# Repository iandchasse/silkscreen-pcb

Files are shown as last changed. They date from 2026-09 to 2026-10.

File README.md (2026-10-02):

# Silkscreen

**An open-source, open-hardware e-reader mainboard.**

Silkscreen is a build-it-yourself e-reader. The name covers both this board and a reader built
around it; this repository covers the mainboard. You order the board already assembled from a
factory, add an e-paper display, a battery and a microSD card, and put it in a
case of your own choosing. It is a 2-layer ESP32-S3 board with a 24-pin display connector,
optional touch and frontlight, microSD and single-cell Li-ion/LiPo power.

It is the successor to [de-link](https://de-link.me). This repository was the de-link project hub
until September 2026; the hub's pages and photos are kept on the
[`de-link-old`](https://github.com/iandchasse/silkscreen-pcb/tree/de-link-old) branch. I designed
Silkscreen in KiCad 9.0.6, but
**you do not need KiCad to order a board.** Every file a factory asks for is already in the
`production/` folder of this repository, ready to upload.

| Back (all components) | Front (silkscreen art) |
|:---:|:---:|
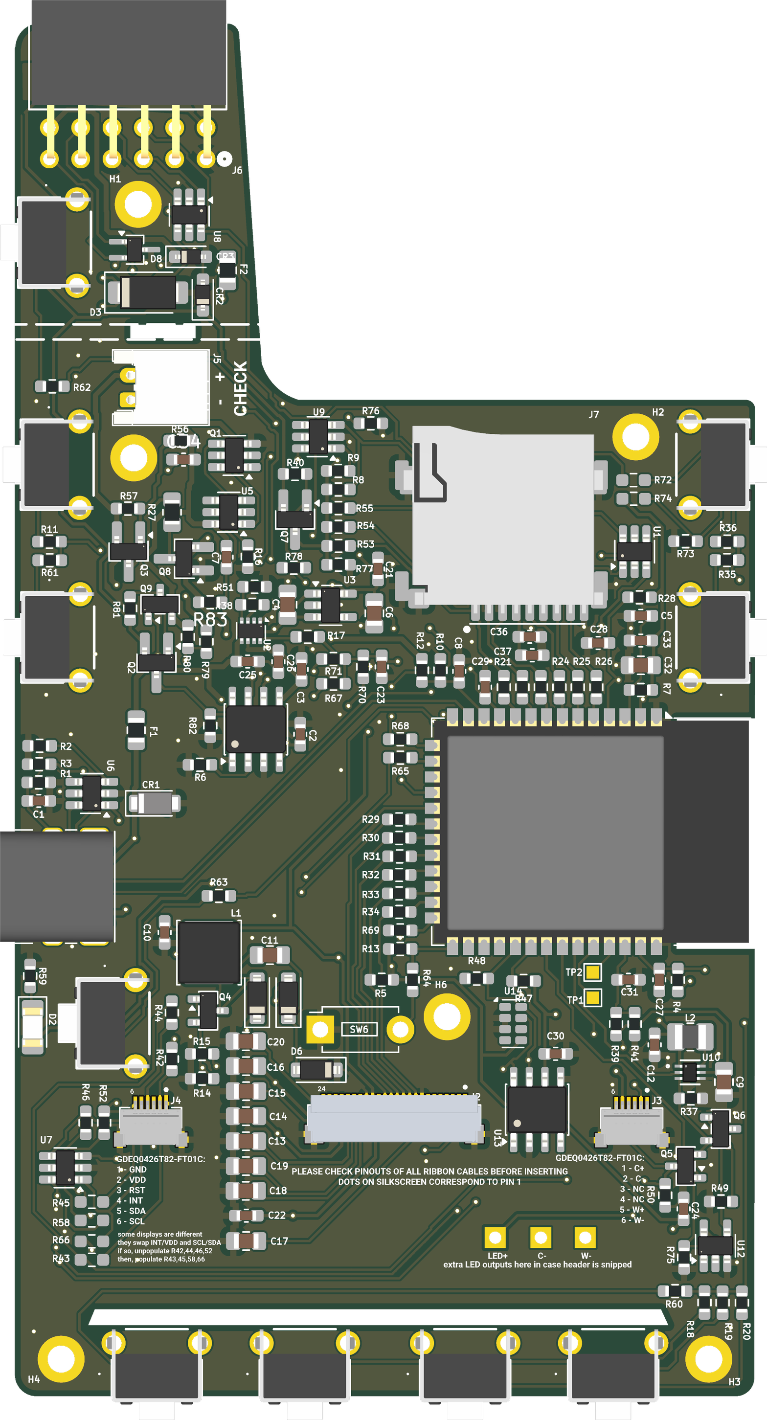
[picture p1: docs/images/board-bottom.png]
Board, bottom view
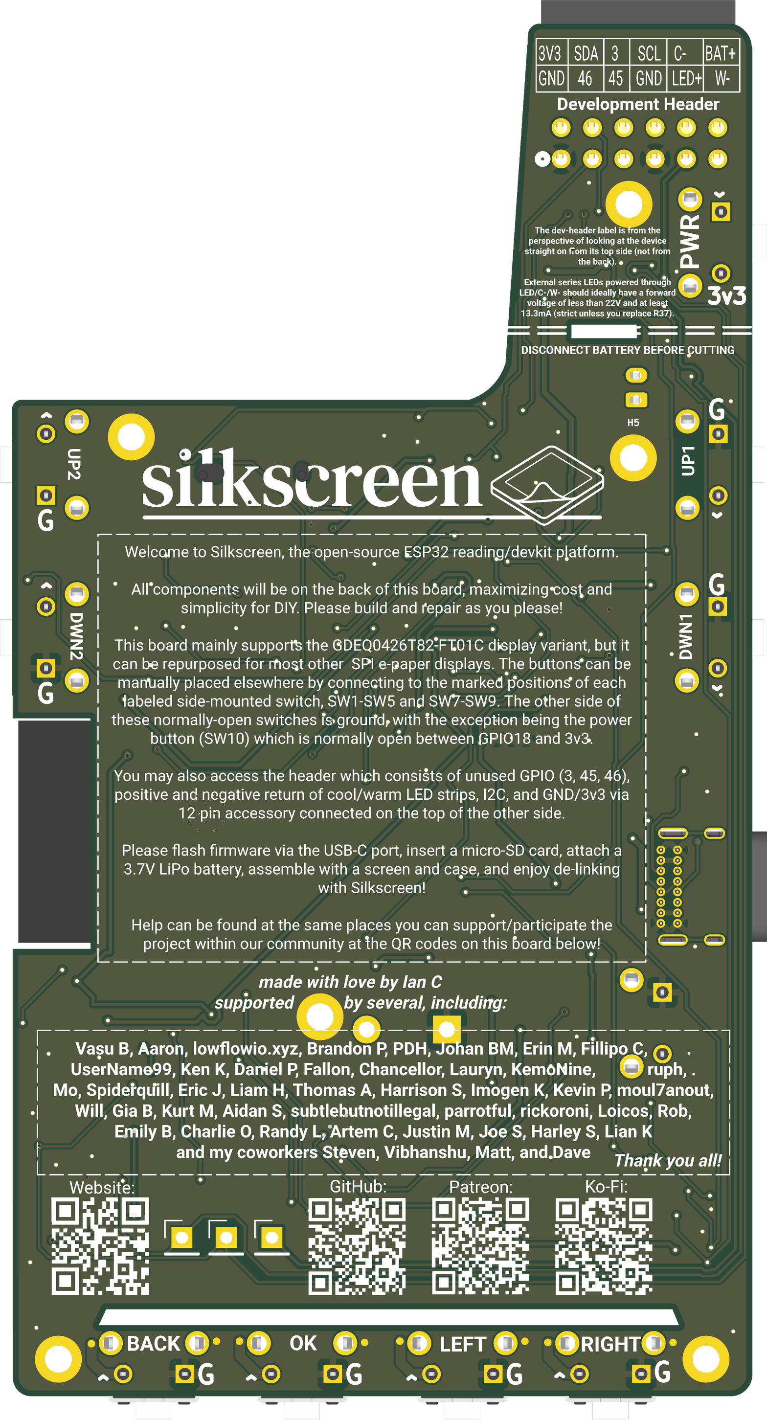
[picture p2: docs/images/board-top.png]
Board, top view
|  |  |

## What it is

- **Brain:** an ESP32-S3 module with 16 MB of flash and 8 MB of PSRAM, with USB built in. You
  plug a USB-C cable straight into it, no adapter.
- **Screen:** a 24-pin connector for SPI e-paper panels. The primary target is Good Display's
  4.26" panel family, in plain, touch, frontlight, or touch + frontlight versions. The plain panel
  is sold as `GDEY0426T82`; the others are `GDEQ0426T82` with a suffix for the variant (`-T01C`
  touch, `-FL01C` front light, `-FT01C` both), so always order by the full part number.
- **Power:** charges and runs from a single-cell Li-ion/LiPo pack over USB-C, with charger,
  cell protection and a 3.3 V regulator on board.
- **Storage:** a push-push microSD socket.
- **Buttons:** eight page/navigation buttons, plus power and reset.
- **Size:** 60.05 × 111.30 mm, 1.6 mm thick. Every part is soldered onto the **back** face, so
  the front is clear for the display.

Silkscreen is built to run the open firmware made for Xteink's readers, starting with CrossPoint.
Setting them up for this board is closed-beta work, so there is **no firmware release for it
yet**. Read [Firmware](#firmware) before you order.

The complete picture of the project, the story behind it, the cost breakdown and the build
configurator are on the project website. As of 21 September 2026 the website is still locked
while I wait for the first boards. It opens, and this README links to it, as soon as I have
tested a board in my hands.

Everything about how the board works, pin by pin, is in one document:
[docs/HARDWARE.md](docs/HARDWARE.md). It covers every circuit block, the GPIO map, what firmware
has to do for the hardware, and the dimensions a case needs.

---

## What you need besides the board

The factory sends you a populated circuit board and nothing else. You also need:

| Item | What to get |
|---|---|
| **Display panel** | One of the 4.26" Good Display variants: `GDEY0426T82` (plain), `GDEQ0426T82-T01C` (touch), `-FL01C` (frontlight), `-FT01C` (touch + frontlight). The panel you pick decides which optional parts you fit. See [Choosing a configuration](#choosing-a-configuration). |
| **Battery** | A **single-cell** (3.7 V nominal / 4.2 V charged) Li-ion or LiPo pack fitted with a **JST-PH 2.0 mm, 2-pin** plug. Read the polarity note below before you plug it in. I use [this 500 mAh `503035` pack (5 × 30 × 35 mm, JST-PH 2.0)](https://www.amazon.com/dp/B0GDQLLF12). It fits the board's 38.75 × 30.50 mm battery bay snugly, with 0.5 mm to spare on the 30 mm side. The board charges at about 0.25 A as built, which is 0.5C for this pack. For a much smaller cell, lower the charge current by raising `R6` ([HARDWARE.md §3.2](docs/HARDWARE.md#32-battery-charger)). Listings change, so check the plug, the polarity and the size of whatever you buy. |
| **microSD card** | Any normal microSD card. The battery normally sits in the board's cut-out directly in front of the card slot, so you lift or slide the cell aside to put a card in or take one out. I designed it that way; the card is not meant to be swapped often. |
| **USB-C cable** | A **data** cable, not a charge-only one, or the board will charge but never appear on your computer. |

**Battery lead order.** On the board, `J5` pin 1 is battery **negative** and pin 2 is battery
**positive**, and the board prints **- +** with the word **CHECK** right beside the connector's
mouth. A pack's wire colours are a good guide (black is negative, red is positive), but there is
no industry standard for which side of a JST-PH plug each wire goes in: packs ship both ways
round, and the two look identical in a photo. So before you plug a pack in, with USB unplugged,
check that its black wire lines up with the **-** mark and its red wire with the **+**. If they are
the wrong way round, swap the two wires in the plug
([how to reverse a JST battery plug](https://www.digikey.com/en/maker/blogs/2025/reversing-the-polarity-on-lipo-battery-jst-connectors)).
A multimeter is the surest check.

> [!WARNING]
> Lithium cells are a fire risk if reversed, shorted or crushed. Check your pack against the
> **- +** marks beside `J5` before plugging it in, and measure it if you can. Use a pack with its
> own protection board. Stop using any cell that is puffed, hot or damaged.

**Screws and case are not on this list.** The board has six M2 mounting holes, but which screws
you need depends on the case you use, and no case is supplied here. See
[The board and your case](#the-board-and-your-case).

---

## Order an assembled board, step by step

> [!CAUTION]
> **This revision of the board has not been tested yet.** I placed the first order, for Rev 1.0, on
> 21 September 2026 and the boards have not come back. The files here are Rev 1.01: the same
> circuit plus one 1 Ω resistor (`R84`) that damps ringing on the USB input when a charger is
> plugged in, corrected part positions in the placement file, and copper changes that only matter
> on a board cut down for a smaller display (see
> [Cutting the board down](#cutting-the-board-down-for-a-smaller-display)). Until I have powered one up, charged a
> cell on it, talked to it over USB and driven a panel from it, every circuit on it is a design,
> not a proven product. If you order before that, you take on a real risk: a mistake I have not
> found yet could mean a board that does not work, and the factory does not refund a board that
> was built exactly as the files said. I will update this section as soon as the first boards are
> checked out.
>
> What you can do in the meantime, with no risk: order your screen panel and battery (see
> [What you need besides the board](#what-you-need-besides-the-board)), and start on an enclosure
> design from the STEP model in
> [The board and your case](#the-board-and-your-case). The `#enclosure-design` channel on the
> [Discord](https://discord.gg/zCnKFt4Y4P) is where case work is being shared and discussed.

You do not need KiCad and you do not need to know how a PCB is designed. A factory makes the
board and solders every part onto it. You will be clicking through a web shop and uploading three
files that are already in this repository. Unfamiliar words are defined in
[Words used on the factory's website](#words-used-on-the-factorys-website).

> **Or let the builder make the files.** The *Build one* page on the website walks you through
> the panel variant and the optional blocks, estimates what the result costs, and gives you the
> three upload files for exactly that build: the same Gerber zip, plus a BOM and CPL with the
> parts you left off already removed (see [Choosing a configuration](#choosing-a-configuration)).
> For the standard build they are byte-for-byte the files in `production/`. The website is not
> open yet, and the steps below are the same either way.

### What it costs and how long it takes

The minimum order is **5 bare boards**, and you choose how many of them the factory assembles:
as few as **2**, all 5, or more boards if you want them. Most of the bill is one-off (the bare
boards, setup, the solder stencil, and a small loading fee for each of about two dozen "Extended"
part types the factory has to fetch), so the price per assembled board falls quickly as you build
more. The website's cost page breaks the cost down by order size and explains where each fee
comes from.

For scale, my own order on **21 September 2026** (no coupons, US delivery): five boards with two
assembled came to **$223.95** for boards, parts and assembly, and **$305.23** at checkout once
shipping, US tariffs and tax were added. That is about $150 per working board at two, and the
cost page puts the same build at roughly $77 per board with all five assembled and about $50 at
ten. Prices, shipping and import charges move, so treat every figure as an expectation, not a
promise.

| | |
|---|---|
| Time from clicking *order* to the parcel | about **2 to 3 weeks** |
| Not included | display panel, battery, microSD card, case |

### Step 1: get the three files

Download this repository (green **Code** button, then **Download ZIP**) and unzip it. Everything
you need is in the `production/` folder. You upload exactly three files:

| Upload this | What it is | Where it goes |
|---|---|---|
| `production/Silkscreen_Reader_PCB_1.01.zip` | the **Gerber** files: the board itself, meaning copper layers, outline and hole positions | the *Add Gerber file* box |
| `production/jlc_bom.csv` | the **BOM** (bill of materials): the shopping list of parts | the *Add BOM file* box |
| `production/positions.csv` | the **CPL** (also called the centroid or pick-and-place file): where each part sits and which way it faces | the *Add CPL file* box |

Ignore everything else in that folder. These three belong together and come from the same export.
Do not mix one of them with an older copy of another.

### Step 2: order the bare board

1. Sign in at [jlcpcb.com](https://jlcpcb.com), click **Order now**, then **Add Gerber file** and
   choose `Silkscreen_Reader_PCB_1.01.zip`.
2. The viewer draws the board. Confirm it says **2 layers** and about **60 × 111 mm**. If it does
   not, you uploaded the wrong file.
3. Set **PCB Qty = 5**, **Thickness = 1.6 mm**, **Outer Copper Weight = 1 oz**. Surface finish and
   solder-mask colour are your choice; nothing in this design needs a particular one.
4. Leave everything else at its default.
5. Scroll the viewer to the board edges and check the USB-C cut-out, the microSD opening and the
   two narrow slots on the outline are open, not filled. The long one (47.04 × 1.30 mm) is the
   display-flex slot; the short one at the tongue neck is **5.30 × 1.10 mm**. Both are at or above
   JLCPCB's 1.0 mm minimum routed-slot width, so neither should raise a design-for-manufacture
   (DFM) message. (Earlier revisions had four 0.5 mm perforation slots there; those are gone.)

### Step 3: turn on assembly

**PCBA** means "printed circuit board assembly": the factory buys the parts and solders them on
for you, instead of shipping you a bare board.

1. Switch **PCB Assembly** on.
2. Choose **Standard**, not Economic. JLCPCB runs two assembly services, and the ESP32-S3 module
   this board is built around can only be placed on **Standard**, so for a complete board Standard
   is the one you need. (If you are happy to hand-solder the module yourself, you could leave it
   off the order and use the cheaper Economic service for everything else. That is an experienced
   builder's choice, not the path I recommend.)
3. Because this board is 60 mm wide and Standard's conveyor wants at least 70 mm, the factory may
   add **snap-off edge rails**: narrow strips of extra board material along the edges for the
   machine to grip. There is nothing for you to design. Expect a small fee in the quote, and snap
   the rails off when the boards arrive.
4. Set **Assembly side: Bottom**. Every part on this board is on the back. If you leave this on
   *Top* you will receive blank boards and a bag of parts.
5. Set the assembly quantity to the number of boards you want built, from 2 up to the number of
   bare boards in the order.
6. Leave **Tooling holes** on *Added by JLCPCB*.
7. Set **Confirm Parts Placement** to **Yes**. It costs a small fee and is worth it on a first
   order: it lets you look at a picture of where each part will go before the machine runs.
8. Click **Confirm**, then **Next**.

### Step 4: upload the parts list

1. **Add BOM file**: `production/jlc_bom.csv`
2. **Add CPL file**: `production/positions.csv`
3. Click **Process BOM & CPL**.

### Step 5: check the parts the factory picked

You get a table with one row per part. Most rows will already be matched.

- **Rows with a blank part number are meant to be blank.** Eleven references (`TP3 TP4 TP5`,
  `R43 R45 R58 R66 R72 R74`, `SW6` and `U14`, the alternate clock chip; the board uses `U13`) are
  tagged *"DNP (standard build)"*. **DNP** means "do not populate": a spot on the board
  deliberately left empty. **Leave them unselected.**
- **Every other row must show a match.** If a row says *No Parts Selected* or *out of stock*, or
  shows a manufacturer's part number instead of an **LCSC code** (the `C…` number that identifies a
  part in the factory's own warehouse), click **Search** and look it up.
  [`fabrication/BOM.md`](fabrication/BOM.md) lists an approved alternative for every part on this
  board. Use that list rather than picking a look-alike yourself, because several of these parts
  have near-identical siblings with different pinouts.
- The part most often short is **TPS923610DRLR** (`U10`, LCSC `C52919131`), the frontlight driver.
  Check its stock. If you are not fitting a frontlight panel, untick it along with the rest of the
  *Frontlight* group in [Choosing a configuration](#choosing-a-configuration). If you *are* fitting
  one and it is out of stock, see [If the frontlight driver is out of stock](#if-the-frontlight-driver-is-out-of-stock).
  Stock may well be back by the time you order, so check first.
- If you are deliberately leaving a block off, remove its parts from the BOM **and** the CPL, or
  untick them here.
- Click **Next**.

#### If the frontlight driver is out of stock

JLCPCB's stock of the TPS923610DRLR comes and goes, and restocking is unpredictable. It isn't a
dead end, just a slower one. In order of preference:

1. **Pre-order it through JLCPCB.** Any account can do this; it just takes lead time. While LCSC
   lists several suppliers for this part, the wait should be short.
   1. Sign in to JLCPCB and open **Parts Manager → Order Parts**.
   2. Search `C52919131`. Enter the quantity you need, plus one or two spares, and add it to
      **My Parts Lib**.
   3. Go to the cart and check out within the hour, or the cart is cancelled. JLCPCB emails the final
      price within 48 hours and refunds or charges the difference.
   4. Wait until the parts reach JLCPCB's warehouse. Pre-ordered parts can't be used before then,
      and they are never shipped to you; they only go into your assembly orders.
   5. Place the board order as above. At Step 5, `U10` matches from your private library.

   JLCPCB's own guide: [What is JLCPCB Parts Pre-order Service?](https://jlcpcb.com/help/article/What-is-JLCPCB-Parts-Pre-order-Service)
   · [Pre-ordering terms](https://jlcpcb.com/help/article/pre-ordering-parts-terms-conditions)

2. **If you can't pre-order it, swap two parts, not one:**

   | Ref | Stock part | Swap to |
   |---|---|---|
   | `U10` | TPS923610DRLR | **TPS923611DRLR** |
   | `D3` | SMAJ26A | **SMAJ33A** |

   The TPS923611 shares the TPS923610's datasheet, package (SOT-563, `DRL`), pinout and 1.8 A switch
   limit, so it fits the same footprint. The one difference is its output ceiling: about 30 V, with
   over-voltage protection at 29.6–31.4 V, where the TPS923610 stops at about 24.5 V. The stock
   `D3`, an SMAJ26A clamp on `LED_SW`, starts conducting at 28.9 V. With a TPS923611 and the stock
   `D3`, a disconnected light lets the driver push current into `D3` before its own protection trips,
   and `D3` can burn out. An SMAJ33A doesn't conduct until about 36.7 V, so the driver's protection
   trips first. Don't leave `D3` off instead: it protects the light connectors (`J3`, `J6`).

   The **TPS923612** is not an option: it only comes in a 2 × 2 mm WSON (`DRV`) package, which
   doesn't fit this footprint.

### Step 6: check the placement preview (do not skip this)

You see a drawing of the board with every part on it. This is your last chance to catch a part
that is rotated wrongly, and the factory's own checker has corrected several on this board before.
A matched part code does not prove the part is the right way round. Since 1 October 2026
`positions.csv` carries those corrections for the parts below, so they should already look right;
check them anyway.

| Part | What to check |
|---|---|
| `D2` | The USB power LED. **Pad 1 is the cathode** (the marked end). Some part libraries use the opposite convention. |
| `U2`, `U5`, `D8` | Small 3 to 8 pin chips whose rotation the factory has corrected before. |
| `J4` | The touch connector. KiCad's anchor sits 0.73 mm off its pads; the corrected row puts it on JLC's anchor, so it should sit on its pads. The pads are what matter. |
| `U4`, `J7` | The ESP32 module and the microSD socket. Check they are centred on their pad patterns. |

If something looks wrong, use the preview's rotate and move tools to fix it, and **save a
screenshot of the corrected preview**. Click **Next**.

### Step 7: through-hole parts, soldered by the factory or by you

Thirteen parts have legs that pass through the board rather than sitting on its surface. That is
**THT** (through-hole technology), as opposed to **SMD** (surface-mount) for everything else. They
are the USB-C socket `J1`, the battery connector `J5`, the expansion header `J6` and the ten
buttons `SW1` to `SW5` and `SW7` to `SW11`. They are already in the files you uploaded, so this is
a choice, not extra work:

- **Let the factory solder them.** JLCPCB charges a one-off hand-soldering fee (about $3.60 per
  order) plus roughly $0.016 per joint, which is about **$1.20 per assembled board** on top of the
  fee. It adds about a day. Confirm on the quote page that through-hole soldering
  appears as a line item.
- **Solder them yourself.** You get the parts loose and put in 74 joints per board: the USB-C
  shell pins, the JST battery connector, the 12-pin expansion header and ten buttons. The USB-C
  shell is the fiddly one. Worth doing if you own a decent iron and a fine tip; not worth it on a
  first board.

### Step 8: pay, and keep the paperwork

Read the price summary: bare boards, setup fee, per-part-type fees, the parts themselves,
assembly. Place the order. Then keep in one folder the order confirmation, the accepted BOM as the
factory matched it, any substitutions it proposed, and your screenshot of the approved placement
preview. If you order again, you will want to know exactly what was built the first time.

### Using a different factory (PCBWay, NextPCB, others)

Nothing in the design is tied to JLCPCB. Upload files for other assemblers are kept in
[`production/other_fabs/`](production/other_fabs/): a PCBWay BOM with KiCad's own placement file, a
NextPCB BOM and centroid file in NextPCB's template (plus SMD-only and through-hole-only pairs in
`split/`), and a bottom-side assembly drawing. They use the same Gerber zip as the JLCPCB order and
are regenerated from the current design with:

```bash
python fabrication/make_fab_files.py --split
```

Know what you are taking on, though. **JLCPCB is the only factory I have ordered
boards from so far.** My NextPCB attempt did not end in an order (what went wrong, and what it
would have cost, is in [fabrication/NEXTPCB_REV0_NOTES.md](fabrication/NEXTPCB_REV0_NOTES.md)),
and I have not tried PCBWay. Another factory is a fine choice if you prefer one. You will be doing
the part matching, the rotation check and the back-and-forth with their engineers yourself,
without a known-good order to compare against. Everything else in this guide assumes JLCPCB.

---

## Choosing a configuration

The files in `production/` build the **full standard build**: every block fitted except the DNP
options. The board is a **core** that is always fitted, plus add-on groups you can leave off. For
a reduced configuration, download its files from the builder on the website, or do it by hand:
delete the listed references from the BOM **and** the CPL and leave the pads empty.

Each group lists every part that exists only to serve it, taken from the schematic netlist (rails
and the shared I²C bus aside), so leaving a group off leaves nothing behind that does no work. The
website's builder uses the same groups.

| Group | References | Fit it when | Works without it? |
|---|---|---|---|
| **Core** (always) | Everything not listed below: ESP32-S3 `U4`, USB-C `J1`/`U6` and protection, charger `U11`, cell protection `U5`/`Q1`/`Q3`/`Q8`, power mux `U2`, LDO `U3` with its input capacitor `C4`, battery monitor, microSD `J7`/`Q7`/`U1`/`U9`, the 24-pin display connector `J2` with its charge pump and boost (`L1`, `Q4`, `D4`-`D6`, `R14`, ...), power button `SW10`, reset `SW11`, LED `D2`, and the I²C pull-ups `R47`/`R48` (shared by touch, clock and `J6`) | Always | This is the minimum working board |
| **Touch** | `J4`, `U7`, jumpers `R42 R44 R46 R52` | The panel has a touch layer (`-T01C`, `-FT01C`) | Yes: omit the whole block on a non-touch panel |
| **Frontlight** | driver `U10` with `L2`, input capacitor `C12` and output capacitor `C9`; current set `R37`; warm/cool select `Q5`, `Q6`, `U12` (with its decoupling `C24`) and `R75`; LED monitor `R39`, `R41`, `C31`; string bleeders `R49`, `R50`; output clamps `D3`, `D8` (`TP3`-`TP5` stay DNP) | The panel has a frontlight (`-FL01C`, `-FT01C`), or you want to drive an external light through `J6` | Yes: omit for a plain or touch-only panel |
| **Frontlight connector** | `J3` | The panel has a bonded frontlight (`-FL01C`, `-FT01C`) | Yes: an external light connects through `J6` instead |
| **Expansion header** | `J6`, `U8`, `CR2`, `CR3`, `F2`, and the GPIO series resistors `R65 R68 R69` | You want spare GPIO, I²C and the external-light output | Yes |
| **Real-time clock** | `U13`, `C30` (or `U14` instead of `U13`) | You want accurate time | Yes: the reader runs without it, and it can be added later by hand |
| **Alternate RTC** | `U14` (**DNP in every standard build**) | You want the cheaper clock instead of `U13` | Fit **either** `U13` **or** `U14`, never both |
| **Side page-turn keys** | per key: `SW1`+`R61` (right-down), `SW4`+`R11` (right-up), `SW7`+`R36`+`R73` (left-up), `SW5`+`R35` (left-down); with any side key, the ladder's pull-up `R28` and filter `C28` | Your case has side keys | Yes: fit any subset |
| **Bottom-row keys** | per key: `SW2`+`R60`, `SW3`+`R18`, `SW8`+`R19`, `SW9`+`R20`; with any bottom key, the ladder's pull-up `R4` and filter `C27` | Your case has bottom keys | Yes: fit any subset; with touch you can drop most keys |

Notes:

- **The panel choice drives touch and frontlight.** The four 4.26" Good Display variants are
  `GDEY0426T82` (plain), `GDEQ0426T82-T01C` (touch), `-FL01C` (frontlight) and `-FT01C` (touch +
  frontlight).
  Fit the touch parts only for a touch variant and the frontlight parts only for a light variant.
- **`U8`, `CR2`, `CR3` and `F2` are `J6`'s own protection and come off with it.** `U8` protects only
  `J6` pins; `CR2` and `CR3` clamp the 3V3 and raw-battery pins where they leave the board, and the
  resettable fuse `F2` sits in series with that battery pin and feeds nothing else. The 33 Ω
  series resistors `R65`/`R68`/`R69` only reach `J6` too; they cost nothing, so leaving them fitted
  on a header-less board is harmless. Do **not** remove `U9`, `D3` or `D8` with `J6`. `U9` also
  protects the microSD data lines, and `D3`/`D8` belong to the frontlight: they clamp its nets
  whether or not `J6` is fitted.
- **`C12` belongs to the frontlight.** It is on the shared `LDO_IN` rail but sits beside `U10` as
  the driver's input capacitor; the LDO and power mux have their own, `C4`. Without the frontlight
  it can go.
- **An external light needs `J6`.** `J3` only mates a panel with a bonded light; for any other
  light, the frontlight group drives it through the header.
- **Fit only one of the two touch pin-order options.** The default build fits `R42 R44 R46 R52`.
  The alternate wiring (`R43 R45 R58 R66`, DNP here) is for panels with the swapped pin order.
  Confirm the panel's pinout first.
- Leaving a button off needs nothing else changed. Its ladder resistor then does nothing and can be
  left off with it, but fitting it is harmless. Keep a ladder's pull-up and filter (`R4`/`C27`
  bottom, `R28`/`C28` side) as long as any key on that ladder is fitted.
- `SW6` (boot button) and `TP3`-`TP5` are DNP in every standard build. `R64` (100 Ω) is fitted
  but only connects `SW6`, so it does nothing unless you fit the boot button.
- Per-board part totals are in [`fabrication/BOM.md`](fabrication/BOM.md).

### Getting into download mode

`SW6`, the BOOT button, is left unfitted to save cost. You will normally never need it: the
ESP32-S3 has native USB, so it presents itself to your computer without any button press. If you
ever do need download mode (a firmware that has wedged the USB stack, for instance), bridge the
two `SW6` pads with a pair of metal tweezers while you tap **RESET** (`SW11`).

`SW11` (RESET) is set back from the board edge on purpose: it is meant to be pressed through a
pin-hole in the case with a paperclip, not by a finger.

### Cutting the board down for a smaller display

The back of the board is marked with a line showing where it can be shortened for a smaller panel.
If you do that:

- **Disconnect the battery first.** Battery positive runs across the cut line. Cutting into it
  with a pack connected can short the cell.
- **It will not snap by hand.** More than half the tab width is solid 1.6 mm FR-4, with live
  copper crossing it. Use a rotary tool (Dremel or similar) and cut along the marked line.
- **You lose the expansion header `J6` with its protection parts (`U8`, `CR2`, `CR3`, `F2`), the
  power button `SW10`, mounting hole `H1` (five mounting points remain) and the two frontlight
  clamps `D3`/`D8`**, which sit on that tongue. A cut board therefore runs its frontlight without
  those two clamps; read [HARDWARE.md §7](docs/HARDWARE.md#7-frontlight-driver) before you drive
  a frontlight from one. After the cut, UP(2) can serve as the power button instead: leave `R36`
  and `R73` unpopulated and populate `R72` and `R74`. The same instruction is printed on the
  schematic and on the board.
- **On a board made before Rev 1.01, including my 21 September order, add two wires after the
  cut.** The cut takes both 3V3 feeds to the charge-enable switch (`Q2`/`R81`) with it, so the
  charger never turns on, and it leaves the power section's ground (`U3`, `U2`, `Q1`) joined to the
  rest of the board only through one shell tab of the microSD socket. Wire `R40` pad 2 to `R81`
  pad 2 (or bridge the two cut 3V3 stubs at the cut edge), and `C6` pad 2 to `C21` pad 2. With a
  correctly oriented cell fitted, the TP4056's `CE` pin (pin 8) should then read 3.3 V. Rev 1.01
  boards have a 3V3 link and ground stitching vias below the cut line and need neither wire.
- Plan the cut before you order, so you can leave the parts you are cutting off out of the BOM.
  `J6`'s series resistors `R65`/`R68`/`R69` stay on the main board near the ESP32 but have nothing
  left to connect to, so they can be left out too.

---

## Firmware

Silkscreen is built to run the open firmware made for Xteink's readers, starting with
[CrossPoint](https://github.com/crosspoint-reader/crosspoint-reader), which de-link, the reader
before it, ran. **There is no firmware release for this board yet:** setting them up for its
pins is the closed beta's work.

The plan is to bring the FreeInk SDK to the board, so that CrossPoint, CrossInk and the other
Xteink X4 firmwares can add Silkscreen as a supported board, and to help maintain that support.
First-power-up instructions come with it.

**The board will never be locked.** You can flash any firmware you like over USB-C.

Until the first Rev 1.0 boards check out, a board you order is one to build on. If you just want
a reader to read on, wait for them to check out, or for the open-beta kits.

If you want to write firmware for it, [docs/HARDWARE.md](docs/HARDWARE.md) is the whole
reference. The GPIO map is section 13, and section 13.1 lists what the board needs firmware to do:
how to decode the charge-status pin, the frontlight driver's enable timing and over-voltage latch,
the microSD power sequence, and the ADC limits.

---

## The board and your case

This board is **not tied to one enclosure**. It is meant to work with many different case designs,
of whatever style you like. No reference enclosure is supplied in this repository, so the case
is yours to design or to take from someone else's.

What you need in order to design around it:

- A 3D model of the board is provided as a STEP file:
  [`docs/mechanical/silkscreen_pcb.step`](docs/mechanical/silkscreen_pcb.step).
- Board outline **60.05 × 111.30 mm**, **1.6 mm** thick.
- **Six M2 mounting holes** (`H1` to `H6`). Use screws with heads of **4 mm or less and no metal
  washers**. Tracks run close to the holes under the solder mask.
- **Every component is on the bottom face.** The top face carries only the silkscreen art and the
  protruding legs of the through-hole parts, so the display sits over a nearly clear surface.
- **Keep the antenna corner clear.** The ESP32 module's PCB antenna overhangs a cut-out in the
  board edge with no copper under it. Do not lay the battery over that corner, and keep screws,
  metal inserts and the display's metal backplane away from it.
- Hole positions, connector locations, cavity heights, apertures and the rest of the mechanical
  reference are in [docs/HARDWARE.md](docs/HARDWARE.md), section 16.

---

## Specifications

| | |
|---|---|
| **MCU** | ESP32-S3-WROOM-1 (**N16R8**, 16 MB flash / 8 MB octal PSRAM), native USB, no UART bridge |
| **Display** | 24-pin 0.5 mm ZIF for SPI e-paper; primary target Good Display's 4.26" panels (`GDEY0426T82` plain, `GDEQ0426T82-*` variants); panel-driven charge pump generates the ±15 to 22 V rails |
| **Frontlight** | TPS923610 constant-current boost, warm/cool selection through one GPIO and an inverter; the warm/cool blend has not been tested on hardware yet |
| **Touch** | Optional I²C capacitive touch (for `-FT01C`-class panels) with a 0 Ω pin-swap mux |
| **Power** | USB-C in, TP4056 charger, DW01A + FS8205A cell protection, TPS2116 priority mux, TLV75533P 3V3 LDO |
| **Battery** | Single-cell 4.2 V-charge Li-ion/LiPo on a JST-PH 2.0 mm 2-pin connector (`J5` pin 1 = negative) |
| **Storage** | push-push microSD in 4-bit SDMMC, power-gated |
| **Input** | 8 buttons on two ADC resistor ladders, a wake/power **button** (`SW10`, a wake input, not a hardware power switch; the 3.3 V rail is always live) and reset (`SW11`); a BOOT button footprint (`SW6`) is left unpopulated because USB-Serial-JTAG makes it unnecessary |
| **RTC** | DS3231MZ (±5 ppm), VBAT-only mode; populated in the standard build, optional. A second footprint (`U14`, Micro Crystal RV-8263-C7) is DNP. Fit either, never both |
| **Revision** | **Rev 1.01**, on both title blocks and in the name of the release zip. Rev 1.0 is the board I ordered on 21 September 2026 (commit `aeb5b39`). Rev 1.01 (30 September 2026) adds a 3V3 link and ground stitching vias below the cut line, so a board cut down for a smaller display still charges and keeps a solid ground, and changes one word of the front silkscreen. On 1 October 2026 it also gained `R84`, a 1 Ω 0603 resistor in series with the ground leg of `C2` (the 10 µF capacitor on `USB_VBUS`), which damps the ringing a USB-A charger or PC port can cause at plug-in, and `positions.csv` now carries the placement corrections for seven parts. Rev 1.0 boards need no rework; until one has been measured, power them from a USB-C charger or an ordinary USB-A charger or PC port rather than a fast-charge USB-A brick on a short, thick cable. Until Rev 1.01 is fabricated, further changes are folded into it. |
| **Board** | 2-layer, 60.05 × 111.30 × 1.6 mm, 1 oz Cu; 185 references = 166 fitted + 11 DNP + 8 bare-copper (holes `H1` to `H6`, test pads `TP1`/`TP2`) |

Connection and GPIO reference: **[docs/HARDWARE.md](docs/HARDWARE.md)**.

---

## Words used on the factory's website

| Word | What it means |
|---|---|
| **Gerber** | The standard file format for a bare circuit board: one file per copper, mask and silkscreen layer, plus the drill holes. Here they are zipped together in `production/Silkscreen_Reader_PCB_1.01.zip`. |
| **BOM** | Bill of materials: the list of every part on the board and how many of each. |
| **CPL / centroid / pick-and-place** | Three names for the same file: where each part sits on the board, which side it is on, and which way it faces. Here, `production/positions.csv`. |
| **PCBA** | Printed circuit board assembly: the service where the factory buys the parts and solders them on, rather than shipping a bare board. |
| **DNP** | Do not populate: a footprint on the board deliberately left empty. |
| **SMD / SMT** | Surface-mount: parts that sit on top of the copper. Machine-placed. |
| **THT** | Through-hole: parts whose legs go through the board and are soldered on the far side. |
| **LCSC code** | The `C…` number identifying a part in JLCPCB's own warehouse, e.g. `C2913202` for the ESP32 module. The BOM you upload uses these. |
| **Basic / Extended part** | JLCPCB's two stock classes. Extended parts carry a small one-off loading fee per part type, which is why the parts list has been tuned to use fewer of them. |
| **DFM** | Design for manufacture: the factory's automated check, which may raise a note on your order. |
| **Outer copper weight** | How thick the copper on the board is, in ounces per square foot. 1 oz is the normal default and is what this board is designed for. |
| **Tooling holes** | Small extra holes the factory adds so its machines can hold the board during assembly. Let JLCPCB add them. |

---

## Licence

The hardware is licensed under the **CERN Open Hardware Licence Version 2, Strongly Reciprocal
(CERN-OHL-S-2.0)**. See [LICENSE](LICENSE). What that means:

- **You may build this board, use it, modify it and sell it**, including commercially. You do not
  need to ask.
- **If you distribute or sell a board based on this design, you must make your design source
  available under the same CERN-OHL-S v2 licence**, and pass on the copyright and licence notice,
  including any changes you made. That is what "strongly reciprocal" means.
- There is **no warranty of any kind**. If you build one and it does not work, that is your risk.

This is a plain-language summary, not legal advice; the licence text in [LICENSE](LICENSE) governs.

> Copyright © 2026 idc LLC.
> This source describes Open Hardware and is licensed under the CERN-OHL-S v2.
> You may redistribute and modify this source and make products using it under the terms of the
> CERN-OHL-S v2 (https://ohwr.org/cern_ohl_s_v2.txt). This source is distributed WITHOUT ANY
> EXPRESS OR IMPLIED WARRANTY, INCLUDING OF MERCHANTABILITY, SATISFACTORY QUALITY AND FITNESS FOR
> A PARTICULAR PURPOSE. Please see the CERN-OHL-S v2 for applicable conditions.

`SPDX-License-Identifier: CERN-OHL-S-2.0`

Third-party component library files (from SnapEDA, Ultra Librarian and SamacSys) retain their own
terms and are not covered by the project licence. See
[fabrication/THIRD_PARTY.md](fabrication/THIRD_PARTY.md).

---

## Working on the design

Nothing below is needed to order a board.

[docs/HARDWARE.md](docs/HARDWARE.md) is the one document to read before changing anything. It
walks through every block of the schematic, explains why each part is there and what its value
was chosen for, gives the GPIO and connector maps, and ends with the design conventions and the
things that look like mistakes but are deliberate.

### Plots and renders

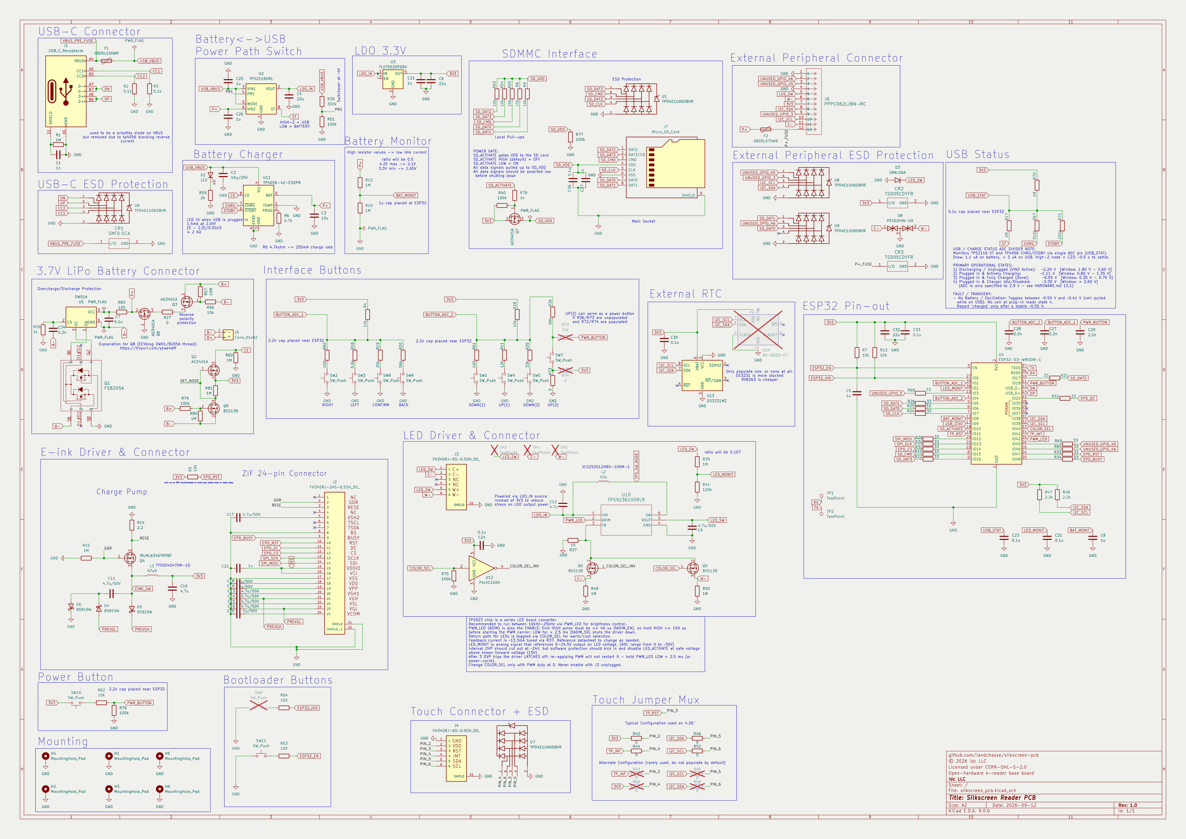
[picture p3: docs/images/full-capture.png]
Silkscreen full schematic


**[Schematic PDF](docs/silkscreen_pcb_schematic.pdf)** (single A2 sheet) and
**[PCB layout PDF](docs/silkscreen_pcb_layout.pdf)** (2 pages: the front, then the back as you
see it). Both are plotted from the current source. The board images at the top are renders of the
Rev 1.0 files, not the release record.

### Repository layout

```
silkscreen_pcb.kicad_pro / .kicad_sch / .kicad_pcb   KiCad 9 project
sym-lib-table / fp-lib-table                          project-local library tables (${KIPRJMOD}-relative, resolve after a plain clone)
KiCad/9.0/3rdparty/                                   vendored symbols/footprints/3D models actually used by the design
docs/HARDWARE.md                                      hardware documentation
docs/mechanical/                                      board STEP model for case design
docs/images/                                          schematic block crops, full sheet, board renders
docs/silkscreen_pcb_schematic.pdf / _layout.pdf       schematic and PCB plots
fabrication/                                          part_fields.csv + apply script, make_fab_files.py, BOM.md / hand-build BOM, how-to
production/                                           release upload files: JLCPCB gerber zip + jlc_bom.csv + positions.csv; other_fabs/ for PCBWay and NextPCB
LICENSE / NOTICE                                      CERN-OHL-S v2
```

A plain `git clone` opens without missing libraries: every project library path is relative, all
in-repo 3D models resolve, and everything else comes from KiCad's standard libraries (KiCad 9.0.x).

### Bill of materials sources

**[fabrication/BOM.md](fabrication/BOM.md)** is the current, netlist-derived sourcing reference:
the optimized JLC build and the hand-build (DigiKey) list, with prices and the reasons for each
swap. Both come from [`fabrication/part_fields.csv`](fabrication/part_fields.csv), which maps every
reference to its prime manufacturer part number and its LCSC code. Accepted factory changes must
still be frozen in the release records.

### Regenerating the release files

The project and the reviewed exports use **KiCad 9.0.6**. Keep a backup before saving with a newer
major version; newer file formats may not reopen in KiCad 9.

For JLCPCB, use the KiCad **Fabrication Toolkit** plugin for the placement export: it applies JLC's
part-rotation database and reads the `LCSC` field from the footprints (set by
`fabrication/apply_part_fields.py`, see [fabrication/README.md](fabrication/README.md)).
Seven parts (`U2`, `U5`, `D2`, `D8`, `J4`, `J7`, `U4`) also carry `FT Rotation Offset` or
`FT Position Offset` fields, on both the schematic symbols and the footprints, for corrections the
Toolkit does not make on its own, so every Toolkit run writes their corrected rows.
**Regenerate the whole Toolkit set after every schematic or PCB save.** A stale `positions.csv`
silently misses new parts.

Raw `kicad-cli` exports, as a cross-check only and not a replacement for the reviewed Toolkit set:

```bash
kicad-cli pcb export gerbers -o fabrication/gerbers/ \
  --layers F.Cu,B.Cu,F.Mask,B.Mask,F.SilkS,B.SilkS,F.Paste,B.Paste,Edge.Cuts \
  --no-protel-ext --subtract-soldermask silkscreen_pcb.kicad_pcb
kicad-cli pcb export drill -o fabrication/gerbers/ --format excellon \
  --drill-origin absolute --excellon-units mm --excellon-separate-th silkscreen_pcb.kicad_pcb
kicad-cli pcb export pos -o fabrication/assembly/cpl.csv --format csv --units mm --side both silkscreen_pcb.kicad_pcb
```

See [fabrication/README.md](fabrication/README.md) for the release-file workflow and the
assembly checklist.

---

Predecessor project: [de-link.me](https://de-link.me).

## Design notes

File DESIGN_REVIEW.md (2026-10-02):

# Silkscreen — design review and assembly decision

> **Status, 2026-09-21.** This review describes the board as it stood on 2026-09-17/18. A later block-by-block pass — [docs/final-review-2026-09-19/](docs/final-review-2026-09-19/FINAL_REVIEW.md) — led to further changes that are **not** re-analysed here: `R83` + `C34` on the DW01A, PPTC `F2` on `J6` pin 12, the alternate RTC `U14` (DNP), mounting hole `H6`, the `USB_STAT` ladder rescaled ×10, `R57` 1 MΩ → 10 MΩ, `R15` 10 k → 1 MΩ, `C2` to a 25 V part and a wider VBUS trunk. Where this document and [HARDWARE.md](docs/HARDWARE.md) disagree on a value, HARDWARE.md is current. In particular §4's idle-drain arithmetic uses `R57` = 1 MΩ (≈4 µA through the gate divider); with 10 MΩ it is ≈0.4 µA.
>
> **2026-10-01 (Rev 1.01):** `R84` (1 Ω) was added in series with `C2`'s ground leg as a USB hot-plug damper (§3), and seven JLC placement rows were corrected with Fabrication Toolkit offset fields (§12).

**Authoritative review, 2026-09-17.** This document replaces the older review and the separate September 16 audit/follow-up reports. All conclusions and release actions live here. [HARDWARE.md](docs/HARDWARE.md) is the connection and firmware reference; the [audit folder](docs/audit-2026-09-16/) contains measurements, source records, images and scripts, not another verdict.

## 1. Decision

**Work out the items below before an unconditional “yes, assemble this PCBA.”** The design is a credible prototype: the netlist and PCB agree, the saved manufacturing files match the current board, and most circuit blocks are coherent. The deciding issues are component qualification, a battery fault path and SD-socket mechanics. Vias, dense routing and repeated cosmetic DRC warnings are not the deciding issues.

| Action | Finding and consequence | Required disposition |
|---|---|---|
| **Battery reverse-insertion — APPLIED: "Fix 4"** | With USB powering the charger, Q8 (gate hard to GND) is enhanced by the charger-driven P+ and Q3's body diode completes a path into a reversed cell. Behavioral simulation of the as-built nets shows the **full ≈0.25 A programmed charge current flowing continuously through the reversed cell** plus ≈2 mA through U5's CS ESD diode (U5's own supply clamps near −0.1 V through R16). | TP4056 **CE** pin gated from a cell-polarity detector **referenced to raw B−** (Q9 BSS138 + Q2 AO3401A + R79–R82, all existing BOM lines, ≈10 µA idle — corrected 2026-09-18, see §4). Simulated safe in every case, including flat-cell recovery, hot-swap and latched-connector insertion, and confirmed wired into the schematic/PCB (netlist-verified). **Bench-verify per §13 with a current-limited emulator** before relying on it. See §4. |
| **Replace Q4 — APPLIED** | The previously ordered BSS138 is outside the panel supplier's switch-resistance requirement and lacks a low-drive guarantee. | Source now specifies genuine **Infineon IRLML6346TRPBF / C67276** (same SOT-23 G/S/D pads). Q5/Q6 stay BSS138. Ensure the factory BOM carries C67276. Bench-verify panel-driven switching per §13. See §7. |
| **Resolve J7 fit — APPLIED** | The first assembled order was cancelled because the dual-source land ignored the TF PUSH's Ø0.80 mm pegs at 8.0 mm; the interim 1.05 mm slot was still ≈0.1 mm short for both candidates. | Library and board now carry NPTH **slots 1.50 mm tall** sized to the union of both parts' pegs, with the GCT body keepout marked on Dwgs.User. Owner confirmed seating against both parts' 3D models. Remaining: vias inside the GCT keepout matter only for a hand-fitted MEM2075. See §6. |
| **Close D2 substitution — ACCEPTED** | The original BOM specified reverse-mount C2827254, which needs a board cutout. | Normal-emitting red 1206 **C28310439 / YLED1206R** accepted for D2 (≈1.3–1.6 mA with R59). Carry it in the next upload BOM. |
| **Reduce full-scale frontlight current — APPLIED** | R37 = 13.3 Ω gave 15.04 mA nominal / 15.65 mA upper against the panel's ≤15 mA limit. | Source now **R37 = 15 Ω** (13.33 mA nominal, 13.87 mA upper). This sets the brightness ceiling only; dimming is by ADIM. See §8. |
| **Qualify the first article** | U3's shared 500 mA budget, heat, e-paper drive, frontlight transitions and USB input loading lack physical measurements. | Complete the acceptance plan in §13 before a repeat production order. **R6 stays 4.7 kΩ (≈0.25 A, 0.5 C for a 500 mAh cell) for the first batch**; change to 10 kΩ only if U3 runs hot while charging a low cell (U11 sits ≈12 mm from U3). Self-powered USB detach is accepted as a firmware responsibility; no VBUS-sense hardware planned. |

The owner reports that the actual FT01C frontlight matches the schematic. **Keep that wiring for the checked sample.** The conflicting supplier drawing remains a procurement warning, not evidence that the checked sample is wrong. The failure condition for a genuinely differently wired panel is documented in §8.

**Status (updated 2026-09-18):** Q4, R37, J7, the battery fix (§4, "Fix 4"), L1 (47 µH), R14 (2.2 Ω) and C9 (4.7 µF) are all applied in the source (netlist-confirmed); D2 is accepted; R6 stays 4.7 kΩ pending the thermal check. A 2026-09-18 pre-order confirmation pass (`docs/audit-2026-09-18/`) reviewed the whole board against this state: no blocking finding, three component-value questions (C9, L1/R14, Q1's hand-build sourcing) resolved — see §4/§7/§8 and the audit file for detail. **Controlled prototype:** the Toolkit set (Gerber ZIP, `positions.csv`, `bom.csv`, 162 CPL rows including Q2/Q9/R79–R82) was regenerated 2026-09-18 12:22 and verified geometrically identical to the saved PCB; the v3/v4 upload BOMs were updated for L1/R14/C9 the same day. A second 2026-09-18 checkpoint (`docs/audit-2026-09-18/CHECKPOINT_2.md`) re-reviewed the saved design after those changes: no blocker; open items are listed there and in §13. **Repeatable product:** still gated on the §13 first-article measurements, above all the battery-fault bench check with a current-limited emulator. This review does not demonstrate that existing boards will fail.

## 2. Scope, evidence and completeness

The engineering checks started from the KiCad schematic/PCB/project, component connections, manufacturer documents, PDFs directly under `docs`, and current local manufacturing records. Existing generated Markdown was used afterward to find contradictions. The layout PDF predates the current board, so critical copper conclusions use fresh `pcbnew` geometry and copper exports. Schematic illustrations are crops of the supplied PDF, corroborated against the fresh netlist.

*Snapshot of the 2026-09-16 audit; on 2026-09-18 the design has 179 references / 129 nets (111 named), 162 fitted + 10 DNP + 7 bare-copper, and a 162-entry Toolkit CPL that matches the saved PCB.*

| Verification | Result |
|---|---|
| Schematic references / nets | **173 / 126** |
| Block coverage | **18 blocks; each of the 173 references assigned exactly once** |
| KiCad PCB connectivity / schematic parity | **0 unconnected items / 0 mismatches** |
| Saved order population | **155 fitted, 8 DNP, 10 mounting-hole/test-pad references** |
| Passive nominal values | All fitted resistor/capacitor/inductor values match the schematic; no unexplained exclusions or duplicate order references |
| Fabrication Toolkit CPL replay | **All 157 entries match** X/Y, rotation and side; a CPL entry is not an instruction to fit a DNP part |
| Local manufacturing ZIP | **11 Gerbers match parsed geometry; 2 drill files match except timestamps** |
| Source preservation | Six persistent hashed design/production inputs unchanged; saved order worksheet matches its original extraction. The transient autosave matched the PCB at audit start and is now absent. |

Gerber comparison resolves apertures, drawing primitives, regions and polarity; it is not a complete factory CAM/DFM check. The 177 PCB footprint objects include graphical objects. Review identity is anchored by [source-manifest.json](docs/audit-2026-09-16/source-manifest.json), with final checks in [source-preservation.json](docs/audit-2026-09-16/source-preservation.json).

**Factory-state limit:** the matched order export dates from September 14 and the local ZIP from September 16. Matching local files does not prove which revision, CAM edits, rotation edits or substitutions JLC has accepted.

### Every schematic block

The full reference allocation is [block-coverage.csv](docs/audit-2026-09-16/block-coverage.csv); exact ordered parts and individual notes are [component-review.csv](docs/audit-2026-09-16/component-review.csv).

| Block | Main references | Result / detail |
|---|---|---|
| USB connector, shield, CC | J1, F1, R1–R3, C1 | Independent 5.1 kΩ Rd resistors and shield RC coherent; power/inrush qualification §3 |
| USB ESD | U6, CR1 | Exact U6 vendor pinout verified; CR1 operating-voltage margin §3 |
| Charger and USB indicator | U11, R6, R59, D2, C2/C3 | Charger topology coherent; LED substitution, current tolerance and disabled NTC §3 |
| Battery connector/protection/polarity | J5, U5, Q1/Q3/Q8, R16/R27/R56/R57, C7 | **USB-present reverse-battery fault concern**, sensing/filter issues §4 |
| Power mux | U2, R38/R51, C4/C25/C26 | Priority selection coherent; tolerance/hot-plug qualification §3 |
| 3.3 V regulation | U3, C6/C21 | Correct pinout/capacitor connections; shared current and thermal margin §3 |
| Battery ADC | R10/R12, C8 | P+/2, slow/high-impedance measurement; calibration §9 |
| USB status ADC | R17/R67/R70/R71, C23 | Normal states distinct; degraded states/top-code handling §9 |
| Processor, reset, boot, UART | U4, R7/R13/R63/R64, C5/C22/C32/C33, SW6/SW11, TP1/TP2 | Basic connections coherent; strap/boot/recovery limitations §5 |
| SDMMC and power gating | J7, U1, Q7, bus resistors/pullups, R40/R77/R78, C36/C37 | Electrical mapping and off-state coherent; **mechanical gate** §6 |
| E-paper interface and charge pump | J2, Q4, L1, D4–D6, R5/R14/R15/R29–R34, rail capacitors | **Q4 substitution** and waveform/layout qualification §7 |
| Frontlight boost, selection and ADC | J3, U10/U12, Q5/Q6, L2, R37/R39/R41/R49/R50/R75, C9/C12/C24/C31, TP3–TP5 | Current margin, >40 µs enable pulse and color-transition qualification §8 |
| Touch and pin-swap links | J4, U7, R42–R46/R52/R58/R66 | Default mapping coherent; link exclusivity, interrupt/wake limitations §10 |
| Button ladders and alternate wake link | SW1–SW5/SW7–SW9, ladder resistors, R72–R74, C27/C28 | Single-key levels coherent; combinations/wake limitations §9 |
| Power/wake button | SW10, R62/R76, C29 | Approximately 3.0 V pressed; GPIO18 suitable for RTC-domain wake §9 |
| Optional RTC | U13, C30 | VBAT-only topology supported; fitted in the standard build (optional), ±5 ppm, no backup/wake function §10 |
| Expansion and shared ESD | J6, U8/U9, D3/D8, CR2/CR3, R47/R48/R65/R68/R69 | Exact ESD pinouts verified; exposed supply/strap constraints §10 |
| Mounting | H1–H6 | No assembly parts required; enclosure/antenna interaction remains physical qualification §11 |

“Coherent” means no additional schematic defect was identified in the reviewed role. It is not a claim that unpowered analysis replaces functional, environmental or ESD testing.

## 3. USB input, charging, mux and regulator

### USB source and protection

J1 routes USB D− to GPIO19 and D+ to GPIO20. Each CC has its own 5.1 kΩ pull-down; the shield's 1 MΩ / 1 nF connection is intentional, not an omitted signal-ground connection. The connector is through-hole: verify that JLC's job includes its soldering, along with J5, J6 and the buttons.

There is no USB-PD/BC1.2 controller, CC-current measurement or automatic charge-current reduction. A healthy 5 V adapter is the normal intended source, but an arbitrary 500 mA USB host is not guaranteed to run the maximum workload while charging. An illustrative 350 mA 3V3 load + 250 mA charging + 56 mA frontlight input totals **656 mA** before small ancillary loads. This is a workload example, not a measured consumption figure.

**Self-powered USB needs a disconnect policy.** The MCU remains powered from the battery after USB removal, and there is no dedicated VBUS-sense GPIO. Espressif's USB-OTG/TinyUSB self-powered configuration expects VBUS monitoring; USB_STAT is an analog status mixture, not a direct substitute for its digital `vbus_monitor_io`. Firmware may implement a qualified software detection/disconnect path, but must not equate ST with physical USB presence in every condition. Verify detach/reattach with a powered-down host and battery operation; add direct divided/comparator VBUS sensing on a revision if the intended USB stack requires it. This is a product/firmware qualification gap, not a claim that native USB programming cannot work. **Decision (2026-09-17):** accepted as a firmware responsibility — the board does not enumerate while battery-powered, and with a healthy source the mux runs it from the host anyway; firmware must tear down USB on detach; no VBUS-sense hardware is planned. [Espressif self-powered device guidance](https://docs.espressif.com/projects/esp-idf/en/v5.5/esp32s3/api-reference/peripherals/usb_device.html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).

F1's Littelfuse 0805L100WR **1 A hold** rating is temperature-dependent: the manufacturer's derating table gives about **0.65 A at 60°C and 0.55 A at 70°C**. A warm enclosure can therefore matter even when room-temperature current is below 1 A. A PTC does not negotiate USB current. Check hot resistance/drop and trip behavior under the actual workload. [Littelfuse 0805L datasheet](https://www.littelfuse.com/assetdocs/littelfuse_ptc_0805l_datasheet.pdf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).

C2 = 10 µF and C25 = 1 µF are directly on the fused VBUS input: **11 µF nominal before downstream coupling** (since Rev 1.01, C2 returns to GND through R84, 1 Ω; the capacitance and inrush charge are unchanged). This does not demonstrate the conservative 10 µF USB input-capacitance budget. Typical MLCC bias loss is not a guaranteed inrush limit. Also, TPS2116's soft-start applies when its output is below approximately 1 V; a battery-powered system already above that does not necessarily receive the same ramp on hot-plug. Measure VBUS droop/inrush with and without a battery. This is a compliance/robustness concern, not proof of enumeration failure. [TI USB inrush explanation](https://www.ti.com/document-viewer/lit/html/SSZTB15/GUID-9C081873-D60C-462A-ABFB-9A4E87F564F0), [TPS2116](https://www.ti.com/lit/ds/symlink/tps2116.pdf).

**Resolved 2026-09-17: CR1 becomes SMF6.5CA in SOD-123FL (6.5 V standoff by family definition — official and clone parts agree; see §12); CR2/CR3 keep the SD05C-class part. The finding below describes the earlier order.** CR1 is the ordered TECH PUBLIC SD05C, with **5.0 V working standoff** on a rail that can reach 5.25 V in an ordinary USB operating case. Leakage is not guaranteed by its 5.0 V specification at 5.25 V. Prefer an appropriately characterized ≥5.5 V working-voltage part, considering clamping too, or explicitly qualify the existing selection. This does not imply immediate breakdown at 5.25 V. Its surge-clamp specification also does not guarantee that a 6 V absolute-maximum IC survives every surge. CR2/CR3 on 3.3 V / ≤4.2 V have normal-DC margin, but are not precision rail limiters. [Exact SD05C sheet](https://datasheet.lcsc.com/datasheet/pdf/f9b7b3e2c9eb25bcff59f2b72aceabee.pdf?productCode=C907858).

**Two distinct VBUS-overvoltage questions, disposed of separately 2026-09-18.** (1) *Sustained fault above 5 V:* `R2`/`R3` (§3.1, 5.1 kΩ Rd) are the board's only CC signaling — there is no PD controller to negotiate a contract, so a spec-compliant source has no mechanism to impose anything above the 5 V default; owner reports this pattern has held up on prior boards with a similar CC arrangement. `F1` (6 V max) and CR1 (pulse-rated, not continuous) remain under-margined *if* a genuinely non-compliant/malfunctioning source is used, which is accepted as a residual risk rather than pursued further — this is a narrower and more acceptable category than "any USB-PD charger." (2) *Hot-plug ringing at nominal 5 V:* a separate, faster phenomenon — cable inductance against USB_VBUS's ~11 µF of bare ceramic can ring for tens of µs above 5 V regardless of PD status, and a worst-case linear model puts the peak at 6–7.4 V, above TPS2116's 6 V abs-max; the TP4056 datasheet names this and suggests a 1.5 Ω series resistor. Judged low-probability given real chargers' soft-start behavior and no reported field issue, and kept as a first-article scope check (§13) rather than a pre-emptive design change.

**Revised 2026-10-01: question (2) is fixed in Rev 1.01 with R84.** A hot-plug study (several independent LTspice/Python models) narrowed and re-graded it **MEDIUM**. Only a source whose VBUS is already live when the plug goes in rings: legacy USB-A chargers, PC ports, power banks on an A-to-C cable. USB-C chargers on C-to-C cables ramp VBUS after attach and do not overshoot. As built on Rev 1.0, typical aluminium-capacitor USB-A chargers stay at or below ≈5.9 V at a 5.0 V source on 1 m cables (6.26 V on 20 AWG at 5.25 V); low-ESR bricks with 20–24 AWG cables give **6.1–6.9 V on U2 VIN1/MODE** (6.0 V absolute maximum); the worst stack-up is **7.95 V** (TP4056 VCC 7.97 V against its 8 V limit). LDO_IN stays at or below ≈5.2–5.6 V because U2 has not connected yet when the first peak arrives. de-link's field record does not cover this board: its series MBR0530 Schottky and 6.5–7 V input parts are what kept it safe. **Fix:** R84 = 1 Ω 0603 (Yageo RC0603FR-071RL; JLC `C22936`, UNI-ROYAL 0603WAF100KT5E, Basic) from C2 pin 2 to GND; C25 still goes straight from USB_VBUS to GND. No DC current flows in R84, so there is no VBUS drop. Worst stack-up with R84: **5.60 V**; only unrealistic ideal 5.5 V-source corners graze 6.11–6.65 V, for at most 0.9 µs. The study's first pick, 0.51 Ω 0402 (Yageo RL0402FR-070R51L / `C728429`, Extended), sits nearer the 0.5–0.7 Ω optimum; 1 Ω 0603 was chosen to keep the board free of 0402 parts and of a new Extended part. No effect on DC, inrush charge, charge start, load steps or unplug; the existing battery-switchover dip with a 3.0 V cell can be up to ≈0.35 V deeper (bench-check, §13). **Rev 1.0 boards need no rework**; on them, prefer USB-C chargers or ordinary USB-A chargers/PC ports and avoid fast-charge USB-A bricks with short, thick cables until measured.

### Charger and D2

U11's actual TOPPOWER TP4056 C16581 sheet gives `ICHG ≈ 1100/RPROG`, or **234 mA** for R6 = 4.7 kΩ, but its low-current example table is inconsistent (250 mA at 5 kΩ). Treat this as an intended approximately 0.25 A setting and measure the lot; the source annotation's exact 255 mA is not established. TEMP is grounded, disabling cell-temperature monitoring. Select the cell and charging-temperature range accordingly. UVLO rising is specified over approximately 3.5–3.9 V, with a separate input-to-battery headroom condition: **4.0 V is not an exact universal charging on/off threshold.** [Ordered charger sheet](https://datasheet.lcsc.com/datasheet/pdf/d328ee101cbb1f3719611cd61db479c2.pdf?productCode=C16581).

**Decision (2026-09-17): R6 stays 4.7 kΩ for the first batch** — 0.5 C for a 500 mAh cell, ≈2.5–3 h to full. The illustrative >500 mA USB overlap only stacks a millisecond Wi-Fi TX burst, full-brightness frontlight and the CC phase of a low cell on a strict 500 mA port, and its consequence is benign: VBUS sags, the TPS2116 hands the load to the battery (the ST+CHRG state) and charging continues at what the port allows. The real reason to lower it is heat: U11 sits ≈12 mm from U3 on the shared pour and dissipates ≈0.5 W at 0.25 A into a low cell. If the §13 thermal check shows U3 hot while charging a low cell with the frontlight on, change R6 to 10 kΩ (≈110–120 mA, ≈4.5–5 h); 12 kΩ (≈92–100 mA, ≈5.5–6 h) holds the worst-case stack at ≈500 mA. None of this interacts with the §4 fix, which gates *whether* the charger runs, not how much it sources.

The healthy-USB system load is on the mux output, separate from BAT, which helps normal charge termination. When the mux selects the battery despite a marginal USB source, system current and charger termination behavior must be considered together.

**D2 indicates USB power, not charging state.** C28310439 / YLED1206R is the **accepted** conventional-emitting red 1206 substitution for the existing pads. Its anode goes to USB_VBUS and cathode to R59. At 5 V and R59 = 2 kΩ, expect roughly **1.3–1.6 mA**, not the annotation's 2.5 mA. Optical brightness at this low current is not guaranteed by a 10 mA optical test. Carry it in the next upload BOM and confirm placement polarity. [Replacement LED sheet](https://datasheet.lcsc.com/datasheet/pdf/8e04df73a20896aea76d4672dc480ed1.pdf?productCode=C28310439).

### Mux and U3

U2's VIN1 is USB, VIN2 is P+, and **MODE is tied to USB_VBUS/VIN1** for priority behavior. With USB absent, MODE and PR1 are low, selecting the available battery path. R38/R51 = 300 kΩ/100 kΩ gives **4.0 V nominal**, approximately **3.625–4.385 V** with the specified ±8% reference and ±1% resistors. A normal 5 V source clears this. Lowering R38 is not a universal improvement: the threshold spread is wider than a narrow LDO-headroom guard band. Retain the nominal choice pending measured system requirements. ST is a selection/status output, not a USB-present comparator; it can also be low when channels are disabled or in thermal shutdown. [TPS2116](https://www.ti.com/lit/ds/symlink/tps2116.pdf).

U3 TLV75533PDBVR is **500 mA total**, shared by ESP32, SD, panel and touch. Espressif recommends a supply capable of at least 500 mA for the module alone. This does not prove simultaneous load exceeds U3's rating, but there is no established worst-case margin. The frontlight takes **LDO_IN**, so its main power bypasses U3. [ESP32-S3-WROOM module](https://www.espressif.com/sites/default/files/documentation/esp32-s3-wroom-1_wroom-1u_datasheet_en.pdf).

| Sustained 3V3 current | U3 loss at 5 V input |
|---:|---:|
| 150 mA | 0.255 W |
| 250 mA | 0.425 W |
| 350 mA | 0.595 W |
| 500 mA | 0.850 W |

TI lists DBV thermal benchmarks of **100.8°C/W on its EVM and 231.1°C/W in the JEDEC configuration**. Neither is this board's measured thermal resistance. At 250 mA they illustrate rises of roughly 43°C and 98°C. Do not use the better exposed-pad DYD package numbers for DBV. The 3.3 V version's 500 mA dropout maximum is 215 mV through 85°C, 238 mV through 125°C; battery operation below the necessary input headroom ceases to be regulated even before protection cutoff. [TLV755P](https://www.ti.com/lit/ds/symlink/tlv755p.pdf).

C4/C6 connections and close placement are good. Exact effective capacitance of the ordered CCTC 22 µF parts under bias/temperature was not established. Source-transition hold-up also depends on this: `0.4 A × 8 µs / 22 µF ≈ 145 mV` is a simple sensitivity example, not a prediction including all capacitors and converter response.

### U3 temperature scenarios: normal heat versus insufficient margin

**Generating heat is normal; U3 overheating has not been demonstrated.** A loss of 0.2–0.4 W alone is not a reason to reject an LDO. The relevant quantities are sustained load, local ambient temperature and the actual PCB's ability to remove heat. Short Wi-Fi/SD current peaks do not produce the full steady-state temperature rise; neither have the application's sustained current or duty cycle been measured. Espressif's approximately 355 mA Wi-Fi TX figure is explicitly a **peak** specification, not continuous reader consumption. [Module current table](https://www.espressif.com/sites/default/files/documentation/esp32-s3-wroom-1_wroom-1u_datasheet_en.pdf).

At **25°C local ambient**, nominal 3.3 V output, and constant current, `Tj ≈ 25 + (Vin − 3.3) × I3V3 × RθJA`. Each pair below is **TI EVM / TI JEDEC**, using 100.8 / 231.1°C/W for the DBV package. They are reference-board scenarios, **not guaranteed lower/upper bounds for this PCB**. The EVM uses a thermally optimized layout; this board cannot automatically claim its result. These are internal junction temperatures, not board or case-surface temperatures.

| Sustained total 3V3 current | Full battery, 4.2 V | USB, 5.0 V | High USB case, 5.5 V |
|---:|---:|---:|---:|
| 150 mA | 39 / 56°C | 51 / 84°C | 58 / 101°C |
| 250 mA | 48 / 77°C | 68 / 123°C | 80 / 152°C |
| 350 mA | 57 / 98°C | 85 / 163°C | 103 / 203°C* |
| 500 mA | 70 / 129°C | 111 / 221°C* | 136 / 279°C* |

**125°C is the recommended maximum junction temperature.** Thermal shutdown is typically about **165°C**; starred values are mathematical extrapolations beyond shutdown, not sustainable regulated operating temperatures. The 500 mA row is a stress case at the LDO's output rating, not an estimate of this reader's typical consumption. At 40°C local ambient add approximately 15°C to these calculations. Charger, frontlight, MCU and enclosure heating can change the local thermal conditions and are not solved by this single-device model. Input path losses were neglected; full component tolerances were not included. [TI thermal limits and benchmarks](https://www.ti.com/lit/ds/symlink/tlv755p.pdf).

The full-cell case is hotter for U3 than a partly discharged battery. At 3.7 V and 250 mA, the same scenarios give only **35 / 48°C**. Near 3.4 V, dropout/load transients become the concern instead. The high USB column uses **5.5 V**, which USB-IF permits at VBUS; the earlier 5.25 V example is not the universal USB upper limit. [USB-IF voltage update](https://compliance.usb.org/index.asp?UpdateFile=Electrical).

**Practical disposition:** a sustained load around 150 mA gives ordinary, potentially acceptable warmth in these scenarios; a sustained 250–350 mA from USB deserves measurement because the less favorable reference scenario approaches/exceeds 125°C. Brief peaks alone do not establish that problem. There is no thermal-only respin recommendation without the actual load/temperature result. Slower charging lowers U11's heat and input demand but leaves U3's own loss essentially unchanged at fixed VIN/load. R6 = 10 kΩ is an optional roughly 110–130 mA charge setting, not an applied source change. Compare U3 temperature with charging inactive/active under the same workload.

**Owner's workload clarification (2026-09-17):** SD and Wi-Fi use are transient, continuous screen refreshing is outside intended use, and the ESP32 rarely runs at full power. Accept that as the intended duty cycle; the high continuous-current rows above are stress scenarios, not a prediction of normal operation. Retain the present LDO pending a realistic firmware/enclosure test. Thermal qualification is not an independently demonstrated design defect. Check the longest supported sync/update activity and normal operation while charging; transient 3V3 droop remains a separate electrical check even if average heat is modest.

#### How a thermocouple result informs the design

Attach a small, fine-wire thermocouple (approximately 36–40 AWG) to the package's top center with minimal adhesive and avoid shorts/large probe heat sinking. Log local ambient and package temperature until they settle, preferably in the intended enclosure. Estimate U3 power from its input/output voltage and **3V3 current**, excluding battery charging and the main frontlight load. TI recommends `Tj ≈ Ttop + ΨJT × PD`; DBV ΨJT is 23.3 / 28.4°C/W in its two reference configurations. This is an estimate, not a substitute for the recommended operating limits; do not apply the junction-to-case thermal resistance as if all heat flowed through the package top. [TI measurement guidance](https://www.ti.com/lit/pdf/spra953), [TLV755P junction-temperature estimation](https://www.ti.com/lit/ds/symlink/tlv755p.pdf).

For example, **75°C package top at 25°C ambient, with 0.25 W dissipation**, implies approximately **81–82°C junction**. Extrapolating the same temperature rise to a 45°C environment gives about **101–102°C**; verify in the enclosure because power, airflow and nearby heating can change. A working design target around 100–110°C maximum estimated junction provides margin below the 125°C recommended limit; it is a proposed engineering target, not TI's formal limit or an enclosure touch-temperature criterion.

| Result | Design response |
|---|---|
| Stable 3V3 and adequate junction-temperature margin at intended worst use/ambient | Keep the LDO; normal warmth needs no fix. |
| Margin becomes poor mainly when charging | Reduce charging current and retest the surrounding temperature; U3's own conversion loss is unchanged at fixed load/input. |
| U3 itself is too hot at the permitted workload | Improve connected copper/ground heat paths, or use a thermally enhanced regulator package on a revision. An exposed-pad package requires its intended footprint/ground connection. |
| Sustained power loss is intrinsically too large | Use a suitable switching supply on a revision, with battery-range, transient, quiescent-current and EMI requirements checked. |

A **5 V shunt zener is not the thermal remedy**: it does not reduce the normal 5-to-3.3 V loss, needs controlled current for clamping, and adds dissipation/load when it conducts. A series dropper only relocates heat and consumes voltage headroom; altering the USB branch also requires checking mux selection thresholds. Neither is a justified automatic modification based on a warm package.

Reproducible values and assumptions: [thermal-scenarios.json](docs/audit-2026-09-16/thermal-scenarios.json), generated by `thermal_scenarios.py` in the same folder.

## 4. Battery protection: a newly identified fault path

### Why the reverse-insertion claim is unsafe with USB present

The actual netlist, not the “reverse polarity protection” label, gives:

- **Q3:** source B+, drain toward R27/Q8, gate pulled mainly toward B− through 10 kΩ R56, with 1 MΩ R57 to B+.
- **Q8:** source P+, drain toward R27/Q3, **gate permanently at board GND**.
- **U5:** VCC = P+, GND = B−.
- **Q1:** low-side battery protection between B− and board GND.

*(This section was written when `Q3`/`Q8` were AO3419; the board now fits AO3401A in all four P-channel positions — same pinout and body-diode direction, so the analysis stands as written.)* An AO3419 P-channel MOSFET's body diode conducts **drain to source**. USB can make the charger raise P+ and enhance Q8 even when the cell is reversed. Q3's channel may be off, but its body diode faces from the common-drain path **into B+**. Therefore “Q3 is off” does not establish isolation from the charger. [AO3419](https://www.aosmd.com/res/data_sheets/AO3419.pdf).

One conditional voltage calculation exposes the problem. If Q8 is on, neglect its small drop; if Q3's diode conducts, `B+ ≈ P+ − Vf`. For a reversed cell, `B− = B+ + Vcell`. Consequently:

```text
U5 supply = VCC − GND = P+ − B− ≈ Vf − Vcell
Example: 0.7 V − 4.2 V = −3.5 V
```

This is **not a simulated steady state or a predicted fault current**. Internal clamps, the charger, Q1 and parasitics will change the resulting voltages/currents. It demonstrates that the claimed benign blocked state is unsupported and that U5 can be forced toward a strongly reversed supply. Opening Q1 does not disconnect U5's ground pin from B−. Charger-present reverse-polarity protection requires deliberate design; the same general pitfall is discussed in [Analog Devices AN-171](https://www.analog.com/en/resources/app-notes/an-171.html).

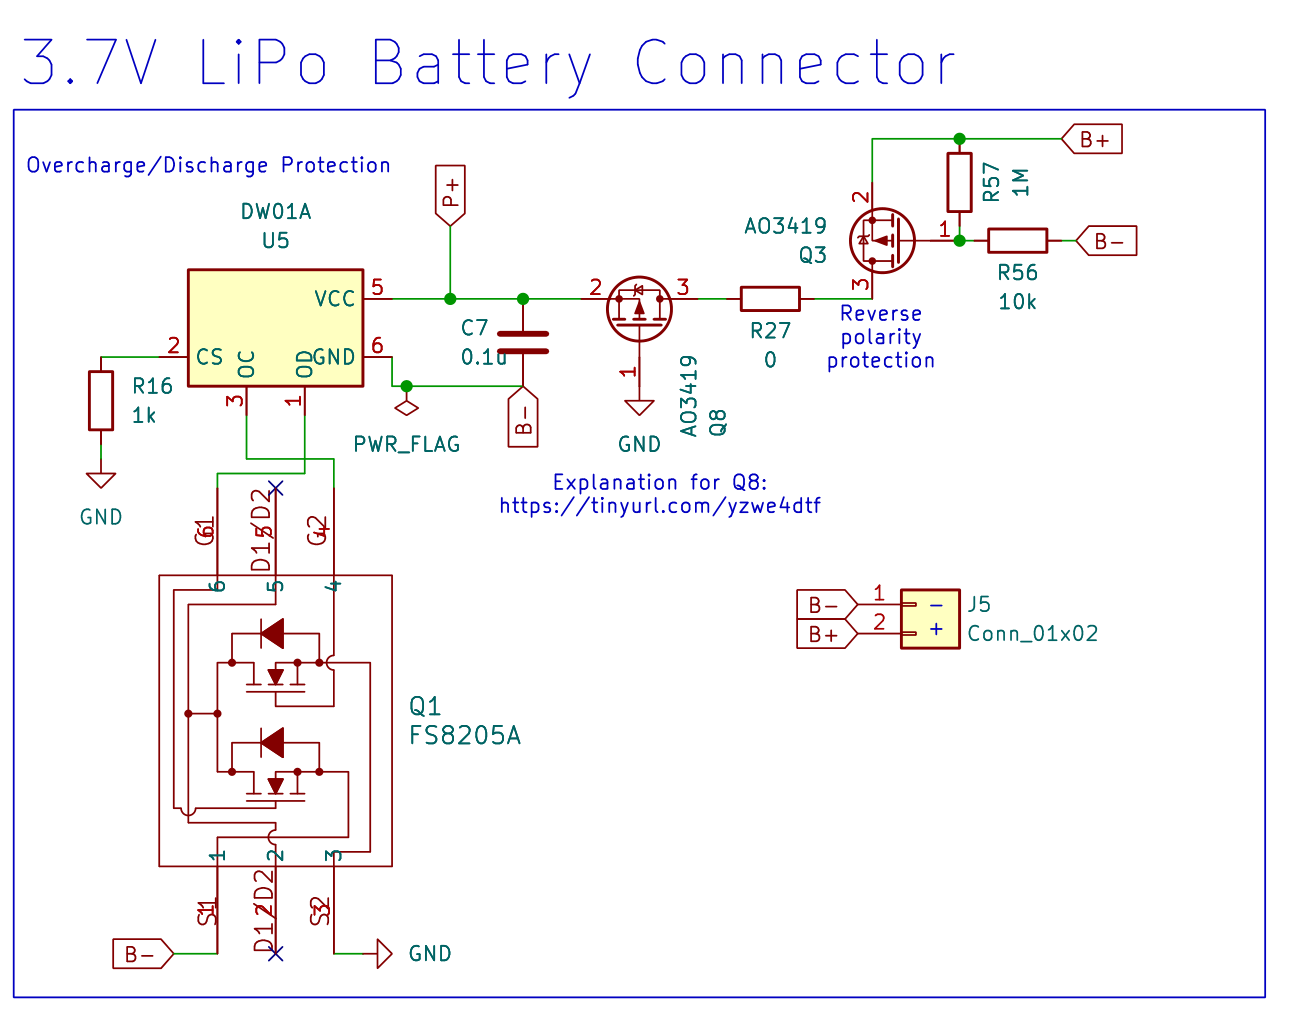
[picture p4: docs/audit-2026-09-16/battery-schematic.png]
Reviewed battery circuit


**Disposition:** remove the “bare cell safe/full reverse protection” claim. Rework and validate the topology before a replaceable-cell product. Do not simply flip a transistor or add one resistor without checking normal charge/discharge, hot-plug, protection cutoff and recovery. A restricted engineering prototype can use a permanently verified correct-polarity harness. Fault characterization should use current-limited simulators with monitored IC voltages, **not deliberate reversal of a real LiPo**.

### Does USB operation make the existing fault harmless?

**No, although the system may still run from USB.** The actual source has two parallel USB-fed branches: USB_VBUS → U2/TPS2116 VIN1 → LDO_IN → U3, and USB_VBUS → U11/TP4056 → P+ → battery/protection circuitry. Selecting USB in the mux does not disconnect the charger branch. Normal USB supply can therefore sustain the MCU/LDO while U5 or the battery-path devices are stressed. If the fault pulls down VBUS or violates a mux input rating, continued system operation is not guaranteed either. [TPS2116 datasheet](https://www.ti.com/lit/ds/symlink/tps2116.pdf).

The evidence establishes a potentially damaging, unqualified electrical condition, **not certain instantaneous chip destruction or a measured time-to-failure**. U5's reversed supply is the most direct IC concern; its published limits do not authorize several volts of reverse supply. Internal junction conduction can begin before noticeable heating. Depending on the actual parasitic paths and current, the result could be recovery, latent damage, prompt IC failure, or subsequent heating of other battery-path parts. No safe user reaction time has been established. If reverse-supply junctions complete a local battery loop through U5 and Q8/Q3, the cell can also supply fault current; the approximately 0.25 A programmed charger current is not a proven upper bound on every fault current. This is a conditional mechanism, not a simulated clamp model.

The trigger is overlap of USB power and reversed battery insertion, in **either insertion order**. It is not limited to a user trying USB after the board fails to start. For the owner's current controlled prototype, verifying the cable polarity before connection remains a reasonable way to use the existing board; the analysis does not establish an everyday fault with a correctly connected cell. A field-replaceable battery requires a different error-tolerance decision.

### Applied 2026-09-17: charge-enable gated by a B−-referenced cell-polarity detector ("Fix 4")

**Applied to the schematic and PCB (netlist-confirmed as of the 2026-09-17 21:11 board save).** Rather than re-engineering the power switch, the fix removes the *aggressor*: the TP4056 only sources into P+ while its CE pin is high, and with CE low the BAT pin is isolated (< 2 µA in disable/sleep mode; the internal pass PMOS body diode is reverse-biased for VCC > BAT — C16581 sheet). CE is therefore driven high only while a correctly oriented cell is present.

| Part (all existing BOM lines) | Connection |
|---|---|
| Q_det = `Q9` — BSS138 (C7420339) | gate ← **B+** via R_a; **source → raw B−**; drain → node X (`/DET_NODE`) |
| R_a = `R79` — 100 kΩ (C25803) | B+ → Q_det gate |
| R_b = `R80` — 1 MΩ (C22935) | Q_det gate → **B−** (no cell ⇒ Vgs = 0 ⇒ off) |
| R_c = `R81` — 1 MΩ | X → 3V3 |
| Q_pass = `Q2` — **AO3401A (C15127)** | source → 3V3; gate → X; drain → **U11 pin 8 (CE)** |
| R_d = `R82` — 1 MΩ | CE → GND (default: charger disabled) |
| — | **CE → USB_VBUS tie removed.** Q3, Q8, R27, R56, R57, U5, Q1 unchanged. |

*(Applied with `Q_pass` = AO3401A, not the AO3419 named when this table was first drafted — AO3401A was already the board's adopted P-channel swap for Q2/Q3/Q7/Q8, see §12; same SOT-23 pinout, no change to the analysis below.)*

Correct cell → Q_det on → X ≈ B− → Q_pass on → CE = 3V3 → charging. Reversed or absent → X = 3V3 → Q_pass off → CE low → charger off. CE only ever sees 3V3 or GND, never raw battery. Neither transistor needs a low-threshold part: Q_det only sinks the 1 MΩ pull-up (gate = B− + 0.91·V_cell, 2.18 V at the 2.4 V DW01A cut-off against a 1.5 V worst-case Vth — simulated at that corner), and Q_pass drives a logic pin at Vgs ≈ −3.3 V.

**Idle drain — corrected 2026-09-18: ≈10 µA total, not ≈3.4 µA.** The original estimate only counted R_a+R_b (`R79`/`R80`) across the raw cell: `V_cell / (R79+R80) ≈ 3.7 V / 1.1 MΩ ≈ 3.4 µA` — that part is right, and is on top of the existing R56/R57 divider's own ≈3.7 µA. It missed R_c/R_d (`R81`/`R82`) on the **3V3 side**: whenever a correct cell is present, `/DET_NODE` sits at ≈B− and `CE` sits at ≈3V3, so each 1 MΩ resistor drops a full ≈3.3 V — `I ≈ 3.3 V / 1 MΩ ≈ 3.3 µA` apiece, ≈6.6 µA combined, drawn continuously from the always-on 3V3 rail (i.e. through the LDO, not directly from the cell). Total Fix 4 contribution ≈3.4 + 6.6 ≈ **10 µA**. Folded into the sleep-current estimate in `docs/HARDWARE.md` §16.

**Not worth reducing further.** Raising `R79`–`R82` to cut this trades directly against the leakage margin discussed two paragraphs below (`Q9`/`Q2` off-state leakage is already comparable to the bias current at 1 MΩ; going higher makes the logic-level margin worse, not better) for a saving smaller than `U3`'s own ≈25 µA quiescent draw. If deep-sleep current is ever worth chasing seriously, `U3`'s `EN` tied to `IN` (§8, hardware §3.5) is the larger, more separable target.

**Known, accepted limitation — not treated as a defect.** Fix 4 can only enable the charger while a correctly oriented cell shows above roughly 1–1.8 V at `J5` (`Q_det` gate = 0.909·V(J5), Vth 0.5–1.6 V depending on build). A pack whose own protection IC has already latched into over-discharge lockout (≈0 V at its leads) or a bare cell drained past that point cannot be revived by the on-board charger, because there is nothing left for `Q_det` to sense — a real behavior change from the pre-Fix-4 board, where CE tied straight to VBUS and the charger always tried. Judged an unrealistic/insubstantial scenario for this board's use case and **not pursued further**; if a rescue path is ever wanted, the node to drive is `Q_det`'s drain (`/DET_NODE`), e.g. a two-pad manual-override jumper to GND.

**The one non-obvious rule: the detector must sense B+ relative to B−, not system GND.** A cell at or below the DW01A cut-off has Q1 open and floats as a whole; a GND-referenced detector then reads ≈0 V, never enables CE, the charger never starts and Q1 never closes — a flat cell could never be recovered.

**Behavioral simulation (LTspice, as-built nets, generic VDMOS/diode models; not a device qualification).** The deck models Q3/Q8/R27/R56/R57 as netlisted, U5 with its GND→VCC substrate diode and CS ESD diodes (CS to GND through R16), Q1 as two body-diode NMOS, C7/C3/BAT_MONIT, the TP4056 as a CE-gated current source with no VCC→BAT conduction, and the TPS2116 as a blocking mux. Cells connect through a switch so every case starts from a defined state.

| Scenario | As-built | **Fix 4** |
|---|---|---|
| Discharge 3.7 V / charge 3.7 V | normal | normal, CE = 3.3 V |
| Charge a 2.5 V over-discharged cell (Q1 open) | 0.25 A | **0.25 A** (also at worst-case BSS138 Vth = 1.5 V) |
| **Reversed cell + USB** | **0.25 A sustained through the cell**, ≈2 mA in U5's CS ESD diode | CE off, charger 0, cell ≈8 µA, U5 supply +0.6 V |
| Reversed insert while P+ still charged (hot-swap; latched empty connector) | same 0.25 A | self-recovers to the µA state; U5 dips to ≈−0.14 V for µs while C3 (≈90 µJ) discharges |
| Reversed, no USB | µA | µA |

Findings that changed the picture: (1) the as-built hazard is a **sustained, charger-limited 0.25 A through the reversed cell** (charger → Q8 → Q3 body diode → cell → Q1 → GND) plus ESD-diode abuse — not the −3.5 V on U5 estimated above, because U5's CS pin clamps its GND pin through R16; the result is the same whether the unpowered DW01A drives or floats the FS8205A gates. (2) Alternatives rejected by the same deck: a GND-referenced CE-gate (flat-cell deadlock, above); tying Q8's gate to B− (still 0.25 A — the low side drags B− toward GND, so Q8 stays enhanced); the Q8-detector proposal below with a GND-referenced detector (same deadlock). A B−-referenced detector that also drives Q8's gate ("Fix 5") is equally safe and keeps U5 from ever going negative, but costs a second FET and ≈3.7 µA of Roff bias; not chosen. (3) An empty connector remains energized while USB is present (as built today); inserting a reversed cell into that state un-latches cleanly.

**Bench verification before relying on it (§13 step 9):** correct/reversed/flat-cell insertion with USB absent and present, removal followed by immediate reversed reinsertion, using a current-limited emulator — never a real reversed LiPo. Capture CE, P+, U5 VCC−GND and connector current. Decks and results: [run_revpol.py](docs/audit-2026-09-16/run_revpol.py), [run_revpol2.py](docs/audit-2026-09-16/run_revpol2.py), [revpol-results.json](docs/audit-2026-09-16/revpol-results.json), [revpol-results2.json](docs/audit-2026-09-16/revpol-results2.json).

### Superseded alternative: battery-polarity-controlled Q8 (not chosen — standby cost; kept for reference)

**Proposal, not applied to the schematic, PCB, or factory order.** Keep one AO3419 as the series power switch, and use a small N-channel MOSFET to control it from the voltage **across the raw cell terminals**. Q8's gate must no longer be permanently grounded. This is a topology to evaluate, with a defensible DC blocking mechanism; **the owner rejects the initial +42 µA standby penalty, so the illustrated 100 kΩ bias is a simulation baseline, not an accepted production recommendation.** A lower-consumption implementation and fault qualification remain necessary.

The intuition is: **a correctly connected cell turns on the detector, which turns on the power switch. A reversed cell turns the detector off, allowing a resistor to turn the power switch off even when USB is present.** The on-state power channel supports both charging and discharge. The remaining PMOS body diode faces from B+ toward P+, blocking the charger-to-reversed-cell direction when the channel is off.

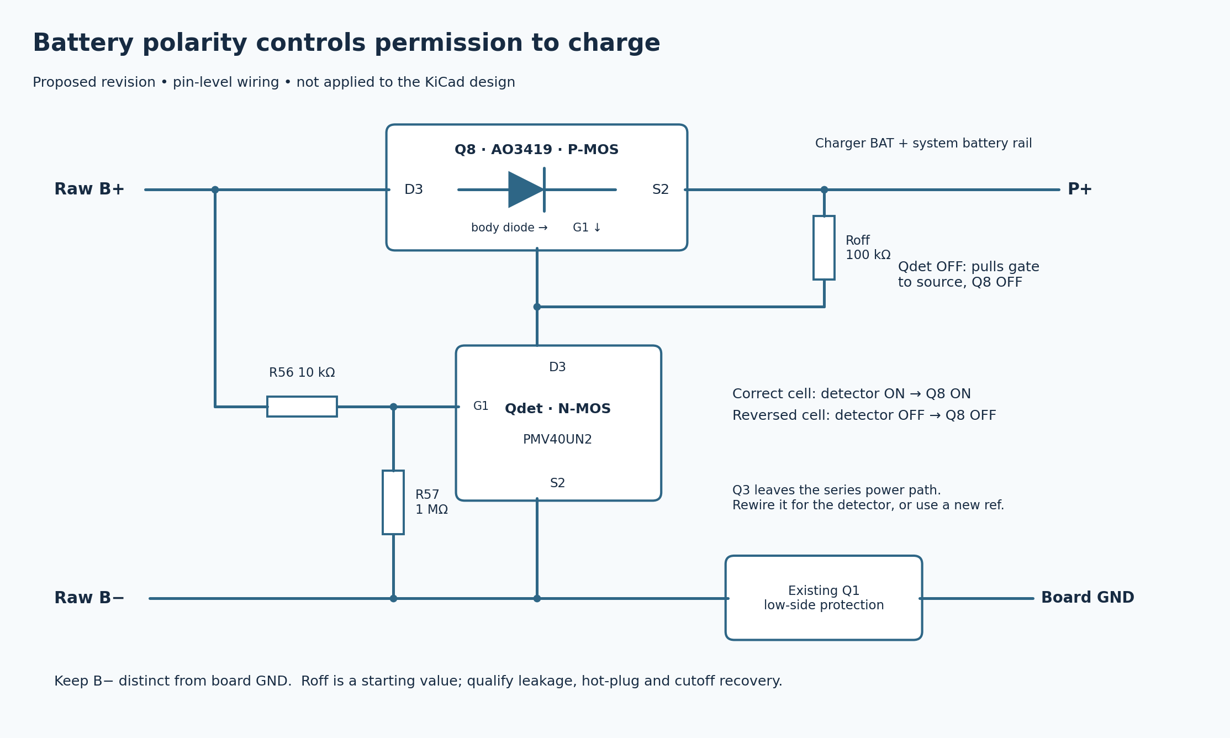
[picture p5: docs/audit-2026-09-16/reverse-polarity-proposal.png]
Proposed battery polarity detector and power switch


| Connection | Proposed wiring |
|---|---|
| Q8 AO3419 power switch | **Drain pin 3 → raw B+; source pin 2 → P+; gate pin 1 → detector drain.** R27 may remain as a suitably rated service jumper in the power path. |
| Original Q3 | Remove its PMOS from the series path. Its reference/location may be repurposed for the detector, with different wiring; **this is not a drop-in transistor substitution**. |
| Detector Qdet | N-channel candidate **Nexperia PMV40UN2**: drain pin 3 → Q8 gate; source pin 2 → **B−**; gate pin 1 → R56. |
| R56, 10 kΩ | Raw B+ → detector gate. |
| R57, 1 MΩ | Detector gate → raw B−. |
| New Roff, initially 100 kΩ | Q8 gate → Q8 source/P+. This establishes the off state when the detector is off. |
| Existing low-side protection | Preserve Q1 between B− and board GND, controlled by U5. **Do not short B− to GND or move the detector's reference to GND.** |

PMV40UN2 is a candidate with guaranteed 1.8 V gate-drive resistance and ±12 V gate tolerance; its gate can therefore withstand the nominal ±4.2 V cell-polarity test. Its role is to sink tens of microamps of gate-bias current, not supply the board. Hot leakage and switching behavior still need qualification. [Nexperia datasheet](https://assets.nexperia.com/documents/data-sheet/PMV40UN2.pdf).

For Q8, a 4.2 V charger rail against a −4.2 V reversed battery terminal produces approximately 8.4 V drain-source stress with a conducting low-side return, within AO3419's 20 V rating before transients. At an actual gate drive of at least 2.5 V, its 25 °C maximum resistance specification is 140 mΩ: 500 mA gives 70 mV and 35 mW for this one FET. Hot resistance is higher. Removing the second series PMOS reduces conduction loss; these values exclude Q1, wiring and R27. The AO3419's 1.8 V resistance row is **typical-only**, not a maximum guarantee. [AOS datasheet](https://www.aosmd.com/res/data_sheets/AO3419.pdf).

| State | Expected behavior and limits |
|---|---|
| Correct cell, battery operation | Detector on, Q8 on; its body diode provides an initial supply path during startup. |
| Correct cell, USB charging | Detector remains on from positive raw-cell voltage; Q8 permits charging in the opposite direction. |
| Reversed cell, USB absent or present | Detector gate-source voltage is negative. Roff brings Q8 gate to its source; Q8's channel and reverse-biased body diode block the sustained power path. Small bias/leakage currents remain. |
| No battery, USB present | **Do not assume B+ is unpowered.** An already-on Q8 can feed B+ from the charger and keep the detector on. This circuit detects applied polarity, not battery presence. |
| Protected pack presenting 0 V | Automatic recovery is **not guaranteed**. A cold off-state detector has no positive cell voltage to enable charging. Normal recovery from the onboard DW01 cutoff with a still-positive raw cell is a different case and must be tested separately. |

**Standby cost:** with the initial values, nominal bias is approximately 27–46 µA across a 2.5–4.2 V cell, excluding device leakage and rail drops. At 4.2 V this is about **42 µA more than the existing divider**, or **30 mAh per 30 days** if that current persisted continuously. The extra bias can continue after Q1 disconnects the system, so it matters for depleted-cell storage. Increasing Roff reduces consumption but slows turn-off and increases sensitivity to detector/board leakage; do not make that change without testing. At 100 kΩ, just 5 µA pulling the gate down produces 0.5 V gate-source bias, comparable to the AO3419's minimum 25 °C threshold. The detector's 25 °C leakage limit is not a hot-temperature guarantee.

The following are **bias calculations, not approved resistor substitutions**, at 4.2 V with R56 = 10 kΩ. Total includes Roff and the detector divider, assumes negligible on-state detector voltage, and excludes leakage. The existing divider alone draws 4.158 µA.

| Roff | Detector R57 | Proposed total bias | Increase over existing divider |
|---|---|---|---|
| 100 kΩ | 1 MΩ | 46.16 µA | 42.00 µA |
| 470 kΩ | 1 MΩ | 13.09 µA | 8.94 µA |
| 1 MΩ | 1 MΩ | 8.36 µA | 4.20 µA |
| 1 MΩ | 10 MΩ | 4.62 µA | 0.46 µA |

Thus the 42 µA increase is not fundamental. However, PMV40UN2's specified room-temperature off leakage can be as large as 1 µA at its stated test voltage: that current through 1 MΩ would create 1 V of unintended PMOS gate bias. This is a conservative margin check, **not a claim that the detector actually leaks 1 µA in this circuit's reversed-gate, approximately 4 V condition**. The present part selection and generic simulations do not guarantee the lower-current rows. A low-leakage small-signal detector or an active gate pull-up could improve that tradeoff; select and qualify it for the intended temperature range, board leakage and insertion transients. Set a low incremental standby budget (for example, ≤1–5 µA) before settling the implementation rather than accepting +42 µA for this e-reader.

**Evidence and qualification:** eight LTspice DC cases were run with explicitly generic MOSFET approximations. They demonstrate bidirectional normal operation, a reversed-cell off state with USB present, a blocked 0 V startup case, and the energized-empty-connector state described above. They do **not** model the actual TP4056/DW01/FS8205, device leakage/corners or hot-plug behavior. Files: [netlist](docs/audit-2026-09-16/reverse-polarity-concept.cir), [runner/diagram generator](docs/audit-2026-09-16/reverse_polarity_concept.py), [results and bias calculations](docs/audit-2026-09-16/reverse-polarity-concept.json). Simulation raw files stay outside the repo.

Before releasing this change, exercise correct/reversed insertion with USB both absent and active, removal followed by immediate reversed reinsertion, contact bounce, low-side cutoff/recovery, and the intended temperature range. Use a suitable current-limited battery emulator; capture P+, U5 VCC−GND, Q8 gate-source voltage and connector current. Check MOSFET pulse energy/operating area and all IC voltage limits, not merely the final off state. In particular, the already-energized connector and charger output capacitance can produce an insertion pulse before the detector turns Q8 off. Charger-connected reverse protection is also the subject of [ADI AN-171](https://www.analog.com/en/resources/app-notes/an-171.html); the circuit proposed here is our analysis, **not a claimed reproduction or validation of ADI's tested circuits**.

### Normal-operation observations

The exact TECH PUBLIC six-pin FS8205A pinout agrees with Q1: S1 pin 1 → B−, S2 pin 3 → GND, gates 6/4 → OD/OC. Pins 2/5 are internally common drains; leaving their PCB pads externally unconnected is not an open discharge path. Vendor package identity still matters. [Manufacturer drawing mirror](https://images.100y.com.tw/pdf_file/41-FS8205A.pdf).

**Vendor package identity, resolved 2026-09-18.** A review round flagged that Fortune Semiconductor's own "FS8205A" datasheet (every revision 1.0–1.7, 2009–2016) is TSSOP-8 only — Fortune's SOT-23-6 dual-FET part is named "FS8205," no A — and the hand-build BOM's manufacturer field (`fabrication/BOM_handbuild_digikey.csv`, `part_fields.csv`) names Fortune for Q1. Re-checked directly against Fortune's datasheets and against LCSC/DigiKey listings: **"FS8205A" genuinely exists as an orderable SOT-23-6 part, DigiKey-findable, just not from Fortune.** EVVOSEMI sells it in SOT-23-6 (DigiKey PN `26220994`, their own datasheet's Ordering Info gives "Equivalent Part Number: FS8205A," pinout matches Q1's footprint exactly), and TECH PUBLIC's SOT-23-6 FS8205A is the LCSC `C2830320` already used on the JLC build. **Fix: change the Manufacturer field to EVVOSEMI (or TECH PUBLIC) — the MPN "FS8205A" itself is correct, it was only the assumed manufacturer that was wrong.** (`part_fields.csv`, the schematic/PCB fields and `fabrication/BOM_handbuild_digikey.csv` all carry EVVOSEMI as of 2026-09-18.)

The ordered PUOLOP DW01A C351410 senses **P+ after the two PMOSs**, rather than directly across the physical cell. Load-dependent PMOS drop and transients affect its apparent cell voltage. Its reference circuit has a **100 Ω VCC filter resistor**, absent here; C7 alone is not that filter. Review the sensing point and filtering in the redesign. Adding the resistor alone does not repair the reverse-battery problem. [Exact DW01A sheet](https://datasheet.lcsc.com/datasheet/pdf/0d2b2b5e8d1207bf276387cb4ff3a495.pdf?productCode=C351410).

R56+R57 draws about **4.16 µA at 4.2 V** across the cell even after low-side cutoff. R27's nominal 0 Ω still has finite current/thermal/drop ratings. J5 pin 1 is B−, pin 2 B+; connector style does not guarantee cable polarity. The approximately 2.5 V protection cutoff is a last-resort cell protection point, not the normal endpoint of a 3.3 V ESP32 system. Firmware must stop earlier based on usable rail headroom and the cell specification.

## 5. MCU, reset, boot and supply decoupling

The ordered module is **ESP32-S3-WROOM-1-N16R8**. GPIO35/36/37 are left unused, consistent with octal PSRAM. USB, ADC and display/SD assignments agree with the netlist. EN has 10 kΩ/1 µF startup timing, with SW11 reset through 100 Ω. GPIO0 has its pull-up and accessible SW6 pads, but **SW6 is unselected in the order**. UART RX/TX are on TP1/TP2; no UART DTR/RTS automatic boot circuit is provided.

Expansion GPIO3/45/46 are boot straps. Attached accessories must respect reset levels; setting software pulls afterward cannot repair a wrong sampled strap. GPIO46 is an ordinary input/output pin on the ESP32-S3 (the "input-only" restriction belongs to GPIO34–39 of the original ESP32, and an earlier draft of this review carried it over by mistake); what matters is that it is a strapping pin with a weak internal pull-down that must read low at reset. GPIO39–42 overlap JTAG roles, so firmware must configure them for SCL, COLOR_SEL, TP_INT and PWM_LED. Do not assume a debug configuration is harmless to connected peripherals. [ESP32-S3 datasheet](https://www.espressif.com/sites/default/files/documentation/esp32-s3_datasheet_en.pdf), [Espressif schematic checklist](https://docs.espressif.com/projects/esp-hardware-design-guidelines/en/latest/esp32s3/schematic-checklist.html).

C32 is approximately **4.61 mm** from the module supply pad; C33 and the module's internal bypassing also serve local transients. **C22 is 51.84 mm from that pad**, near the display area: its source annotation does not make it MCU-local. This is a placement/documentation correction, not a claim that the module has no decoupling. Confirm 3V3 at the module under Wi-Fi/SD/display overlap.

## 6. SDMMC: sound power logic, unresolved socket mechanics

### Electrical checks

The original, TF PUSH and GCT contact numbering agrees: **1 DAT2, 2 DAT3, 3 CMD, 4 VDD, 5 CLK, 6 GND, 7 DAT0, 8 DAT1**. Shield/detect arrangement does not provide an independent firmware card-detect signal here. **Q7 (SD VDD switch) has no gate slow-down:** IO10 drives the gate through R78 (1 kΩ) and R40 (100 kΩ) holds it off, so the AO3401A turns on in microseconds into C36+C37 (≈1.1 µF) plus the card's own capacitance — faster than the SD spec's suggested minimum VDD ramp (~0.1 ms) and able to dip 3V3 by a few hundred mV briefly. Optional fix if the first article shows card-init glitches: 47–100 nF from gate to 3V3 (τ ≈ 50–100 µs with R78). *(Added 2026-09-18.)*

All six lines have 33 Ω series resistors. CMD/DAT pull-ups return to switched **SD_VDD**; CLK has no pull-up. DAT0/DAT1 are protected by **U9**, the other four signals by U1. They are not missing ESD protection. The exact TECH PUBLIC array pinout is now verified (§10).

Q7 source = 3V3, drain = SD_VDD; R40 pulls its gate high and R78 is the series control resistor:

- `SD_ACTIVATE LOW`: on.
- `HIGH`: off.
- **High impedance with internal pulls disabled:** off through external R40; no actively latched high GPIO is required during sleep.

Flush/unmount, stop the SD host, then remove active drives/internal pull-ups from all bus pins before power-off. An unpowered card can otherwise be back-powered through signals. R77 and nominal C36+C37 give **0.11 s** no-card discharge time constant; the card adds capacitance. Measure SD_VDD before assuming a short off interval is a true power cycle. The actual card-side routes after the resistors are approximately 5.95–7.94 mm with no main-path vias; longer protection branches still deserve high-speed testing.

### J7 peg fit — resolved (2026-09-17)

Root cause: the dual-source land was built from the TF PUSH DXF as "fully SMD, no pegs", ignoring the datasheet's **2 × Ø0.80 mm pegs at 8.00 mm**; the first assembled order was cancelled over it. The owner's interim fix (left slot 2.25 × 1.05 mm, right hole Ø1.00) was still ≈0.1 mm short in Y for both candidates.

| Feature (footprint-local mm, contacts at Y = 0) | Now in the library and on the board |
|---|---|
| Left locating hole | NPTH **slot 2.25 × 1.50**, center (−2.73, 11.20) — union of the TF peg (−3.30, 11.00, Ø0.80) and GCT peg (−2.13, 11.42, Ø0.75) plus ≈0.15 mm clearance |
| Right locating hole | NPTH **slot 1.05 × 1.50**, center (4.70, 11.20) — TF (4.70, 11.00) and GCT (4.67, 11.42) share X and differ 0.42 mm in Y |
| GCT body keepout | 10.20 × 4.05 marked on **Dwgs.User**, center (−0.68, 5.53) (X −5.78…4.42, Y 3.50…7.55) |

The owner confirmed seating against **both parts' 3D models** and updated the placed footprint; the library `.kicad_mod` carries the same geometry and a corrected description, so a library update cannot reintroduce the round holes. Physical first-article confirmation of TF PUSH seating and fillets remains in §13.

GCT's keepout still contains three vias and component-side traces. That matters only if an MEM2075 is hand-fitted; it is irrelevant to the TF PUSH factory build. Reroute before a GCT build, not before this one.

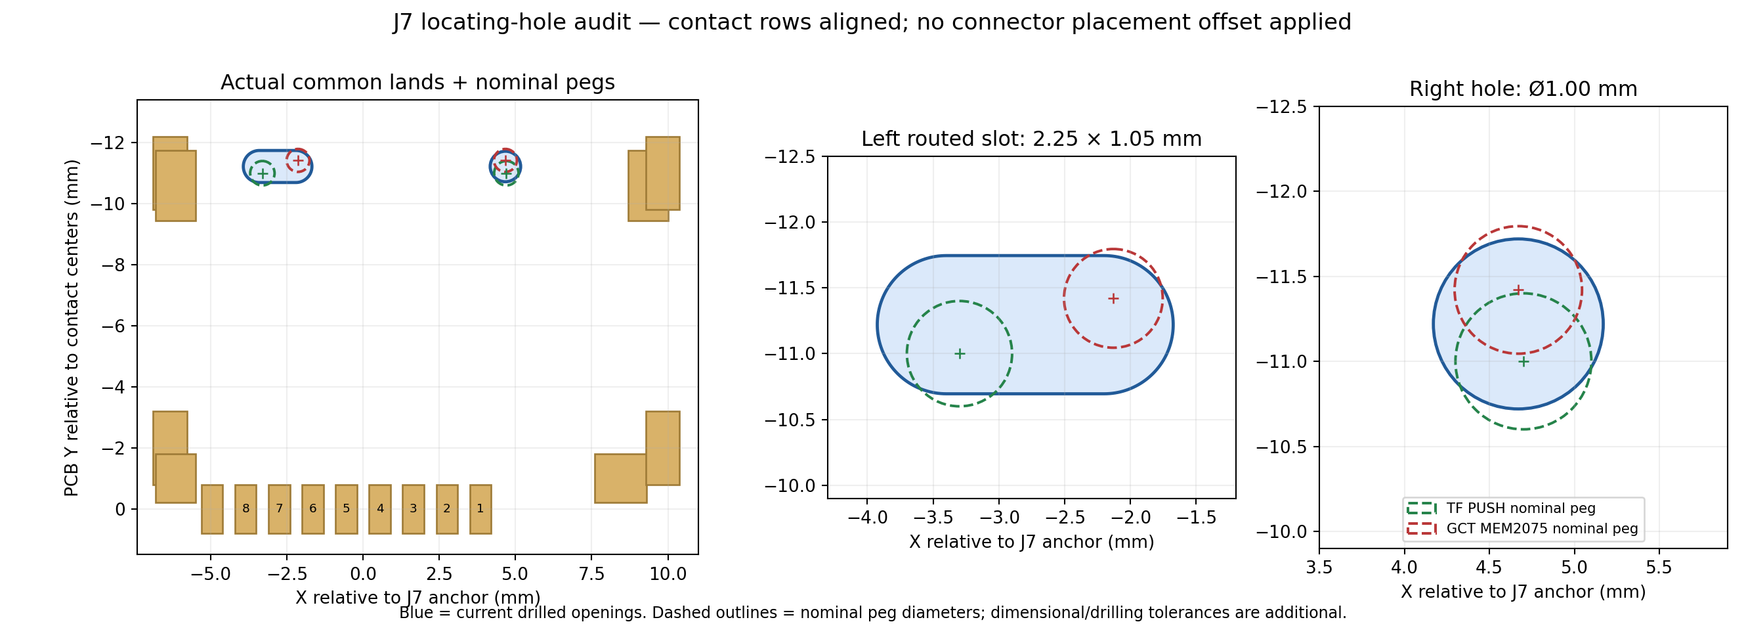
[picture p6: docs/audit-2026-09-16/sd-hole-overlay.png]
Socket hole comparison (pre-fix overlay)


The GCT model reference into Downloads is nonportable. [SHOU HAN sheet](https://datasheet.lcsc.com/datasheet/pdf/dc83ceb7bc09989eab2815b685da60e4.pdf?productCode=C393941), [GCT drawing](https://gct.co/files/drawings/mem2075.pdf), [measured comparison](docs/audit-2026-09-16/sd-mechanical-comparison.json).

## 7. E-paper: Q4 replacement and switching qualification

J2 pin 5 is **VSH2**, not VGH. Digital mapping, boost rectifier directions and negative charge-pump polarity agree with the panel topology. Preserve the explicitly **50 V** capacitors, including C11/C13–C17 at 4.7 µF and C18–C20 at 1 µF in the order. Effective capacitance under bias is a separate qualification.

EPD_RST has its pull-up; EPD_CS has no discrete pull-up. Firmware should establish an inactive CS before clock activity and maintain defined panel control levels in sleep. A CS pull-up is an optional next-revision improvement, not an identified wiring defect. The 40 V charge-pump diodes have plausible normal rail-voltage margin, but hot leakage and switching overshoot remain part of the rail test; the flying node's diode clamp must be considered before incorrectly adding both rail magnitudes as a diode's reverse stress.

Q4 gate is GDR, source is RESE/R14, drain is EINK_SW. The panel reference requires **VDS ≥30 V, VGS(th) ≤1.5 V, RDS(on) ≤0.4 Ω**. The ordered hongjiacheng BSS138 C7420339 has **3 Ω maximum at 4.5 V**, only 1.2 Ω typical, and no 2.5/3.3 V resistance guarantee. It is outside that selection criterion. Low average display current does not qualify its switching role. [Panel reference p11](https://www.good-display.com/companyfile/1946.html), [exact BSS138 sheet](https://datasheet.lcsc.com/datasheet/pdf/e82111e7bf6514856f73f1b91d3645f8.pdf?productCode=C7420339).

### Replacement comparison

All parts below are 30 V N-channel. Resistance is maximum at 25°C; charge/capacitance are typical. Charge tests use different drain voltages/currents, and capacitance tests different drain biases; the figures compare approximate drive burden, **not exact switching-time ratios**.

| Part | RDS(on) at 2.5 V | Qg at 4.5 V | Ciss | Assessment |
|---|---:|---:|---:|---|
| Vishay Si1308EDL, panel reference | 185 mΩ | 1.4 nC | 105 pF | Reference drive burden; **SC-70**, not a normal SOT-23 substitute |
| **Infineon IRLML6346TRPBF / C67276** | **80 mΩ** | **2.9 nC** | **270 pF** | Preferred existing-footprint candidate |
| Diodes DMN3150L-7 / C156268 | 115 mΩ | 3.7 nC | 305 pF | Reasonable alternate |
| AOS AO3400A / C20917 | 48 mΩ | 6.0 nC | 630 pF | Basic cost candidate; heavier unknown-driver load |
| Nexperia PMV40UN2 | 53 mΩ; 78 mΩ at 1.8 V | 7.0 nC | 635 pF | Stronger low-drive guarantee, higher charge |
| Diodes DMN3200U-7 | 110 mΩ; 200 mΩ at 1.5 V | Not tabulated | 290 pF | Worth characterization; 471/104 ns published turn-off delay/fall less attractive for unknown GDR drive |

Primary sheets: [Si1308EDL](https://www.vishay.com/docs/63399/si1308edl.pdf), [IRLML6346](https://www.infineon.com/assets/row/public/documents/24/49/infineon-irlml6346-datasheet-en.pdf), [DMN3150L](https://www.diodes.com/datasheet/download/DMN3150L.pdf), [AO3400A](https://www.aosmd.com/res/data_sheets/AO3400A.pdf), [PMV40UN2](https://assets.nexperia.com/documents/data-sheet/PMV40UN2.pdf), [DMN3200U](https://www.diodes.com/datasheet/download/DMN3200U.pdf). [Exact JLC Infineon listing](https://jlcpcb.com/partdetail/InfineonTechnologies-IRLML6346TRPBF/C67276).

**Applied 2026-09-17: the source now specifies IRLML6346TRPBF (C67276) for Q4;** carry C67276 in the factory BOM so a clone or BSS138 is not substituted. IRLML6346's G1/S2/D3 functions and 1.90 mm lead pitch agree with the current SOT-23 pads. Its threshold test current differs from some alternatives; threshold alone is not an on-resistance guarantee. Specify the genuine manufacturer part rather than silently approving every clone with a related name. Q5/Q6 only select approximately 15 mA branches and do not inherit Q4's rejection.

R14 raises the source: `VGS = VGDR − ISW × R14`. With R14 = 2.2 Ω (3 Ω before 2026-09-18) and GDR at 3.3 V, illustrative 100/200/300 mA pulses leave **3.1/2.9/2.6 V VGS** (3.0/2.7/2.4 V with the former 3 Ω). The local SSD1677 sheet does not sufficiently specify loaded GDR drive/RESE trip behavior to prove this substitution solely by calculation. R15 = 10 kΩ also draws 0.33 mA at a 3.3 V gate level.

Until 2026-09-18, L1 = 22 µH, R14 = 3 Ω and R15 = 10 kΩ differed from the reference's 47 µH / 2.2 Ω / 1 MΩ; L1 and R14 now match it and only R15 (10 kΩ vs 1 MΩ, a gate pull-down chosen for a defined off state) still differs. The earlier differences were a **qualification requirement**, not proof the values were wrong. Earlier absolute claims that 22 µH guarantees particular peak currents or that 47 µH is categorically wrong were unsupported. R14's 0.1 W corresponds to **183 mA RMS** at full continuous rating; permissible pulse current depends on duty, pulse capability and derating.

**Reference values confirmed 2026-09-18.** The earlier "panel reference p11" citation is now corroborated by a primary source: the Solomon Systech SSD1677 datasheet (§13 "Application Circuit," Table 13-1, p.45) specifies L=47 µH (Sumida CDRH2D18/LDNP-470NC), R(sense)=2.2 Ω, matching a `GDR`/`RESE`/peak-current-mode boost topology consistent with this board's Q4/L1/R14 — RESE's internal comparator threshold is not published, but the topology confirms `I_peak ≈ V_th(internal) / R14`, so the earlier `(22/47)×(2.2/3)² ≈ 0.25×` reference-energy estimate is on the right physical model.

**L1: applied 2026-09-18, 22 µH → 47 µH.** The initial survey (same-footprint 3.0×3.0 mm candidates only) found nothing workable — the one same-footprint 47 µH shielded part is TDK `VLS3012CX-470M-1`, DigiKey-only with a ~12-week lead time, and every in-stock LCSC 47 µH candidate in that size needed a visibly larger, unshielded footprint. Once footprint was no longer treated as a constraint, several dual/LCSC-side candidates were surveyed (SHOU HAN `CYA1040-47UH` and CENKER `CKCS6045`/`CKCS5040` — excellent LCSC pricing, not DigiKey-carried at all; TDK `VLS5045EX-470M-H` — genuinely dual-sourced but didn't beat LCSC-side cost, the owner's stated priority; a Bourns `SRN5040-470M` pairing — **initially read as shielded from an automated DigiKey summary, later found to be semi-shielded per Bourns' own datasheet title, "SRN5040 Series - Semi-shielded Power Inductors" — not used**). Final part: **Laird `TYS5040470M-10`** (prime/DigiKey — confirmed direct-sold, active, 5.00×5.00×4.20 mm, shielded per Laird's own datasheet ("magnetic shielded structure"), Isat 1.1 A, DCR 272 mΩ max, rated 1 A, $0.41/$0.34/$0.28 @1/10/100, 24.2k stock) paired with **Sunltech `SLW5040S470MST` / LCSC `C206267`** (JLC build — 5.0×5.0×4.0 mm, shielded, Isat 1.3 A, DCR 650 mΩ, $0.046/pc @qty10 down to $0.024/pc @qty10.5k, 1.85k stock). Both parts are shielded and the same physical size — no shielding or footprint asymmetry between builds.

**This is a footprint change, not a drop-in swap** — `L1`'s land needs to grow from 3.0×3.0 mm to 5.0×5.0 mm, and the nearest neighbors (a 0603 cap at 3.08 mm, a 0603 resistor at 3.46 mm, `Q4`'s SOT-23 at 3.93 mm, a SOD-123 diode at 4.35 mm, all measured center-to-center from `L1`'s old position via pcbnew) will very likely need to shift to make room. **Footprint applied: `Inductor_SMD:L_APV_ANR5040`** (1.4 mm pads, 2.3 mm gap, 5.1 mm total span) — checked directly against Bourns' own published recommended land pattern for this case class (1.5 mm pads, 2.1 mm gap, 5.1 mm span): a close, comfortably conservative match. A footprint generated for a Cenker part was tried first and rejected — its 1.1 mm pad gap was a full millimeter tighter than Bourns' recommendation, a real solder-bridging risk during reflow. Schematic Value/MPN/Manufacturer/LCSC fields need to match the parts above.

**R14: applied 2026-09-18, 3 Ω → 2.2 Ω.** Now Yageo `RC0603FR-072R2L` (JLC code `C22939`, a Basic UNI-ROYAL equivalent, since 2026-09-20; `C112307` before that), same 0603 1% series as the prior value; the former JLC code `C22356394` was an HKR `RCA033RFLF` at $0.0016 and `C112307` is $0.0092, so the change costs under a cent per board and both are Extended parts (the Extended-part count does not change). With L1 now genuinely at 47 µH, this lands the pair exactly on the SSD1677 reference operating point instead of partway there. **Modeled safe against every component rating** (peak current rises 3/2.2 ≈ 1.36×, per-pulse energy 1.36² ≈ 1.86×, still far under the new L1's 1.1–1.3 A Isat and Q4's current rating) **but has not been bench-verified** — scope GDR/RESE and confirm VGH/VGL/VSH settle within SSD1677 spec (Table 11-1) on the first boards.

### Critical e-paper layout

EINK_SW's branch-inclusive copper length is **16.53 mm, no vias**. Q4 source to R14's sense pad is about **5.73 mm routed**. R14's positive sense pickup branches at the resistor pad, which is good, but the return to J2 RESE is **42.74 mm**; GDR to Q4 is **52.22 mm routed**. These are much longer than straight-line distances. Opposite-layer ground covers about 98% of these control routes in the geometric screening, which helps but does not prove quiet sensing. Shortening GDR/RESE and improving the local current-return geometry would be worthwhile on a revision.

**Re-measured 2026-09-18 after the L1 move.** `EINK_SW` copper is **15.38 mm** with no vias (was 16.53 mm); the `C10`→`L1`→`Q4`→`R14` pad-centre loop area grew from ≈24 to ≈33 mm² (+36 %) because the 5×5 mm inductor is bigger, and `Q4`→`D5`→`C14` from ≈23 to ≈26 mm². `GDR` and `RESE` are unchanged by the move: **36.3 mm** and **36.6 mm** by the current measurement (the 52.22/42.74 mm quoted above came from an earlier branch-inclusive method and should not be compared directly), and they still run **≈18 mm side by side on one layer at a 0.15 mm gap** — a coupling item for the first-article scope check. `C10` (3V3 input cap for `L1`) is now ≈4.1 mm from `L1` (≈3.1 mm before) and `L1` still has only one GND via within 4 mm. No DRC clearance regressions came from the move.

Scope Q4 **gate-to-source**, drain-to-source and R14 voltage with appropriate low-inductance probing during startup, full/partial updates and low battery. Check rail buildup and overshoot before declaring this block qualified. PREVGH/PREVGL are filtered rails; their longer routing is a different concern from the high-dV/dt EINK_SW node.

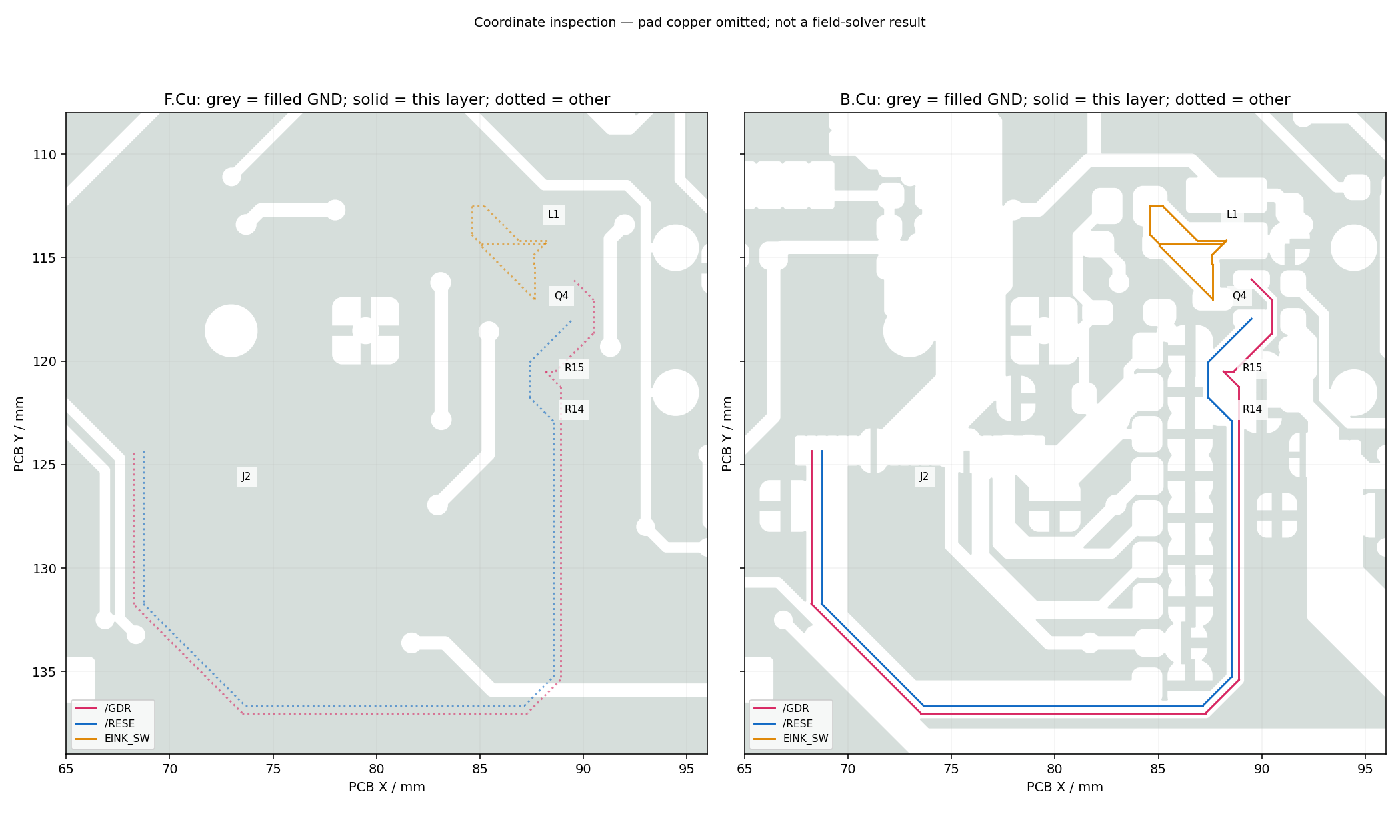
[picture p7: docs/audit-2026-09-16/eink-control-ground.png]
E-paper control routing and ground


## 8. Frontlight: sample mapping, current and dynamic behavior

### Physical sample versus supplier drawing

| Pin | PCB and owner-confirmed sample | FL01C specification | Conflicting FT01C drawing |
|---|---|---|---|
| 1 | C+ | C+ | W− |
| 2 | C− | C− | W+ |
| 3/4 | NC | NC | NC |
| 5 | W+ | W+ | C− |
| 6 | W− | W− | C+ |

Keep current wiring for the owner's checked sample. The presumed FT drawing error is an owner-reported hardware/document discrepancy; this review did not obtain a manufacturer erratum or independently measure the sample. Record its FPC/revision and check later lots. [FL specification](https://www.good-display.com/companyfile/1946.html), [FT drawing](https://www.good-display.com/companyfile/1997.html).

If a physical part actually follows the conflicting column, PCB pins 1/5 apply boost positive to both cathodes; Q6 or Q5 pulls the selected anode low. The LEDs are **reverse-biased**, not merely color-swapped. With little normal sense current, U10 can boost toward approximately 25 V OVP and latch after three OVP events. LED reverse breakdown/damage can precede that. R37 and the TVS devices do not guarantee safe LED reverse voltage.

### Common-value R37

With TPS923610's 195–206 mV full-scale reference:

| R37 | Nominal mA | Upper mA from reference + initial R tolerance |
|---|---:|---:|
| Current 13.3 Ω, 1% | 15.04 | 15.65 |
| 14.3 Ω, 1% | 13.99 | 14.55 |
| **15 Ω, 1%** | **13.33** | **13.87** |
| 15 Ω, 5% | 13.33 | 14.46 |
| 16 Ω, 1% | 12.50 | 13.01 |
| 18 Ω, 1% | 11.11 | 11.56 |
| 22 Ω, 1% | 9.09 | 9.46 |

**Applied 2026-09-17: R37 = 15 Ω in the source.** 15 Ω is a normal E12/E24 value; a commodity 1% 0603 is sufficient. C22810 / UNI-ROYAL 0603WAF150JT5E is 0.1 W, ±100 ppm/°C, but listed Extended rather than Basic. C128059 / Yageo RC0603FR-0715RL is another candidate. Check current factory availability when substituting. Worst-sign 60°C drift raises the 15 Ω/1% upper estimate to **13.96 mA**; worst resistor dissipation is only about **2.86 mW**. These figures exclude transition spikes and aging. [TI driver](https://www.ti.com/lit/ds/symlink/tps923610.pdf), [C22810](https://jlcpcb.com/partdetail/23537-0603WAF150JT5E/C22810), [C128059](https://www.lcsc.com/product-detail/C128059.html).

### Startup and color changes require deliberate firmware

TPS923610 requires an initial **ADIM high pulse longer than 40 µs** to enable. At 20 kHz/50% duty, each high pulse is only 25 µs: do not assume that starting directly at the desired dimming duty enables the driver. Provide an explicit enable pulse with margin, then apply dimming. Low longer than approximately 2.5 ms shuts it down and resets latched protection. Its internal ADIM pull-down is approximately 600 kΩ; high-impedance reset is not by itself an asserted enable. Firmware that enables an internal GPIO pull-up must be considered separately. [TI timing and dimming sections](https://www.ti.com/lit/ds/symlink/tps923610.pdf).

TI recommends **10–200 kHz** for the ADIM dimming carrier. The current schematic's **10–25 kHz** note is within that range; the old Markdown warning about a sub-10 kHz source note is stale. A low-frequency warm/cool selection signal is a separate control, not a replacement for the ADIM carrier. Shutdown also **does not isolate VOUT from VIN**: L2 and the internal high-side body diode leave a path, so LED_MONIT need not read zero with ADIM low. The exact idle voltage depends on leakage/load and diode current, rather than a guaranteed fixed 0.7 V drop. The target series string's forward voltage exceeds the supply, but arbitrary lower-voltage strings do not inherit that off-state behavior. [TI shutdown and analog-dimming sections](https://www.ti.com/lit/ds/symlink/tps923610.pdf).

ADIM PWM is filtered into an analog current command. **The PWM low interval is not a guaranteed zero-current switching window.** U12 gives opposite static logic levels to Q5/Q6, but propagation delay and gate charge can cause brief overlap or a both-off interval. Thus the old “exactly one string can ever conduct” claim was too strong. The shared resistor controls total steady current; it does not prove harmless transient current sharing.

C9 stores energy at the previous string's forward voltage. Switching to a lower-VF string can produce a discharge pulse before the control loop settles. Setting ADIM low does not instantly discharge that capacitor. Earlier guaranteed 1.25 kHz color blending / 7–15 µs settling guidance was not backed by board waveforms and included an obsolete C9 value. **Begin with fixed warm/cool selection. Qualify blending by measuring each branch current and output voltage** at full and low brightness and the largest string-VF difference. Determine any necessary blanking/dwell/discharge strategy from those results. R49/R50's 1 MΩ bleeders also allow microamp-level bypass current; “off” is not mathematically zero.

**C9 output-cap sizing — applied 2026-09-18, 1 µF → 4.7 µF.** TI's COUT section (§8.2.2.3) recommends 1–4.7 µF and explains the trade-off as output ripple vs. loop stability, not dimming behavior; the reference design and every characterization curve use 1 µF nominal. The populated 1 µF/50 V/0805/X7R part is a nameplate value — MLCC DC-bias derating at the actual 15–24 V LED-rail bias is typically 25–40 % for this dielectric/case/voltage combination, putting its *effective* capacitance around 0.6–0.8 µF, below TI's own stated 1 µF minimum. C9 is now **4.7 µF/50 V/0805** — Samsung `CL21A475KBQNNNE` (prime) / Samwha `CS2012X5R475K500NRE`, LCSC `C513770` (the same part as C11/C13–C17, so no new line item), still inside TI's 1–4.7 µF window. A 4.7 µF X5R 0805 at 50 V is estimated to keep roughly 1.0–1.8 µF at 24 V and 1.5–2.5 µF at 15 V (vendor DC-bias curves were not retrievable — confirm with Samsung SimSurfing), so it meets the 1 µF minimum but only narrowly at the highest string voltage.

*Does this reintroduce dimming flicker?* No — TPS923610's only dimming mode chops the **internal 200 mV reference**, which is low-pass filtered *before* it reaches the GM error amplifier driving the current loop (§7.3.8): "although a PWM signal is used for brightness dimming, only the LED DC current is modulated." There is no PWM-frequency current edge at the LED string for COUT to smear, so the larger C9 should be neutral-to-beneficial for ADIM-based dimming. TI does not publish a COUT-vs-settling-time curve, so this is architectural reasoning from the datasheet's control-loop description, not a bench number.

*Effect on the colour-blend re-slew time above:* `t ≈ C9 × ΔV_f / I_LED` uses the same capacitor for a different purpose (string-to-string transition, not PWM dimming). With derating the effective value is roughly 1–2 µF, so a 1 V string difference at 13.3 mA settles in ≈100–150 µs (up to ≈350 µs at the full nameplate) versus ≈75 µs with 1 µF — almost certainly imperceptible for a colour-temperature blend, but blending is unqualified by board waveforms, so check it at the populated value. **Also check on the bench:** at battery hot-plug the L2→body-diode→C9 path charges the larger capacitor and can ring briefly to roughly 2.5 A (about 1.3 A with 1 µF) — confirm L2's (`VLS252012HBX-100M-1`) saturation margin or accept a brief saturation.

### Inductor, protection and layout

*(Historical: the 2026-09-14 matched order carried TDK VLS252010HBX-4R7M-1 / C88528. L2 is now 10 µH, TDK VLS252012HBX-100M-1 / C88532 in the schematic and the upload BOMs — §12.)* The 4.7 µH analysis below applies to the earlier value. TDK's HBX is 4.7 µH with 1.4 A inductance-drop and 1.09 A temperature-rise current ratings, reasonable for this low-power normal load. The small-load converter can operate discontinuously, so a simple average-current plus half-ripple estimate is **not a guaranteed peak**. Startup, minimum inductance and fault current must be checked; U10's maximum current limit exceeds the inductor's rating. [TDK characteristics](https://product.tdk.com/en/search/inductor/inductor/smd/info?part_no=VLS252010HBX-4R7M-1).

TPS923610 has **25 V typical OVP**, not the 30.5 V threshold of another family variant; the 24.25–25.5 V specified range has a TJ ≤85°C condition. C9's 50 V rating is retained. D3 SMAJ26A's approximately 42.1 V surge clamp is not a guarantee of U10 absolute-maximum protection. The normal open-load response is internal OVP. D8's actual 24 V bidirectional array pinout is now verified.

The LED layout is a strength: **TPS_SW_NODE = 2.49 mm, zero vias**; U10 VOUT to C9+ **1.91 mm**, GND to C9− **2.31 mm**, VIN to C12+ **3.29 mm**, FB to R37 **1.62 mm** pad-center distances. U12 to C24+ is 1.81 mm. The much longer `LED_SW` route is boosted **DC output**, despite its name, not the transistor switching node. R37's single effective ground spoke deserves attention during waveform testing, but the local boost geometry does not justify a blanket reroute.

## 9. Analog status, buttons and sleep

All five analog functions use ADC1-capable pins. Calculations below assume exactly 3.3 V and ideal zero-volt status assertions; they are **not calibrated firmware thresholds**.

| USB_STAT condition | Nominal V |
|---|---:|
| Battery selected, neither charger status asserted | 1.980 |
| USB selected, charging | 1.185 |
| USB selected, charged | 0.595 |
| USB selected, neither charger status asserted | 3.300 |
| Battery selected while charger asserts CHRG | 0.956 |
| Battery selected while charger asserts STDBY | 0.531 |

The last two are degraded-source/transition cases, not normal healthy-5 V operation. ST indicates mux status; it is not proof of physical USB absence, and low also covers disabled/thermal states. CHRG and STDBY simultaneously low is not a normal steady charger state. The 0.531/0.595 V pair is too close to promise separation after ADC, output-low, leakage and rail errors. Merge uncertain cases into a degraded/unknown band and debounce. Do not invent an exact no-battery oscillation voltage from the ideal ladder.

The idle 3.3 V input can saturate the ESP32-S3 calibrated ADC range. Firmware should recognize a calibrated upper band/top-coded reading; a hard requirement to measure **more than 3.10 V** can misclassify idle. Verify thresholds on the real device and over source voltage. [ESP32-S3 electrical characteristics](https://www.espressif.com/sites/default/files/documentation/esp32-s3_datasheet_en.pdf).

The battery-only ideal assumes U11's inactive CHRG/STDBY outputs do not materially load the ladder when its VCC is zero. The exact charger sheet does not provide a sufficient unpowered-pin leakage specification to bound this calculation. Measure the unplugged state and any back-power/leakage on the actual lot; a generic open-drain label is not a quantitative guarantee. C23 is **2.2 nF**, giving an ideal battery-state RC of about **132 µs**; subsequent software debounce and USB-disconnect timing must be chosen deliberately.

- **BAT_MONIT:** P+/2 through 1 MΩ/1 MΩ, approximately 0.5 s RC. It includes battery-path drop and high source impedance; calibrate leakage/ADC errors. It is not direct Kelvin cell measurement or a fast brownout detector.
- **LED_MONIT:** 120 kΩ/(1 MΩ+120 kΩ) = 0.10714 ratio, approximately 10.7 ms RC. Useful monitoring, not fast overvoltage protection.
- **BUTTON_ADC_1:** single-key ideals 0.033 / 1.185 / 2.200 / 2.800 V.
- **BUTTON_ADC_2:** 0.033 / 1.800 / 2.533 / 2.877 V. ±1% resistor and assumed ±1.5% regulated-rail corners remain separate, before ADC/contact errors. Below regulation the rail dependence must be considered.
- Multiple keys form parallel combinations and may alias other keys. Define supported combinations; this is not an independently readable eight-bit keypad. Two chords fall inside single-key tolerance and cannot be separated by the ADC alone: ladder 1 `SW3`+`SW9` ≈ 1.11 V (worst case 1.09–1.14 V) vs `SW3` alone 1.16–1.21 V, a gap under the ESP32-S3 ADC's ±50 mV error; ladder 2 `SW4`+`SW7` ≈ 1.67 V vs `SW4` 1.77–1.84 V. Firmware should reject any reading that is not close to one of the six clean levels of its ladder. *(Added 2026-09-18.)*
- **SW10:** R62/R76 yield approximately 3.0 V pressed; GPIO18 supports RTC-domain wake. The analog ladders do not provide reliable per-key digital wake for every voltage — specifically only `SW2` (RIGHT) and `SW1` (DOWN(1)), at ≈33 mV, give a valid logic low on IO1/IO4 (idle is 3.3 V); `SW3` LEFT at 1.19 V (≈0.36·VDD), `SW4` UP(1) at 1.80 V (≈0.55·VDD) and `SW8` OK at 2.20 V (≈0.67·VDD) are in the undefined band (valid low ≤ 0.25·VDD = 0.825 V, valid high ≥ 0.75·VDD = 2.475 V; ESP32-S3 datasheet v2.2, Table 5-4, 3.3 V / 25 °C), so `ext0`/`ext1`/light-sleep GPIO wake is not guaranteed for LEFT, UP(1) or OK; `SW5` DOWN(2), `SW9` BACK and `SW7` UP(2) (≈0.77 / 0.85 / 0.87·VDD) read as logic high, so it cannot fire for them (DOWN(2) only ≈46 mV clear at ±1% worst case). *(Quantified 2026-09-18; thresholds corrected 2026-09-30.)* Use the dedicated wake button or a deliberately implemented low-power ADC strategy.
- R36/R73 are fitted for normal SW7; R72/R74 are DNP. **Fitting both R73 and R74 shorts the rails through the alternate link arrangement.** Preserve the population policy.

Bottom switch anchors are spaced **12 / 13 / 12 mm**. Their common actuator offset preserves mirror symmetry; no remaining asymmetric placement defect was found. TS365ZJ's 5 mm signal pitch, 7 mm bracket pitch and 2.5 mm row spacing agree with the holes (1.0 mm signal, 1.3 mm bracket). Enclosure actuator/height tolerances still require physical fit.

## 10. Touch, RTC, expansion and exact substitute pinouts

### Touch and I²C

Default J4 pins are **GND, 3V3, RST, INT, SDA, SCL**. R42/R44/R46/R52 are fitted; R43/R45/R58/R66 stay DNP. These are mutually exclusive wiring options, not spare jumpers to fit together. Confirm an alternate panel's entire mapping before changing them.

GPIO41 carries external TP_INT. It is **not an RTC-domain GPIO**, so it cannot provide ordinary EXT0/EXT1 deep-sleep wake on ESP32-S3. Light-sleep GPIO wake is a separate option. Do not confuse an external I²C touch-controller interrupt with the ESP32's internal touch wake hardware. If deep-sleep wake from panel touch is required, revise the pin assignment or architecture. [Espressif sleep modes](https://docs.espressif.com/projects/esp-idf/en/stable/esp32s3/api-reference/system/sleep_modes.html).

There is no explicit discrete TP_INT pull-up here. If the actual touch controller uses an open-drain interrupt, verify its module pull-up or configure a suitable MCU pull-up and sleep behavior. This is controller-dependent, not evidence that every touch module will fail.

The I²C 2.2 kΩ pull-ups require about **1.32 mA** sink current at VOL = 0.4 V. A simple RC estimate gives about **161 pF** for a 300 ns rise-time target. Panel FFC, header accessories and their parallel pull-ups change the load. Measure at 400 kHz; use 100 kHz if necessary. GPIO assignments and series links are otherwise coherent.

### RTC

U13 **DS3231MZ was DNP in the 2026-09-14 saved order and is fitted in the standard build** (C107410). Its VCC-grounded, VBAT-to-3V3 operation is explicitly supported by the manufacturer. A valid I²C address access starts the initially inhibited oscillator in this mode; firmware must initialize and inspect status/OSF rather than assume valid time at first power-up. RST is unconnected, as appropriate for this mode; INT/SQW is also unconnected. Thus it provides **no RTC interrupt wake**, and there is **no independent time backup** if 3V3 disappears. Accuracy is **±5 ppm**, approximately 2.6 minutes/year, not ±2 ppm. Its decoupler is **C30 = 0.1 µF**, not C22. [DS3231M, including Figure 5](https://www.analog.com/media/en/technical-documentation/data-sheets/DS3231M.pdf).

### Expansion and ESD replacements

J6 is not a generic low-voltage GPIO header. Its pins include LED_SW, switched LED cathodes and P+ beside logic. External supply injection can back-power rails; there is no general accessory power isolation. GPIO3/45/46 require boot-strap care. The full pin table is in [HARDWARE.md](docs/HARDWARE.md).

The previous review's unresolved exact-vendor pin drawings are now **closed**:

| Ordered component | Verified manufacturer drawing | Result |
|---|---|---|
| TECH PUBLIC TPD4E1U06DBVR, C19829453, U1/U6/U7/U8/U9 | Signal pins **1/3/4/6**, GND **2**, NC **5**; independent shunt channels | Current PCB assignments compatible; not pass-through pairs |
| MDD 74LVC1G04GV, C53185133, U12 | NC **1**, A **2**, GND **3**, Y **4**, VCC **5** | Pinout and inversion role compatible at 3.3 V |
| TECH PUBLIC PESD2IVN-UX, C42370512, D8 | Signals **1/2**, common **3**; 24 V bidirectional protection | Current cathode-to-ground use compatible |

The TECH PUBLIC TPD sheet specifies 5.5 V standoff and a substantially higher transient clamp; it is not a precision 3.3 V limiter. Pin compatibility does not establish identical dynamic clamp, lifetime or system ESD qualification to TI/Nexperia parts. Sources and retrieved PDF hashes are in [complete-review-sources.json](docs/audit-2026-09-16/complete-review-sources.json): [TPD array](https://jlcpcb.com/partdetail/TECHPUBLIC-TPD4E1U06DBVR/C19829453), [MDD inverter](https://jlcpcb.com/partdetail/MDD_MicrodiodeSemiconductor-74LVC1G04GV/C53185133), [24 V array](https://jlcpcb.com/partdetail/TECHPUBLIC-PESD2IVNUX/C42370512).

## 11. Remaining critical layout and fabrication checks

### USB: small real skew, imperfect return path

Branch-inclusive net totals of 45.38/42.17 mm are **not** the differential connector-to-MCU skew. A pad/track/via graph gives these approximate centerline paths:

| Path | Length | Main-path vias |
|---|---:|---:|
| J1 A6 → U4 D+ | 33.061 mm | 2 |
| J1 A7 → U4 D− | 33.718 mm | 0 |
| J1 B6 → U4 D+ | 34.763 mm | 2 |
| J1 B7 → U4 D− | 35.420 mm | 0 |

Either orientation has approximately **0.657 mm mismatch**. That is not a compelling 12 Mbps USB failure argument. The real layout qualifications are return continuity, unequal layer transitions and the branched ESD routing. Some ESD routes extend about 8 mm toward U6 rather than providing a direct connector-to-protection-to-PHY sequence. Ground gaps near X76/Y92 and X81/Y97 interrupt the opposite-layer reference. Perpendicular crossings reduce coupling but do not restore a missing return plane.

Opposite-layer ground-zone projection covers about 64%/71% of branch-inclusive DP/DN geometry. This deliberately excludes ground tracks/pads and same-layer ground, so it is **not a measured impedance, a quality score or proof of failure**. The source lacks optional USB series-damping footprints recommended in Espressif's guidance. Test both orientations, representative cables/hosts and sustained traffic; improve flow-through ESD/return geometry on a revision if needed. [Espressif checklist](https://docs.espressif.com/projects/esp-hardware-design-guidelines/en/latest/esp32s3/schematic-checklist.html).

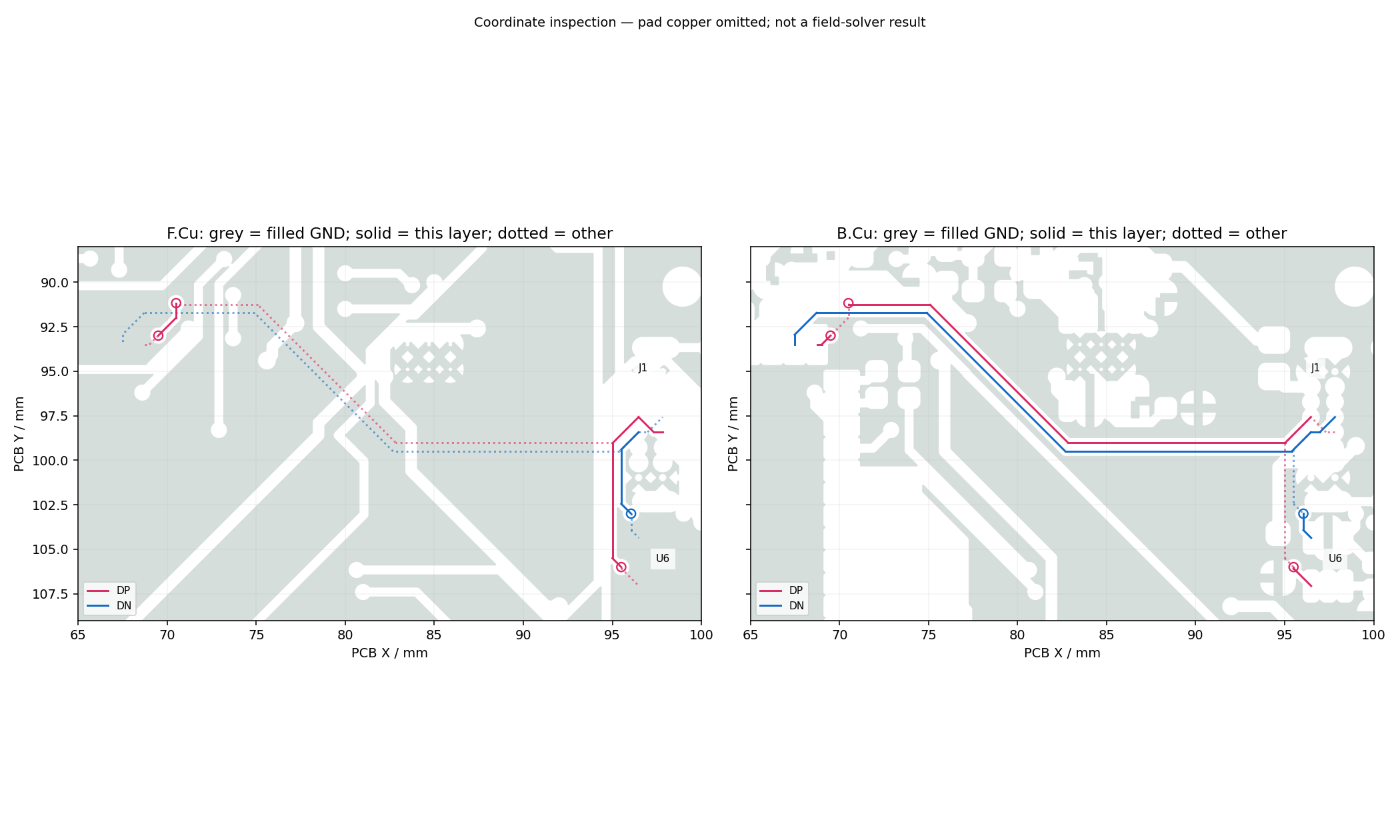
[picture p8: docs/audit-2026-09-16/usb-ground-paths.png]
USB routes over opposite-layer ground


### Power, ground, RF and mechanics

- **U3 local capacitors:** VIN–C4+ 2.88 mm, OUT–C6+ 2.27 mm, OUT–C21+ 2.75 mm. Good local placement; more bulk elsewhere is not an automatic substitute for thermal/current qualification.
- **Ground connections:** U3, U2, Q1 and R37 have only one effective thermal spoke at some pads. They are connected, but these are priority locations for low-impedance return and heat-spreading improvements. The board has 48 GND vias; total via count alone does not prove a local return is good.
- **Charger:** BAT–C3+ 2.35 mm and exposed-pad thermal vias are useful. VCC–C2+ is about 9.16 mm; a closer small input bypass is a reasonable next-revision improvement, not by itself a demonstrated charger failure.
- **DW01A:** VCC–C7+ 4.66 mm, ground–C7− 2.17 mm. Improve filtering/sense placement as part of the battery redesign.
- **SD supply:** J7 VDD–C37+ 3.63 mm and –C36+ 2.11 mm. Local decoupling is present. Remote U9 branches need functional qualification, not an assertion that DAT0/1 are unprotected.
- **Trace widths:** common 0.25 mm power / 0.20 mm logic-switch routes are not automatically inadequate at the intended low power. Measure the complete path's drop and heating, including pads, spokes, vias, fuse and battery devices. A copper pour added in an unused area does not necessarily improve the dominant bottleneck.
- **Battery-path trace width — applied 2026-09-18.** `B+`, `B−` and `P+` were 0.20–0.25 mm through a 0603 zero-ohm jumper; the owner widened them to 0.4 mm (all `B+`/`B−` segments and 77 of 78 `P+` segments; one short `P+` stub stays 0.25 mm) and changed the series jumper `R27` from 0603 to **0805** (`C17477` UNI-ROYAL 0805W8F0000T5E, Basic; prime part Yageo RC0805JR-070RL). That roughly doubles the copper cross-section and the jumper's current capability, so the earlier fault-heating concern under the DW01A trip window is largely closed; `R27` remains a finite-rating part — check drop and temperature in the first-article load test.
- **Antenna:** the physical board cutout exists. No missing cutout finding remains. Check panel/battery/housing/metal placement and RF performance in the final stack. [Espressif layout guidance](https://docs.espressif.com/projects/esp-hardware-design-guidelines/en/latest/esp32s3/pcb-layout-design.html).
- **Mounting:** H1–H6 pads connect to GND. Metal standoffs/housing can therefore make electrical chassis connections; include them in final-stack RF/EMC and clearance checks.
- **Models are illustrative:** MJTP models versus ordered TS365ZJ, and the custom SD socket need drawing-based fit checks. A plausible 3D render is not tolerance approval. (The original "Bourns-named L1 footprint versus TDK" note is moot — L1's footprint changed entirely 2026-09-18, see §7/§12.)

### DRC and ERC disposition

The retained DRC JSON contains **87 entries: 14 clearance, 24 thermal-spoke, 49 silk-related**. Clearance entries are largely repeated/excluded reports of J1's native 0.15 mm gaps versus a 0.20 mm Power rule, and J3's 0.20 mm gaps versus a 0.25 mm SW rule. These do not mean the footprints are shorted. Existing exclusions/cosmetic reports are not the release hold.

The ERC CLI count is 83 while its JSON has 37 visible warning entries and no error entries; these outputs include bookkeeping/exclusions and are not 83 independent confirmed design faults. Some project checks, including footprint/library comparisons and mask bridges, are ignored. Thus “0 unconnected” establishes useful connectivity evidence, not mechanical fit, thermal adequacy or full mask manufacturability.

## 12. Source, order and old-document contradictions

This table is the remaining reconciliation list. Circuit/order files were deliberately preserved during review.

| Item | Reviewed truth / required follow-up |
|---|---|
| Battery protection language | Unconditional bare-cell/reverse-insertion claims removed; §4 "Fix 4" (CE gated by a B−-referenced detector) is applied and netlist-confirmed — remaining step is the §13 bench verification. |
| Q4 / R37 | **Applied:** source now IRLML6346TRPBF (C67276) and 15 Ω. The factory BOM must carry C67276. |
| D2 | **Accepted:** C28310439 (normal-emitting). Update the upload BOM. Indicator is USB-present, ≈1.3–1.6 mA with R59. |
| L2 | **Decided 2026-09-17: 4.7 µH → 10 µH, TDK VLS252012HBX-100M-1 `C88532`** (same 2520 land, 1.2 mm). The TPS923610 runs forced-continuous at 1.1 MHz at every load and TI characterizes it only with 10 µH / 1 µF; with 4.7 µH the 0.6 A p-p ripple dominates losses. Model with TDK's measured Rac: ≈6–7 mA less battery current at every brightness (−10 % at full, −25…35 % dimmed), a third less output ripple, no flicker either way (analog dimming). Details and bench check in `fabrication/BOM.md`. **Applied — the schematic reads 10u / VLS252012HBX-100M-1 / C88532.** Fallback if 4.7 µH is kept: HBX-4R7M-1 `C88528` (as built on both earlier orders), not HBU. |
| L1 | **Applied 2026-09-18: 22 µH → 47 µH, Laird `TYS5040470M-10`** (prime/DigiKey) / **Sunltech `SLW5040S470MST` `C206267`** (JLC), both 5.0×5.0×4.0 mm, both shielded. Matches the SSD1677 reference design's inductor value (§7). **Footprint change, not a drop-in** — land grows from 3.0×3.0 mm; `Inductor_SMD:L_APV_ANR5040` applied (pad gap checked against Bourns' published land pattern, a close match). The neighbours (C10, R63, Q4, D5) were moved to clear the new footprint and the EINK_SW/GDR/RESE lengths were re-measured on 2026-09-18 (§7); schematic and PCB fields match. |
| R14 | **Applied 2026-09-18: 3 Ω → 2.2 Ω, Yageo `RC0603FR-072R2L`** (JLC code `C22939` since 2026-09-20; was `C112307`) — same 0603 1% series/price as the prior part. Matches the SSD1677 reference design's sense resistor now that L1 (above) is also at the reference value. Modeled safe against every component rating; **not bench-verified** — see §7. |
| R84 | **Added 2026-10-01 (Rev 1.01): 1 Ω, Yageo `RC0603FR-071RL`** (prime/DigiKey) / UNI-ROYAL `0603WAF100KT5E` `C22936` (JLC Basic, no loading fee), in series with C2's ground leg as the USB hot-plug damper — see §3. Footprint `R_0603_1608Metric_Pad0.98x0.95mm_HandSolder` like the other 0603 resistors; B.Cu (80.1, 92.2), rotation 180. One of the five x3 GND stitching vias moved from (80.5, 92.3) to (80.075, 92.36) to make room; it is still below the cut, and the y 62 trim check still shows 0 unconnected. |
| CR1 | **Decided 2026-09-17: SMF6.5CA in SOD-123FL** (prime: Littelfuse SMF6.5CA; JLC: hongjiacheng `C19077501`, Preferred, 1.75 M stock). The SMFxx ladder is standardized, so official and clone parts share the spec: 6.5 V standoff, V_BR 7.22–7.98 V, ≤11.2 V clamp @ 17.9 A (10/1000 µs), bidirectional — 1 V clear of USB-C's 5.5 V maximum, unlike "05"-named parts whose clones are 5.0 V / V_BR ≥ 6 V. Closes the §3 VBUS standoff finding. **Applied — CR1's footprint is `Diode_SMD:D_SMF`** (fits in place). CR2/CR3 (3V3, P+ ≤ 4.2 V) stay on the SOD-323 5.0 V part. |
| U13 / SW6 | **Standard-build policy (2026-09-17):** U13 (DS3231MZ+TRL, `C107410` — the reel listing; the earlier cut-tape `C722467` is superseded) is populated; SW6 (APEM MJTP1243 boot button) is DNP. The source DNP set is exactly TP3/TP4/TP5, R43/R45/R58/R66/R72/R74 and SW6 — ten references (eleven since 2026-09-21, when the alternate RTC `U14` was added as DNP), flagged DNP in both schematic and board so the Toolkit CPL agrees. Upload BOM: `production/jlc_bom.csv` (named `bom_JLC_upload_v4_optimized.csv` until 2026-09-21; updated 2026-09-18 for L1/R14/C9; the brand-conservative v3 file has been deleted) — see `fabrication/BOM.md` for the swap rationale and cost model. |
| DNP links | Preserve R43/R45/R58/R66/R72/R74. Do not populate mutually exclusive links together. |
| TP4056 note | ≈0.25 A intended; R6 = 4.7 kΩ kept for the first batch (10 kΩ if U3 runs hot, §3). Exact 255 mA and exact 4.0 V on/off statements remain unsupported for the ordered lot. |
| USB_STAT annotations | Do not require an ADC reading >3.10 V for idle, guarantee close degraded-state separation, or assign an exact no-battery oscillation voltage. |
| LED control text | Actual net is PWM_LED, not obsolete LED_ACTIVATE. Include >40 µs enable and real color-transition qualification. |
| ADIM carrier / off voltage | Use TI's 10–200 kHz recommendation; shutdown leaves an input-to-output diode path, so LED_MONIT off is not zero. |
| Frontlight behavior | Remove “both strings can never conduct,” instantaneous PWM blanking and unmeasured fixed-frequency/settling guarantees. |
| FT01C drawing | Owner's sample matches source; retain conflicting drawing and reverse-bias failure warning for later lots. |
| Capacitor descriptions | C22 is near the panel, not MCU-local or RTC decoupling; RTC decoupler is C30. **C9 = 4.7 µF/50 V (applied 2026-09-18; was 1 µF)** — the 1 µF part derated below TI's recommended COUT minimum at the 15–24 V LED rail bias; the trade-off with the colour-blend re-slew time is in §8. |
| SD GPIO table | GPIO6 DAT0 is through **R25**; GPIO7 CLK through **R24**. Earlier documentation swapped those references. |
| SD mechanics/library | **Resolved:** 1.50 mm-tall NPTH slots in library and board, owner-confirmed against both 3D models; GCT keepout marked (vias inside it matter only for a GCT hand build). Downloads model path and original Würth datasheet link are stale. |
| RTC | ±5 ppm, fitted in the standard build, documented VBAT-only operation; no independent backup or interrupt wake. |
| Touch wake | GPIO41 is not an ordinary deep-sleep RTC wake input. |
| Substitute metadata | Schematic names/links often describe TI, Onsemi or unrelated MOSFETs; retain actual TECH PUBLIC/MDD/PUOLOP/TOPPOWER manufacturer sheets with the frozen order. Exact ESD/inverter pinout uncertainty is now closed. |
| Assembly counts | 179 references = **162 fitted + 10 DNP + 7 bare-copper** (H1–H5, TP1, TP2) on 2026-09-18 — **as of 2026-09-21 it is 184 = 165 fitted + 11 DNP + 8 bare-copper** (H1–H6, TP1, TP2; `U14`, `F2`, `C34`, `R83` and `H6` were added) — **and as of 2026-10-01 (Rev 1.01) it is 185 = 166 fitted + 11 DNP + 8 bare-copper** (`R84` added); the 2026-09-16 audit counted 173 = 155 + 8 + 10, and older “163 placed” sourcing totals are historical. |
| JLC placement (CPL) | **Corrected 2026-10-01 (Rev 1.01).** Seven `production/positions.csv` rows were wrong against JLC's own library footprints (the owner believes JLC corrected them by hand in the Rev 1.0 order preview). Fabrication Toolkit fields on the schematic symbols and footprints now produce the corrected rows on every run: "FT Rotation Offset" U2 `-90`, U5 `90`, D2 `180`, D8 `180`; "FT Position Offset" J7 `1.6,-5.3`, J4 `-0.73,0.218`, U4 `0,-3.664`. Rows changed: D2 270 → 90 (JLC pin 1 = anode), D8 0 → 180, U2 270 → 180, U5 0 → 90, J4 (92.5, −126) → (93.23, −125.782), J7 (63.05, −84.6) → (64.65, −79.3), U4 x 57.5 → 61.164. JLC's "Confirm Parts Placement" option remains the order-time check. |
| Project compatibility claims | A 24-pin connector is not permission to attach any panel; cell voltage/chemistry, polarity, pinout and firmware support remain constrained. |

All explicitly 50 V capacitors were retained in the matched order. No unexplained passive omission or nominal-value downgrade was found. Pricing/sourcing tables under `fabrication` are historical references, **not the current release BOM or proof of accepted JLC substitutions**.
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

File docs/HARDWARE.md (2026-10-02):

# Silkscreen — Hardware Design Documentation

**An open-source, open-hardware e-reader base board.**
Display agnostic · case agnostic · firmware agnostic · battery agnostic.

Successor to [de-link](https://de-link.me).

---

> ### ⚠️ About this document
>
> **This documentation was written *after* the board was designed. It was not used to design it.**
>
> Silkscreen was designed by its author working from datasheets, reference designs and
> hands-on iteration. This document is a **post-hoc explanation and review aid**, produced
> by tracing the finished schematic net-by-net and checking each block against the
> manufacturers' datasheets. Its purpose is to (a) make the board understandable to
> newcomers, and (b) support review and incremental tweaking — whether you are building it,
> modifying it, or writing firmware for it.
>
> Nothing here should be read as "the design rationale that produced the board." Where this
> document explains *why* something is the way it is, that is a reconstruction — informed by
> the designer's own schematic annotations and by what the circuit demonstrably does, but a
> reconstruction nonetheless.
>
> **Open issues, component qualification, proposed changes and the assembly decision live in a
> separate document: [`DESIGN_REVIEW.md`](../DESIGN_REVIEW.md).** This file describes the board
> *as it is* and flags — inline, where it matters for understanding or firmware — the places
> where the review found something that needs attention (reverse-battery path, the `Q4`
> switching device, the microSD socket fit, frontlight current margin). It does not repeat the
> review's analysis; it points to it.
>
> Connection facts were re-checked against the KiCad netlist on **2026-09-21**; designed in
> **KiCad 9.0.6**. The ordered module is **ESP32-S3-WROOM-1-N16R8**.
> 185 references, 135 nets (with `R84`, added 2026-10-01), single A2 sheet.
>
> **Rev 1.01.** The revision label is on both title blocks and in the name of the release zip. Rev 1.0 is what was ordered on 2026-09-21 (commit `aeb5b39`). Rev 1.01 (2026-09-30) adds a 3V3 link and ground stitching vias below the cut line (see the cut-line row in [§16](#16-design-notes--conventions)) and changes one word of the front silkscreen. On 2026-10-01 it gained one part, `R84` (1 Ω in series with `C2`'s ground leg, a USB hot-plug damper — [§3.1](#31-usb-c-input--protection)), and corrected JLC placement rows for seven parts (`D2`, `D8`, `U2`, `U5`, `J4`, `J7`, `U4`), now set by Fabrication Toolkit offset fields. Until Rev 1.01 is fabricated, further changes are folded into it; the title-block date (2026-09-30) is when it was opened.
>
> **Current full plots (2026-10-01):** [`silkscreen_pcb_schematic.pdf`](silkscreen_pcb_schematic.pdf)
> (schematic, one A2 sheet) and [`silkscreen_pcb_layout.pdf`](silkscreen_pcb_layout.pdf) (PCB layout: front view, then the back as you see it) are
> plotted from the current source. The per-block images in `images/` were cropped from the 2026-09-21 schematic plot; the only
> circuit change since is `R84`, which the charger crop (§3.2) and the full-sheet image (§2) do not show. If a block ever looks out of date, re-crop it from
> the PDF rather than trusting the picture.

---
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

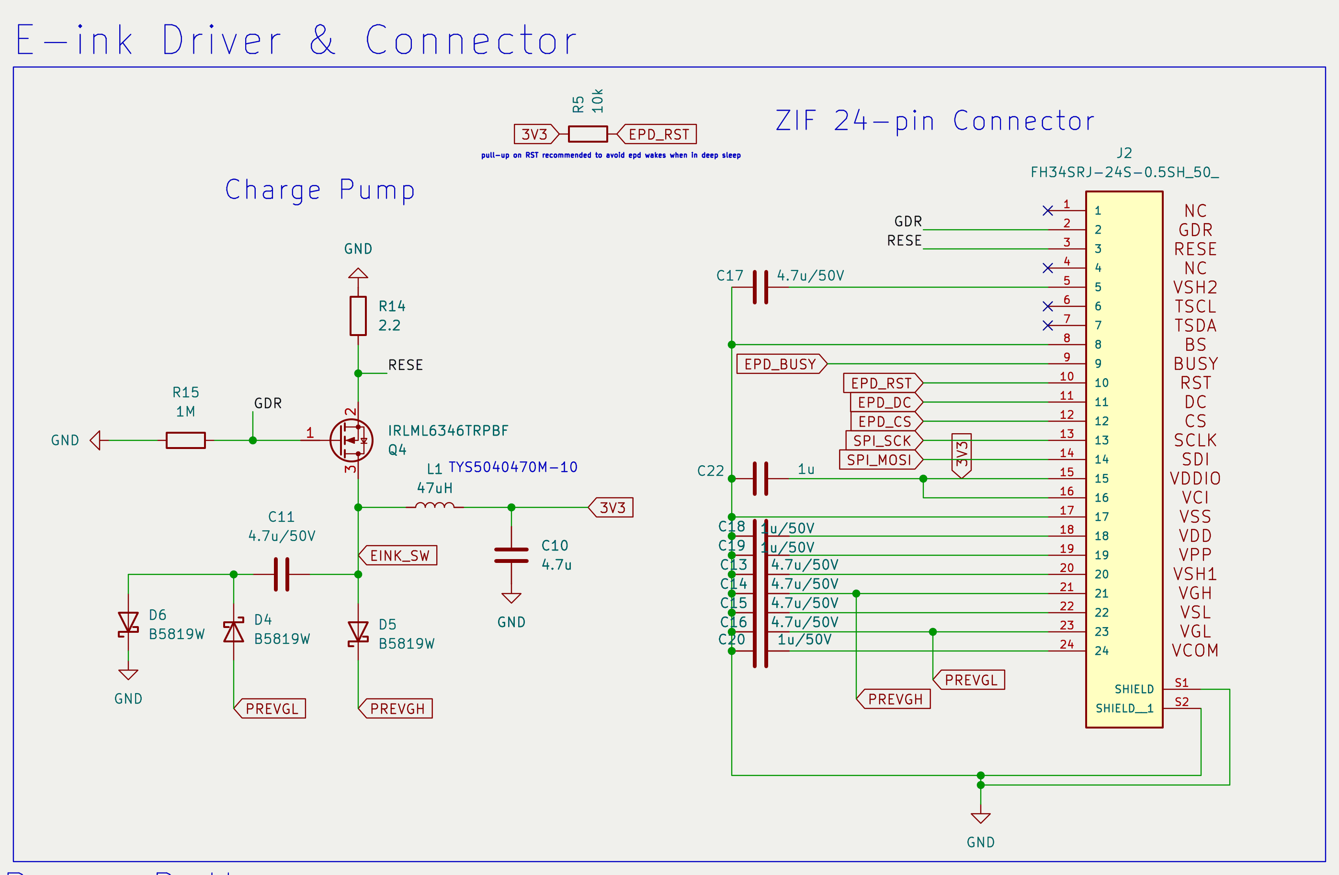
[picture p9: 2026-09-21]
docs/images/09-epaper.png

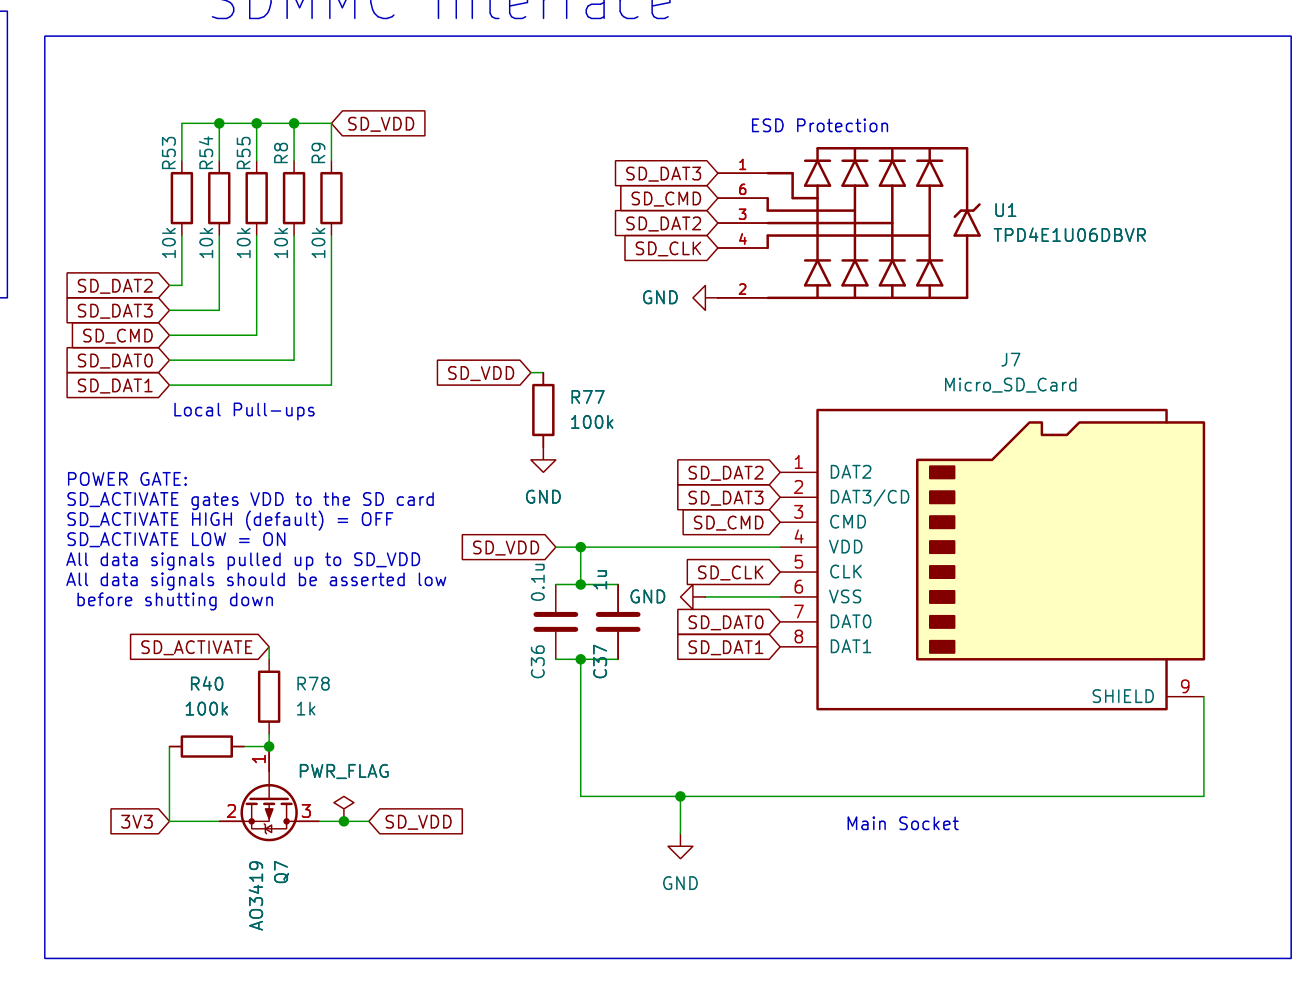
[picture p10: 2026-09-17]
docs/audit-2026-09-16/sd-schematic.png

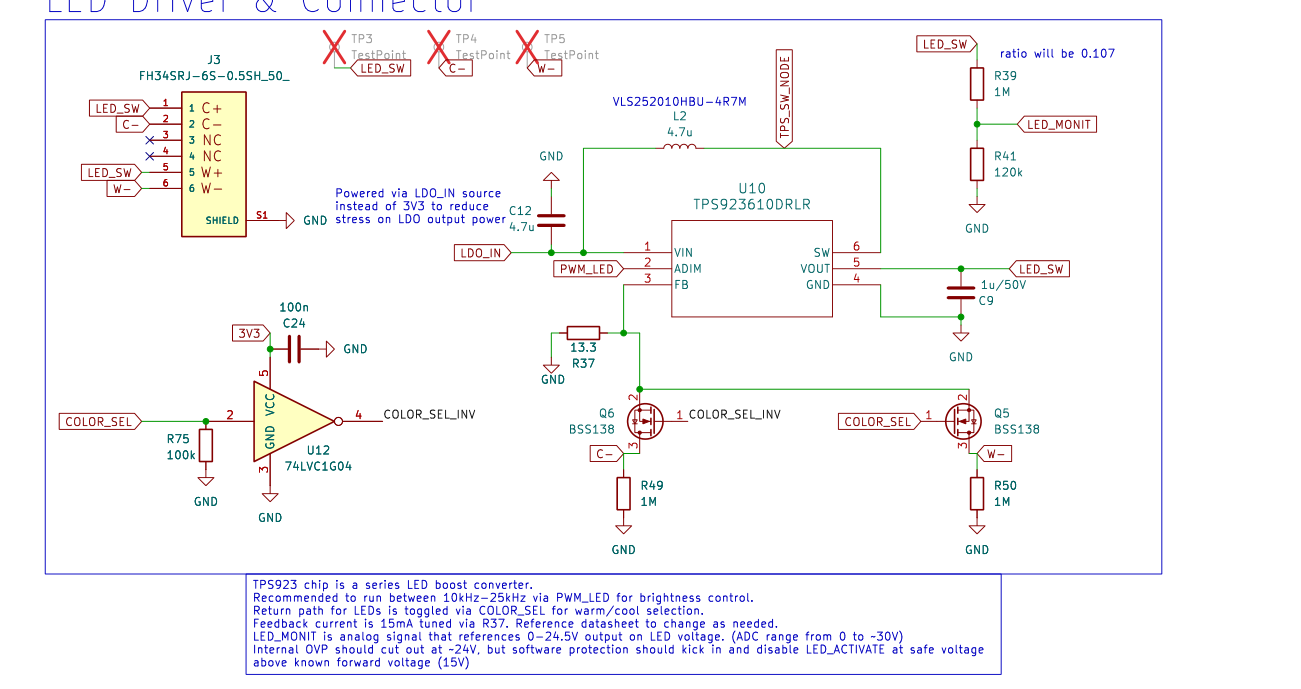
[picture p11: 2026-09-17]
docs/audit-2026-09-16/led-schematic.png

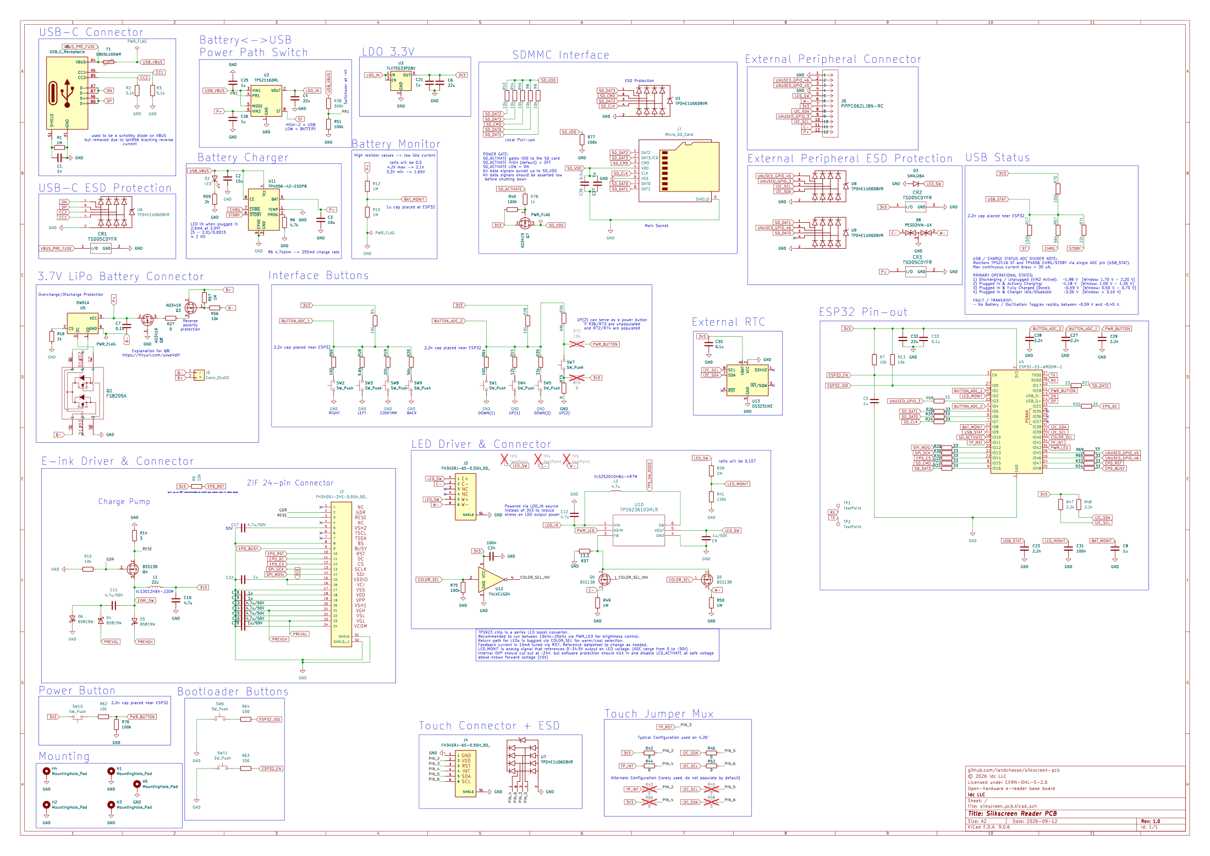
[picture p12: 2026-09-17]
docs/audit-2026-09-16/silkscreen_pcb_schematic.pdf-1.png

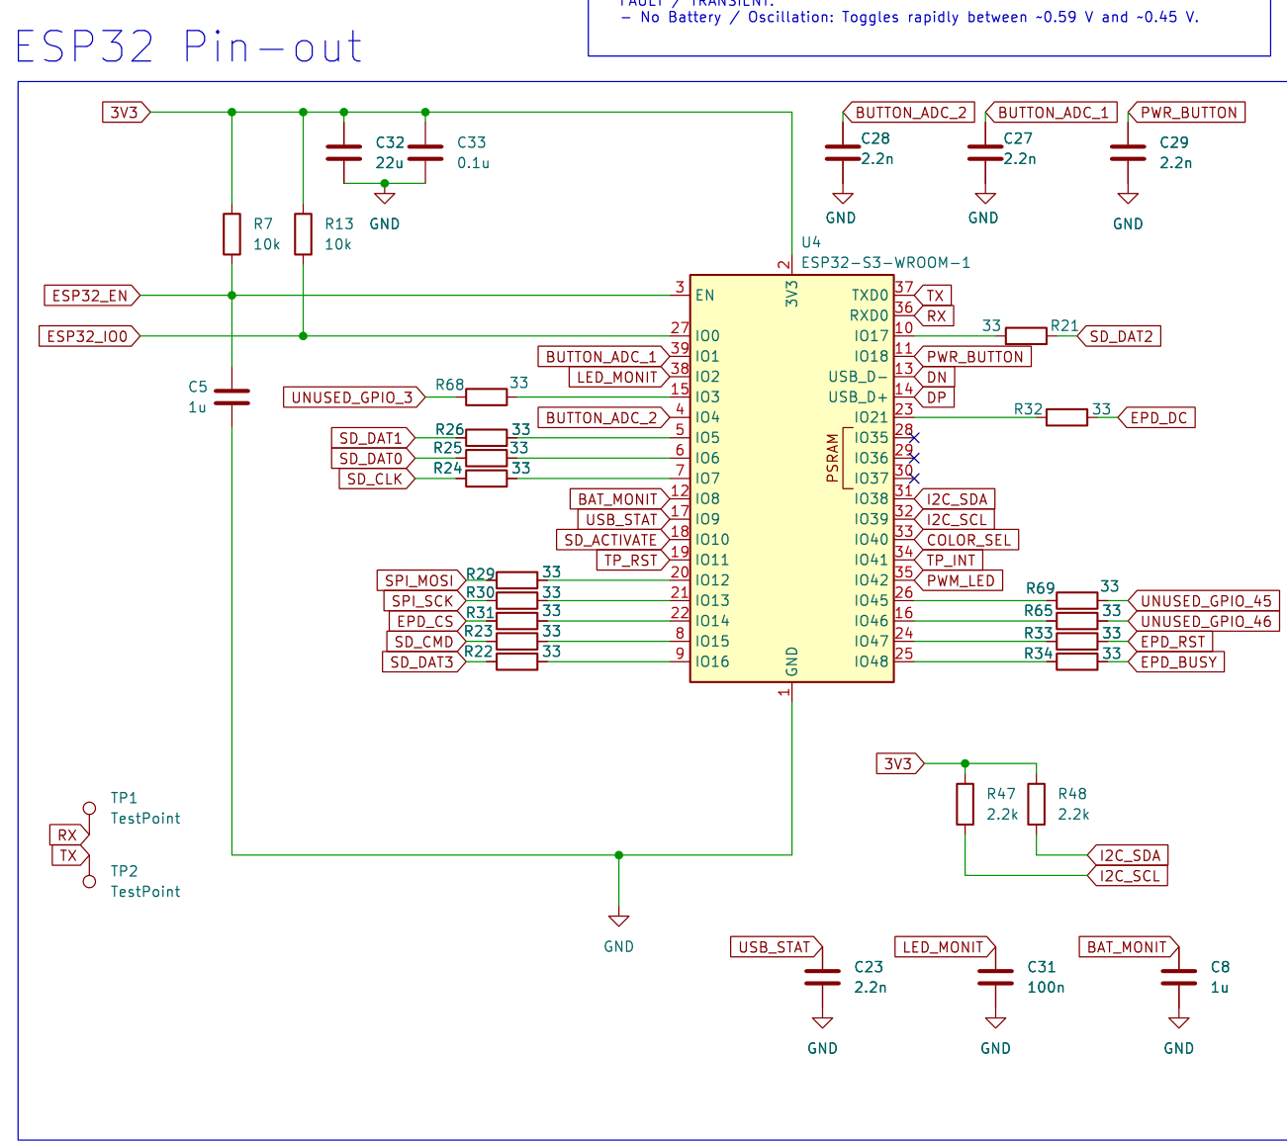
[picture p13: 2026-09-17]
docs/audit-2026-09-16/processor-schematic.png

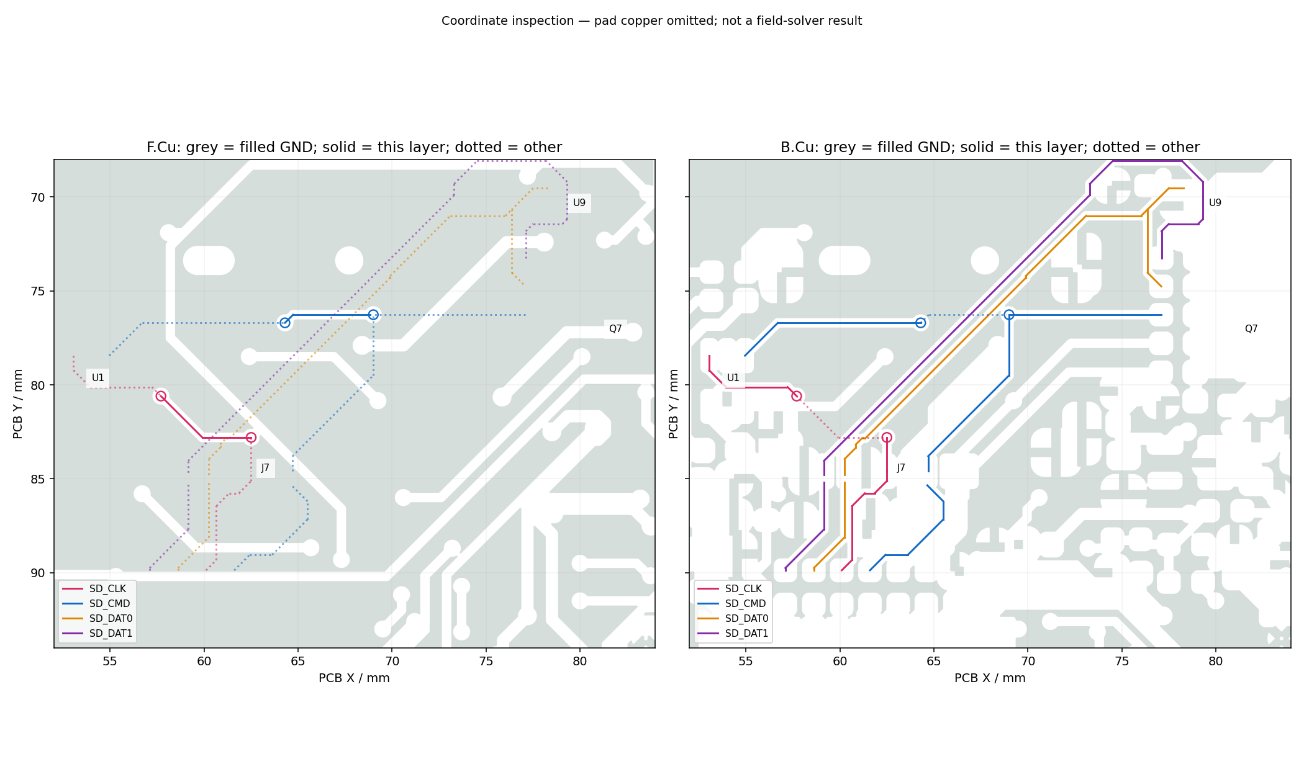
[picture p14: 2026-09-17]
docs/audit-2026-09-16/sd-ground-paths.png

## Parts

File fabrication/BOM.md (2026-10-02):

# Silkscreen — bills of materials

Two BOMs are maintained, both generated from the schematic netlist (2026-09-18; cross-checked again 2026-09-21 at 184 references; `R84` added to both on 2026-10-01, 185 references):

| BOM | Who it's for | File |
|---|---|---|
| **JLCPCB optimized (standard)** | anyone ordering assembled boards from JLCPCB — the cheapest *verified* parts at every position, checked against JLC's live library on 2026-09-17/18 | [`production/jlc_bom.csv`](../production/jlc_bom.csv) (named `bom_JLC_upload_v4_optimized.csv` until 2026-09-21) |
| **Hand-build (DigiKey-style)** | building one or a few boards yourself from easily found Western-distributor parts (GCT MEM2075 microSD, APEM switches, Hirose, TI, onsemi, ADI…) | [`BOM_handbuild_digikey.csv`](BOM_handbuild_digikey.csv) |

Population (all BOMs): **166 placed**, **11 DNP** (`TP3 TP4 TP5`, `R43 R45 R58 R66 R72 R74`, `SW6`, `U14`), 8 bare-copper refs
(`H1–H6`, `TP1`, `TP2`). The DNP set is flagged in both the schematic and the board, so the Fabrication
Toolkit CPL agrees with the BOM. `U13` (DS3231MZ+) is populated and optional; `SW6` (APEM MJTP1243 BOOT button)
is DNP because USB-Serial-JTAG makes it unnecessary. Never fit `R73` and `R74` together.

Regenerate the Toolkit set after any schematic/PCB change — it must contain the six Fix 4 parts
(`Q2 Q9 R79 R80 R81 R82`); the 2026-10-01 set does. The schematic and PCB now carry `MPN`, `Manufacturer` and
`LCSC` fields (written by `apply_part_fields.py` from [`part_fields.csv`](part_fields.csv), the source of truth for
part numbers), and the Toolkit's `production/bom.csv` is exported from them. JLC's automatic matching is what put a
reverse-mount LED on `D2` in the first order, so still check the placement preview.

## What the optimized BOM changes, and why

Every part in the population was crawled on JLC (library type, stock, price tiers) and LCSC (attributes), and
every Extended part was searched for Basic/Preferred and cheaper same-spec alternates. JLC charges a loading fee
per **Extended** part type per order (no fee for **Basic** or **Preferred**), so at small quantities a
slightly dearer Basic part is often cheaper overall. Seven cost swaps survived review, plus engineering changes
(`CR1`, `L2` on 2026-09-17; `L1`, `R14`, `C9` on 2026-09-18) that came out of the same passes:

| Ref(s) | Was | **Now** | Why (verified 2026-09-17) |
|---|---|---|---|
| `U13` | DS3231MZ+ `C722467` cut tape, $3.53, **373 in stock** | **DS3231MZ+TRL `C107410`**, $2.44, 11k stock | identical ADI part on reel — **−$1.10/board**, removes a stock risk |
| `Q2 Q3 Q7 Q8` | AO3419 `C88053`, Extended, 2.4k stock | **AO3401A `C15127`**, **Basic**, 441k stock | same price; −30 V P-ch, 85 mΩ @ 2.5 V vs 140 mΩ, Vgs(th) ≈ −0.9 V — a drop-in improvement for these load switches; no feeder fee. **Applied** — the schematic Value on Q2/Q3/Q7/Q8 reads AO3401A (same SOT-23 pinout) |
| `D4 D5 D6` | B5819W `C64885`, Extended | **B5819W SL `C8598`**, **Basic** | +$0.03/board on the part, −$1.50/order in fees — cheaper below ~55 boards, and a Basic part never needs a feeder |
| `D3` | SMAJ26A `C1509531`, Extended | **SMAJ26A `C19077543`**, **Preferred** (no fee) | $0.036 vs $0.054, 57k stock, same 26 V/400 W spec |
| `F1` | Littelfuse 0805L100WR `C80270` | **Brightking SMD0805B100TFT `C269106`** | 1 A hold / 1.95 A trip / 6 V max — the same numbers — at $0.033 vs $0.138 |
| `CR2 CR3` | SD05C TECH PUBLIC `C907858`, 4k stock | **SD05C-01FTG DOWO `C5299440`**, 99k stock | $0.025 vs $0.035; on 3V3 and P+ (≤4.2 V) a 5.0 V standoff has real margin, and the higher capacitance (60 pF) is irrelevant on a rail |
| `CR1` (VBUS) | SD05C-class, **5.0 V** standoff, SOD-323 | **SMF6.5CA `C19077501`** (hongjiacheng, **Preferred** — no fee, 1.75 M stock, $0.029), **SOD-123FL** | a USB-C source may legally sit at 5.5 V; "05" parts specify leakage only at 5.0 V and clones break down from 6 V. TI's TSD05C is genuinely rated ±5.5 V, but anything sold under an "05" name at LCSC is a 5.0 V part — prime and clone disagree on exactly the spec that matters. **SMFxx is a standardized ladder where the name is the spec**: every SMF6.5CA, official (Littelfuse) or clone, is 6.5 V standoff, V_BR 7.22–7.98 V, ≤11.2 V clamp @ 17.9 A (10/1000 µs), 200 W, bidirectional. 1 V of real margin over 5.5 V, clamp as low as TSD05C's, 40 JLC listings / 2.9 M pcs. **Applied — CR1's footprint is `Diode_SMD:D_SMF`** (fits the same spot: 4.2 × 2.2 mm courtyard vs the earlier 4.1 × 1.9 mm hand-solder SOD-323) |
| `C9 C11 C13–C17` | Samsung CL21A475KBQNNNE `C98192` (C9 was 1 µF `C28323`) | **Samwha CS2012X5R475K500NRE `C513770`** | 4.7 µF **50 V** X5R 0805 from a reputable maker, $0.045 vs $0.077, 209k stock; `C9` joined this line on 2026-09-18 (see "C9" below) |
| `L2` | **4.7 µH** TDK VLS252010HBU-4R7M `C413592` (schematic), 1.0k stock | **10 µH TDK VLS252012HBX-100M-1 `C88532`**, 20.7k stock, $0.068 | value change — see "L2: 4.7 µH → 10 µH" below. **Applied — the schematic reads 10u / VLS252012HBX-100M-1.** If L2 must stay 4.7 µH, use HBX-4R7M-1 `C88528` (what both earlier orders were built with: cheaper than HBU at every tier, 208 vs 274 mΩ, 2× the stock) |
| `L1` | 22 µH TDK VLS3012HBX-220M `C350879`, $0.208 @5 | **47 µH Sunltech SLW5040S470MST `C206267`**, Extended, 1.9k stock, $0.045 @1 | value change to match the SSD1677 reference design (47 µH / 2.2 Ω); 5 × 5 × 4 mm shielded, **footprint change** (`Inductor_SMD:L_APV_ANR5040`). Prime/DigiKey part: Laird TYS5040470M-10 (same case, also shielded). Both Extended, so no fee change; ≈ −$0.16/board |
| `R14` | 3 Ω, JLC `C22356394` (HKR RCA033RFLF), $0.0016 | **2.2 Ω: prime Yageo RC0603FR-072R2L; JLC code `C22939`** (UNI-ROYAL 0603WAF220KT5E, **Basic**, 11.7k stock, $0.0023 on 2026-09-20). The Yageo part's own code `C112307` was used until 2026-09-20, when its JLC stock fell from 94.9k to 12 | matches the SSD1677 reference sense resistor once `L1` is 47 µH; now Basic, so no Extended fee |

Evaluated and **not** taken: TP4056 clones ($0.037 vs $0.146 — but the TOPPOWER original is a *Preferred* part with
no fee, and charge termination/thermal regulation of clones is unverified; the swap would actually add a fee at
small quantities); 74LVC1G04 clones (saves $0.02/board); a second, cheaper TPD4E1U06 type for the non-USB
positions (saves $0.16/board but adds a part type — only pays above ~10 boards); 2N7002 for the BSS138
positions (Basic, but its Vgs(th) can reach 2.5 V and Q9's detector must turn on at a 2.4 V cell); a 6.3 V 0603
22 µF Basic cap (wrong footprint, and `C4` sits on 5 V). **Changed 2026-09-21:** `C4 C6 C32` now use the Samsung
Basic part `C45783` (CL21A226MAQNNNE, $0.12, 1.7 M in stock) instead of the CCTC clone `C20416420` ($0.034 but
Extended, and down to 396 pcs). The clone only wins on price above about 12 boards (3 caps × $0.085 saved per board
against one ≈ $3 Extended fee); for the 2–5 board orders the README is written for, Basic is cheaper and has no
stock risk. `R15` (GDR pull-down) also moved from 10 k to 1 M to match Good Display's reference circuit (datasheet
§8.2, R1 = 1 M) — no new BOM line, it joins the existing 1 M group.

**Stock to watch (JLC, 2026-09-18):** TPS923610DRLR `C52919131` **189 pcs** — order promptly or consign (about 107
are needed at 100 boards); A2541HWR-2x6P `C5333437` 1.3k; SLW5040S470MST `C206267` 1.9k; PESD2IVN-UX `C42370512` 3.0k;
USB4085-GF-A `C7095263` 4.4k; IRLML6346TRPBF `C67276` 5.5k.

**If TPS923610 is out of stock (2026-09-23):** JLC's stock of `C52919131` is being reserved for the
open-beta run, and JLC says restocking is unpredictable. For a frontlight build: (1) pre-order it through JLC
Parts Manager (any account; lead time only), or (2) fit **TPS923611DRLR for U10 *and* SMAJ33A for D3**
together. The TPS923611 has the same DRL footprint and pinout but a ~30 V output ceiling, above the
SMAJ26A's 28.9 V breakdown. Full steps are in the README under *If the frontlight driver is out of stock*.
TPS923612 is WSON (DRV) only and doesn't fit.

### L2: 4.7 µH → 10 µH

The TPS923610 is a peak-current-mode, internally compensated boost that runs **forced-continuous at 1.1 MHz at
every load** (datasheet §7.3.4/§7.4.1). Its ripple current therefore does not shrink when the LEDs are dimmed,
and TI sizes L to keep that ripple small: **every** 1.1 MHz characterization in the datasheet — efficiency vs
dimming, FB accuracy from 0.1–100 %, dimming transient, start-up — is taken with **10 µH and 1 µF** (this board's
`C9` was 1 µF and is now 4.7 µF — see "C9: 1 µF → 4.7 µF" below for why the *effective* value at operating bias ran
below TI's minimum, and why 4.7 µF is still inside TI's own recommended COUT range). 4.7 µH is not prohibited, but it
is outside what TI characterized, and it doubles the inductor slopes that the fixed internal slope
compensation has to cover at this board's 75–80 % duty.

Loss model at 3.7 V in / 15 V out, using **TDK's measured Rac(f)** for each part (harmonics to 7.7 MHz), TI's
typical FET resistances, and the same fixed switching loss for all options:

| | ripple p-p | core/AC | copper | FET | battery draw @ 13.3 mA / 6.6 / 3.0 / 1.3 mA LED |
|---|--:|--:|--:|--:|---|
| 4.7 µH HBX-4R7M-1 (as built) | 0.60 A | 21 mW | 7 mW | 12 mW | 68.9 / 40.9 / 25.9 / 18.9 mA |
| 4.7 µH HBU-4R7M | 0.54 A | 20 mW | 8 mW | 10 mW | 68.1 / 40.1 / 25.1 / 18.1 mA |
| **10 µH VLS252012HBX-100M-1** | 0.27 A | 9 mW | 4 mW | 3 mW | **62.4 / 34.3 / 19.3 / 12.3 mA** |
| 10 µH VLS252010HBU-100M (1.0 mm) | 0.26 A | 8 mW | 5 mW | 3 mW | 62.3 / 34.1 / 19.1 / 12.0 mA |
| 10 µH VLS252012CX-100M-1 (ferrite) | 0.30 A | 27 mW | 5 mW | 4 mW | no gain — Rac 3.5 Ω @ 1.1 MHz, hard saturation; rejected |

The saving is a nearly constant **≈6–7 mA of battery current whenever the frontlight is on** — about 10 % at
full brightness and 25–35 % at reading-in-the-dark levels. Absolute numbers carry model uncertainty (small-signal
Rac, assumed LED V_f); the *difference* between inductors is the robust part. Dimming is analog and DC in both
cases, so neither value flickers; 10 µH additionally lowers 1.1 MHz output ripple by about a third and puts the
loop on TI's characterized operating point at the 1–2 mV FB levels of deep dimming.

Part choice: `C88532` has the same measured Rac as the 1.0 mm HBU-100M (`C2042741`, $0.11, 1.6k stock) with lower
DCR (450 vs 580 mΩ), 13× the stock and 40 % lower price; its guaranteed Isat (1.0 A, 1.3 A typ, soft
saturation) clears the 0.8 A soft-start limit and the ≈0.2 A running peak. It is 1.2 mm tall — lower than the
0805 capacitor (`C9`) beside it. Same 2.5 × 2.0 mm land.

**Bench check on an existing board (5 minutes):** swap L2, run from 3.7 V, and compare supply current at 100 %,
25 % and 10 % ADIM duty against the table. Also confirm clean start-up and a steady `LED_SW` at 1 % duty.

**Next-revision savings that need a footprint change:** a $0.10 THT USB-C exists (HDGC 1.0-B-16P `C2915479`,
staggered-pin 16P) against the $1.04 GCT — worth $0.93/board if its land is adopted; a Basic red 0805 LED
(NationStar `C84256`, $0.013) if `D2` becomes 0805.

### C9: 1 µF → 4.7 µF (applied 2026-09-18)

TI's TPS923610 datasheet recommends **1–4.7 µF** for the boost output cap, trading ripple against loop
stability, and characterizes the reference design at 1 µF nominal — which `C9` (Samsung `CL21B105KBFNNNE`
`C28323`, 1 µF/50 V/0805/X7R) was. The catch is DC-bias derating: a 1 µF/50 V/0805
X7R part typically loses 25–40 % of its capacitance at the ~15–24 V the LED rail actually runs at, putting
`C9`'s *effective* value around 0.6–0.8 µF — below TI's own stated minimum, not just below their "typical"
window.

Replacement (applied): **4.7 µF/50 V/0805**, still inside TI's approved range. Samwha
`CS2012X5R475K500NRE` `C513770` is the drop-in LCSC pick — the same part already used for `C11`/`C13`–`C17`,
so this doesn't add a new line item, just changes `C9`'s reference count. DigiKey-findable prime part: TDK
`CGA4J1X7R1H475K125AC` (X7R, derates less than X5R at this case size/voltage).

This does **not** reintroduce dimming flicker: TPS923610 only dimms by chopping its internal reference, which
is low-pass filtered *before* the current-control loop (§7.3.8), so there's no PWM-edge current transient at
the LED string for a bigger `C9` to smear. It **does** proportionally slow the C9-re-slew color-blend
transition described in `docs/HARDWARE.md` §8 (same physical capacitor, different role) — order-of-magnitude
estimate ~75 µs → ~350 µs, almost certainly imperceptible for a CCT blend but unvalidated either way; see
[DESIGN_REVIEW.md](../DESIGN_REVIEW.md) §8 for the full reasoning.

## Cost

JLC part prices at each order size (≈3 % + 4 pcs attrition on SMD parts, as JLC applies), plus the Extended
loading fee. The model reproduces the line prices on both previous order exports to within cents.

| Per board, parts + fees | 5 boards | 10 | 30 | 100 |
|---|--:|--:|--:|--:|
| earlier brand-conservative BOM (`bom_JLC_upload_v3.csv`, deleted 2026-09-21; 28 Extended types) | $36.40 | $24.78 | $17.62 | $13.72 |
| **`jlc_bom.csv`, as costed 2026-09-18 (26 Extended types)** | **$33.23** | **$22.70** | **$16.25** | **$12.61** |
| …if JLC's fee is $3.00 instead of $1.50 | $41.03 | $26.60 | $17.55 | $13.00 |

*Since this costing: `R14` (2026-09-20) and `C4`/`C6`/`C32` (2026-09-21) moved to Basic parts and the Extended PPTC `F2` was added - a net of one Extended type fewer, a few cents per board either way. `R84` (2026-10-01) is a Basic part at $0.0026 and adds no Extended type. A real quote for five boards with two assembled was $223.95 before shipping on 2026-09-21 (see the root README).*

*Recomputed 2026-09-18 after the L1 (47 µH Sunltech), R14 (2.2 Ω) and C9 (4.7 µF) changes, from the current production `bom.csv` and live JLC prices; the Extended-type count is unchanged because L1 and R14 swap one Extended part for another and C9 joins the existing `C513770` line. The saving is mostly `L1` (≈ −$0.16/board).*

Where the money goes at 30 boards (optimized, $16.25/board): ESP32-S3-WROOM-1-N16R8 $4.03 · DS3231MZ+ $2.71 ·
USB-C receptacle $1.04 · TPS923610 $0.59 · ten TS365ZJ switches $0.52 · CCTC 22 µF ×3 $0.40 · TPS2116 $0.27 ·
Hirose FH34SRJ-24S $0.31 · fees $1.30 · everything else ≈ $5. Consigning the module and the RTC removes $6.74.

**PCB + assembly** is not in those files: your 30-board quote was $624.08 total against $338.12 of parts, i.e.
≈ **$9.5/board** for PCB, SMT, hand-soldered THT and setup at that quantity (roughly $15–20/board at 5 boards,
where the fixed setup dominates). All-in at 30 boards ≈ **$26/board** (≈ $25.75 with the 2026-09-18 parts).

**Hand-build** (one board, DigiKey-style parts, reference qty-1 prices from the owner's mid-2026 DigiKey sourcing
sheet or catalog estimates — DigiKey itself could not be crawled this session): ≈ **$48 in parts by that sheet, but budget ≈ $66** — the 2026-09-19 review re-priced it against live DigiKey single-piece prices and found the sheet low by about 38 %, mostly on two lines (`U13` DS3231MZ+ is $13.85, not the $5.50 estimate, and the ten MJTP1117 switches are $6.13) — before the
PCB (≈$5–10 each at qty 5) and your time. TP4056 and DW01A are LCSC-only and cheap enough to order alongside;
**`Q1` FS8205A is DigiKey-findable after all** — verified 2026-09-18: Fortune Semiconductor's own "FS8205A" is
TSSOP-8 only (every datasheet revision, 2009–2016; their SOT-23-6 dual-FET part is "FS8205," no A), but
**EVVOSEMI's SOT-23-6 "FS8205A" (DigiKey PN `26220994`) is a real part**, pin-compatible with this footprint —
use that as the hand-build source, not a generic "Fortune, LCSC-only" note. TECH PUBLIC's SOT-23-6 FS8205A
(LCSC `C2830320`) remains the JLC-build source. Everything else is a stock DigiKey/Mouser line. Roughly three
times the JLC per-board parts cost at 30 boards, which is the expected premium for building singles.

## Review of the earlier "price-maxed" sheet

`bom-JLCPCB_PriceMaxed.xlsx` (25-board basis; a local working sheet that was never tracked in this repository) got the big things right and was the basis of the
second order: TS365ZJ switches (−$1.17/board), TF PUSH microSD (−$1.23/board), SD05C TVS (−$0.35/board) and
the unmatched-line fills. Its misses, now corrected in `jlc_bom.csv`:

- **`L2` "SWAP ~$0" to HBU** — proposed only to match the schematic's MPN, at +$0.0035 by its own numbers. HBX `C88528` was, and is, the cheaper and lower-DCR 4.7 µH part, and both orders kept it. (v4 now moves L2 to 10 µH — see above.)
- **`CR1` "SD05C, −$0.35/board"** — right for CR2/CR3, but on VBUS it traded the schematic's 5.5 V-rated TSD05C for a 5.0 V-rated part on a rail that may legally sit at 5.5 V. v4 moves CR1 to SMF6.5CA (6.5 V standoff by family definition, JLC Preferred) — cheaper than either.

- **`D2` endorsed as "floor"** — the $0.009 part it kept (`C2827254`) is a *reverse-mount* LED that needs a board cutout; JLC flagged it. Now YLED1206R (`C28310439`), standard top-emitting.
- **22 µF "$0.04"** — the CCTC part was $0.12 at JLC, so the projected saving was overstated by ~$0.25/board. Dropped on 2026-09-21 in favour of the Basic part `C45783` (see above).
- **B5819W and SMAJ26A "floor/keep"** — missed that a Basic B5819W and a Preferred SMAJ26A exist (two feeder fees).
- **AO3419 "verify AO3401A"** — AO3401A is Basic, equal-priced, better R_DS(on) and stocked 200× deeper; it should have been a swap, not a caution.
- **"R14/R37 may be Basic"** — corrected 2026-09-20: a Basic 2.2 Ω 0603 **does** exist (`C22939`, UNI-ROYAL 0603WAF220KT5E, ±1 %, ±400 ppm/°C) and R14 now uses it; no Basic 3 Ω or 15 Ω 0603 was found, but the 15 Ω UNI-ROYAL is *Preferred* (no fee), so R37 costs nothing extra.
- **DS3231 "consigned, no knock-off worth it"** — true, but JLC's own cut-tape listing is 45 % dearer than the reel listing of the same part.
- **"No viable THT USB-C"** — one exists at $0.10 (different land; next rev).
- Its "OPP" rows for TPD4E1U06/AO3419/F1: F1 adopted (spec-identical Brightking); AO3419 adopted via AO3401A; TPD4E1U06 declined (see above).

## Placed parts (optimized BOM)

### ICs

| Qty | Refs | Value | JLC/LCSC | MPN / manufacturer | Notes |
|--:|---|---|---|---|---|
| 1 | U4 | ESP32-S3-WROOM-1 | `C2913202` | Espressif ESP32-S3-WROOM-1-N16R8 | 16 MB flash / 8 MB octal PSRAM — must be an R8 part |
| 1 | U3 | TLV75533PDBV | `C404027` | TI TLV75533PDBVR | 3.3 V LDO, 500 mA |
| 1 | U2 | TPS2116DRL | `C3235557` | TI TPS2116DRLR | power-path mux |
| 1 | U11 | TP4056-42-ESOP8 | `C16581` | TOPPOWER TP4056-42-ESOP8 (JLC Preferred) | Li-ion charger; R6 = 4.7 kΩ ≈ 0.25 A |
| 1 | U5 | DW01A | `C351410` | PUOLOP DW01A | cell protection controller |
| 1 | U10 | TPS923610DRLR | `C52919131` | TI TPS923610DRLR | frontlight boost driver — **low JLC stock** |
| 1 | U12 | 74LVC1G04 | `C53185133` | MDD 74LVC1G04GV | inverter (warm/cool select) |
| 1 | U13 | DS3231MZ | `C107410` | ADI DS3231MZ+TRL (reel) | RTC, VBAT-only wiring; optional |
| 5 | U1 U6 U7 U8 U9 | TPD4E1U06DBVR | `C19829453` | TECH PUBLIC TPD4E1U06DBVR | ESD arrays: SD (U1, U9), USB (U6), touch (U7), expansion (U8) |

### Transistors

| Qty | Refs | Value | JLC/LCSC | MPN / manufacturer | Notes |
|--:|---|---|---|---|---|
| 4 | Q2 Q3 Q7 Q8 | AO3401A | `C15127` | AOS AO3401A P-ch (Basic) | Q3/Q8 battery series, Q7 SD power switch, Q2 Fix 4 3V3→CE pass. Applied — schematic Value reads AO3401A |
| 3 | Q5 Q6 Q9 | BSS138 | `C7420339` | hongjiacheng BSS138 N-ch (Preferred) | Q5/Q6 frontlight string select, Q9 Fix 4 polarity detector (source → B−) |
| 1 | Q4 | IRLML6346TRPBF | `C67276` | Infineon IRLML6346TRPBF N-ch | EPD charge-pump switch — genuine Infineon, do not accept a clone |
| 1 | Q1 | FS8205A | `C2830320` | TECH PUBLIC FS8205A | dual N-FET, cell protection |

### Diodes / TVS

| Qty | Refs | Value | JLC/LCSC | MPN / manufacturer | Notes |
|--:|---|---|---|---|---|
| 3 | D4 D5 D6 | B5819W | `C8598` | Jiangsu Changjing B5819W SL, 40 V Schottky (Basic) | EPD charge-pump rectifiers |
| 1 | D2 | LED | `C28310439` | YONGYUTAI YLED1206R red | USB-present indicator, standard top-emitting; pad 1 = cathode |
| 1 | D3 | SMAJ26A | `C19077543` | hongjiacheng SMAJ26A (Preferred) | TVS on LED_SW |
| 1 | D8 | PESD2IVN-UX | `C42370512` | TECH PUBLIC PESD2IVN-UX | ESD on the LED returns |
| 1 | CR1 | **SMF6.5CA** | `C19077501` | hongjiacheng SMF6.5CA (Preferred); prime part Littelfuse SMF6.5CA | VBUS TVS ahead of F1, **SOD-123FL**, bidirectional: 6.5 V standoff, V_BR 7.22–7.98 V, ≤11.2 V @ 17.9 A. Schematic and PCB carry SMF6.5CA in `Diode_SMD:D_SMF` (the symbol is still the TSD05CDYFR library symbol, which is why ERC reports a footprint-filter warning) |
| 2 | CR2 CR3 | TSD05CDYFR | `C5299440` | DOWO SD05C-01FTG | 5.0 V-standoff bidirectional TVS on 3V3 and P+ (≤4.2 V) — adequate margin on these rails |

### Connectors

| Qty | Refs | Value | JLC/LCSC | MPN / manufacturer | Notes |
|--:|---|---|---|---|---|
| 1 | J1 | USB_C_Receptacle | `C7095263` | GCT USB4085-GF-A, THT | confirm THT soldering is in the JLC job |
| 1 | J2 | FH34SRJ-24S-0.5SH_50_ | `C324726` | Hirose FH34SRJ-24S-0.5SH(50) | 24-pin e-paper FPC |
| 2 | J3 J4 | FH34SRJ-6S-0.5SH_50_ | `C224194` | Hirose FH34SRJ-6S-0.5SH(50) | frontlight (J3), touch (J4) |
| 1 | J5 | Conn_01x02 | `C48579993` | CJT A2001WR-2P (JST PH 2-pin right-angle equivalent) | battery; pin 1 = B−, pin 2 = B+ |
| 1 | J6 | PPPC062LJBN-RC | `C5333437` | CJT A2541HWR-2x6P | 2×6 expansion header — low JLC stock |
| 1 | J7 | Micro_SD_Card | `C393941` | SHOU HAN TF PUSH | push-push microSD; slotted dual-source land also fits GCT MEM2075 |

### Switches

| Qty | Refs | Value | JLC/LCSC | MPN / manufacturer | Notes |
|--:|---|---|---|---|---|
| 10 | SW1 SW2 SW3 SW4 SW5 SW7 SW8 SW9 SW10 SW11 | SW_Push | `C557598` | SHOU HAN TS365ZJ right-angle THT tactile | MJTP1117 land |
| — | SW6 | SW_Push | **DNP** | APEM MJTP1243 (6 × 3.5 × 4.3 mm vertical 2-pin THT, 6.5 mm pitch) | BOOT button; different land, TS365ZJ does not fit |

### Inductors / fuse

| Qty | Refs | Value | JLC/LCSC | MPN / manufacturer | Notes |
|--:|---|---|---|---|---|
| 1 | L1 | **47u** | `C206267` | **Sunltech SLW5040S470MST** | EPD charge-pump inductor, **5 × 5 × 4 mm shielded — changed 2026-09-18 from 22 µH/3×3 mm** to match the SSD1677 reference design; prime/DigiKey part is **Laird TYS5040470M-10**, same case size, also shielded. KiCad footprint `Inductor_SMD:L_APV_ANR5040` (pad gap checked against Bourns' published land pattern for this case class). Footprint change — see `DESIGN_REVIEW.md` §7 and §12 |
| 1 | L2 | **10u** | `C88532` | TDK VLS252012HBX-100M-1 | frontlight boost inductor, 2.5 × 2.0 × 1.2 mm (schematic reads 10u / VLS252012HBX-100M-1; 1.0 mm alternative VLS252010HBU-100M `C2042741`) |
| 1 | F1 | 0805L100WR | `C269106` | Brightking SMD0805B100TFT | 1 A hold / 1.95 A trip / 6 V PTC (≈0.65 A hold at 60 °C) |
| 1 | F2 | 0805L075WR | `C151146` | Littelfuse 0805L075WR | 0.75 A hold / 1.5 A trip / 6 V PTC in series with `J6` pin 12 (raw battery on the expansion header). Added 2026-09-21 |

### Resistors (0603, 1 %, except R27 which is 0805; all Basic except R37, which is Preferred)

| Qty | Refs | Value | JLC/LCSC |
|--:|---|---|---|
| 5 | R42 R44 R46 R52 R73 | 0 | `C21189` |
| 1 | R27 | 0 (**0805**) | **`C17477`** — changed 2026-09-18 from 0603 `C21189`; UNI-ROYAL 0805W8F0000T5E, Basic, $0.0045; prime part Yageo RC0805JR-070RL. Battery-path jumper, carries the full load current |
| 1 | R84 | **1** | **`C22936`** — UNI-ROYAL 0603WAF100KT5E, Basic, $0.0026, JLC stock 256,298 on 2026-10-01; prime part Yageo RC0603FR-071RL. Added 2026-10-01 in series with `C2`'s ground leg as a USB hot-plug damper; no DC current flows in it. Chosen over the hot-plug study's first pick, 0.51 Ω 0402 `C728429` (Extended), to avoid 0402 parts and a new Extended type; 1 Ω damps slightly less |
| 5 | R60 R61 R63 R64 R83 | 100 | `C22775` — `R83` is the DW01A VCC filter resistor, added 2026-09-21 |
| 2 | R16 R78 | 1k | `C21190` |
| 1 | R59 | 2k | `C22975` |
| 1 | R14 | **2.2** | **`C22939`** — UNI-ROYAL 0603WAF220KT5E, Basic, $0.0023 (2026-09-20; was `C112307`, the Yageo RC0603FR-072R2L itself, until its JLC stock fell to 12). Value changed 2026-09-18 from 3 Ω / `C22356394` |
| 2 | R47 R48 | 2.2k | `C4190` |
| 1 | R6 | 4.7k | `C23162` |
| 2 | R2 R3 | 5.1k | `C23186` |
| 1 | R18 | 5.6k | `C23189` |
| 12 | R4 R5 R7 R8 R9 R13 R28 R53 R54 R55 R56 R62 | 10k | `C25804` |
| 1 | R11 | 12k | `C22790` |
| 1 | R37 | 15 | `C22810` |
| 1 | R19 | 20k | `C4184` |
| 15 | R21 R22 R23 R24 R25 R26 R29 R30 R31 R32 R33 R34 R65 R68 R69 | 33 | `C23140` |
| 1 | R35 | 33k | `C4216` |
| 1 | R20 | 56k | `C23206` |
| 1 | R36 | 68k | `C23231` |
| 6 | R40 R51 R75 R76 R77 R79 | 100k | `C25803` |
| 1 | R41 | 120k | `C25808` |
| 1 | R71 | **200k** | **`C25811`** — `USB_STAT` ladder rescaled ×10 on 2026-09-21 for sleep current (was 22k `C31850`); Basic |
| 1 | R38 | 300k | `C23024` |
| 1 | R67 | **510k** | **`C23192`** — `USB_STAT` ladder (was 56k, shared with `R20`); Basic |
| 11 | R1 R10 R12 R15 R39 R49 R50 R70 R80 R81 R82 | 1M | `C22935` — `R70` joined this line 2026-09-21 (was 100k); `R57` left it |
| 1 | R17 | **2M** | **`C22976`** — `USB_STAT` ladder (was 150k `C22807`); Basic |
| 1 | R57 | **10M** | **`C7250`** — `Q3` gate bleed, raised from 1M on 2026-09-21 to cut ≈3.3 µA of permanent battery drain; Basic |

### Capacitors

| Qty | Refs | Value | Pkg | JLC/LCSC | MPN |
|--:|---|---|---|---|---|
| 1 | C1 | 1n | 0603 | `C1588` | Samsung CL10B102KB8NNNC 50 V X7R (Basic) |
| 4 | C27 C28 C29 C34 | 2.2n | 0603 | `C1604` | FH 0603B222K500NT 50 V X7R (Basic). `C34` (DW01A `CS` filter) added 2026-09-21; `C23` moved to 0.1u |
| 7 | C7 C23 C24 C30 C31 C33 C36 | 0.1u | 0603 | `C14663` | Yageo CC0603KRX7R9BB104 50 V X7R (Basic) |
| 7 | C5 C8 C21 C22 C25 C26 C37 | 1u | 0603 | `C15849` | Samsung CL10A105KB8NNNC 50 V X5R (Basic) |
| 2 | C10 C12 | 4.7u | 0603 | `C19666` | Samsung CL10A475KO8NNNC 16 V X5R (Basic) |
| 1 | C2 | 10u/25V | 0603 | `C96446` | Samsung CL10A106MA8NRNC **25 V** X5R (Basic) — the hot-plugged USB VBUS bulk cap; changed 2026-09-21 from the 10 V part. Since 2026-10-01 its ground leg runs through `R84` (1 Ω) |
| 1 | C3 | 10u | 0603 | `C19702` | Samsung CL10A106KP8NNNC 10 V X5R (Basic) |
| 3 | C18 C19 C20 | 1u/50V | 0805 | `C28323` | Samsung CL21B105KBFNNNE **50 V** X7R (Basic) |
| 7 | C9 C11 C13 C14 C15 C16 C17 | 4.7u/50V | 0805 | `C513770` | Samwha CS2012X5R475K500NRE **50 V** X5R (`C9` moved here from the 1 µF line 2026-09-18) |
| 3 | C4 C6 C32 | 22u | 0805 | `C45783` | Samsung CL21A226MAQNNNE 25 V X5R (**Basic**, 1.7 M in stock 2026-09-21). Prime/DigiKey MPN is now Murata GRM21BR61E226ME44L because the Samsung part is obsolete at DigiKey. Was the CCTC clone `C20416420` (Extended, 396 left) |

## DNP in every build

| Refs | Value | Purpose |
|---|---|---|
| R43 R66 | 0 | touch VDD/INT swap (alternate to R42/R44) |
| R45 R58 | 0 | touch SDA/SCL swap (alternate to R46/R52) |
| R72 R74 | 10k / 0 | UP(2) as power button (alternate to R36/R73) — **never fit R73 and R74 together** |
| TP3 TP4 TP5 | pin header | frontlight test pins (LED_SW, C−, W−) |
| SW6 | APEM MJTP1243 | BOOT button. Not needed for flashing (USB-Serial-JTAG). LCSC equivalents if fitting: ALPS SKHLACA010 `C382056`, HYP 1TS002A-1600-4300 `C255782` — confirm the 6.5 mm pin pitch |
| U14 | RV-8263-C7 | Alternate RTC — Micro Crystal RV-8263-C7-32.768KHZ-20PPM-TA-QA, `C5137460`. Cheaper than `U13` (DS3231MZ+) but less stocked; fit **one** of `U13`/`U14`, or neither |

## Hand-build (DigiKey-style) parts

Full list with reference prices: [`BOM_handbuild_digikey.csv`](BOM_handbuild_digikey.csv). Same lands as the
JLC build; search DigiKey/Mouser by the manufacturer part number.

| Refs | Part | Note |
|---|---|---|
| J7 | GCT MEM2075-00-140-01-A | push-push, fits the slotted dual-source land |
| J1 | GCT USB4085-GF-A | THT USB-C |
| J2, J3/J4 | Hirose FH34SRJ-24S-0.5SH(50), FH34SRJ-6S-0.5SH(50) | |
| J5, J6 | JST S2B-PH-K-S(LF)(SN), Sullins PPPC062LJBN-RC | |
| SW1–SW5, SW7–SW11 / SW6 | APEM MJTP1117 / MJTP1243 (DNP) | |
| Q2 Q3 Q7 Q8 / Q4 / Q5 Q6 Q9 / Q1 | AOS AO3401A (or AO3419) / Infineon IRLML6346TRPBF / onsemi BSS138LT1G / **EVVOSEMI FS8205A (DigiKey PN `26220994`, SOT-23-6)** | Q1: not Fortune Semiconductor — Fortune's own "FS8205A" is TSSOP-8 only; their SOT-23-6 part is "FS8205" (no A). EVVOSEMI's SOT-23-6 "FS8205A" is pin-compatible and DigiKey-stocked |
| U2 U3 U10 U12 / U13 / U1 U6–U9 | TI TPS2116DRLR, TLV75533PDBVR, TPS923610DRLR, SN74LVC1G04DBVR / ADI DS3231MZ+ / TI TPD4E1U06DBVR | |
| U11 / U5 | TP4056-42-ESOP8 / DW01A | LCSC-only; order from LCSC |
| D2 / D3 / D4–D6 / D8 / CR1–CR3 | Lite-On LTST-C150KRKT (red 1206, pad 1 = cathode) / Littelfuse SMAJ26A / Diodes B5819W or 1N5819HW-7-F / Nexperia PESD2IVN-UX / Littelfuse SMF6.5CA (CR1) and TI TSD05CDYFR (CR2, CR3) | |
| L1 / L2 / F1 / F2 | Laird TYS5040470M-10 (47 µH, changed 2026-09-18) / TDK VLS252012HBX-100M-1 (10 µH; or VLS252010HBU-100M) / Littelfuse 0805L100WR / Littelfuse 0805L075WR | |
| passives | 0603 1 % thick film; Samsung CL10/CL21 — keep the 50 V parts 50 V | |

## Off-board items

| Item | Note |
|---|---|
| 4.26" e-paper panel | GDEY0426T82 (plain) / GDEQ0426T82-FL01C (frontlight) / -FT01C (frontlight + touch); check the J3 pin order for FT01C lots (DESIGN_REVIEW §8) |
| Battery | single-cell Li-ion/LiPo, 4.2 V charge; 500 mAh charges in ≈2.5–3 h at the default 0.25 A; verify cable polarity (pin 1 = B−) |

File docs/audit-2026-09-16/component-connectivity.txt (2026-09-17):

C1 | 1n | Capacitor_SMD:C_0603_1608Metric_Pad1.08x0.95mm_HandSolder | ~
  ('1', '', 'GND')
  ('2', '', 'Net-(J1-SHIELD)')
C2 | 10u | Capacitor_SMD:C_0603_1608Metric_Pad1.08x0.95mm_HandSolder | ~
  ('2', '', 'GND')
  ('1', '', 'USB_VBUS')
C3 | 10u | Capacitor_SMD:C_0603_1608Metric_Pad1.08x0.95mm_HandSolder | ~
  ('2', '', 'GND')
  ('1', '', 'P+')
C4 | 22u | Capacitor_SMD:C_0805_2012Metric_Pad1.18x1.45mm_HandSolder | ~
  ('2', '', 'GND')
  ('1', '', 'LDO_IN')
C5 | 1u | Capacitor_SMD:C_0603_1608Metric_Pad1.08x0.95mm_HandSolder | ~
  ('1', '', 'ESP32_EN')
  ('2', '', 'GND')
C6 | 22u | Capacitor_SMD:C_0805_2012Metric_Pad1.18x1.45mm_HandSolder | ~
  ('1', '', '3V3')
  ('2', '', 'GND')
C7 | 0.1u | Capacitor_SMD:C_0603_1608Metric_Pad1.08x0.95mm_HandSolder | ~
  ('2', '', 'B-')
  ('1', '', 'P+')
C8 | 1u | Capacitor_SMD:C_0603_1608Metric_Pad1.08x0.95mm_HandSolder | ~
  ('1', '', 'BAT_MONIT')
  ('2', '', 'GND')
C9 | 1u/50V | Capacitor_SMD:C_0805_2012Metric_Pad1.18x1.45mm_HandSolder | ~
  ('1', '', 'GND')
  ('2', '', 'LED_SW')
C10 | 4.7u | Capacitor_SMD:C_0603_1608Metric_Pad1.08x0.95mm_HandSolder | ~
  ('2', '', '3V3')
  ('1', '', 'GND')
C11 | 4.7u/50V | Capacitor_SMD:C_0805_2012Metric_Pad1.18x1.45mm_HandSolder | ~
  ('2', '', 'EINK_SW')
  ('1', '', 'Net-(D4-K)')
C12 | 4.7u | Capacitor_SMD:C_0603_1608Metric_Pad1.08x0.95mm_HandSolder | ~
  ('1', '', 'GND')
  ('2', '', 'LDO_IN')
C13 | 4.7u/50V | Capacitor_SMD:C_0805_2012Metric_Pad1.18x1.45mm_HandSolder | ~
  ('1', '', 'GND')
  ('2', '', 'Net-(C13-Pad2)')
C14 | 4.7u/50V | Capacitor_SMD:C_0805_2012Metric_Pad1.18x1.45mm_HandSolder | ~
  ('1', '', 'GND')
  ('2', '', 'PREVGH')
C15 | 4.7u/50V | Capacitor_SMD:C_0805_2012Metric_Pad1.18x1.45mm_HandSolder | ~
  ('1', '', 'GND')
  ('2', '', 'Net-(C15-Pad2)')
C16 | 4.7u/50V | Capacitor_SMD:C_0805_2012Metric_Pad1.18x1.45mm_HandSolder | ~
  ('1', '', 'GND')
  ('2', '', 'PREVGL')
C17 | 4.7u/50V | Capacitor_SMD:C_0805_2012Metric_Pad1.18x1.45mm_HandSolder | ~
  ('1', '', 'GND')
  ('2', '', 'Net-(C17-Pad2)')
C18 | 1u | Capacitor_SMD:C_0805_2012Metric_Pad1.18x1.45mm_HandSolder | ~
  ('1', '', 'GND')
  ('2', '', 'Net-(C18-Pad2)')
C19 | 1u | Capacitor_SMD:C_0805_2012Metric_Pad1.18x1.45mm_HandSolder | ~
  ('1', '', 'GND')
  ('2', '', 'Net-(C19-Pad2)')
C20 | 1u/50V | Capacitor_SMD:C_0805_2012Metric_Pad1.18x1.45mm_HandSolder | ~
  ('1', '', 'GND')
  ('2', '', 'Net-(C20-Pad2)')
C21 | 1u | Capacitor_SMD:C_0603_1608Metric_Pad1.08x0.95mm_HandSolder | ~
  ('1', '', '3V3')
  ('2', '', 'GND')
C22 | 1u | Capacitor_SMD:C_0603_1608Metric_Pad1.08x0.95mm_HandSolder | ~
  ('2', '', '3V3')
  ('1', '', 'GND')
C23 | 2.2n | Capacitor_SMD:C_0603_1608Metric_Pad1.08x0.95mm_HandSolder | ~
  ('2', '', 'GND')
  ('1', '', 'USB_STAT')
C24 | 100n | Capacitor_SMD:C_0603_1608Metric_Pad1.08x0.95mm_HandSolder | ~
  ('1', '', '3V3')
  ('2', '', 'GND')
C25 | 1u | Capacitor_SMD:C_0603_1608Metric_Pad1.08x0.95mm_HandSolder | ~
  ('1', '', 'GND')
  ('2', '', 'USB_VBUS')
C26 | 1u | Capacitor_SMD:C_0603_1608Metric_Pad1.08x0.95mm_HandSolder | ~
  ('2', '', 'GND')
  ('1', '', 'P+')
C27 | 2.2n | Capacitor_SMD:C_0603_1608Metric_Pad1.08x0.95mm_HandSolder | ~
  ('2', '', 'BUTTON_ADC_1')
  ('1', '', 'GND')
C28 | 2.2n | Capacitor_SMD:C_0603_1608Metric_Pad1.08x0.95mm_HandSolder | ~
  ('2', '', 'BUTTON_ADC_2')
  ('1', '', 'GND')
C29 | 2.2n | Capacitor_SMD:C_0603_1608Metric_Pad1.08x0.95mm_HandSolder | ~
  ('2', '', 'GND')
  ('1', '', 'PWR_BUTTON')
C30 | 0.1u | Capacitor_SMD:C_0603_1608Metric_Pad1.08x0.95mm_HandSolder | ~
  ('1', '', '3V3')
  ('2', '', 'GND')
C31 | 100n | Capacitor_SMD:C_0603_1608Metric_Pad1.08x0.95mm_HandSolder | ~
  ('2', '', 'GND')
  ('1', '', 'LED_MONIT')
C32 | 22u | Capacitor_SMD:C_0805_2012Metric_Pad1.18x1.45mm_HandSolder | ~
  ('1', '', '3V3')
  ('2', '', 'GND')
C33 | 0.1u | Capacitor_SMD:C_0603_1608Metric_Pad1.08x0.95mm_HandSolder | ~
  ('1', '', '3V3')
  ('2', '', 'GND')
C36 | 0.1u | Capacitor_SMD:C_0603_1608Metric_Pad1.08x0.95mm_HandSolder | ~
  ('1', '', 'GND')
  ('2', '', 'SD_VDD')
C37 | 1u | Capacitor_SMD:C_0603_1608Metric_Pad1.08x0.95mm_HandSolder | ~
  ('1', '', 'GND')
  ('2', '', 'SD_VDD')
CR1 | TSD05CDYFR | Diode_SMD:D_SOD-323_HandSoldering | https://www.ti.com/lit/gpn/tsd05c
  ('2', 'GND', 'GND')
  ('1', 'I/O', 'VBUS_PRE_FUSE')
CR2 | TSD05CDYFR | Diode_SMD:D_SOD-323_HandSoldering | https://www.ti.com/lit/gpn/tsd05c
  ('1', 'I/O', '3V3')
  ('2', 'GND', 'GND')
CR3 | TSD05CDYFR | Diode_SMD:D_SOD-323_HandSoldering | https://www.ti.com/lit/gpn/tsd05c
  ('2', 'GND', 'GND')
  ('1', 'I/O', 'P+')
D2 | LED | LED_SMD:LED_1206_3216Metric_Pad1.42x1.75mm_HandSolder | ~
  ('1', 'K', 'Net-(D2-K)')
  ('2', 'A', 'USB_VBUS')
D3 | SMAJ26A | Diode_SMD:D_SMA | https://www.littelfuse.com/media?itemid=75e32973-b177-4ee3-a0ff-cedaf1abdb93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
  ('2', 'A2', 'GND')
  ('1', 'A1', 'LED_SW')
D4 | B5819W | Diode_SMD:D_SOD-123 | http://www.mccsemi.com/up_pdf/MBR0520~MBR0580(SOD123).pdf
  ('1', 'K', 'Net-(D4-K)')
  ('2', 'A', 'PREVGL')
D5 | B5819W | Diode_SMD:D_SOD-123 | http://www.mccsemi.com/up_pdf/MBR0520~MBR0580(SOD123).pdf
  ('2', 'A', 'EINK_SW')
  ('1', 'K', 'PREVGH')
D6 | B5819W | Diode_SMD:D_SOD-123 | http://www.mccsemi.com/up_pdf/MBR0520~MBR0580(SOD123).pdf
  ('1', 'K', 'GND')
  ('2', 'A', 'Net-(D4-K)')
D8 | PESD2IVN-UX | Package_TO_SOT_SMD:SOT-323_SC-70_Handsoldering | ~
  ('1', 'A1', 'C-')
  ('3', 'common', 'GND')
  ('2', 'A2', 'W-')
F1 | 0805L100WR | Fuse:Fuse_0805_2012Metric_Pad1.15x1.40mm_HandSolder | ~
  ('2', '', 'USB_VBUS')
  ('1', '', 'VBUS_PRE_FUSE')
H1 | MountingHole_Pad | MountingHole:MountingHole_2.2mm_M2_DIN965_Pad_TopBottom | ~
  ('1', '1', 'GND')
H2 | MountingHole_Pad | MountingHole:MountingHole_2.2mm_M2_DIN965_Pad_TopBottom | ~
  ('1', '1', 'GND')
H3 | MountingHole_Pad | MountingHole:MountingHole_2.2mm_M2_DIN965_Pad_TopBottom | ~
  ('1', '1', 'GND')
H4 | MountingHole_Pad | MountingHole:MountingHole_2.2mm_M2_DIN965_Pad_TopBottom | ~
  ('1', '1', 'GND')
H5 | MountingHole_Pad | MountingHole:MountingHole_2.2mm_M2_DIN965_Pad_TopBottom | ~
  ('1', '1', 'GND')
J1 | USB_C_Receptacle | Connector_USB:USB_C_Receptacle_GCT_USB4085 | https://www.usb.org/sites/default/files/documents/usb_type-c.zip
  ('A5', 'CC1', 'CC1')
  ('B5', 'CC2', 'CC2')
  ('A7', 'D-', 'DN')
  ('B7', 'D-', 'DN')
  ('A6', 'D+', 'DP')
  ('B6', 'D+', 'DP')
  ('A1', 'GND', 'GND')
  ('A12', 'GND', 'GND')
  ('B1', 'GND', 'GND')
  ('B12', 'GND', 'GND')
  ('S1', 'SHIELD', 'Net-(J1-SHIELD)')
  ('A4', 'VBUS', 'VBUS_PRE_FUSE')
  ('A9', 'VBUS', 'VBUS_PRE_FUSE')
  ('B4', 'VBUS', 'VBUS_PRE_FUSE')
  ('B9', 'VBUS', 'VBUS_PRE_FUSE')
J2 | FH34SRJ-24S-0.5SH_50_ | FH34SRJ-24S-0.5SH(50):HRS_FH34SRJ-24S-0.5SH_50_ | None
  ('2', '2', '/GDR')
  ('3', '3', '/RESE')
  ('15', '15', '3V3')
  ('16', '16', '3V3')
  ('9', '9', 'EPD_BUSY')
  ('12', '12', 'EPD_CS')
  ('11', '11', 'EPD_DC')
  ('10', '10', 'EPD_RST')
  ('17', '17', 'GND')
  ('8', '8', 'GND')
  ('S1', 'SHIELD', 'GND')
  ('S2', 'SHIELD__1', 'GND')
  ('20', '20', 'Net-(C13-Pad2)')
  ('22', '22', 'Net-(C15-Pad2)')
  ('5', '5', 'Net-(C17-Pad2)')
  ('18', '18', 'Net-(C18-Pad2)')
  ('19', '19', 'Net-(C19-Pad2)')
  ('24', '24', 'Net-(C20-Pad2)')
  ('21', '21', 'PREVGH')
  ('23', '23', 'PREVGL')
  ('14', '14', 'SPI_MOSI')
  ('13', '13', 'SPI_SCK')
  ('1', '1', 'unconnected-(J2-Pad1)')
  ('4', '4', 'unconnected-(J2-Pad4)')
  ('6', '6', 'unconnected-(J2-Pad6)')
  ('7', '7', 'unconnected-(J2-Pad7)')
J3 | FH34SRJ-6S-0.5SH_50_ | FH34SRJ-6S-0.5SH(50):HRS_FH34SRJ-6S-0.5SH_50_ | None
  ('2', '2', 'C-')
  ('S1', 'SHIELD', 'GND')
  ('S2', 'SHIELD', 'GND')
  ('1', '1', 'LED_SW')
  ('5', '5', 'LED_SW')
  ('6', '6', 'W-')
  ('3', '3', 'unconnected-(J3-Pad3)')
  ('4', '4', 'unconnected-(J3-Pad4)')
J4 | FH34SRJ-6S-0.5SH_50_ | FH34SRJ-6S-0.5SH(50):HRS_FH34SRJ-6S-0.5SH_50_ | None
  ('2', '2', '/PIN_2')
  ('4', '4', '/PIN_4')
  ('5', '5', '/PIN_5')
  ('6', '6', '/PIN_6')
  ('1', '1', 'GND')
  ('S1', 'SHIELD', 'GND')
  ('S2', 'SHIELD', 'GND')
  ('3', '3', 'TP_RST')
J5 | Conn_01x02 | Connector_JST:JST_PH_S2B-PH-K_1x02_P2.00mm_Horizontal | ~
  ('2', 'Pin_2', 'B+')
  ('1', 'Pin_1', 'B-')
J6 | PPPC062LJBN-RC | PPPC_12:CONN_PPPC062LJBN-RC_SUL | PPPC062LJBN-RC
  ('7', '7', '3V3')
  ('11', '11', 'C-')
  ('1', '1', 'GND')
  ('4', '4', 'GND')
  ('10', '10', 'I2C_SCL')
  ('8', '8', 'I2C_SDA')
  ('5', '5', 'LED_SW')
  ('12', '12', 'P+')
  ('9', '9', 'UNUSED_GPIO_3')
  ('3', '3', 'UNUSED_GPIO_45')
  ('2', '2', 'UNUSED_GPIO_46')
  ('6', '6', 'W-')
J7 | Micro_SD_Card | microSD_dualsource:microSD_PushPush_TFPUSH-MEM2075 | https://www.we-online.com/components/products/datasheet/693072010801.pdf
  ('6', 'VSS', 'GND')
  ('9', 'SHIELD', 'GND')
  ('5', 'CLK', 'SD_CLK')
  ('3', 'CMD', 'SD_CMD')
  ('7', 'DAT0', 'SD_DAT0')
  ('8', 'DAT1', 'SD_DAT1')
  ('1', 'DAT2', 'SD_DAT2')
  ('2', 'DAT3/CD', 'SD_DAT3')
  ('4', 'VDD', 'SD_VDD')
L1 | 22u | srn3010C-100m:IND_SRN3010C-100M | ~
  ('2', '2', '3V3')
  ('1', '1', 'EINK_SW')
L2 | 4.7u | Inductor_SMD:L_1008_2520Metric_Pad1.43x2.20mm_HandSolder | ~
  ('1', '1', 'LDO_IN')
  ('2', '2', 'TPS_SW_NODE')
Q1 | FS8205A | Package_TO_SOT_SMD:SOT-23-6_Handsoldering | FS8205A
  ('1', '1', 'B-')
  ('3', '3', 'GND')
  ('4', '4', 'Net-(U5-OC)')
  ('6', '6', 'Net-(U5-OD)')
  ('2', '2', 'unconnected-(Q1-Pad2)')
  ('5', '5', 'unconnected-(Q1-Pad5)')
Q3 | AO3419 | Package_TO_SOT_SMD:SOT-23_Handsoldering | https://www.infineon.com/dgdl/irlml6402pbf.pdf?fileId=5546d462533600a401535668d5c2263c
  ('2', 'S', 'B+')
  ('3', 'D', 'Net-(Q3-D)')
  ('1', 'G', 'Net-(Q3-G)')
Q4 | BSS138 | Package_TO_SOT_SMD:SOT-23 | https://www.onsemi.com/pub/Collateral/BSS138-D.PDF
  ('1', 'G', '/GDR')
  ('2', 'S', '/RESE')
  ('3', 'D', 'EINK_SW')
Q5 | BSS138 | Package_TO_SOT_SMD:SOT-23 | https://www.onsemi.com/pub/Collateral/BSS138-D.PDF
  ('1', 'G', 'COLOR_SEL')
  ('2', 'S', 'Net-(Q5-S)')
  ('3', 'D', 'W-')
Q6 | BSS138 | Package_TO_SOT_SMD:SOT-23 | https://www.onsemi.com/pub/Collateral/BSS138-D.PDF
  ('1', 'G', '/COLOR_SEL_INV')
  ('3', 'D', 'C-')
  ('2', 'S', 'Net-(Q5-S)')
Q7 | AO3419 | Package_TO_SOT_SMD:SOT-23_Handsoldering | https://www.infineon.com/dgdl/irlml6402pbf.pdf?fileId=5546d462533600a401535668d5c2263c
  ('2', 'S', '3V3')
  ('1', 'G', 'Net-(Q7-G)')
  ('3', 'D', 'SD_VDD')
Q8 | AO3419 | Package_TO_SOT_SMD:SOT-23_Handsoldering | https://www.infineon.com/dgdl/irlml6402pbf.pdf?fileId=5546d462533600a401535668d5c2263c
  ('1', 'G', 'GND')
  ('3', 'D', 'Net-(Q8-D)')
  ('2', 'S', 'P+')
R1 | 1M | Resistor_SMD:R_0603_1608Metric_Pad0.98x0.95mm_HandSolder | ~
  ('1', '', 'GND')
  ('2', '', 'Net-(J1-SHIELD)')
R2 | 5.1k | Resistor_SMD:R_0603_1608Metric_Pad0.98x0.95mm_HandSolder | ~
  ('1', '', 'CC2')
  ('2', '', 'GND')
R3 | 5.1k | Resistor_SMD:R_0603_1608Metric_Pad0.98x0.95mm_HandSolder | ~
  ('1', '', 'CC1')
  ('2', '', 'GND')
R4 | 10k | Resistor_SMD:R_0603_1608Metric_Pad0.98x0.95mm_HandSolder | ~
  ('2', '', '3V3')
  ('1', '', 'BUTTON_ADC_1')
R5 | 10k | Resistor_SMD:R_0603_1608Metric_Pad0.98x0.95mm_HandSolder | ~
  ('2', '', '3V3')
  ('1', '', 'EPD_RST')
R6 | 4.7k | Resistor_SMD:R_0603_1608Metric_Pad0.98x0.95mm_HandSolder | ~
  ('2', '', 'GND')
  ('1', '', 'Net-(U11-PROG)')
R7 | 10k | Resistor_SMD:R_0603_1608Metric_Pad0.98x0.95mm_HandSolder | ~
  ('1', '', '3V3')
  ('2', '', 'ESP32_EN')
R8 | 10k | Resistor_SMD:R_0603_1608Metric_Pad0.98x0.95mm_HandSolder | ~
  ('1', '', 'SD_DAT0')
  ('2', '', 'SD_VDD')
R9 | 10k | Resistor_SMD:R_0603_1608Metric_Pad0.98x0.95mm_HandSolder | ~
  ('1', '', 'SD_DAT1')
  ('2', '', 'SD_VDD')
R10 | 1M | Resistor_SMD:R_0603_1608Metric_Pad0.98x0.95mm_HandSolder | ~
  ('1', '', 'BAT_MONIT')
  ('2', '', 'GND')
R11 | 12k | Resistor_SMD:R_0603_1608Metric_Pad0.98x0.95mm_HandSolder | ~
  ('2', '', 'BUTTON_ADC_2')
  ('1', '', 'Net-(R11-Pad1)')
R12 | 1M | Resistor_SMD:R_0603_1608Metric_Pad0.98x0.95mm_HandSolder | ~
  ('2', '', 'BAT_MONIT')
  ('1', '', 'P+')
R13 | 10k | Resistor_SMD:R_0603_1608Metric_Pad0.98x0.95mm_HandSolder | ~
  ('1', '', '3V3')
  ('2', '', 'ESP32_IO0')
R14 | 3 | Resistor_SMD:R_0603_1608Metric_Pad0.98x0.95mm_HandSolder | ~
  ('2', '', '/RESE')
  ('1', '', 'GND')
R15 | 10k | Resistor_SMD:R_0603_1608Metric_Pad0.98x0.95mm_HandSolder | ~
  ('2', '', '/GDR')
  ('1', '', 'GND')
R16 | 1k | Resistor_SMD:R_0603_1608Metric_Pad0.98x0.95mm_HandSolder | ~
  ('1', '', 'GND')
  ('2', '', 'Net-(U5-CS)')
R17 | 150k | Resistor_SMD:R_0603_1608Metric_Pad0.98x0.95mm_HandSolder | ~
  ('1', '', 'ST')
  ('2', '', 'USB_STAT')
R18 | 5.6k | Resistor_SMD:R_0603_1608Metric_Pad0.98x0.95mm_HandSolder | ~
  ('2', '', 'BUTTON_ADC_1')
  ('1', '', 'Net-(R18-Pad1)')
R19 | 20k | Resistor_SMD:R_0603_1608Metric_Pad0.98x0.95mm_HandSolder | ~
  ('2', '', 'BUTTON_ADC_1')
  ('1', '', 'Net-(R19-Pad1)')
R20 | 56k | Resistor_SMD:R_0603_1608Metric_Pad0.98x0.95mm_HandSolder | ~
  ('2', '', 'BUTTON_ADC_1')
  ('1', '', 'Net-(R20-Pad1)')
R21 | 33 | Resistor_SMD:R_0603_1608Metric_Pad0.98x0.95mm_HandSolder | ~
  ('1', '', 'Net-(U4-IO17)')
  ('2', '', 'SD_DAT2')
R22 | 33 | Resistor_SMD:R_0603_1608Metric_Pad0.98x0.95mm_HandSolder | ~
  ('1', '', 'Net-(U4-IO16)')
  ('2', '', 'SD_DAT3')
R23 | 33 | Resistor_SMD:R_0603_1608Metric_Pad0.98x0.95mm_HandSolder | ~
  ('1', '', 'Net-(U4-IO15)')
  ('2', '', 'SD_CMD')
R24 | 33 | Resistor_SMD:R_0603_1608Metric_Pad0.98x0.95mm_HandSolder | ~
  ('1', '', 'Net-(U4-IO7)')
  ('2', '', 'SD_CLK')
R25 | 33 | Resistor_SMD:R_0603_1608Metric_Pad0.98x0.95mm_HandSolder | ~
  ('1', '', 'Net-(U4-IO6)')
  ('2', '', 'SD_DAT0')
R26 | 33 | Resistor_SMD:R_0603_1608Metric_Pad0.98x0.95mm_HandSolder | ~
  ('1', '', 'Net-(U4-IO5)')
  ('2', '', 'SD_DAT1')
R27 | 0 | Resistor_SMD:R_0603_1608Metric_Pad0.98x0.95mm_HandSolder | ~
  ('2', '', 'Net-(Q3-D)')
  ('1', '', 'Net-(Q8-D)')
R28 | 10k | Resistor_SMD:R_0603_1608Metric_Pad0.98x0.95mm_HandSolder | ~
  ('2', '', '3V3')
  ('1', '', 'BUTTON_ADC_2')
R29 | 33 | Resistor_SMD:R_0603_1608Metric_Pad0.98x0.95mm_HandSolder | ~
  ('2', '', 'Net-(U4-IO12)')
  ('1', '', 'SPI_MOSI')
R30 | 33 | Resistor_SMD:R_0603_1608Metric_Pad0.98x0.95mm_HandSolder | ~
  ('2', '', 'Net-(U4-IO13)')
  ('1', '', 'SPI_SCK')
R31 | 33 | Resistor_SMD:R_0603_1608Metric_Pad0.98x0.95mm_HandSolder | ~
  ('1', '', 'EPD_CS')
  ('2', '', 'Net-(U4-IO14)')
R32 | 33 | Resistor_SMD:R_0603_1608Metric_Pad0.98x0.95mm_HandSolder | ~
  ('1', '', 'EPD_DC')
  ('2', '', 'Net-(U4-IO21)')
R33 | 33 | Resistor_SMD:R_0603_1608Metric_Pad0.98x0.95mm_HandSolder | ~
  ('1', '', 'EPD_RST')
  ('2', '', 'Net-(U4-IO47)')
R34 | 33 | Resistor_SMD:R_0603_1608Metric_Pad0.98x0.95mm_HandSolder | ~
  ('1', '', 'EPD_BUSY')
  ('2', '', 'Net-(U4-IO48)')
R35 | 33k | Resistor_SMD:R_0603_1608Metric_Pad0.98x0.95mm_HandSolder | ~
  ('2', '', 'BUTTON_ADC_2')
  ('1', '', 'Net-(R35-Pad1)')
R36 | 68k | Resistor_SMD:R_0603_1608Metric_Pad0.98x0.95mm_HandSolder | ~
  ('2', '', 'BUTTON_ADC_2')
  ('1', '', 'Net-(R36-Pad1)')
R37 | 13.3 | Resistor_SMD:R_0603_1608Metric_Pad0.98x0.95mm_HandSolder | ~
  ('2', '', 'GND')
  ('1', '', 'Net-(Q5-S)')
R38 | 300k | Resistor_SMD:R_0603_1608Metric_Pad0.98x0.95mm_HandSolder | ~
  ('2', '', '/PR1')
  ('1', '', 'USB_VBUS')
R39 | 1M | Resistor_SMD:R_0603_1608Metric_Pad0.98x0.95mm_HandSolder | ~
  ('2', '', 'LED_MONIT')
  ('1', '', 'LED_SW')
R40 | 100k | Resistor_SMD:R_0603_1608Metric_Pad0.98x0.95mm_HandSolder | ~
  ('2', '', '3V3')
  ('1', '', 'Net-(Q7-G)')
R41 | 120k | Resistor_SMD:R_0603_1608Metric_Pad0.98x0.95mm_HandSolder | ~
  ('2', '', 'GND')
  ('1', '', 'LED_MONIT')
R42 | 0 | Resistor_SMD:R_0603_1608Metric_Pad0.98x0.95mm_HandSolder | ~
  ('2', '', '/PIN_2')
  ('1', '', '3V3')
R43 | 0 | Resistor_SMD:R_0603_1608Metric_Pad0.98x0.95mm_HandSolder | ~
  ('2', '', '/PIN_2')
  ('1', '', 'TP_INT')
R44 | 0 | Resistor_SMD:R_0603_1608Metric_Pad0.98x0.95mm_HandSolder | ~
  ('2', '', '/PIN_4')
  ('1', '', 'TP_INT')
R45 | 0 | Resistor_SMD:R_0603_1608Metric_Pad0.98x0.95mm_HandSolder | ~
  ('2', '', '/PIN_5')
  ('1', '', 'I2C_SCL')
R46 | 0 | Resistor_SMD:R_0603_1608Metric_Pad0.98x0.95mm_HandSolder | ~
  ('2', '', '/PIN_5')
  ('1', '', 'I2C_SDA')
R47 | 2.2k | Resistor_SMD:R_0603_1608Metric_Pad0.98x0.95mm_HandSolder | ~
  ('1', '', '3V3')
  ('2', '', 'I2C_SCL')
R48 | 2.2k | Resistor_SMD:R_0603_1608Metric_Pad0.98x0.95mm_HandSolder | ~
  ('1', '', '3V3')
  ('2', '', 'I2C_SDA')
R49 | 1M | Resistor_SMD:R_0603_1608Metric_Pad0.98x0.95mm_HandSolder | ~
  ('1', '', 'C-')
  ('2', '', 'GND')
R50 | 1M | Resistor_SMD:R_0603_1608Metric_Pad0.98x0.95mm_HandSolder | ~
  ('2', '', 'GND')
  ('1', '', 'W-')
R51 | 100k | Resistor_SMD:R_0603_1608Metric_Pad0.98x0.95mm_HandSolder | ~
  ('1', '', '/PR1')
  ('2', '', 'GND')
R52 | 0 | Resistor_SMD:R_0603_1608Metric_Pad0.98x0.95mm_HandSolder | ~
  ('2', '', '/PIN_6')
  ('1', '', 'I2C_SCL')
R53 | 10k | Resistor_SMD:R_0603_1608Metric_Pad0.98x0.95mm_HandSolder | ~
  ('1', '', 'SD_DAT2')
  ('2', '', 'SD_VDD')
R54 | 10k | Resistor_SMD:R_0603_1608Metric_Pad0.98x0.95mm_HandSolder | ~
  ('1', '', 'SD_DAT3')
  ('2', '', 'SD_VDD')
R55 | 10k | Resistor_SMD:R_0603_1608Metric_Pad0.98x0.95mm_HandSolder | ~
  ('1', '', 'SD_CMD')
  ('2', '', 'SD_VDD')
R56 | 10k | Resistor_SMD:R_0603_1608Metric_Pad0.98x0.95mm_HandSolder | ~
  ('2', '', 'B-')
  ('1', '', 'Net-(Q3-G)')
R57 | 1M | Resistor_SMD:R_0603_1608Metric_Pad0.98x0.95mm_HandSolder | ~
  ('2', '', 'B+')
  ('1', '', 'Net-(Q3-G)')
R58 | 0 | Resistor_SMD:R_0603_1608Metric_Pad0.98x0.95mm_HandSolder | ~
  ('2', '', '/PIN_6')
  ('1', '', 'I2C_SDA')
R59 | 2k | Resistor_SMD:R_0603_1608Metric_Pad0.98x0.95mm_HandSolder | ~
  ('2', '', 'GND')
  ('1', '', 'Net-(D2-K)')
R60 | 100 | Resistor_SMD:R_0603_1608Metric_Pad0.98x0.95mm_HandSolder | ~
  ('2', '', 'BUTTON_ADC_1')
  ('1', '', 'Net-(R60-Pad1)')
R61 | 100 | Resistor_SMD:R_0603_1608Metric_Pad0.98x0.95mm_HandSolder | ~
  ('2', '', 'BUTTON_ADC_2')
  ('1', '', 'Net-(R61-Pad1)')
R62 | 10k | Resistor_SMD:R_0603_1608Metric_Pad0.98x0.95mm_HandSolder | ~
  ('1', '', 'Net-(R62-Pad1)')
  ('2', '', 'PWR_BUTTON')
R63 | 100 | Resistor_SMD:R_0603_1608Metric_Pad0.98x0.95mm_HandSolder | ~
  ('2', '', 'ESP32_EN')
  ('1', '', 'Net-(R63-Pad1)')
R64 | 100 | Resistor_SMD:R_0603_1608Metric_Pad0.98x0.95mm_HandSolder | ~
  ('2', '', 'ESP32_IO0')
  ('1', '', 'Net-(R64-Pad1)')
R65 | 33 | Resistor_SMD:R_0603_1608Metric_Pad0.98x0.95mm_HandSolder | ~
  ('1', '', 'Net-(U4-IO46)')
  ('2', '', 'UNUSED_GPIO_46')
R66 | 0 | Resistor_SMD:R_0603_1608Metric_Pad0.98x0.95mm_HandSolder | ~
  ('2', '', '/PIN_4')
  ('1', '', '3V3')
R67 | 56k | Resistor_SMD:R_0603_1608Metric_Pad0.98x0.95mm_HandSolder | ~
  ('1', '', 'CHRG')
  ('2', '', 'USB_STAT')
R68 | 33 | Resistor_SMD:R_0603_1608Metric_Pad0.98x0.95mm_HandSolder | ~
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

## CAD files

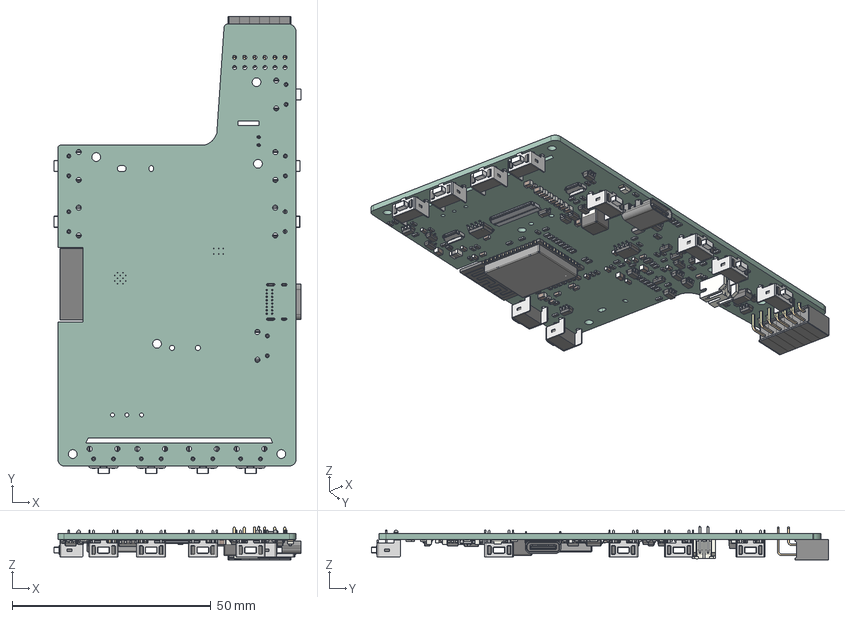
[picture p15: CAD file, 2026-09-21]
docs/mechanical/silkscreen_pcb.step
62.2 x 115.1 x 8.48 mm
C_0603_1608Metric x 23
R_0603_1608Metric x 76
C_0805_2012Metric x 13
SOT-23-6 x 7
PPPC022LJBN-RC_C06
Pin - Gold x 6
MJTP1117 x 10
SOT-583-8
SOT-23 x 8
Fuse_0805_2012Metric x 2
SOT-23-5 x 2
L_1008_2520Metric
D_SOD-323 x 2
D_SMF
ESP32-S3-WROOM-1
SOT-323_SC-70
sot563_body
sot563_pin x 6
JST_PH_S2B-PH-K_1x02_P2.00mm_Horizontal
SOIC-8-1EP_3.9x4.9mm_P1.27mm_EP2.29x3mm
R_0805_2012Metric
D_SOD-123 x 3
TF-SMD_TF-PUSH
USB_C_Receptacle_GCT_USB4085
LED_1206_3216Metric
FH34SRJ-24S-0.5SH
FH34SRJ-6S_ACTUATOROPEN.PRT x 2
L_APV_ANR5040
D_SMA
SOIC-8_3.9x4.9mm_P1.27mm
silkscreen_pcb_PCB

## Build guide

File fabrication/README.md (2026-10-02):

# Fabrication & assembly — Silkscreen (silkscreen_pcb)

Active assembly workflow: **JLCPCB**, using KiCad **9.0.6** and the **Fabrication Toolkit**
for placements. Board: 2 layers, 60 × 111 mm, 1.6 mm thickness, 1 oz copper.

**Read [DESIGN_REVIEW.md](../DESIGN_REVIEW.md) before releasing files.** It is the only
engineering verdict/action list. The pre-order audit is in
[`../docs/audit-2026-09-18/`](../docs/audit-2026-09-18/PREORDER_CONFIRMATION_AUDIT.md), the final review in
[`../docs/final-review-2026-09-19/`](../docs/final-review-2026-09-19/FINAL_REVIEW.md), and the audit of the Rev 1.0
order and of Rev 1.01 in [`../docs/audit-2026-09-30/`](../docs/audit-2026-09-30/AUDIT.md).
The current source (with the USB-present reverse-battery gate, L1 47 µH, R14 2.2 Ω and C9 4.7 µF)
has **185 references = 166 fitted + 11 DNP + 8 bare-copper** (H1–H6, TP1, TP2) as of 2026-10-01. The 2026-09-21 revision added
the `U14` RTC alternate (DNP), the `F2` PPTC on `J6` pin 12, `R83` + `C34` on the DW01A (VCC filter and CS filter), mounting hole `H6`, and rescaled the `USB_STAT` ladder (`R17`/`R67`/`R70`/`R71`/`C23`) and `R57` for sleep current. The files in `production/` were regenerated on 2026-09-21 after those changes, and that set (`aeb5b39`, 184 references, 165 fitted) is what I ordered as Rev 1.0. Rev 1.01 adds a 3V3 link and GND stitching vias below the cut line, one silkscreen word and the revision label (2026-09-30), then `R84` (1 Ω 0603 in series with `C2`'s ground leg, a USB hot-plug damper) and corrected JLC placement rows for seven parts (2026-10-01). The Gerber zip, BOM, placement and `netlist.ipc` were regenerated on 2026-10-01 after those changes (see the table below). Regenerate them again after any further schematic or PCB edit.
The two orders before Rev 1.0 (25 and 30 boards) predate the reverse-battery gate, the Q4/R37 changes and the
slotted microSD land; the Rev 1.0 order of 2026-09-21 (five boards, two assembled) has all of them.

The step-by-step JLCPCB upload flow and the optional/base part groups are in the root
[README](../README.md#order-an-assembled-board-step-by-step).
**JLCPCB is the only route that has produced working boards.** Other factories are supported in the sense that
their upload files are generated and kept current — `python fabrication/make_fab_files.py --split` writes a
PCBWay BOM + placement file, a NextPCB BOM + centroid and an assembly drawing into
[`production/other_fabs/`](../production/other_fabs/) (last regenerated 2026-10-01, 166 placed parts). My NextPCB attempt did not end in a
successful order and I have not tried PCBWay. What was learned from the NextPCB
Rev0 upload (DNP lines merged into fitted ones, through-hole previews, error list, cost) is in
[NEXTPCB_REV0_NOTES.md](NEXTPCB_REV0_NOTES.md). Which factory to use is the builder's choice; only the JLCPCB flow
has a known-good order behind it.

## Release records

Keep these together as one revision, including the accepted factory copies:

| Record | Local file | Meaning |
|---|---|---|
| Gerbers/drills | `production/Silkscreen_Reader_PCB_1.01.zip` | Toolkit output for Rev 1.01, regenerated 2026-10-01 after `R84` and small silkscreen, via and track moves (SHA-256 `5b819f118d68fdfb66f1a2b9730adf1a03a037deb35db2c6806597da54fc15bf`; the 2026-09-30 build, after the 3V3 link, the GND stitching vias and the revision label, was `b5dd45717a1f020ebb1ed955d8a57220b5b45561654b625995147a747c2d12c4`). Checked against the saved PCB the same day: DRC with schematic parity shows 0 unconnected items and 0 parity errors, every Gerber and both drill files match a fresh `kicad-cli` export as sets of shapes, six 2.2 mm mounting holes in the PTH drill file, 36 drawn paste regions for the FPC connectors, and `netlist.ipc` matches a fresh IPC-D-356 export. Re-verify after any board change |
| Rev 1.0 order | `aeb5b39` in git history (`production/Silkscreen_Reader_PCB_1.0.zip`, SHA-256 `e290d9f8c06ecd16648d669e4c9031dfae5897e00b27bb2fdbdec81dc83f471c`); the Toolkit run `production/backups/Silkscreen_Reader_PCB_1.0_2026-09-21_02-22-58.zip` — **local only** | The set ordered from JLCPCB on 2026-09-21, regenerated that day after the slot, QR code, `U14`, `F2`, `R83`, `C34`, `H6` and the `H5` move. Checked against the saved PCB: identical coordinate operations on `B.Cu`, `F.Cu`, `B.Mask`, `B.Paste`, `F.Silkscreen` and `Edge.Cuts` versus a fresh `kicad-cli` export, six 2.2 mm mounting holes in the PTH drill file, 36 drawn paste regions for the FPC connectors; re-checked in the 2026-09-30 audit |
| Placement | `production/positions.csv` | Toolkit CPL: 166 rows, all bottom side; `U14`, `SW6`, `TP3`–`TP5` and the DNP resistors are absent, and so are the bare-copper `TP1`/`TP2` and `H1`–`H6`. The rows for `U2`, `U5`, `D2`, `D8`, `J4`, `J7` and `U4` come out corrected for JLC's library footprints from the Toolkit offset fields (see the assembly checklist) |
| Factory BOM | `production/bom.csv` (+ `designators.csv`, `netlist.ipc`) | Toolkit BOM, populated from the footprints' `LCSC` field — 67 codes over 166 placements |
| Upload BOM | `production/jlc_bom.csv` | **The single BOM to upload** (called `bom_JLC_upload_v4_optimized.csv` until 2026-09-21; the older brand-conservative `..._v3.csv` was deleted the same day). Every part verified against JLC's library (see `BOM.md`); every fitted reference's value and part code cross-checked against the schematic and against the Toolkit's `bom.csv` on 2026-09-21, and against `bom.csv` again on 2026-10-01 after `R84` (`C22936`, Basic) was added. DNP parts are listed with an empty part number so JLC skips them |
| Matched order | `production/bom_JLC_upload-JLCPCB Assembly Order.xls` — **local only, not tracked in this repository** | Saved JLC selections from the 30-board order (pre-Fix 4); retain later approved changes too |

The Toolkit files are regenerated locally and are not the same thing as an accepted factory release: the saved
matched order is from September 14, and matching local files does not prove which revision, CAM edits, rotation edits
or substitutions JLC has accepted. Preserve approval emails and accepted assembly previews (including the D2
substitution) with the release record.

[`BOM.md`](BOM.md) is the current, netlist-derived bill of materials (the JLC standard build and the
hand-build/DigiKey list with its cost comparison). The old `BOM.csv` and `assembly/` exports from
September 12–13 were removed on 2026-09-18 because they described the pre-Fix 4 board.

## Part fields (MPN / Manufacturer / LCSC)

[`part_fields.csv`](part_fields.csv) maps every reference to its **prime part** (genuine manufacturer MPN — what a
hand-builder orders from DigiKey/Mouser) and its **LCSC code** (what JLCPCB actually places; same part where LCSC
stocks the original, otherwise the vetted equivalent — the last two columns say which). `J7` is the one deliberate
mismatch: prime = GCT MEM2075, LCSC = SHOU HAN TF PUSH, on the dual-source footprint.

```bash
python fabrication/apply_part_fields.py          # dry run: lists what would change, warns about drift
```
```bash
python fabrication/apply_part_fields.py --write  # apply — KiCad must be closed (the script checks the lock file)
```

The script writes only the `MPN`, `Manufacturer` and `LCSC` fields (hidden) and the DNP flag from the CSV's `DNP`
column; Value, Footprint and vendor fields are untouched, and re-running is a no-op. Afterwards open the schematic
and run **Update PCB from Schematic** with *Update footprint fields* ticked — the Fabrication Toolkit reads `LCSC`
from the footprints, so its `bom.csv` then carries the right part numbers without hand-editing. To change a part,
edit the CSV row and re-run. A fitted part with an MPN but an empty LCSC makes the Toolkit export the MPN as the
JLC part number; the dry run warns about that.

## Generated exports

Gerbers are generated artifacts; there is no requirement to commit them (`fabrication/gerbers/` and
`fabrication/*.zip` are gitignored). Preserve the actual accepted release archive somewhere durable, even if it
stays outside Git.

For a raw KiCad cross-check (not a replacement for the Toolkit set):

```bash
kicad-cli pcb export gerbers -o fabrication/gerbers/ \
  --layers F.Cu,B.Cu,F.Mask,B.Mask,F.SilkS,B.SilkS,F.Paste,B.Paste,Edge.Cuts \
  --no-protel-ext --subtract-soldermask silkscreen_pcb.kicad_pcb
kicad-cli pcb export drill -o fabrication/gerbers/ --format excellon \
  --drill-origin absolute --excellon-units mm --excellon-separate-th silkscreen_pcb.kicad_pcb
kicad-cli pcb export pos -o fabrication/gerbers/cpl_all.csv --format csv --units mm --side both silkscreen_pcb.kicad_pcb
```

Raw text diffs against the Toolkit's Gerbers are not meaningful (it adds attributes and uses a different slot
encoding); compare geometry (rasterize or use a viewer) instead.

## Assembly checklist

- Export the **final CPL through Fabrication Toolkit**, preserving its component-rotation corrections. A raw KiCad
  angle may differ from a JLC assembly angle. **Seven parts' rows did not match JLC's library footprints** (U2
  TPS2116 SOT-583 and U5 DW01A rotation, D8 SOT-323 rotation, D2 LED polarity, J4's footprint anchor 0.73 mm off its
  pad pattern, U4/J7 origin offsets). Since 2026-10-01 they carry Toolkit fields on both the schematic symbol and
  the footprint, so every Toolkit run writes the corrected rows: `FT Rotation Offset` -90 on U2, 90 on U5, 180 on
  D2 and D8; `FT Position Offset` `1.6,-5.3` on J7, `-0.73,0.218` on J4, `0,-3.664` on U4. D2's KiCad **pad 1 is
  the cathode**; JLC's pin 1 for it is the anode, hence its 180°. Still set JLC's **Confirm Parts Placement** to
  Yes and check these parts in the preview.
- Reconcile each BOM reference and exact manufacturer/MPN/LCSC code with the accepted order.
  Check the JLC preview for rotation, side and polarity; a matched code alone does not verify these.
- Confirm through-hole soldering for J1, J5, J6 and fitted buttons. They are not all SMT parts.
- Confirm J7's actual locating-peg fit and approved placement before assembly.
- The tongue neck is now a **single 5.30 × 1.10 mm slot** on `Edge.Cuts` (x 89.59–94.89, y 61.40–62.50), at or
  above JLC's 1.0 mm minimum routed slot, as is the 47.04 × 1.30 mm display-flex slot. The four 0.5 mm
  "perforation" polygons the earlier orders went through with are gone; no slot DFM note is expected now.
- Save the accepted files and substitutions together. Regenerate/review the complete set after **every** source
  change rather than mixing a new board with an old placement file (`production/positions.csv` older than the PCB
  is stale by definition).

## Population and origin

- Standard-build DNP: **TP3, TP4, TP5, R43, R45, R58, R66, R72, R74, SW6, U14** — flagged DNP in
  both the schematic and the PCB, so Toolkit exports agree with the BOM. U13 (DS3231MZ+TRL) is
  populated; `U14` (RV-8263-C7) is its DNP alternate — fit one or the other, never both. Keep unselected references in the order when useful for explicit population tracking.
- Holes H1–H6 and the bare test pads TP1/TP2 need no purchased components; TP3–TP5 are 1-pin header footprints,
  DNP in the standard build.
- Centroid uses the KiCad page origin (same as the gerbers); Y is negative (KiCad Y-up
  convention). Preserve a common origin and check the assembled overlay.
- Never populate both sides of mutually exclusive touch/button link options.

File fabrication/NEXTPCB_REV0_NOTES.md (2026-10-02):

# NextPCB "Rev0" assembly upload: findings (2026-09-19 / 20)

What happened when this board was uploaded to NextPCB's Rev0 PCBA flow, what was fixed on our side, what could not
be fixed, and what it cost. Nothing here was an accepted or paid order; it is a record of a quote and its preview.
Everything about NextPCB's behaviour comes from what their site returned for our files, not from their documentation
(which says very little about bottom-side parts). Where something is a guess it says so.

Files involved: `fabrication/make_fab_files.py`, `fabrication/nextpcb_substitutes.csv`, `production/other_fabs/`
(`nextpcb_bom.csv`, `nextpcb_centroid.csv`, `split/`). How to regenerate: `python fabrication/make_fab_files.py --split` (see the root README, "Using a different factory").

## 1. What Rev0 is, and the format it wants

- **Submit as is.** Unlike JLCPCB, there is no "we will fix it" review: you upload, look at the quote and the preview,
  and either accept or re-upload. Plan on getting the files right yourself.
- **BOM.** NextPCB's Rev0 sample (`Rev0_Bom.xls`): `Designator*, Quantity*, Manufacturer Part Number*, Manufacturer,
  Package/Footprint, Description, Procurement Type, Customer Note`. Our `nextpcb_bom.csv` (with an extra `S/N` column
  and the manufacturer/package in the note) was parsed fine.
- **Rev0 rules, from the sample's header:** customer-supplied parts are *not* accepted; matched parts are bought by
  default; **unmatched parts stay unpopulated**; `DNP` means do not populate.
- **Centroid.** NextPCB's sample (`Rev0_Centroid.csv`) is a plain **`.csv`, not a zip**: `Designator, Mid X, Mid Y,
  Layer, Rotation`, coordinates with an `mm` suffix (4 decimals), `Top`/`Bottom`, integer rotation, LF line ends, no
  BOM. (An earlier reading of their standard quote page suggested zip/xlsx only; the Rev0 flow takes the csv.)
- **BOM and centroid designators must match** or the upload fails with "Designators in the PnP file do not match those
  in the BOM file (Missing/Inconsistent)".
- The centroid numbers are just KiCad's own position export. A `.pos` exported from KiCad's menu was numerically
  identical to `nextpcb_centroid.csv` for all 162 fitted parts, so the export is not the problem.

## 2. Problems found and how they were handled

| Problem | Cause | Fix |
|---|---|---|
| Error listing `J1 J5 J6 SW1-SW5 SW7-SW11` | BOM had the 13 through-hole parts, our centroid was SMD-only | `nextpcb_centroid.csv` now covers every fitted BOM part (162 rows at the time of the upload; 165 as regenerated 2026-09-21; 166 since `R84` was added 2026-10-01) |
| **DNP parts came back fitted** | NextPCB's importer **merges lines that share an MPN and drops the `DNP` mark**. `R43 R45 R58 R66 R74` were merged into the fitted 0 Ω line and `R72` into the 10 k line. Fitting `R74` beside `R73` shorts 3V3 to GND; `R43/R66` and `R45/R58` would put 3V3/`TP_INT` on the same pin as `R42/R44` and short SDA to SCL | DNP parts are left **out** of the BOM entirely. After every upload, check the matched BOM for `R43 R45 R58 R66 R72 R74 SW6` |
| `L1`, `J6` and the switches unmatched | The prime MPNs were not in NextPCB's stock | `fabrication/nextpcb_substitutes.csv` swaps them **for NextPCB only**: `J6` CJT `A2541HWR-2x6P`, `SW*` ALPS `SKHLLAA010`, `L1` Sunltech `SLW5040S470MST`. The prime table and the PCBWay BOM keep the prime parts |
| Duplicate JLC part numbers (found in the same session) | `bom_JLC_upload_v4_optimized.csv` (now `jlc_bom.csv`) listed `C14663` and `C28323` on two lines each, so JLC left `C24 C31 C20` unmatched | Lines merged. (`bom_JLC_upload_v3.csv`, which had the same duplicates, was deleted 2026-09-21) |

**Matched-BOM check** (our upload vs NextPCB's matched result, after the fixes): all 162 designators present, none
extra, no DNP refs, every requested MPN matched as requested (no silent substitutions), quantities and 10-board
overage consistent, resistor/capacitor values and packages agree. Third-party brands attached to generic parts
(`U3` TLV75533PDBVR as "DYW" rather than TI, `U5` Slkor, `Q2/3/7/8` "BY", `CR1` HXY, `D3` JXND) are what their stock
offered; `U3` matters because the sleep-current budget assumes TI's ~25 µA.

**ALPS `SKHLLAA010` as a substitute:** ALPS drawing No. 3 gives the same land as the MJTP1117/TS365ZJ (2 x d1.3 holes
7 mm apart, 2 x d1.0 holes 5 mm apart, 2.5 mm offset). Differences: catalog depth 7.22 mm vs 6 mm for the TS365ZJ, and
0.98 N vs about 2.5 N. Check the stem clearance and the feel.

## 3. The placement preview

NextPCB's preview is a **view from the back** (mirrored left to right), which makes a correct placement look wrong.
Un-mirrored and compared with the real footprints:

- **SMD parts and most through-hole parts land correctly:** `U4` within 0.5 mm, `U11` 0.1 mm, `L1`, `J1`, `J2`,
  `J3/J4`, `U13`, `D2` and the four bottom switches within about 1 mm, `SW4/5/11` within about 2 mm (`SW10` looked
  correct on an enlarged crop; its body merges with `J6`'s in the image). So front/back handling is not the problem.
- **Wrong or missing:** `J6` (body drawn flipped, on the opposite side of its pins), `SW1` and `SW7` (body rotated
  90 degrees, pin 1 still on pad 1), `J5` (about 90 degrees, weakest evidence). `J7` and `U10` have no body because
  they are not in NextPCB's DFA library.
- Their tool appears to put a THT model's **pin 1 at the centroid**; KiCad's origin for `J5`, `J6` and the switches is
  pin 1, so X/Y are right and the errors are rotations.
- **Rotation experiments changed nothing.** Two test centroids that changed only those four rotations (+90/+180 and
  -90/+180) produced an identical preview. `SW1` and `SW4` have identical input (270 degrees) yet render differently,
  so the tool is not a simple function of our numbers. A diagnostic that moves `U4`, `SW1` and `J6` by several
  millimetres was prepared to tell "tool ignores THT coordinates" from "preview not refreshed"; its result was not
  recorded. Conclusion so far: do not spend more time tuning THT coordinates.

## 4. The DFA error list, and our reading

| # | NextPCB message | Our reading |
|---|---|---|
| 1 | SMT/THT interference | Probably a knock-on of the misplaced THT bodies |
| 2 | Pad edge clearance under 0.15 mm | The only real pad pairs under 0.2 mm are `J1`'s USB-C pins, 0.15 mm apart: the connector maker's land pattern. Confirm |
| 3 / 4 | SMT / THT pin count does not match pad count | Likely the switches: our land has 4 holes, the ALPS model 2 terminals plus snap-in legs. Could not reproduce |
| 5 | `J7`, `U10` not in the DFA library | Informational |
| 6 / 7 | Hole smaller than the square pin's diagonal; pin too short to protrude | Their model-based checks; could not reproduce and no part was identified |

Their "preview" for each item only highlights an area of the board, not the part.

## 5. Cost and recommendation

- NextPCB Rev0 quote for 10 boards including shipping: about **$296** (as quoted to us), with the through-hole parts
  bought separately.
- The 13 through-hole parts from DigiKey (list prices 2026-09-20): `J1` USB4085-GF-A $0.772, `J5` S2B-PH-K-S $0.099,
  `J6` PPPC062LJBN-RC $0.984, `SW` MJTP1117 $0.5102 at 100. For 10 boards that is about **$70** before shipping and
  tax; the actual DigiKey order for 12 boards was about $102.
- Total about **$400**: roughly the same as, and slightly under, JLCPCB's price with through-hole assembly included.
  The NextPCB route leaves 74 hand-soldered joints per board (about 800 for 10) and the unresolved DFA and
  sourcing questions above.

**Recommendation:** for a full build, use JLCPCB with through-hole included. Use NextPCB Rev0 only for an SMD-only
order: generate with `python fabrication/make_fab_files.py --split` and upload `split/nextpcb_bom_smd.csv` +
`split/nextpcb_centroid_smd.csv` (152 parts as of 2026-09-21, 153 since `R84` was added 2026-10-01; designators identical), and hand-solder the through-hole parts. Whether
NextPCB would ship the through-hole parts loose was not established; Rev0 has no field for "buy but do not solder".

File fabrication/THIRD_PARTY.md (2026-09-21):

# Third-party library files

The board **design** in this repository (schematic and PCB) is licensed **CERN-OHL-S-2.0**
(see [`../LICENSE`](../LICENSE)). A handful of component **library files** — symbols, footprints
and 3D models under `KiCad/9.0/3rdparty/` — were obtained from **SnapEDA**, **Ultra Librarian**
and **SamacSys / Component Search Engine**.

**What that means for licensing:**
- ✅ All three vendors permit *using* these parts in a design and distributing the resulting
  **board design under any license** — so the CERN-OHL-S license on this project is unaffected,
  and you may fabricate, use, sell and modify boards made from it.
- ⚠️ All three **restrict redistributing the raw model files** as a standalone, reusable PCB
  library. They are included here only for build convenience. **If you fork or redistribute this
  repo as a component library, re-download each part from its vendor** (links below).
- The board also builds without these files: symbols are cached in `silkscreen_pcb.kicad_sch`
  and footprints are embedded in `silkscreen_pcb.kicad_pcb`, so you can regenerate fab data even
  if the `3rdparty/` folder is absent.
- Manufacturer 3D STEP models (e.g. Hirose, TI) carry their own manufacturer terms.
- Everything else in the design uses **KiCad's standard libraries** (CC-BY-SA-4.0 with the
  library exception — freely redistributable).

## Vendored parts

| MPN | Ref(s) | Files provided | Source | Re-download |
|---|---|---|---|---|
| FH34SRJ-24S-0.5SH(50) | J2 | symbol, footprint, 3D | SnapEDA | https://www.snapeda.com/search/?q=FH34SRJ-24S-0.5SH |
| FH34SRJ-6S-0.5SH(50) | J3, J4 | symbol, footprint, 3D | SnapEDA | https://www.snapeda.com/search/?q=FH34SRJ-6S-0.5SH |
| PPPC062LJBN-RC | J6 | symbol, footprint | SnapEDA | https://www.snapeda.com/search/?q=PPPC062LJBN-RC |
| TPD4E1U06DBVR | U1, U6–U9 | symbol | SnapEDA | https://www.snapeda.com/search/?q=TPD4E1U06DBVR |
| TSD05CDYFR | CR1–CR3 (symbol only; CR1 is SMF6.5CA and CR2/CR3 use standard SOD-323 footprints) | symbol | SnapEDA | https://www.snapeda.com/search/?q=TSD05CDYFR |
| FS8205A | Q1 | symbol | Ultra Librarian | https://app.ultralibrarian.com/search?queryText=FS8205A |
| TPS923610DRLR | U10 | symbol, footprint | Ultra Librarian | https://app.ultralibrarian.com/search?queryText=TPS923610DRLR |
| MJTP1117 | SW1–SW5, SW7–SW11 (footprint) | footprint | SamacSys / Component Search Engine | https://componentsearchengine.com/search?term=MJTP1117 |
| RV-8263-C7 | U14 (DNP) | symbol (project-made) | derived from KiCad's stock `Timer_RTC:RV-3028-C7` symbol (KiCad libraries, CC-BY-SA-4.0 with the library exception), pins renamed for the RV-8263-C7; the footprint is KiCad-standard `Package_SON:MicroCrystal_C7_SON-8_1.5x3.2mm_P0.9mm` | n/a — edit `KiCad/9.0/3rdparty/RV-8263-C7/RV-8263-C7.kicad_sym` |
| microSD push-push (unified) | J7 | footprint (project-built), 3D model | GCT MEM2075 pad geometry + SHOU HAN TF PUSH DXF + FastEDA 3D (via Protoflow) | see note below |

Notes:
- `MJTP1117` contributes only the **footprint** (and 3D model); its symbol is KiCad standard
  (`Switch:SW_Push`). `SW6` uses a KiCad-standard MJTP1243 footprint. `L1` uses the KiCad-standard footprint
  `Inductor_SMD:L_APV_ANR5040` (and its standard 3D model), so no third-party inductor files are shipped.
- On 2026-09-18 unused vendored files were removed from the repository (the old `SRN3010C-100M` L1 footprint,
  the TSD05/TPD4E1U06/FS8205A footprints and 3D models, and the legacy KiCad-5 `MJTP1117` files) because nothing
  references them; re-download from the vendors above if you need them.
- `J1` (USB-C) and every passive/IC not listed above use **standard KiCad libraries** — no
  third-party terms apply.
- `J7`'s footprint `microSD_dualsource:microSD_PushPush_TFPUSH-MEM2075` is **project-built** in
  this repo (KiCad symbol is standard `Connector:Micro_SD_Card`). Its pad geometry was derived
  from GCT's official MEM2075 `.kicad_mod` and SHOU HAN's TF PUSH manufacturer DXF; the attached
  3D model (`TF-SMD_TF-PUSH.wrl`) is FastEDA-generated (obtained via Protoflow) and carries its
  generator's terms. The footprint is a dual-source land accepting either the SHOU HAN TF PUSH
  (LCSC C393941) or GCT MEM2075-00-140-01-A.
- `TPS923610DRLR`'s 3D model (`SOT563.STEP`) is the manufacturer's, added separately.

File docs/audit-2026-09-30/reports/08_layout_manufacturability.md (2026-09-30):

# Layout / DRC / Manufacturability audit (2026-09-30)

> Run on 2026-09-30 against the committed boards: Rev 1.0 = `aeb5b39` (as ordered), 1.01 = `3edd0c8`.
> Evidence paths (`A_trim/`, `C_fab/`, `layout/` ...) are under [`../evidence/`](../evidence/), a local-only pack (git-ignored).

Scope: Rev 1.0 (aeb5b39) and 1.01 (HEAD 3edd0c8). Work copies in evidence/layout.

## Findings (appended as confirmed)

### 1. DRC with schematic parity (kicad-cli 9.0.6, --severity-all, stored zone fills)

Copies: layout/v10 (git archive aeb5b39), layout/v101 (git archive 3edd0c8 = HEAD worktree modulo CRLF). .kicad_pro and .kicad_sch byte-identical between the two.

| | 1.0 (aeb5b39) | 1.01 (3edd0c8) |
|---|---|---|
| violations total | 102 | 104 |
| unconnected / parity | 0 / 0 | 0 / 0 |
| clearance, live (all J1 USB-C land pattern, 0.150 vs Power 0.200) | 11 | 12 |
| clearance, excluded (J3) | 3 | 3 |
| track_dangling, excluded (F.Cu button-row stubs) | 4 | 4 |
| track_dangling, live | 0 | 1 (3V3 B.Cu 0.1414 mm @101.001,64.900) |
| starved_thermal (warn) | 25 | 25 |
| silk_edge_clearance (warn) | 33 | 33 |
| silk_over_copper (warn) | 15 | 15 |
| silk_overlap (warn) | 10 | 10 |
| mirrored_text_on_front_layer (warn; empty text box @83.9,61.6) | 1 | 1 |

- Only-in-1.01: the 3V3 stub. J1 pair sets differ between runs (1.0 run: A1-A4 x2, A4-A5, A8-A9, A9-A12, B1-B4, B4-B5 x2, B8-B9, B9-B12 x2); J1 footprint is unchanged -> run-to-run DRC reporting variance, not a layout change. Actual 0.150 mm > JLC 0.127 mm, so fab-OK.
- Because the reported J1 pairs vary run to run, position/UUID exclusions cannot make this deterministic. A one-line custom rule would: `(rule J1_landpattern (condition "A.Parent == 'J1' && B.Parent == 'J1'") (constraint clearance (min 0.15mm)))` in silkscreen_pcb.kicad_dru.
- The 7 .kicad_pro exclusions, all still matching the same UUIDs in both revs:
  - 3 x clearance, J3 pads 1-2, 4-5, 5-6 (SW netclass 0.25 vs 0.20 actual; 0.5 mm-pitch FPC land pattern): STILL JUSTIFIED. 0.20 mm is inherent to the connector and above JLC 0.127.
  - 4 x track_dangling F.Cu, Net-(R20/R19/R18/R60-Pad1) @ y 144-145.5 (bottom button row): STILL JUSTIFIED. These are the intentional front-button tab stubs ending in 0.6 x 0.6 mm F.Mask windows (prior review FAB-07 / HMI-13 / LAY-07). Geometry identical in 1.0 and 1.01.

Non-excluded warnings by class (identical in both revs): starved_thermal 25 (U2.1, U3.2, U11.1, U6/U7/U9 pad 2, C3/C4/C21/C25/C27/C29/C37, R37/R41/R50, J7.6, J7.9 x2, J2.17, J6.4, D3.2, J1.A1 on F.Cu; SW4.1 and SW9.1 spoke to an isolated island; none is a power-path pad); silk_edge_clearance 33 (switch/J1/J6/U4 outlines over the edge, cut-line text boxes, dev-header label, F.Silk polygons at J7 pegs); silk_over_copper 15 (designators R8/CR2/CR3/R38/R83/C34, 3 J2 outline segments, 3 F.Silk polygons at J7 pegs, 3 F.Silk text boxes); silk_overlap 10 (designator/outline and text-box overlaps); mirrored_text_on_front_layer 1 (empty text box). Courtyard overlaps: 0 (check enabled as error).

### 1.0 vs 1.01 plotted-output diff (fresh kicad-cli gerbers + drill, same options)
- B.Silk, F/B.Mask, F/B.Paste, Edge.Cuts, NPTH drill: identical. PTH drill: 1 via moved.
- F.Cu changes only in x 84.3-100.3, y 64.5-67.4; B.Cu only in x 82.5-101.1, y 63.9-68.1.
- F.Silkscreen changes only in x 52.8-94.0, y 82.3-85.1 (the reworded front text line). QR codes (y 132-140) untouched; the 4 LOGO/QR footprint blocks are byte-identical 1.0 vs 1.01. No QR decoder is installed here (no cv2/pyzbar/jsQR), so the 2026-09-21 decode carries over by identity.

### 2. Manufacturability minima (measured; probe DRC with raised custom rules + pcbnew scan; both revs identical)
| item | actual min | where | JLC std 2-layer |
|---|---|---|---|
| track width | 0.200 mm | many | 0.127 OK |
| copper clearance | 0.150 mm | J1 pads, Default-class items | 0.127 OK |
| copper to board edge | 0.475 mm | GND via (82.52,67.80) vs cut-line arc | 0.2-0.3 OK |
| via | 0.6/0.3 mm x192, annular 0.150 | all vias | standard OK |
| copper to hole | 0.300 mm | track vs via hole (Q9-G via) | 0.254 OK |
| hole to hole (wall) | 0.450 mm | J1 pins; GND via (84.32,89.68) vs CHRG via (85.00,90.00) | ~0.45-0.5, at limit (accepted FAB-01) |
| PTH drill | 0.200 mm x18 | U4 EP (12) and U11 EP (6) thermal vias | below 0.3 std via drill; JLC min 0.15 (may carry small-hole fee) |
| PTH annular | 0.150 mm | J1 16 pins + shell slots | below JLC 0.18 guidance; accepted FAB-01 |
| plated slot | 0.60 mm | J1 shell | OK |
| NPTH | 1.05 x 1.5 slot | J7 | 1.0 OK |
| routed cut-outs | 1.30 / 1.10 mm (centre line) | flex slot / cut-line slot | 1.0 OK on centre line; both drawn with 0.20 mm stroke (inner edge 1.10 / 0.90) |
| silk line | 0.10 mm (40 B.Silk), mostly 0.12 | footprint outlines | 0.153 recommended |
| silk text | 0.40-0.50 mm high / 0.10 stroke (191 of 231 texts) | designators, pin labels | 1.0/0.153 recommended; accepted FAB-02 |

### 3. Layout sanity
- Power path widths: VBUS_PRE_FUSE 0.40; USB_VBUS 0.25-0.40; P+ 0.40 (one 0.25 seg); /P+_FUSE, B+, B- 0.40; LDO_IN 0.25; 3V3 0.25 (18 vias). 1 oz outer: 0.25 mm ~0.87 A, 0.40 mm ~1.2 A at 10 C rise (IPC-2221) vs <=0.5 A USB, ~0.25 A charge. OK. GND pour: thermal, 0.5 mm gap / 0.5 mm spokes; no power-path GND pad is starved.
- Antenna (U4 WROOM-1, rot -90, B side): antenna zone x 44.70 to ~50.7, y 93.45-111.55; board notch x 44.24-50.59, y 93.3-112.0 removes all board under it; nearest pour starts x ~51.06 on both layers (edge clearance 0.475). No copper under the antenna. Note the U4 footprint keepout bans tracks/vias/pads but has (copperpour allowed): the notch, not the keepout, keeps the pour out.
- USB: DP 45.76 mm (3 vias), DN 46.24 mm (1 via), 0.20 mm, edge gap >=0.26 mm, <=0.5 mm gap over 59% of length. Fine for ESP32-S3 full-speed USB.
- FPCs: J2/J3/J4 are FH34SRJ (top and bottom contact), so the fold through the slot cannot present the wrong contact face. J2 pin 1 proven (EPD-02 refuted); J3 mapping rests on the owner-verified light-strip flex (LED-12, known); J4 pinout documented (08). Not touched by 1.01.
- Battery legend: B.Silk "-  +  CHECK" (1.0 mm TrueType) at x 85.5-88.0: '+' glyph centre y 65.63 beside J5 pad 2 = B+ (y 65.5), '-' glyph y 67.68 beside pad 1 = B- (y 67.5). Correct.

### 5. Fab-order facts
Board: 2 copper layers, 1.6 mm, no (stackup) block, so finish, copper weight and mask colour are not in the board. README/fabrication README: 1 oz outer copper, 1.6 mm; finish and mask colour "your choice". Vias tented both sides, mask expansion 0, min web 0. Title block (both revs, and schematic identical): "Silkscreen Reader PCB", rev 1.0, 2026-09-12, idc LLC, CERN-OHL-S-2.0, github.com/iandchasse/silkscreen-pcb. No revision text on either silkscreen layer.

## Findings
- [FIX-NOW] (1.01) Revision still labelled 1.0: title block rev 1.0 / 2026-09-12 in HEAD pcb and sch, production zip still Silkscreen_Reader_PCB_1.0.zip, no rev text on silk; only a reworded front-text word tells boards apart. Fix: rev 1.01 + date, rename zip, add small "v1.01" silk text.
- [FIX-NOW] (1.01) Known 3V3 dangling stub 0.141 mm @(101.001,64.9): only new live DRC item; snap/delete the 1 um stub or exclude.
- [FIX-NEXT-REV] (1.0/1.01) Six tented vias inside the four F.Silk QR codes: (47.50,135.60) (50.90,134.70) (54.14,133.60) in QR x47.4-55.3; (68.38,133.22) in QR x68.3-76.1; (81.70,133.62) in QR x78.3-86.1; (94.30,137.20) in QR x88.3-96.1. (54.14,133.60) sits on the top-right finder's lower edge, (68.38,133.22) on the top-left finder's left edge, (81.70,133.62) on the timing row. Plotted-silk decode cannot see drill holes. Each 0.3 mm hole ~1 module (0.271 mm); EC-L should absorb it. Scan the first boards with a phone; next rev move these vias out of the QR areas.
- [FIX-NEXT-REV] (1.0/1.01) Both internal cut-outs are Edge.Cuts polygons with a 0.20 mm stroke (rest of outline 0.05): cut-line slot 5.30 x 1.10 centre line = 0.90 mm inner edge. Centre-line routing and the accepted 1.0 order make this fine; redraw at 0.05 mm (AUTHOR_TODO item 2).
- [NOTE] (1.0/1.01) J1 clearance items cannot be pinned by .kicad_pro exclusions (pairs change run to run); a .kicad_dru rule would: (rule J1_landpattern (condition "A.memberOfFootprint('J1') && B.memberOfFootprint('J1')") (constraint clearance (min 0.15mm))).
- [NOTE] (1.0/1.01) U4 keepout allows copper pour; add copperpour not_allowed as a guard in case the notch ever changes.
- [NOTE] (1.0/1.01) 18 x 0.2 mm drills (U4/U11 EP thermal vias) are below the 0.3 mm standard 2-layer via drill; JLC builds them (min 0.15) but they may carry a small-hole charge on the 1.01 quote.
- UPDATE to the QR/via finding (qrvia.py, ink under each 0.3 mm hole intersected with the QR's own F.Silk polygons): 3V3 (81.70,133.62) 0.85 module; GND (94.30,137.20) 0.29; 3V3 (50.90,134.70) 0.61; 3V3 (47.50,135.60) 0.38; LED_SW (54.14,133.60) 0.89; I2C_SCL (68.38,133.22) 0.87. At most ~1.9 module-equivalents per code (the x47-55 code), far inside EC-L's 7-codeword margin, and no finder loses more than one module. Severity lowered to NOTE: expected to scan; move the vias only if a rev touches that area anyway.

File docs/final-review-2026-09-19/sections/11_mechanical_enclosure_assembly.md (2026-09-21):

# Physical layout, enclosure design constraints, cable/wire routing and assembly

*Final review 2026-09-19 — reviewer key `mech`, finding IDs `MEC-nn`.
Every dimension here comes from `silkscreen_pcb.kicad_pcb` (read with `pcbnew`) or from
`evidence/pcb/board_extract.json`, or from a manufacturer datasheet cited at the end. Nothing is measured off
an image. Board coordinates are KiCad mm with **Y growing downward**. To keep the numbers readable I also use
**board-local coordinates** `X = x − 44.2375`, `Y = y − 37.000`, so the board occupies X 0 … 60.00 mm,
Y 0 … 111.25 mm.*

---

## What this part of the board does

This is not a schematic block — it is the *product* view. If you hold the finished thing in your hand: where
is everything, what sticks out, what has to be plugged in, and what does the person designing the plastic
case have to work around?

The physical concept, reconstructed from the board geometry and then confirmed against the board's own
silkscreen notes and the project docs:

* The PCB is **60.00 × 111.25 mm, 1.6 mm thick, 2 layers**, and **175 of its 183 footprints are on the
  BOTTOM side**. The top face is almost bare and carries artwork.
* A **4.26 inch e-paper panel (GDEQ0426T82-FT01C, 105.33 × 62.37 × 1.98 mm)** lies flat on the **TOP** face.
  It is *wider than the PCB* (62.37 vs 60.00 mm), so it is retained by the case, not by the board.
* The panel's three flat flexible cables ("flexes"/FPCs — thin printed-plastic ribbons) drop through a
  **47.04 × 1.30 mm routed slot** near the bottom edge, fold back under the board, and plug into
  **J2 / J3 / J4 on the BOTTOM face**.
* The board is not a rectangle. It has (1) a **narrow tab** up the right-hand side carrying the expansion
  header, power button and battery connector, which leaves (2) a **large open pocket** beside it — and
  `docs/HARDWARE.md` §15 confirms that pocket is the battery bay ("the battery now sits in a cut-out *in*
  the PCB rather than stacked on top") — and (3) a **rectangular bite out of the left edge** which is the
  ESP32 antenna keep-out.
* User input is **ten side-actuated tactile switches** whose plungers poke out past the board edge: four
  along the bottom edge (the row under the screen), two on the left edge, three on the right edge, plus a
  recessed reset.

Jargon, once:
* **FPC / flex** — flat flexible printed cable, the ribbon that comes off an e-paper panel.
* **Courtyard** — KiCad's "keep other parts out of here" outline. Usually bigger than the part.
* **B.Fab** — KiCad's mechanical drawing of the part body on the bottom side. I use it as the in-file
  estimate of real body extent and I say so each time; where a datasheet lets me correct it, I do.
* **THT** — through-hole; **SMD** — surface mount; **DNP** — "do not populate".

---

## Circuit walk-through — the mechanical bill of materials

Only parts with a mechanical consequence. "Checked against datasheet?" refers to *height / outline /
actuation*, not electrical behaviour (other reviewers own that).

| Ref | Part / value | Role | Checked against datasheet? |
|---|---|---|---|
| J1 | GCT **USB4085** USB-C receptacle, THT/SMD hybrid, top-mount | Charge + flash, right edge | Yes — profile height 3.46 mm |
| J2 | Hirose **FH34SRJ-24S-0.5SH** | 24-pin panel flex, 0.5 mm pitch | Yes — 1.00 mm high, back-flip lock |
| J3 | Hirose **FH34SRJ-6S-0.5SH** | 6-pin **front-light** flex (silk C+/C−/NC/NC/W+/W−) | Yes |
| J4 | Hirose **FH34SRJ-6S-0.5SH** | 6-pin **touch** flex (silk GND/VDD/RST/INT/SDA/SCL) | Yes |
| J5 | JST **S2B-PH-K-S**, 2-pos 2.00 mm, **side entry** | LiPo battery | Partly — mouth direction resolved from the KiCad footprint + 3D render; JST PDF would not parse |
| J6 | Sullins **PPPC062LJBN-RC**, 2×6 0.1 in, **right-angle** socket | Expansion / "Development Header" | Partly — orientation confirmed from the 3D model; body height not verified |
| J7 | **TF-PUSH / MEM2075** microSD push-push | SD card | No — dual-source footprint, see MEC-15 |
| U4 | Espressif **ESP32-S3-WROOM-1** | MCU module, 18.0 × 25.5 × 3.1 mm | Yes |
| SW1, SW4, SW10 | APEM **MJTP1117** right-angle tactile | Right edge: DWN1, UP1, PWR | **Yes — full drawing** |
| SW5, SW7 | APEM **MJTP1117** | Left edge: DWN2, UP2 | Yes |
| SW2, SW3, SW8, SW9 | APEM **MJTP1117** (alt land: MJTP1243) | Bottom edge: RIGHT, LEFT, OK, BACK | Yes |
| SW11 | APEM **MJTP1117** | **RESET** (ESP32_EN via R63) — recessed, see MEC-09 | Yes |
| SW6 | APEM **MJTP1243** 6 × 3.5 × H4.3, vertical | **BOOT** (ESP32_IO0 via R64) — **`dnp`** | Yes |
| H1–H5 | M2 holes, 2.2 mm drill, 2.6 mm pad, 3.8 mm annulus, GND-plated | Screw bosses | n/a — geometry from file |
| D2 | 1206 LED (LTST-C150KRKT) | USB-present indicator, 0.59 mm from the right edge | n/a |
| L1 | APV **ANR5040** shielded inductor, 5.0 × 4.0 mm | EPD boost | No — height not verified |
| TP3/TP4/TP5 | 2.54 mm pin-header land, **TOP side, `dnp`** | Spare front-light outputs `LED+`/`C−`/`W−` *under the panel* | n/a |

---

## Where it is on the board & layout notes

### The outline, feature by feature

All coordinates are `Edge.Cuts` **centrelines** straight out of the board file.

| Feature | KiCad mm | Board-local (X, Y) | Size |
|---|---|---|---|
| Top edge | y = 37.000, x 86.96 → 102.56 | Y = 0, X 42.73 → 58.32 | only 15.6 mm long |
| Right edge | x = 104.2375, y 39.0 → 146.5 | X = 60.00, full height | 107.5 mm |
| Bottom edge | y = 148.25, x 45.80 → 102.49 | Y = 111.25 | 56.7 mm |
| Left edge (upper) | x = 44.2375, y 68.5 → 93.3 | X = 0, Y 31.5 → 56.3 | 24.8 mm |
| Left edge (lower) | x = 44.28, y 112.0 → 146.73 | X ≈ 0.04, Y 75.0 → 109.7 | 34.7 mm |
| **Antenna notch** | x 44.2375 → 50.59, y 93.30 → 112.00 | X 0 → 6.35, Y 56.3 → 75.0 | **6.35 deep × 18.70 tall** |
| Main-body top edge | y = 67.5, x 44.99 → 81.24 | Y = 30.5, X 0.75 → 37.0 | 36.25 mm |
| Diagonal (pocket wall) | (84.2375, 64.5) → (86.0546, 37.957) | (40.00, 27.50) → (41.82, 0.96) | 26.6 mm, ~3.9° off vertical |
| Fillet, body → diagonal | arc r = 4.43, centre (79.99, 63.25) | — | generous, good |
| Corner radii | TR 2.01 · BR 1.75 · BL 1.50 · TL 0.75 mm | — | inconsistent, MEC-18 |
| **Flex slot** | x 51.26 → 98.30, y 141.20 → 142.50 | X 7.02 → 54.06, Y 104.2 → 105.5 | **47.04 × 1.30 mm** |
| **Cut-line slots ×4** | y 61.60 → 62.12; x 86.62–87.95, 90.09–91.92, 94.15–96.67, 99.29–101.12 | Y 24.6 → 25.1 | each **0.516 mm** wide |

In plain terms the board is **a 60 × 80.75 mm rectangle (Y 30.5 … 111.25)** with

1. a **19–20 mm wide tab** running up the right side to the top (Y 0 … 30.5),
2. a **~38.8 × 30.5 mm open pocket** left of that tab — no PCB at all — which is the battery bay,
3. a **6.35 × 18.70 mm bite** out of the left edge at the ESP32 antenna, and
4. a **47 mm slot** 5.75 mm up from the bottom edge for the display flexes.

### ASCII map — viewed from the TOP (the display side); all parts are on the far side

```
  X=0                     20                    40                 60 (mm)
  +------------------------------------------------------------------+
Y=0                              :  BATTERY BAY   :  +--------------+   <- top edge only 15.6 mm long
  :          (NO PCB HERE)                           |  J6 2x6      |  J6 body overhangs the top
  :        38.75 x 30.50 mm usable                   |  RIGHT-ANGLE |  edge by 1.69 mm; mouth
  :                                                  |  mouth -> -Y |  faces OUT of the top edge
 10                                                  +--------------+
  :                                                  | H1 M2        |
  :                                 diagonal wall -> \  SW10 PWR  ]=>  +1.01 mm past right edge
 20                                                   \ U8 D8 CR3   |
  :                                                    \ D3 CR2     |
  :   . . . . . . . . . . . . . . . . . . . . . . . . . - -  - -  - |  <- CUT LINE, 4 slots, Y 24.6-25.1
 25                                                      \          |     12 live nets thread the webs
  :                                                       \ J5 <==] |  JST-PH: MOUTH FACES +X (right!)
 30 +--------------------------------------------------------+-----+   <- main body top edge Y=30.5
  : | H2                                         H5(TOP) SW4 UP1 ]=>|   +0.99 mm
  : |                                                              |
 40 | [ SW7 UP2                     microSD J7                     |
  :<=]  +0.99 mm      (card exits to the LEFT)  ^^^^^^^^           |
  : |                                                   SW1 DWN1]=>|   +0.95 mm
 50 | [ SW5 DWN2                                                   |
  :<=]                                                             |
  : +------+  <- ANTENNA NOTCH  X 0..6.35, Y 56.3..75.0            |
 60 |      |      ESP32-S3-WROOM-1; antenna end cantilevered here  |
  : |      |      module body X 0.46..26.06, Y 56.45..74.55        |
 70 |      |                                             J1 USB-C  |
  : +------+                                             [====] -> |   mating face +1.25 mm past edge
 75 |                                                              |
  : |                                      SW11 RESET ]   D2 LED   |   SW11 stops 3.54 mm SHORT
 80 |   TP1 TP2      L1 boost    SW6 BOOT (dnp, internal)          |   D2 is 0.59 mm from the edge
  : |                                                              |
 90 |  TP3 TP4 TP5 (TOP side, dnp)    4x LOGO / QR (TOP side)      |
  : |                                                              |
100 |   J3 front-light      J2 panel 24p           J4 touch        |   <- all three mouths face +Y,
  : |   [======]          [==============]       [======]          |      i.e. toward the slot. Good.
105 |  ==========================================================  |   <- FLEX SLOT  Y 104.2..105.5
  : |  H3 o                                                 o H4   |
110 |  [SW9 BACK]   [SW8 OK]    [SW3 LEFT]    [SW2 RIGHT]           |
  +------v-----------v------------v-------------v-----------------+
         plungers protrude 1.95 mm BELOW the bottom edge
```

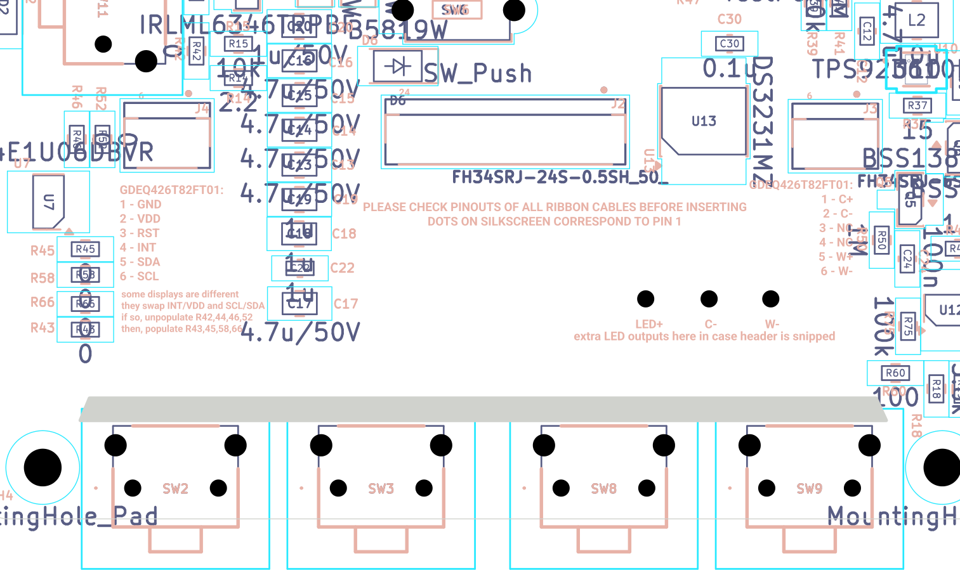
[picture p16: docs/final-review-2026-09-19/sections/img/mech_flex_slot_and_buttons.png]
Flex slot, FPC connectors and the bottom button row

*Bottom-side assembly view, x 47 … 103, y 118 … 152 mm (mirrored, i.e. as seen looking at the back of the
board). The long horizontal gap is the 47.04 × 1.30 mm flex slot; J3, J2 and J4 sit above it, the four
bottom buttons below it.*

### Overhang table — everything that sticks out past the board outline

MJTP1117 numbers are corrected using the APEM drawing: the real part is **7.40 mm** along the actuation axis
and **7.30 mm** across, against a `B.Fab` of 7.45 × 7.40, so the plunger tip is **0.025 mm inside `B.Fab`**.
(Cross-checking the drawing's lead positions against the footprint's pads leaves a residual ±0.20 mm, so
treat these as ±0.2 mm.)

| Ref | Edge | Plunger / mating face past the edge | Courtyard past the edge |
|---|---|---|---|
| SW2, SW3, SW8, SW9 | bottom (y 148.25) | **+1.95 mm** | +2.97 mm |
| SW10 (PWR) | right (x 104.2375) | **+1.21 mm** | +2.24 mm |
| SW4 (UP1) | right | **+0.99 mm** | +2.02 mm |
| SW1 (DWN1) | right | **+0.95 mm** | +1.97 mm |
| SW5, SW7 (DWN2, UP2) | left (x 44.2375) | **+1.00 mm** | +2.02 mm |
| **SW11 (RESET)** | right | **−3.54 mm — recessed** | −2.51 mm |
| J1 USB-C | right | **+1.25 mm** (`B.Fab` to x 105.485) | +1.72 mm |
| J6 | **top** (y 37.000) | **−1.69 mm, i.e. body overhangs above the edge** | −2.01 mm |
| J7 microSD | left | 0 (socket mouth at x 56.125; the card itself overhangs) | 0 |

The ten MJTP1117s **do not protrude by the same amount**: bottom row +1.95 mm, side buttons +0.95 … +1.21 mm.
That is a 1.0 mm spread across groups (**MEC-08**).

### The display stack-up and the flex path

The panel is 105.33 mm long. Align its glass bottom edge with the **far edge of the flex slot (y = 142.50)**
and its top edge lands at 142.50 − 105.33 = **37.17 mm**, i.e. **0.17 mm inside the board's top edge at
y = 37.000**. Agreement to under two tenths of a millimetre is not coincidence — the board length was
dimensioned for this panel with the slot as the datum. Consequences:

* the panel covers the **entire** top face from Y 0.17 to Y 105.5, and
* the strip below the slot, **Y 105.5 → 111.25 = 5.75 mm**, is the visible bezel carrying the four bottom
  buttons and their `LEFT / OK / BACK / RIGHT` silkscreen. That works.

The panel is **62.37 mm wide against a 60.00 mm board** — it overhangs **1.185 mm on each side**.

Flex geometry, from the FT01C drawing and the board file:

| Flex | Approx. width | Tail centre on the panel (from its left datum) | Board connector | Pad-row centre |
|---|---|---|---|---|
| Front light (6 pin) | ~4 mm | 11.76 mm | **J3** | x 54.24 |
| Panel (24 pin) | ~12.5 mm | 31.11 mm | **J2** | x 73.49 |
| Touch (6 pin) | ~4 mm | 49.33 mm | **J4** | x 92.50 |

Panel tail pitch **FL→MAIN 19.35 mm**, **MAIN→CTP 18.22 mm**.
Board connector pitch **J3→J2 19.25 mm**, **J2→J4 19.74 mm**.
Front-light spacing matches to **0.10 mm** (excellent); the touch spacing is **1.51 mm wider on the board
than on the panel** (**MEC-05**). The three tails span ~43 mm and the slot is 47.04 mm wide (X 7.02 … 54.06),
centred at x 74.78 against a board centre of 74.2375 — 0.54 mm off-centre, biased the helpful way.

**Mouth direction — checked and correct.** All three connectors are `rot 180`, and the FH34SRJ is a
back-flip-lock type: the flip lever and the contact solder tails are at the *back*, the FPC enters at the
*front*, over the two metal hold-down tabs. On this board the contact pads are at y = 124.3 (back) and the
hold-down pads at y = 127.0 (front), so **all three mouths face +Y, toward the slot**. I confirmed this in
the ray-traced 3D model: the open mouth and the end tabs are on the +Y long face.

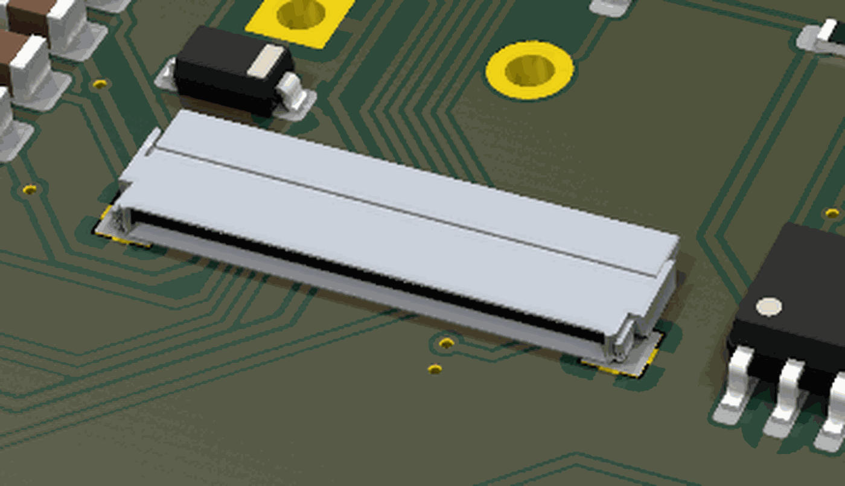
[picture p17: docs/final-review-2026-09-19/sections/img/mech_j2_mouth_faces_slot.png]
J2's mouth faces the flex slot

*J2 in the 3D render. In this view image-right is board −x and image-down is board +y (established from H1 vs
H5 and U8 vs H1). The dark open mouth and both end tabs are on the lower-left long face = board +Y = the
slot side.*

Slot-to-connector run on the bottom face:

| | J3 (front light) | J2 (panel) | J4 (touch) |
|---|---|---|---|
| Connector far edge (`B.Fab` max y) | 127.864 | 127.614 | 127.820 |
| Slot near edge (y) | 141.200 | 141.200 | 141.200 |
| **Free run** | **13.34 mm** | **13.59 mm** | **13.38 mm** |

### Where the battery goes, and the problem with J5

There is no PCB at all in **x 44.24 … 82.99, y 37.00 … 67.50** — bounded right by the diagonal wall, below by
the main-body top edge. Usable rectangle **38.75 × 30.50 mm**, open through the full depth of the case.
`docs/HARDWARE.md` §15 names this as the battery location.

**But J5 faces the wrong way.** I resolved its orientation two independent ways:

1. *From the footprint.* KiCad's `JST_PH_S2B-PH-K_1x02_P2.00mm_Horizontal` draws its `F.Fab` body over local
   x −1.95 … 3.95, y −1.35 … 6.25, with a 4.5 × 1.6 mm recess (the shroud mouth) in the **local −y** face.
   On this board J5 is at (94.850, 67.500) `rot 90`, flipped, with pad 1 (B−) at y 67.5 and pad 2 (B+) at
   y 65.5. That fixes the transform as local +x → board −y and **local +y → board −x** (a reflection, as it
   must be for a bottom-side part), which puts the mouth recess at **board x 94.60 … 96.20, opening toward
   +x** — toward the right board edge.
2. *From the 3D render.* The shroud's open face and its two contacts point toward board +x; the closed body
   bulk sits on the −x side, at x 88.6 … 94.6.

So the mating PHR-2 plug is inserted from the right-hand side and **the battery leads leave J5 heading +x,
directly away from the battery bay, which is ~12 mm away on the −x side.** The wires then have to turn back
through roughly 180° and run about 18 mm across the tab (over R62, past SW4's body) before they can reach the
cell. See **MEC-04**.

One consolation: this wire path stays at y ≈ 63 … 68, i.e. **below the cut line** (y 61.6 … 62.1) and nowhere
near the ESP32 antenna (opposite corner, ~60 mm away), L1 (y 112.3) or L2 (y 119.1). So the two hazards I was
specifically asked to look for — battery wires over the antenna or over the boost converters — **do not
occur**.

### The antenna notch

`U4` (ESP32-S3-WROOM-1) is at (57.500, 102.500) `rot −90`, `B.Fab` x 44.700 … 70.300, y 93.450 … 111.550 — the
module's 25.5 mm axis along x with the **antenna end at low x**. Its castellated pads only begin at
x = 52.240. The board is cut away under x 44.2375 … 50.59, y 93.3 … 112.0, so the antenna end of the module
(x 44.70 … 52.24, ~7.5 mm) is **cantilevered over open air**, exactly as Espressif's module layout guidance
asks. The notch is 18.70 mm tall against the module's 18.0 mm width — 0.35 mm of margin each side. Done right.

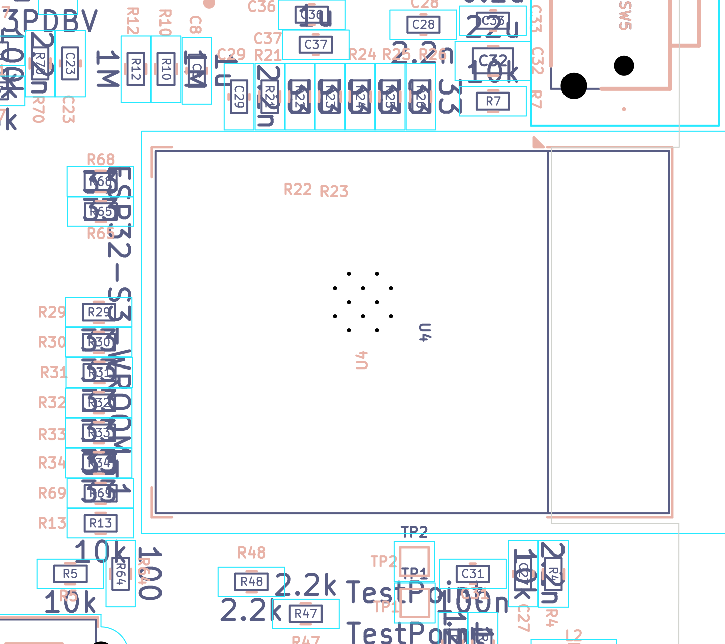
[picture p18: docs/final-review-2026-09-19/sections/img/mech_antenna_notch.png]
Antenna notch and the ESP32 module

*Bottom-side assembly, x 42 … 78, y 86 … 118 mm (mirrored). The rectangular bite in the board edge sits under
the module's antenna end; no copper, part or hole intrudes.*

### The "cut here for a smaller display" line

Four `Edge.Cuts` slots at y 61.60 … 62.12, each **0.516 mm wide**. The board's own bottom silkscreen at
(103.60, 65.30) explains them:

> `this long end of the board can be cut for smaller displays / if so, unpopulate R36 and R73 / and then,
> populate R72/R74 / this will swap power button to UP2 / depopulate SW5 (DOWN2) if you please`

At y = 61.85 the tab is **19.82 mm wide** (x 84.42 … 104.2375). The slots remove 7.50 mm; **12.32 mm of solid
FR4 remains** in five webs of 2.20 / 2.14 / 2.23 / 2.62 / 3.12 mm. **Twelve live nets thread those webs.** I
enumerated every track crossing the band and they are exactly J6's twelve signals — `3V3, I2C_SDA,
UNUSED_GPIO_3, I2C_SCL, C−, P+ (BAT+), GND, UNUSED_GPIO_46, UNUSED_GPIO_45, GND, LED_SW, W−` — plus the GND
pour on both layers. That is internally consistent (cutting here is meant to remove J6, SW10/PWR and the
expansion ESD cluster), but see **MEC-02** and **MEC-03**.

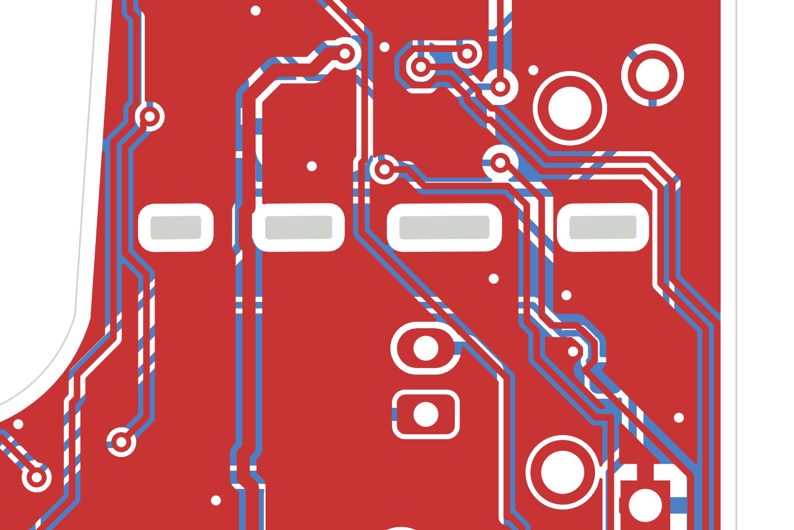
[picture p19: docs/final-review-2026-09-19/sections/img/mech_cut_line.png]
The cut line with 11 nets threading the webs

*X-ray of both copper layers, x 82 … 106, y 55 … 71 mm (top view). The four black slots are the cut line; the
tracks visibly thread the gaps between them. `P+` — raw battery positive — is one of them.*

---

## Calculations

**1. Panel length vs board length.**
Board Y-extent 37.000 → 148.250 = 111.250 mm; slot far edge y = 142.500.
Panel 105.33 mm ⇒ top edge at 142.500 − 105.33 = **37.17 mm**, 0.17 mm inside the board's top edge.
Bezel below the slot = 148.250 − 142.500 = **5.75 mm**.

**2. Panel width vs board width.**
Board 104.2375 − 44.2375 = 60.000 mm; panel 62.37 mm ⇒ overhang **(62.37 − 60.00)/2 = 1.185 mm per side**.

**3. Do the panel edges clear the side-button plungers?**
Panel x-extent if centred: 74.2375 ± 31.185 = **43.05 … 105.42 mm**.
Right-most plunger tip (SW10) = 105.450 ⇒ **0.03 mm inside the panel edge.**
SW4 = 105.232 (0.19 inside), SW1 = 105.187 (0.23 inside).
Left-most plunger tip (SW5/SW7) = 43.242 ⇒ **0.19 mm inside the panel edge.**
So in plan view the plungers and the panel edges coincide to within ±0.25 mm. They are at different heights
(panel above the board, buttons below it) so nothing collides, but a single case wall cannot both retain the
panel edge and clear the buttons. **MEC-07.**

**4. Flex tail budget (24-pin panel flex → J2).**
The FT01C drawing puts the tail end **23.86 mm** below the glass edge (main) and **24.18 mm** (FL/CTP).
Required path, panel edge to seated in J2:
```
  vertical drop through the 1.6 mm board ..............  1.60 mm
  run along the bottom face to J2's far edge ..........  13.59 mm
  insertion depth into an FH34SRJ ..................... ~3.0 mm
  two ~90 deg bends at radius r ....................... 2 x (pi/2) x r
                                                         = 1.57 mm at r = 0.5 mm
                                                         = 3.14 mm at r = 1.0 mm
  ---------------------------------------------------------------
  total at r = 0.5 mm ................................. 19.76 mm   -> slack 4.10 mm
  total at r = 1.0 mm ................................. 21.33 mm   -> slack 2.53 mm
```
Long enough, but the slack is small enough that **the panel must sit with its glass edge at the slot**, not
2–3 mm short. The 6-pin tails are 0.32 mm longer with 0.25 mm less run, so they have slightly more slack.
Confidence: medium — the 23.86 mm is scaled from the vector geometry of the manufacturer drawing, not a
printed dimension (**MEC-17**).

**⚠ MEC-23 eats most of this.** If the panel has to stand off the board by 1.5 mm to clear the through-hole
lead ends, add 1.5 mm to the vertical drop: the totals become 21.26 mm (r = 0.5) and 22.83 mm (r = 1.0),
leaving **2.60 mm and 1.03 mm of slack**. At a 1 mm bend radius with a 1.5 mm standoff the tail is
essentially exactly long enough and nothing is left for tolerance. Resolving MEC-23 by clipping the leads
flush rather than by standing the panel off is therefore the better answer.

**5. Bend radius vs slot width.**
Slot 1.30 mm wide, board 1.60 mm thick, panel FPC **0.30 mm thick** ("FPC+PI thickness 0.3mm" on the FT01C
drawing). The flex must enter from the top, turn down, pass through, and turn again to lie on the bottom.
Because the slot is *narrower than the board is thick*, the flex cannot lie diagonally in it: it must go
through near-vertically and be creased over the bottom lip. Common static-bend guidance for polyimide flex is
≥ 6 × thickness = **1.8 mm radius**; the slot offers a routed FR4 lip, i.e. effectively a crease. **MEC-01,
MEC-06.**

**6. Slot margins and the bezel bridge.**
Slot X 7.02 … 54.06, so 7.02 mm of FR4 outside its left end and 5.94 mm outside its right end. The strip
between the slot and the bottom edge is a **5.75 mm wide, 47 mm long bridge carrying four THT buttons**,
joined to the rest of the board only at those two ends. **MEC-10.**

**7. Mounting-hole geometry.** Five M2 holes, all 2.2 mm drill / 2.6 mm pad / 3.8 mm copper annulus, all on
GND (so a metal standoff bonds the case to signal ground — `HARDWARE.md` §16 flags this deliberately).

| Ref | (x, y) | (X, Y) | Pad side | Nearest edges |
|---|---|---|---|---|
| H1 | 94.241, 51.646 | 50.00, 14.65 | bottom | right 9.996 mm |
| H2 | 53.900, 70.500 | 9.66, 33.50 | bottom | left 9.663, top 3.000 mm |
| H3 | 47.987, 145.250 | 3.75, 108.25 | bottom | bottom 3.000, left 3.72 mm |
| H4 | 100.487, 145.250 | 56.25, 108.25 | bottom | bottom 3.000, right 3.75 mm |
| H5 | 94.100, 72.000 | 49.86, 35.00 | **top** | right 10.138 mm |

H3/H4 are symmetric about the board centre x = 74.2375 to **0.000 mm**. H2 and H5 are 1.500 mm apart in y, so
the upper pair is not level (**MEC-20**).

**8. Bottom-row button symmetry — the documented claim, verified.**
`HARDWARE.md` §9.1 says the bottom switches are "spaced 12 / 13 / 12 mm with a common actuator offset that
preserves mirror symmetry". Plunger (= `B.Fab`) centres:

| Button | plunger centre x | gap to next |
|---|---|---|
| SW9 BACK | 55.737 | 12.000 |
| SW8 OK | 67.737 | 13.000 |
| SW3 LEFT | 80.737 | 12.000 |
| SW2 RIGHT | 92.737 | — |

Row centre = (55.737 + 92.737)/2 = **74.237 = the board centre, to 0.000 mm.** The claim is exactly right.
(The *pad* positions look asymmetric because each switch's pads are offset from its own plunger; the
plungers are not.)

**9. Board flex under a button press.** Distances from each bottom plunger to the nearest screw: SW9→H3
7.75 mm, SW8→H3 19.75 mm, SW3→H4 19.75 mm, SW2→H4 7.75 mm. But these are *side*-actuated switches with
0.25 mm of travel and 1.77 N of force acting **in the plane of the board**, so the bending case is mild. The
real unsupported span is the right edge: SW4 (Y 33.25), SW1 (Y 47.25), SW11 (Y 78.5), J1 (Y 67.0) and D2
(Y 81.3) all sit between H5 (Y 35.00) and H4 (Y 108.25) — **73.25 mm with no support**. **MEC-14.**

**10. Battery-bay volume.** Plan 38.75 × 30.50 mm. Less ~1 mm of wall and clearance all round →
about **36.7 × 28.5 mm** of usable cell footprint. Depth is set by the back cavity (below). With a ~7 mm
cavity a **5 × 30 × 35 mm (503035, ≈500 mAh)** cell fits comfortably and a 6 mm cell still fits;
**anything 40 mm long will not.** No screw head and no tall part is inside the bay — H2 is 3.00 mm clear of
its lower boundary. Allow ~10 % of cell thickness (≈0.5 mm on a 5 mm cell) for swelling.

**11. MJTP1117 geometry, from the APEM drawing** (this is the number that sizes the whole back cavity):

| Property | Value |
|---|---|
| Body | 6.0 × 3.5 mm |
| Plan footprint | **7.40 mm** (actuation axis) × **7.30 mm** (lead axis) |
| **Body height above the PCB** | **6.80 mm** |
| **Plunger axis above the PCB** | **4.30 mm** |
| Plunger proud of the body face | **1.40 mm** |
| Plunger size | ≈1.5 mm |
| Lead spacing / ground-tab offset | 5.00 mm / 2.50 mm |
| Lead length below the board | 2.50 mm |
| **Travel** | **0.25 mm** (+0.20 / −0.10) |
| **Operating force** | **180 gf ± 50 gf = 1.77 N ± 0.49 N** |
| Life | 100 000 cycles |

0.25 mm of travel and ~1.8 N of force is a **short, stiff** button. A case flexure or cap must not consume
any of that 0.25 mm as lost motion, and must not preload the plunger. Design the cap so it bottoms on the
case, not on the switch.

---

## Height table and minimum enclosure cavity

"Above its own face" = away from the board. The bottom side is the back of the finished device.

| Ref | Part | Side | Height | Source |
|---|---|---|---|---|
| — | GDEQ0426T82-FT01C panel | TOP | **1.98 mm** | Good Display (1.41 mm for the non-front-light T01C) |
| H5 | M2 pad, no body | TOP | 0 | screw head lives here |
| TP3/4/5 | 2.54 mm header, **dnp** | TOP | 0 as shipped (~11.5 mm if ever fitted) | MEC-16 |
| **SW1–SW5, SW7–SW11** | **MJTP1117** | bottom | **6.80 mm — tallest part on the board** | APEM drawing |
| J6 | PPPC062LJBN-RC, right-angle 2×6 | bottom | ~5–6 mm *(not verified)* | see Open questions |
| J5 | JST S2B-PH-K | bottom | ~5.8 mm body *(not verified)*; more with the plug + wires | see Open questions |
| SW6 | MJTP1243, **dnp** | bottom | 4.3 mm (not fitted) | APEM |
| J1 | GCT USB4085 | bottom | **3.46 mm** | GCT |
| U4 | ESP32-S3-WROOM-1 | bottom | **3.10 mm** | Espressif |
| L1 | APV ANR5040 | bottom | ~3.0 mm *(not verified)* | — |
| D3 | SMAJ26A, DO-214AC | bottom | ~2.3 mm | — |
| J7 | microSD push-push | bottom | ~1.85 mm | — |
| J2/J3/J4 | FH34SRJ | bottom | **1.00 mm** + the flex on top | Hirose |
| 0805 MLCC | various | bottom | ≤ 1.45 mm | — |

**Minimum internal cavity, PCB top face as datum:**

* **Above the top face: 1.98 mm** of panel, plus the bezel lip. Allow **2.5 mm**.
* **Below the bottom face: 6.80 mm** — set by the ten MJTP1117s, not by any connector. Allow **7.5 mm** so
  the J5 plug and the battery leads have somewhere to go.
* **Total minimum internal stack: 1.98 + 1.60 + 6.80 = 10.38 mm.** With walls, a realistic closed case is
  **13–14 mm thick**.

If the optional **front-mounted MJTP1243** bottom buttons are used instead, add **4.3 mm of cavity above the
top face** in the bezel strip — see MEC-11.

---

## Findings

| ID | Severity | Finding | Evidence | Recommendation |
|---|---|---|---|---|
| MEC-01 | **HIGH** | The **1.30 mm** flex slot is the only path for three flexes and is narrower than the board is thick | `Edge.Cuts` polygon x 51.261…98.300, y 141.200…142.500; board 1.60 mm; panel FPC 0.30 mm | Widen to **≥ 2.5 mm** (3 mm preferred) and radius/chamfer the lips. A 3 mm slot still leaves 4.05 mm of the 5.75 mm bezel |
| MEC-02 | **HIGH** | The "cut for smaller displays" line severs **BAT+ (`P+`) with GND pour 0.15–0.20 mm away on both layers**; sawing with a cell connected can short the LiPo | `P+` on F.Cu at x 89.39, 0.40 mm wide, crossing y 61.59…62.11; GND zone on both layers; J5 is 5 mm away | Add a bold silk warning **"DISCONNECT BATTERY BEFORE CUTTING"**; better, add a 2 mm copper keep-out band centred on y = 61.86 or route `P+` to J6 away from the cut line |
| MEC-03 | **MEDIUM** | The cut line will not snap: **12.32 mm of solid FR4 in 5 webs across a 19.82 mm tab (62 %)**, 11 live nets and two pours crossing; 0.516 mm slots are below common fab minimums | slot widths 1.325 / 1.825 / 2.525 / 1.825 mm; webs 2.20 / 2.14 / 2.23 / 2.62 / 3.12 mm; 11 nets enumerated — 10 of J6's, **plus `Net-(R62-Pad1)`, which is the PWR button SW10 and *not* a J6 net (MEC-V02)** | Commit to "saw and file" and say so on the silk, or add a true V-score / mouse-bite line. The fab-minimum half is already flagged in `README.md`; the mechanical half is not |
| MEC-04 | **MEDIUM** | **J5's mouth faces +x, away from the battery bay.** The leads leave the plug heading toward the right board edge and must U-turn ~180° and run ~18 mm back across the tab to reach the cell | Footprint fab recess maps to board x 94.60…96.20 opening +x (derivation above), confirmed in the 3D render; bay is at x 44.24…82.99 | Rotate J5 by 180° so the mouth faces −x. If that cannot be done this spin, the case must provide a wire channel that carries the loop around SW4 and a strain-relief post, and the assembly doc must show it |
| MEC-05 | **MEDIUM** | Touch-flex spacing mismatch: J2→J4 is **19.74 mm** but the panel's MAIN→CTP tails are **18.22 mm** apart — 1.51 mm of permanent side-load on the touch tail | pad-row centres x 73.4875 / **93.2300** (J4's footprint *origin* reads 92.500 — it is 0.730 mm off its own pads, see **MEC-V01**); FT01C drawing tail centres 31.11 / 49.33 mm | Measure a real panel; if confirmed, shift J4 ~1.5 mm toward J2 — there is room (J4's courtyard ends at x 96.005, R52 is at x 97.00) |
| MEC-06 | **MEDIUM** | Flex bend radius at the slot lips is effectively zero against a ≥1.8 mm guideline for 0.3 mm polyimide | calculation 5 | Radius the slot lips, and/or mould a "flex saddle" into the case that the tails wrap over |
| MEC-07 | **MEDIUM** | Only **±0.25 mm** of plan-view daylight between the panel's side edges and the side-button plungers | panel x 43.05…105.42; plunger tips 43.242 and 105.450 | Use a two-part case: a front bezel lapping over the panel from above, and a back shell whose side walls sit *outside* the plunger tips with the button slots in them. Do not try to share one wall |
| MEC-08 | **LOW** | Plunger protrusion is inconsistent between button groups: bottom row **+1.95 mm**, side buttons **+0.95 / +0.99 / +1.21 mm** | overhang table | Re-centre the bottom row ~0.95 mm inboard so all ten MJTP1117s protrude equally; otherwise the case needs two or three different plunger depths |
| MEC-09 | **MEDIUM** | **SW11 (RESET) stops 3.54 mm short of the board edge, and D2 sits 1.23 mm beyond the plunger tip on the plunger's own axis** — there is no straight path from outside to the reset | SW11 `B.Fab` x 93.275…100.725, body centreline y 118.02; D2 `B.Fab` x 101.950…103.650, y 116.694…119.994; right edge 104.2375 | Move SW11 out to x ≈ 101.4 like SW1/SW4 and relocate D2, or accept it as internal-only and say so in the docs. A case plunger cannot pass over D2 |
| MEC-10 | **LOW** | The bottom bezel is a **5.75 mm wide, 47 mm long bridge** carrying four THT buttons, joined to the board only at its two ends | slot y 141.2…142.5 vs bottom edge 148.25; SW2/3/8/9 mounting pegs at y 143.95 | H3/H4 help and should stay. Warn the builder not to flex this strip during assembly; consider two 3–4 mm tie-bars across the slot (they also help MEC-01's saddle) |
| MEC-11 | **LOW** | The optional **front-mounted MJTP1243** buttons sit at y = 143.95 with a 3.5 mm body → **y 142.20…145.70, overlapping the panel's footprint (bottom edge y = 142.50) by 0.30 mm**, and needing 4.3 mm of front cavity | `HARDWARE.md` §9.1.1; pads 3/4 at y 143.950; MJTP1243 body 6 × 3.5 × 4.3 mm | Document the 0.30 mm interference and the 4.3 mm front cavity in §9.1.1; a 0.5 mm relief in the panel's bottom bezel edge, or moving the panel 0.5 mm up, clears it. (Also: SW9's alternate 3D-model offset is (−0.75, 3.00, −1.50) where SW2/SW3/SW8 use (−0.75, 2.50, −1.00) — preview-only, but it suggests the alternate land was not reviewed uniformly) |
| MEC-12 | **LOW** | **J6 is a right-angle socket** whose mouth faces out of the board's **top edge** and whose body overhangs that edge by **1.69 mm** (courtyard 2.01 mm) — 1.86 mm beyond the panel's top edge | `B.Fab` y 35.308…50.510, `B.Courtyard` y 34.990…49.062 vs top edge y 37.000; orientation confirmed in the 3D model | The case needs an aperture in its **top** wall for the expansion port, or the port is unusable when closed. Neither `HARDWARE.md` §11 nor §16 mentions the orientation or the overhang |
| MEC-13 | **LOW** | A closed unit has **no mechanical bootloader entry and no reachable reset**: SW6 (BOOT) is `dnp` and fully internal, SW11 (RESET) is recessed (MEC-09) | `connectivity_by_component.txt`: SW6 `flags=dnp`, pin 2 → `Net-(R64-Pad1)` → `ESP32_IO0`; SW6 at (79.479, 118.533), no board edge within 25 mm | The BOOT half is already documented in `README.md` ("USB-Serial-JTAG makes it unnecessary"). Add the same sentence for RESET, or fix MEC-09 |
| MEC-14 | **LOW** | The right edge is **unsupported for 73.25 mm** between H5 (Y 35.0) and H4 (Y 108.25) while carrying SW4, SW1, SW11, J1 and D2 | hole and part coordinates | Add a sixth M2 hole near (x 101, y 96–100) if a spot exists, or have the case press a rib on the board's top face there |
| MEC-15 | **LOW** | microSD card ejects toward the **left** wall from a mouth at x = 56.125 — 11.89 mm inside the edge — so the card overhangs the board when handled; the socket's own mechanical fit is already an unresolved item | J7 courtyard x 56.125…73.475; `HARDWARE.md` §"Socket footprint — an open mechanical item" | Resolve the TF-PUSH vs MEM2075 peg question first, then dimension the case slot and a finger relief at x = 44.24, y ≈ 84.6 from the chosen part |
| MEC-16 | **LOW** | TP3/TP4/TP5 are the **spare front-light outputs** (`LED+` / `C−` / `W−`, bottom silk: *"extra LED outputs here in case header is snipped"*) — but they are 2.54 mm plated through-holes at y = 135.4, **directly under the panel**. Using them as intended means soldering wires that must then escape between the panel and the board | board extract: side `top`, `dnp=True`, `PinHeader_1x01_P2.54mm_Vertical` at x 58.0 / 61.6 / 65.3, y 135.4; B.Silk label at (65.90, 137.20) and note at (69.50, 137.90); panel covers y 37.17…142.50 | Move these three pads into the 5.75 mm bezel strip (y > 142.5) or onto the back face next spin. For this build, document that a wire soldered here needs the MEC-23 standoff and a routed exit |
| MEC-17 | **LOW** | Tail-length slack is only **2.5–4.1 mm** and the panel tail length is not a printed dimension I could verify | calculation 4 | Measure a real panel before the case's slot position is frozen |
| MEC-18 | **LOW** | Four different corner radii (2.01 / 1.75 / 1.50 / 0.75 mm) | `Edge.Cuts` arcs | Harmonise; the 0.75 mm top-left corner is sharp for a hand-held product |
| MEC-19 | **LOW** | D2 (USB-present LED) is a 1206 on the **back** face, 0.59 mm from the right edge — it lights the inside of the case and will glow through the seam | D2 `B.Fab` x 101.950…103.650 vs right edge 104.2375 | Light pipe or window at (102.80, 118.34) on the back wall, plus a light-block skirt. Note this competes with MEC-09's plunger |
| MEC-20 | **LOW** | H2 (Y 33.50) and H5 (Y 35.00) are 1.500 mm out of level, so the upper boss pair is skewed | hole coordinates | Level them next spin; costs nothing and simplifies a moulded or printed boss pattern |
| MEC-21 | **DOC** | The **Enclosure** section of `docs/HARDWARE.md` §16 is 8 lines covering only GND-bonded standoffs and HV-vs-metalwork. It gives **no** cavity depth, no flex-slot dimension, no battery-bay size, no button protrusion, no panel-vs-board overhang, no port positions | `HARDWARE.md` lines 1215–1222 | Paste the cheat-sheet below into §16. A "case agnostic" board needs published dimensions more than a fixed one does |
| MEC-23 | **HIGH** | **The top face is not flat.** 58 soldered through-hole leads fall inside the panel's footprint, so their lead ends and solder fillets stand proud of the face the panel lies on — ~0.9 mm of lead plus fillet for the six side switches | Counted from the board file: J1 20 holes (ø 0.4 / 0.6), J6 12 (ø 1.02), SW1/SW4/SW5/SW7/SW10/SW11 4 each = 24 (ø 1.0 / 1.3), J5 2 (ø 0.75), all inside x 43.05…105.42, y 37.17…142.50. **Verification re-count: 78 plated holes lie inside the panel footprint.** The 58 are the solderable *component leads*, which is the right number for this finding; the other 20 are 18 × ø 0.2 mm via-in-pad inside U4 (12) and U11 (6), which can also wick solder to the top face, plus J7's 2 NPTH mechanical holes (no solder). APEM MJTP1117 lead length below the seating plane 2.50 mm − 1.60 mm board = **0.90 mm** + fillet. (SW2/SW3/SW8/SW9's 16 holes are *outside* the panel footprint — those are fine) | The case must hold the panel on a **≥ 1.5 mm standoff** above the board, or every lead must be clipped and filed flush. Whichever you choose, say so in the docs — and note it costs 1.5 mm of the 2.5–4.1 mm of flex-tail slack in calculation 4 |
| MEC-22 | **DOC** | Almost all front silkscreen is **under the panel** and unreadable: the welcome text, the four QR/logo graphics, the credits, `UP1/DWN1/UP2/DWN2/PWR`, `Development Header`. The J6 pinout textbox is **also 5.46 mm off the board** (bbox to x 109.70 vs edge 104.2375) and is clipped at both ends | F.Silk item positions y 44…137 vs panel covering y 37.17…142.50; KiCad DRC `silk_edge_clearance` at (104.24, 39.0) | Move anything meant to be read to the back face or into the 5.75 mm bezel. Pull the J6 pinout label fully on-board and put it on `B.Silkscreen`. (`HARDWARE.md` §9.1.1 already admits the bottom-button legends get covered by the front-mount option — the same problem applies board-wide) |
| MEC-V01 | **MEDIUM** | **J4's footprint origin sits 0.730 mm away from its own pad centroid**, so every position-derived document mislocates J4 — including this section's first draft | `J4` `GetPosition()` = (92.500, 126.000) but its 8 pads span x 90.730…95.730 (centre **93.2300**) and its `B.Fab` spans x 90.666…95.793 (centre 93.2295). J3, the identical `HRS_FH34SRJ-6S-0.5SH` footprint, is anchored correctly: position x 54.237 vs pad centre 54.2375. So J4's footprint *instance* has been displaced +0.730 mm in x (and −0.044 mm in y) relative to its anchor. DRC is clean because the copper is self-consistent | Re-anchor J4 next spin. Before then: **do not generate a pick-and-place file for an assembly house without checking J4** — KiCad exports the footprint origin, and a 0.73 mm error on a 0.5 mm-pitch FPC connector is more than one pitch. (I could not check this directly: `evidence/pcb/positions_all.csv` is missing from the evidence pack.) Hand-soldering to the pads is unaffected |
| MEC-V02 | **MEDIUM** | **Cutting the board on the "cut for smaller displays" line also amputates the PWR button (SW10)**, not just the expansion header — and nothing says so | `Net-(R62-Pad1)` crosses the cut midline at x = 102.112 on B.Cu (0.200 mm wide), running from R62 (101.20, 66.40, below the line) up to SW10 (101.705, 52.250, on the tab). `connectivity_by_component.txt`: SW10 pin 1 → `Net-(R62-Pad1)`, pin 2 → `3V3`. SW10 is the button the front silk labels `PWR` | Say on the silkscreen and in `README.md` that the cut removes **J6 *and* the PWR button**. After the cut the resistor ladder is left with a dangling branch at R62, so the firmware's button map also changes |

### Notes on the non-trivial findings

**MEC-01 — the flex slot.** This is the one I would not order without changing. Three flexes, one of them
12.5–13 mm wide, all pass through a single 1.30 mm gap in a 1.60 mm board and then turn 90° to lie flat.
Because the slot is narrower than the board is thick, the flex cannot sit diagonally: it goes through
vertically and is creased over the bottom lip. Laterally there is plenty of room (20.5 mm of flex in a 47 mm
slot) — it is purely the 1.30 mm dimension. Widening to 2.5–3.0 mm costs nothing and turns a crease into a
fold.

**MEC-02 — cutting the board with a LiPo attached.** The silkscreen invites the owner to saw the top off the
board. The saw line passes through a 0.40 mm `P+` track — raw battery positive, 3.0–4.2 V, behind which sits a
cell that can deliver amps — flanked by GND pour on both layers at the 0.15–0.20 mm design clearance. Sawing
and filing FR4 smears copper. A LiPo shorted through a copper smear at the cut face is a fire, not an
inconvenience. The fix is cheap: a 2 mm copper keep-out band on the cut line, or a different route for `P+`,
plus a printed warning. Note that `README.md` already warns that these slots are below JLC's minimum slot
width — so the slots have been thought about, just not from the battery-safety angle.

**MEC-04 — the battery connector faces the wrong way.** I want to be precise about confidence here, because
it is the kind of claim that is easy to get backwards. The KiCad footprint's fab outline has an unambiguous
4.5 × 1.6 mm recess — the shroud mouth — in its local −y face. Pad 1 at board (94.850, 67.500) and pad 2 at
(94.850, 65.500) pin the transform completely: local +x must map to board −y, and the fab bbox then forces
local +y → board −x (a reflection, correct for a bottom-side part, and it reproduces the observed
`B.Fab` x 88.550…96.250 exactly, where the other handedness would give 93.5…101.1). That puts the mouth at
board x 94.60…96.20 opening toward +x. The 3D render agrees: the open face and contacts point toward board
+x, the solid body bulk sits at x 88.6…94.6. **Confidence: high.**
The consequence is not fatal — the wires can be looped — but it is exactly the sort of thing that makes a
first assembly frustrating, and it puts a loop of battery wire next to SW4, the UP1 button. It also means the
`− + CHECK` polarity silk at (85.30, 66.60), which *is* correctly ordered (`−` at y ≈ 68 next to pad 1 `B−`
at 67.5, `+` at y ≈ 65 next to pad 2 `B+` at 65.5), sits on the blind side of the connector rather than where
you look while plugging in.

**MEC-07 — the panel/button wall conflict.** The panel is wider than the board, and the buttons stick out
past the board — and they land within a quarter of a millimetre of each other in plan view. They are at
different heights so nothing collides, but one naive case wall cannot both retain the panel edge and clear
the plungers. A two-part case solves it.

**MEC-09 — the reset button.** SW11 is a side-actuated switch aimed at the right edge that stops 3.54 mm
short of it, and D2 sits in the remaining gap on the same centreline. Combined with MEC-13 (BOOT not fitted),
a closed unit has no mechanical reset and no mechanical bootloader entry. For an ESP32-S3 that is
survivable — the USB-Serial-JTAG peripheral can force download mode, and `README.md` says exactly that about
BOOT — but the same reasoning has not been written down for RESET, and the placement looks accidental rather
than chosen.

---

## Assembly sequence for a hobbyist

1. **Solder/reflow the bottom side first**, THT parts and buttons last. The board is deliberately
   single-sided-assembly — a good, cost-driven call that also keeps the top face flat for the panel.
2. **Flash and smoke-test with USB only, before any plastic.** This is the last moment when everything is
   reachable, and the last easy chance to use SW6's land if you decide you want a BOOT button.
3. **Fit the three flexes to J2/J3/J4 with the board out of the case and the panel loose.** The FH34SRJ ships
   with its lever already open, so do not force anything. These levers are the most breakable thing on the
   board and there is no home rework for a broken one. Follow the board's own note:
   *"PLEASE CHECK PINOUTS OF ALL RIBBON CABLES BEFORE INSERTING / DOTS ON SILKSCREEN CORRESPOND TO PIN 1"*.
4. **Feed the tails through the slot before seating the panel.** Once the panel is down on the top face you
   cannot get a finger to them. Feed the 24-pin tail first — it is the widest and the least forgiving.
4b. **Clip and file every through-hole lead on the panel side flush** before the panel goes anywhere near the
   board — the six side switches, J5, J6 and J1 all come through inside the panel's footprint (MEC-23). Run a
   straightedge or a steel rule across the top face; if it rocks, keep filing. Skipping this is the single
   easiest way to crack a panel or to find out later that the tails are 1 mm too short.
5. **Seat the panel with its glass edge right at the slot** (calculation 4 — there is only 2.5–4 mm of slack,
   and less if the panel ends up standing off the board).
6. **Plug the battery last, always last.** Route the loop deliberately (MEC-04) before the shell closes.
7. **Screws last of all.** H3/H4 clamp the 5.75 mm bezel bridge that carries the four bottom buttons; do them
   up gently and evenly.

What will bite you:
* Creasing a tail at the slot lip (MEC-01 / MEC-06). The panel is the expensive part.
* Breaking an FH34SRJ lever. Buy a spare board or spare connectors before you start.
* Pinching the battery leads between the board and the back shell as it closes — made likelier by MEC-04.
* Trying to press RESET with the case shut (MEC-09).

### Cable and wire guidance the enclosure should provide

| Feature | Where | Why |
|---|---|---|
| **Radiused flex saddle** | along the slot, Y 104.2 … 105.5, full 47 mm | turns MEC-01/MEC-06's crease into a fold |
| **Three shallow flex channels** on the back face | slot → J3 (x ≈ 54), J2 (x ≈ 73), J4 (x ≈ 92) | keeps the tails from wandering sideways or crossing each other |
| **Battery pocket** | x 44.24 … 82.99, y 37.00 … 67.50 — 38.75 × 30.50 mm | the reason the board is this shape |
| **Wire channel + 180° loop relief** | from (96.2 … 101, 66.5) around the plug, then −x along y ≈ 65 to the pocket | J5 opens the wrong way (MEC-04) |
| **Strain-relief post or clip** | near (84, 65), just inside the diagonal edge | J5 is a friction-fit 2 mm connector with no lock; a tug on the cell unseats it |
| **Chamfer over the diagonal board edge** | (84.24, 64.5) → (86.05, 37.96) | the leads otherwise rest on a square routed FR4 edge under clamping load |
| **Light block + pipe** | (102.80, 118.34), back wall | D2, MEC-19 |
| **Card slot + finger relief** | left wall at y ≈ 84.6 | microSD, MEC-15 |
| **Top-wall aperture** | x 87.2 … 103.0 at the top edge | J6 expansion port, MEC-12 |
| **Nothing conductive** | within ~10 mm of x 44.2 … 50.6, y 93.3 … 112.0 | the antenna notch |

---

## Enclosure designer's cheat-sheet

| Dimension | Value | Source |
|---|---|---|
| PCB outline | **60.00 × 111.25 mm**, 1.6 mm FR4, 2 layers | `Edge.Cuts` centrelines |
| PCB bbox incl. line width | 60.05 × 111.30 mm | `board_extract.json` |
| Display panel | 105.33 × 62.37 × 1.98 mm | Good Display GDEQ0426T82-FT01C |
| Panel position on the board | y 37.17 … 142.50; x 43.05 … 105.42 (centred) | calculations 1–2 |
| Panel overhang per side | **1.185 mm beyond the PCB** | calculation 2 |
| Visible bezel below the panel | **5.75 mm** | calculation 1 |
| Cavity above the top face | **≥ 2.5 mm** panel-only; **≥ 4.0 mm** if the panel is stood off 1.5 mm to clear the through-hole leads (MEC-23); **≥ 6.8 mm** if front-mounted buttons are used | height table, MEC-11, MEC-23 |
| Panel seating plane | flush on the top face **only if every THT lead is clipped and filed flush**; otherwise 1.5 mm proud | MEC-23 |
| Cavity below the bottom face | **≥ 7.5 mm** (6.80 mm of switch + plug/wire room) | height table |
| Total internal stack | **≥ 10.38 mm** | height table |
| Inner wall, right | **≥ x 105.6** (plunger tip 105.450) | `B.Fab` + APEM |
| Inner wall, left | **≤ x 43.1** (plunger tip 43.242) | `B.Fab` + APEM |
| Inner wall, bottom | **≥ y 150.4** (plunger tip 150.195) | `B.Fab` + APEM |
| Button plunger axis height | **4.30 mm below the board's bottom face**; travel 0.25 mm; force 1.77 N | APEM drawing |
| Button plunger size | ≈1.5 mm; 1.40 mm proud of the body | APEM drawing |
| Bottom-button plunger centres | x = 55.737 / 67.737 / 80.737 / 92.737 (12 / 13 / 12 mm, centred on the board) | calculation 8 |
| Side-button plunger centres | left y = 75.25, 89.25; right y = 70.25, 84.25, 52.25 (PWR) | pad geometry |
| USB-C mating face | x = 105.485, centred on y = 103.975; aperture ≥ 9.3 × 3.6 mm | `B.Fab` + GCT 3.46 mm |
| microSD slot | left wall, centred y = 84.6, aperture ≥ 12 × 2.2 mm | J7 |
| Expansion-port aperture | top wall, x 87.2 … 103.0, ~6 mm tall | J6 |
| Battery bay | **38.75 × 30.50 mm** at x 44.24 … 82.99, y 37.00 … 67.50 | outline |
| Battery lead exit | J5 mouth at x 96.20, y 63.5 … 69.5, opening **+x** | MEC-04 |
| Flex slot | 47.04 × 1.30 mm at x 51.26 … 98.30, y 141.20 … 142.50 | `Edge.Cuts` |
| Antenna keep-out | x 44.24 … 50.60, y 93.30 … 112.00, plus ~10 mm of air | outline + U4 |
| Mounting bosses | M2 × 5: (94.241, 51.646) (53.900, 70.500) (47.987, 145.250) (100.487, 145.250) (94.100, 72.000) | H1–H5 |
| Boss diameter | ≤ 3.8 mm copper annulus → keep bosses ≤ 4.2 mm; **all five are GND-plated** | H1–H5 pad stack |
| Status-LED window | (102.80, 118.34), back face | D2 |
| Cut line (optional shortening) | y = 61.86, x 84.42 … 104.24 | `Edge.Cuts` + board silk |

---

## Checked and found OK

* **All three FPC mouths face the flex slot (+Y).** Checked from the FH34SRJ's back-flip-lock construction,
  the contact-vs-hold-down pad positions (y 124.3 vs y 127.0) and the 3D model. J2, J3 and J4 are all `rot
  180`, consistently.
* **The panel length matches the board to 0.17 mm** and the flex slot is the datum that makes it work.
* **The 6-pin front-light flex spacing matches the panel to 0.10 mm** (J3→J2 19.25 mm vs FL→MAIN 19.35 mm).
* **Antenna keep-out is done properly.** The board is cut away under the WROOM-1's antenna end; the notch is
  18.70 mm against the module's 18.0 mm; no copper, part, hole or track intrudes. The battery leads, the two
  boost inductors L1/L2 and every connector are on the far side of the board from it.
* **No component, pad, hole or track falls inside the flex slot or the four cut-line slots.** I checked every
  footprint bounding box against both, and every track crossing the cut-line band threads a web — nearest
  approaches are `P+` at x 89.39 to the slot edge at 90.091 (0.70 mm) and `W−` at 101.95 to 101.117
  (0.83 mm). KiCad DRC reports **zero `copper_edge_clearance` violations** anywhere on the board.
* **The cut line is internally consistent with its purpose.** ~~All twelve nets crossing it are exactly J6's~~ — **refuted by verification: 11 distinct nets cross the line, and one of them (`Net-(R62-Pad1)`) is the PWR button SW10, not J6. See MEC-V02.** The remainder are J6's
  twelve signals — nothing else is severed by the cut.
* **Bottom-row button symmetry is exactly as documented**: plunger centres 55.737 / 67.737 / 80.737 /
  92.737 mm, gaps 12.000 / 13.000 / 12.000 mm, row centre 74.237 mm = the board centre to 0.000 mm.
* **H3/H4 are symmetric about the board centreline to 0.000 mm.**
* **The MJTP1243 alternate land matches the documentation**: pads 3/4 are ø 1.30 mm drills with 1.95 mm rings
  exactly 7.000 mm apart, netless, as `HARDWARE.md` §9.1.1 describes.
* **J6's pinout matches `HARDWARE.md` §11 pin for pin** — row 1 (y 47.97) GND / IO46 / IO45 / GND / LED_SW /
  W−, row 2 (y 45.43) 3V3 / SDA / IO3 / SCL / C− / P+.
* **Button naming matches everywhere I could check it.** `HARDWARE.md` §16 says "Bottom edge, left-to-right
  facing the screen: BACK · CONFIRM · LEFT · RIGHT" — on the top face x increases to the right, and the
  plungers are BACK 55.737, OK 67.737, LEFT 80.737, RIGHT 92.737. Side buttons: UP1 (SW4, y 70.25) above
  DWN1 (SW1, y 84.25) on the right; UP2 (SW7, y 75.25) above DWN2 (SW5, y 89.25) on the left. All match the
  front silkscreen legends.
* **J5's polarity silk is correct**: `−` at y ≈ 68 beside pad 1 (`B−`, y 67.5), `+` at y ≈ 65 beside pad 2
  (`B+`, y 65.5).
* **Only 8 footprints are on the TOP side and none is a real component** — four `G***` LOGO graphics
  (x 51.4 / 72.2 / 82.2 / 92.2, y ≈ 136.1), the H5 mounting hole (94.100, 72.000), and the three `dnp`
  spare front-light output lands TP3/TP4/TP5 (x 58.0 / 61.6 / 65.3, y 135.4). No *body* sits on the top face,
  which matches the board's own note *"All components will be on the back of this board"* — but note that the
  face is still not flat, because 58 through-hole leads come through it (**MEC-23**).
* **The battery bay contains no tall part and no screw head.** H2 is 3.00 mm clear of its lower boundary.
* **Assembly-critical silkscreen exists and is on the correct (component) face**: the J3 and J4 pinout
  tables, the "check pinouts before inserting / dots = pin 1" warning, the J5 polarity marker, the
  display-variant rework notes (R42/44/46/52 vs R43/45/58/66) and the board-shortening note. This is
  unusually good documentation-on-copper for a hobby board.
* **No mechanical DRC class is violated**: zero courtyard overlaps, zero hole-to-hole, zero copper-edge, zero
  unconnected, zero schematic-parity. The 94 violations break down as 32 silk-edge-clearance, 25
  starved-thermal, 15 clearance, 12 silk-over-copper, 5 silk-overlap, 4 dangling-track and 1 mirrored-text.
  Only the silk ones are mine, and they are cosmetic (see MEC-22).

---

## Documentation cross-check

*Done after the findings above were written. Sources: `README.md` and `docs/HARDWARE.md` at the reviewed
commit. `../silkscreen-case` was not consulted and does not exist under this repo root.*

| # | Doc | Claim | Reality | Verdict |
|---|---|---|---|---|
| 1 | `HARDWARE.md` §16 "Enclosure" | The only two enclosure implications given are (a) the five mounting holes are GND-plated so a conductive case bonds to ground, and (b) a conductive case must not bridge `LED_SW` / the ±22 V rails | Both are true and verified (all five H-pads are on GND). But the section gives **no** cavity depth, flex-slot size, battery-bay size, button protrusion, panel-vs-board overhang, port positions or antenna keep-out | **MEC-21** — accurate but severely incomplete for a board marketed as "case agnostic" |
| 2 | `HARDWARE.md` §15 changelog | "The battery now sits in a cut-out *in* the PCB rather than stacked on top" | True — the 38.75 × 30.50 mm pocket at x 44.24…82.99, y 37.00…67.50. But no dimensions are given anywhere, and the doc does not mention that **J5 opens away from it** | **MEC-04, MEC-21** |
| 3 | `HARDWARE.md` §9.1 | "The bottom-switch anchors are spaced 12 / 13 / 12 mm with a common actuator offset that preserves mirror symmetry (no placement asymmetry remains)" | **Verified exactly**: 12.000 / 13.000 / 12.000 mm between plunger centres, row centre = board centre to 0.000 mm | ✅ correct |
| 4 | `HARDWARE.md` §9.1.1 | MJTP1243 is "the same vertical 6 × 3.5 × 4.3 mm two-pin part as the BOOT button"; pads 3/4 are "ø 1.3 mm, 1.95 mm rings, 7.0 mm apart"; legs are 6.5 mm apart so each sits 0.25 mm inside its hole | Pad geometry verified exactly. The part data matches the APEM catalogue | ✅ correct |
| 5 | `HARDWARE.md` §9.1.1 | "The front silkscreen legends (RIGHT, LEFT, BACK, OK) sit where the switch body goes and will be covered" | True for that option. The doc does **not** say that the *same* problem hides the entire front silkscreen under the panel in the standard build, nor that the front-mounted body overlaps the panel footprint by 0.30 mm | **MEC-11, MEC-22** |
| 6 | `HARDWARE.md` §11 | J6 pinout table, both rows | **Verified pin for pin** against the netlist | ✅ correct |
| 7 | `HARDWARE.md` §11 | Describes J6 only as "a 2×6, 0.1″-pitch female header" | It is a **right-angle** socket whose mouth faces out of the board's **top edge** and whose body overhangs that edge by 1.69 mm. Nothing in §11 or §16 says so, and a case designer cannot infer it | **MEC-12** |
| 8 | `HARDWARE.md` §"Case agnostic" | "no fixed button positions — buttons reach the outside world through connectors and a resistor-ladder scheme" | Overstated. The ten switches are at fixed, edge-referenced positions; what is flexible is that you may wire *remote* switches to the same pads (which is what the board's own front silkscreen says, more accurately) | **MEC-21** (wording) |
| 9 | `HARDWARE.md` §10 SD | "the mechanical fit is not yet resolved ... Confirm the ..." | Consistent with what I see: the dual-source land has a slot + round hole compromise. My separate point is the *card's* exit clearance at the left wall, which is not discussed | ✅ honestly flagged; MEC-15 adds to it |
| 10 | `README.md` "Board" | "2-layer, 60 × 111 mm, 1 oz Cu; 179 references = 162 fitted + 10 DNP + 7 bare-copper (holes H1–H5, test pads TP1/TP2)" | Outline measures 60.00 × 111.25 mm ✅. 183 footprints − 4 `G***` LOGO graphics = **179 references** ✅. Bare copper H1–H5 + TP1/TP2 = 7 ✅ | ✅ correct |
| 11 | `README.md` fab checklist | "the four narrow perforation slots. Those 0.5 mm `Edge.Cuts` polygons are below JLC's 1.0 mm routed-slot minimum; earlier orders were accepted with them" | Measured 0.516 mm ✅, and the concern is real. But nothing anywhere warns that **cutting along that line severs raw `P+` next to GND pour with a cell attached** | ✅ on manufacturability; **MEC-02** on safety |
| 12 | `README.md` "Input" | "a BOOT button footprint (`SW6`) is left unpopulated because USB-Serial-JTAG makes it unnecessary" | True and a reasonable decision ✅. The same reasoning is never applied to **RESET**, which is physically unreachable in a closed case | ✅ / **MEC-09, MEC-13** |
| 13 | `README.md` "Input" / `HARDWARE.md` §16 | Bottom buttons are called **CONFIRM** in the docs and in the schematic annotation, but the board's front silkscreen says **OK** | Cosmetic inconsistency only | minor, folded into MEC-22 |
| 14 | board silk (front textbox) | "All components will be on the back of this board, maximizing cost and simplicity for DIY" | True for component *bodies* — I verified that the only top-side footprints are four logos, H5 and three `dnp` lands. It is **not** true for through-hole *leads*: 58 soldered component leads fall inside the panel's footprint (J1 20, J6 12, six side switches 24, J5 2 — 78 plated holes in all, counting via-in-pad under U4/U11), so the face the panel lies on has lead ends and fillets on it | **MEC-23** — the claim is read by a builder as "the top is flat", and it is not |
| 15 | `README.md` | "`SW6` (boot button) and `TP3`-`TP5` are DNP in every standard build"; separately "the bare UART pads **`TP1, TP2`**" | Correct — TP1/TP2 are the 1.0 × 1.0 mm SMD UART pads at (57.4, 113.9) / (57.38, 116.0). TP3–TP5 are a different thing: the spare front-light outputs `LED+`/`C−`/`W−` at y 135.4, per the board's own bottom silk. Neither `README.md` nor `HARDWARE.md` §16 explains what TP3–TP5 are for or that they sit under the panel | **MEC-16** |
| 16 | `HARDWARE.md` §7 / board silk | "This board mainly supports the GDEQ426T82-FT01C display variant, but it can be repurposed for most other SPI e-paper displays" | Mechanically this is much narrower than it sounds: the board length, the slot position and the 5.75 mm bezel are all cut for the 105.33 mm FT01C. A different panel needs a different slot position or a cut board | **MEC-21** — worth a sentence in §16 |

**Claims I could not confirm:** the reference 3D-printed enclosure (`HARDWARE.md` §16) is not in this repo, so
I could not check any of my dimensions against a real case design.

---

## Open questions for the designer

1. **Is the panel really meant to sit with its glass edge at y = 142.50?** Everything in my analysis hangs on
   that. If the panel is instead intended to sit 2–3 mm higher, the tail slack in calculation 4 goes negative.
2. **What is the measured tail length of the panel you actually have?** The 23.86 / 24.18 mm figures are
   scaled off the vector geometry of the FT01C drawing, not printed dimensions.
3. **J5's orientation** — was the +x mouth direction deliberate (e.g. you intend to run the leads around the
   right-hand side), or is it an oversight? It is a two-minute fix if it is the latter.
4. **J6 body height and the mating accessory's envelope.** I could not get a Sullins drawing for
   PPPC062LJBN-RC. It is the one part where an unverified height could still change the back-cavity number,
   although the MJTP1117's 6.80 mm currently dominates.
5. **J5 header body height and the PHR-2 plug envelope.** JST's `ePH.pdf` would not parse. The plug's corner
   comes within roughly half a millimetre of SW4's body (J5 `B.Fab` ends at y 69.500, SW4 `B.Fab` starts at
   y 69.050, with a 1.56 mm x-gap) — worth a physical check on the first board.
6. **Did the Rev0 fab actually accept the 0.516 mm slots**, and what did they look like on the delivered
   panel? That determines whether MEC-03 is a real risk or a solved one.
7. **Is SW11's recessed position deliberate** (internal-only reset, pressed with the case open) or accidental?
8. **How do you intend the panel to sit?** Flush on clipped leads, or on a standoff / foam gasket? MEC-23
   and calculation 4 pull in opposite directions and the answer decides both the case stack-up and whether
   the flex tails are long enough. This is the single question I would most like answered.
9. **What did I not get to:** the APV ANR5040 inductor height, the microSD socket height and the exact card
   overhang, and a STEP export / true 3D interference check of the assembled stack (panel + board + battery +
   plug + case). I also did not model the front-mounted MJTP1243 option in 3D — the 0.30 mm panel overlap in
   MEC-11 is computed from the pad positions and the catalogue body size, not from a solid model.

---

## Sources

* **APEM MJTP / PHAP33 series, 6 mm square tact switches, through hole** — MJTP1117 dimensioned drawing
  (page 2 of 7) and mechanical specifications (page 1): body 6.0 × 3.5 mm, overall 7.30 × 7.40 mm in plan,
  6.80 mm above the PCB, plunger axis 4.30 mm above the PCB, plunger 1.40 mm proud, leads 5.00 mm apart with
  the ground tabs offset 2.50 mm, 2.50 mm of lead below the board, plunger travel 0.25 +0.20 / −0.10 mm,
  actuation force 180 gf ± 50 gf, 100 000 cycles.
  <https://mm.digikey.com/Volume0/opasdata/d220001/medias/docus/7171/MJTP1117.pdf>
  (also confirmed "Rectangular Button, Side Actuated / Through Hole, Right Angle" at
  <https://www.digikey.com/en/products/detail/apem-inc/MJTP1117/1795496>)
* **Good Display GDEQ0426T82-FT01C**, 4.26 in front-lit touch e-paper — outline 105.33 × 62.37 × 1.98 mm,
  24-pin 0.5 mm display FPC plus 6-pin front-light and 6-pin touch FPCs, "FPC+PI thickness 0.3mm", touch IC
  FT6336U, front-light pinout NC / LED W+ / LED C+ / LED C− / LED W− / NC, touch pinout INT / SCL / SDA /
  GND / RST / VDD3.3V. Product drawing `GDEQ0426T82-FT01C.pdf` reached via
  <https://www.good-display.com/companyfile/1997.html> ; product pages
  <https://www.good-display.com/product/938.html> and <https://buy-lcd.com/products/gdey0426t82-ft01c>.
  Series specification (mechanical section) <https://www.laskakit.cz/user/related_files/gdeq0426t82.pdf>.
* **Hirose FH34SRJ-24S-0.5SH / FH34SRJ-6S-0.5SH** — FH34 series, 0.5 mm pitch, **1.0 mm height**, top and
  bottom contact, **back flip lock**: the rotating actuator opens from the back, the FPC inserts from the
  front over entry chamfers, and the part ships with the actuator already open.
  <https://www.hirose.com/en/product/series/FH34SRJ> and the FH34 catalogue
  <https://www.hirose.com/en/product/document?series=FH34SRJ&documenttype=Catalog&lang=en&documentid=en_FH34_CAT>
* **GCT USB4085** — USB 2.0 Type-C receptacle, DIP type, PCB top mount; **3.46 mm profile height** above the
  PCB. <https://gct.co/connector/usb4085> (page itself returned 403 to the fetcher; figure taken from GCT's
  product listing as indexed, and cross-checked against the KiCad official footprint's fab outline of
  9.27 × 9.05 mm).
* **Sullins PPPC062LJBN-RC** — 12-position (2 × 6), 0.100 in (2.54 mm) pitch, through-hole, **right angle**,
  gold. Orientation independently confirmed from the STEP model in the board's 3D render. Insulator height
  not obtained. <https://octopart.com/pppc062ljbn-rc-sullins-270463>
* **JST PH series / S2B-PH-K-S** — <https://www.jst-mfg.com/product/pdf/eng/ePH.pdf> (the PDF would not
  parse; mouth direction was instead derived from KiCad's official
  `Connector_JST:JST_PH_S2B-PH-K_1x02_P2.00mm_Horizontal` footprint, whose `descr` cites that same document,
  and confirmed against the 3D render).
* **Espressif ESP32-S3-WROOM-1** — 18.0 × 25.5 × 3.1 mm; antenna end to be left clear of ground plane and
  ideally overhanging the carrier board.
* **Board data** — `docs/final-review-2026-09-19/evidence/pcb/board_extract.json`,
  `evidence/pcb/drc.json`, `evidence/sch/connectivity_by_component.txt`, and direct `pcbnew` reads of the
  scratch copy of `silkscreen_pcb.kicad_pcb`.
* **Project documentation** (cross-check step only) — `README.md`, `docs/HARDWARE.md`.

---

## Verification log

An independent adversarial verifier re-derived every BLOCKER / HIGH / MEDIUM finding from the board file
(`pcbnew` on the scratch copy), the KiCad footprint sources and the APEM drawing, without reading the first
draft's working notes. Numbers that changed are corrected in place above; two findings the first pass missed
are added to the table as **MEC-V01** and **MEC-V02**.

| ID | Verdict | What was independently checked |
|---|---|---|
| MEC-01 | confirmed, **re-graded BLOCKER → HIGH** | Slot polygon re-read from `Edge.Cuts`: pts (51.2614, 142.5) (51.8614, 141.2) (97.7625, 141.2) (98.3, 142.5) = **47.0386 × 1.3000 mm**, exactly as reported; board thickness 1.6000 mm from the design settings. The slot really is narrower than the board is thick. **Correction to the reasoning:** "a flex cannot lie diagonally in it" is not the binding constraint — a 0.30 mm tail passes a 1.30 mm slot with 1 mm to spare, and the three tails (12.5 + 4 + 4 mm) fit across 47 mm. The hazard is the fold radius at the lips, which is MEC-06. Because the board *can* be built and populated as released, and because the fold can be tamed with a moulded saddle without a respin, this is HIGH, not BLOCKER. Widening the slot is still the right fix |
| MEC-23 | confirmed-with-corrections, HIGH | Re-counted every plated hole inside x 43.05…105.43, y 37.17…142.50: **78**, not 58. The 58 is correct for *solderable component leads* (J1 20, J6 12, SW1/4/5/7/10/11 24, J5 2); the remaining 20 are 18 × ø 0.2 mm via-in-pad inside U4 (12) and U11 (6) plus J7's 2 NPTH mechanical holes. The via-in-pad can wick solder to the top face too, so the conclusion is stronger, not weaker. **Datasheet re-checked myself** (APEM MJTP/PHAP33 series drawing, MJTP1117 right-angle view): lead below seating plane **2.50 mm**, body height **6.80 mm**, plunger axis 4.30 mm above the board, plunger 1.40 mm + body 6.00 mm = **7.40 mm** overall. 2.50 − 1.60 = **0.90 mm** proud — arithmetic confirmed |
| MEC-02 | confirmed | Re-ran the crossing scan at the cut midline y = 61.855: `P+` is present as an **F.Cu track 0.400 mm wide crossing at x = 89.390** (segment (89.390, 61.866)–(89.390, 61.615)). Raw-cell positive really does cross the line the silkscreen invites the owner to saw. Severity HIGH stands — this is the LiPo-safety item |
| MEC-03 | confirmed-with-corrections, **re-graded HIGH → MEDIUM** | Slot widths re-read: 1.3252 / 1.8252 / 2.5252 / 1.8252 mm, each **0.5159 mm** wide — all four confirmed. Tab width re-derived from the board outline polygon at y = 61.855: crossings at x 84.4185 and 104.2375 = **19.8190 mm** — confirmed. **Arithmetic corrected:** the slots remove 7.5008 mm, not 8.51, leaving **12.3179 mm (62.2 %)**, not 11.31 mm (57 %). The first draft's own web list (2.205 / 2.143 / 2.230 / 2.620 / 3.120) sums to 12.318, so the total was a transcription slip. The conclusion is unchanged — 62 % solid FR4 plus a ground pour still will not snap. Re-graded to MEDIUM because it governs an optional user modification, not the board as ordered, and `README.md` already flags the fab-minimum half |
| MEC-04 | confirmed | Re-derived the mouth direction from the KiCad footprint source `Connector_JST.pretty/JST_PH_S2B-PH-K_1x02_P2.00mm_Horizontal.kicad_mod` rather than from a render. Its `F.Fab` outline is a rectangle −1.95…3.95 × −1.35…6.25 with a step cut into the **local −y face** spanning x −1.25…3.25 (4.5 mm) and y −1.35…0.25 (1.6 mm) — the shroud mouth, straddling the pin row as a side-entry PH does. The instance's `B.Fab` bbox on the board is x 88.550…96.250, and pad 1 is at x 94.850, which forces local +y → board −x (the other handedness would put the body at 93.5…101.1). So the mouth is at board x ≈ 96.2 **opening toward +x**, 8.0 mm from the right edge and facing away from the battery bay. Confirmed |
| MEC-05 | confirmed-with-corrections, MEDIUM | **The board-side number was wrong.** J4's pad-row centre is **x 93.2300** (8 pads spanning 90.730…95.730), not 92.500 — the first pass used the footprint *origin*, which on J4 is displaced 0.730 mm (that is MEC-V01). So J2→J4 = 93.2300 − 73.4875 = **19.7425 mm** and the mismatch against the panel's 18.22 mm is **1.51 mm**, roughly double what was reported. J3→J2 = 19.250 mm is confirmed. The *panel-side* figures are still scaled from the vector geometry of the FT01C drawing, not from printed dimensions, so the size of the mismatch stays uncertain — but a mismatch of some kind is now more likely, not less |
| MEC-06 | confirmed, MEDIUM | Same geometry as MEC-01; this is where the real risk lives. 1.30 mm slot in a 1.60 mm board gives an inner fold radius of about 0.65 mm for a 180° turn, against the usual 6×-thickness static guidance of 1.8 mm for 0.30 mm polyimide. Worth saying that folded e-paper tails at sub-millimetre radii are normal in production e-readers — what those have and this does not is a moulded saddle and a broken edge |
| MEC-07 | confirmed-with-corrections, MEDIUM | Board width re-derived: 104.2375 − 44.2375 = **60.0000 mm**; panel 62.37 mm → 1.185 mm overhang per side, confirmed. Plunger tips re-derived from `B.Fab` minus the 0.025 mm fab-to-datasheet correction: SW5/SW7 43.242, SW10 105.450. One sign slip: SW10's tip at 105.450 is 0.028 mm **outside** the panel edge (105.4225), not 0.03 mm inside. Immaterial — the conclusion (one wall cannot both lap the panel and clear the plungers) stands |
| MEC-08 | confirmed, **re-graded MEDIUM → LOW** | Every protrusion re-derived from `B.Fab`: SW1 105.212, SW4 105.257, SW10 105.475, SW5/SW7 43.217, bottom row 150.220; against edges at 104.2375 / 44.2375 / 148.250 those give **+0.95 / +1.00 / +1.21 / +1.00 / +1.95 mm** after the 0.025 correction — all confirmed, and the 0.95 mm group difference is real. The 7.40 mm plan dimension is confirmed from the APEM drawing (1.40 plunger + 6.00 body) against a 7.450 mm `B.Fab`. Re-graded LOW: it cannot damage anything and a case designer simply reads the number off the table; it is a cheap tidy-up, not a risk |
| MEC-09 | confirmed, MEDIUM | SW11 `B.Fab` x 93.275…100.725 → tip 100.700, **3.5375 mm** short of the right edge. D2 `B.Fab` x 101.950…103.650, y 116.694…119.994; SW11's body centreline is y = 118.023, and D2's pad centroid is y = 118.344 — D2 straddles the plunger axis and starts 1.250 mm beyond the tip. Both numbers confirmed |
| MEC-10 | confirmed, **re-graded MEDIUM → LOW** | Strip width 148.250 − 142.500 = **5.750 mm**; slot length 47.0386 mm; FR4 outside the slot ends 7.024 mm (left) and 5.938 mm (right). The slot is a genuine interior hole (the board polygon has 5 holes: this one plus the four cut-line slots), so the strip is braced at both ends — confirmed. Small correction: the switch pegs at y 143.950 are **1.450 mm** from the slot edge (0.800 mm hole-edge to slot), not 1.3 mm. Re-graded LOW because all four bottom switches are actuated *in the plane of the strip*, so pressing them does not bend it |
| MEC-11 | confirmed, **re-graded MEDIUM → LOW** | Alternate land re-checked: SW9 pads 3/4 at (52.237, 143.950) and (59.237, 143.950), ø 1.30 mm drill, 1.95 mm ring, **7.000 mm** apart, no net — confirmed. MJTP1243 body 6.0 × 3.5 × 4.3 mm confirmed independently from SW6's own footprint id `SW_PUSH_1P1T_6x3.5mm_H4.3_APEM_MJTP1243`, whose `B.Fab` is 6.100 × 3.600 mm and whose pads are centred on the leads — so the body does span y 142.20…145.70 and **does overlap the panel footprint by 0.30 mm**. One extra thing I checked and the first pass did not: SW6's MJTP1243 pads are **6.500 mm** apart while this alternate land is **7.000 mm** apart. It still fits — each lead sits 0.250 mm off-centre in a ø 1.30 mm hole, against about 0.45 mm of radial clearance — so this is not a finding, but it is worth knowing before drilling. Re-graded LOW: a documented optional variant with a 0.3 mm interference |
| MEC-16 | confirmed, **re-graded MEDIUM → LOW** | TP3/TP4/TP5 re-read: side `top`, `dnp`, `PinHeader_1x01_P2.54mm_Vertical`, ø 1.00 mm plated, at (58.000 / 61.600 / 65.300, 135.400), nets `W−` / `C−` / `LED_SW` — all inside the panel footprint, confirmed. Note the bottom silk reads `LED+` for the pad whose net is actually `LED_SW`. Re-graded LOW: three DNP rework pads that nothing in a standard build touches |
| MEC-12, MEC-13, MEC-14, MEC-15, MEC-17, MEC-19, MEC-20 | confirmed (plausibility read) | Spot-checked against the board data where it was free: J6 `B.Fab` y 35.308…50.510 vs top edge 37.000 (1.692 mm overhang); SW6 `dnp` with pin 2 → `Net-(R64-Pad1)`; H5 (94.100, 72.000) to H4 (100.487, 145.250) = 73.250 mm unsupported; J7 courtyard mouth x 56.125; D2 `B.Fab` right edge 103.650 vs 104.2375 = 0.5875 mm; H2 y 70.500 vs H5 y 72.000 = 1.500 mm, H1 x 94.241 vs H5 x 94.100 = 0.141 mm. All confirmed. Not independently re-derived at LOW severity: the flex tail-length budget in MEC-17 |
| MEC-18 | confirmed-with-corrections, LOW | `Edge.Cuts` actually carries **six** arcs, not four: r = 2.0082 (top-right, 102.558/37.000), 1.7500 (bottom-right), 1.4999 (bottom-left), 0.9454 (86.055/37.957, the top edge beside the header), 0.7500 (44.237/68.250) and 4.4300 (84.237/64.500, the fillet into the battery bay). The 0.750 mm radius is **not** the board's outer top-left corner — it is the inner corner where the battery cut-out meets the left edge, which is a less alarming place for a sharp radius. The "harmonise the radii" advice still holds |
| MEC-21, MEC-22 | confirmed (plausibility read) | Both are documentation findings and both read as sound. I did not re-derive the F.Silkscreen bounding boxes or re-open `HARDWARE.md` §16 line by line, so the 5.46 mm off-board figure for the J6 pinout textbox is reported as received |
| MEC-V01 | new | See the Findings table |
| MEC-V02 | new | See the Findings table |

### What the verification did **not** cover

* **Flex handedness.** The single most valuable remaining check. The board is seen from the *back*, the panel
  from the *front*, so the three tails may present in mirror order. If the panel's front-to-back order is
  FL / MAIN / CTP left-to-right, then viewed from the back it is CTP / MAIN / FL — and the board's J3 / J2 / J4
  would have the outer two tails **crossing each other**. The first pass matched J3→J2 to the panel's
  FL→MAIN spacing to 0.10 mm, which implies no crossing, but that match was made against tail centres scaled
  from a vector drawing, and the corrected J2→J4 number (19.74 mm) no longer fits either panel spacing well.
  Lay a real panel on a printout of the bottom copper before committing to anything.
* Heights of the Sullins PPPC062LJBN-RC, the JST S2B-PH-K and the microSD socket — still unverified, as the
  first pass said. The MJTP1117's 6.80 mm (now datasheet-confirmed) dominates the back cavity regardless.
* No STEP export or 3D interference check of the assembled stack was run by either pass.

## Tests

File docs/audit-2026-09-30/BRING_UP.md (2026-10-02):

# Silkscreen mainboard: bench bring-up (2026-09-30)

These are the checks that need a meter, a supply or a scope; software can't make them. Work in order and stop at the first wrong value.
- **Board:** Rev 1.0 (`aeb5b39`), the boards from the 2026-09-21 order. Rev 1.01 (2026-09-30) changes copper only near the cut line (§10); on 2026-10-01 it also gained `R84` (1 Ω in `C2`'s ground leg, §2, §3.2) and corrected CPL rows for seven parts (§1). Differences are marked **[1.01]**.
- **Coordinates:** KiCad board mm, front view (from netlist.ipc / positions.csv). Every part is on the back, so mirror x when you look at the back. From 1.01, positions.csv moves `J4`, `J7` and `U4` to JLC's anchors; the coordinates here are KiCad's.
- **Notation:** `ref.pin`. **[FW]** = needs firmware; unmarked steps work with any image or a blank module.
- **Sources:** HW = docs/HARDWARE.md, AT = AUTHOR_TODO.md, FR = FINAL_REVIEW.md (both in docs/final-review-2026-09-19), RM = README.md, E/L/F = reports 07/08/09 of this audit, GND = reports 05/06. Probe points were checked against `production/netlist.ipc`.

## 0. Tools
- **Meter:** DMM with a 200 mV range, an A range and a low-burden µA range. A µCurrent or PPK2-class meter is better for sleep current.
- **Supplies:** a 2-channel bench supply with current limit. One channel stands in for the cell on a JST-PH lead of checked polarity; the other feeds USB through a USB-C breakout.
- **Also:** an inline USB-C power meter, a 2-ch scope with **10x probes** rated ≥ 50 V, a thermocouple, 28-30 AWG wire, Kapton and a real 1-cell LiPo.
- **High-Z nodes read low.** `USB_STAT`, `BAT_MONIT` and `LED_MONIT` sit behind 1 MΩ-class resistors (values below computed from the ladder).
  - On a 10 MΩ DMM, `USB_STAT` 3.30/2.20/1.11/0.55 V read ≈3.0/2.06/1.08/0.54 V, and `BAT_MONIT` reads about 5 % low.
  - A x1 (1 MΩ) scope probe is useless on these nodes.

## 1. Visual and orientation (unpowered; loupe or microscope)
The Fabrication Toolkit corrects rotation only for SOT-23, SOIC and JST parts; everything else relied on JLC's preview (RM Step 6, F findings 1-3). **[1.01]** positions.csv carries `FT Rotation Offset`/`FT Position Offset` corrections for `U2`, `U5`, `D2`, `D8`, `J4`, `J7` and `U4`; check them anyway.
- **`D2`** (102.8, 118.3): pad 1 is the cathode (marked end); `D2.2` = `USB_VBUS`. Reversed means dark on USB: harmless, but the preview check missed it.
- **Pin 1 vs silk:** `U2` (85.1, 86.2), `U5` (86.9, 76.6), `D8` (94.5, 55.3). JLC has corrected these before.
- **`U10`** (49.5, 122.0): pin 1, plus the joints. Its pads are 0.229 mm wide vs TI's 0.30 mm (FR REC-B).
- **Diode bands:** `D3` SMAJ26A (93.4, 58.8), band (pad 1) to `LED_SW`; `D4`/`D5`/`D6` B5819W (82.1, 116.0 / 84.6, 116.0 / 79.8, 121.8).
  - None of these is in RM Step 6 or the Toolkit's corrections (F finding 2).
  - Reversed D4-D6: no panel HV rails. Reversed D3: shorts `LDO_IN` through `L2` and U10's body diode (§2 catches this).
- **`J4`** (92.5, 126.0): contacts on the pads. The CPL anchor is 0.73 mm off, which is 1.5 pitches if uncorrected.
- **`U4`** (57.5, 102.5) and **`J7`** (63.05, 84.6): centred on their pads.
- **Present:** late parts `R83` (88.4, 83.9), `C34`, `C7`, `F2` (AT rounds 4-5). **[1.01]** `R84` (80.1, 92.2), next to `C2`.
- **Empty:** `R72`, `R74`, `SW6`, `U14`, `TP3`-`TP5`. **Fitted:** `R36`, `R73`. **Never fit `R73` and `R74` together** (HW §9.2).
- **Solder:** `J1` (0.15 mm annular rings), the `U11` and `U4` thermal pads, and the THT joints on `J1`, `J5`, `J6` and the switches.
- **`J5`** (94.85, 66.5): back silk `-  +  CHECK`, with `+` beside pad 2 (`B+`, y 65.5) and `-` beside pad 1 (`B-`, y 67.5) (L §3).
  - Before any cell comes near the board, meter the pack's plug: + must land on pin 2 (RM:63-75, HW §3.3).

## 2. Unpowered resistance (no USB, no cell; `J2`/`J3`/`J4` empty; black on GND at `U3.2` (80.00, 84.15); let the caps charge)
| Rail | Probe (red) | Expect | Wrong means |
|---|---|---|---|
| `USB_VBUS` | `U2.3` / `U11.4` / `C2.1` | climbs to ≈300-400 kΩ (`R38`+`R51` = 400 k ∥ IC pins) | < 1 kΩ: short in `CR1`, `C2`/`C25`, `U2` or `U11` |
| `F1` | `F1.1` to `F1.2` | < 1 Ω | open: `F1` missing or unsoldered |
| `R84` **[1.01]** | `R84.1` (81.01, 92.20) | ≈1 Ω (null the leads first) | open: `C2` is out of circuit. ≈0 Ω: `R84` bridged |
| `P+` | `U2.6` / `U11.5` | ≈1-2 MΩ (`R12`+`R10` = 2 M) | < 10 kΩ: short on `P+` |
| `LDO_IN` | `U3.1` (80.00, 83.20) | high, climbing; diode test reads OL or > 1.5 V | ≈1.0-1.4 V on diode test: `D3` reversed |
| `3V3` | `U3.5` (77.30, 83.20) | > 1 kΩ, usually tens of kΩ or more, climbing (~60 µF) | < 100 Ω: bridge at `U4`, `U3` or a cap |
| `LDO_IN`-`3V3` | `U3.1` to `U3.5` | not ≈0 Ω | ≈0 Ω: `U3` bridged |
| `LED_SW` | `U10.5` / `TP3` | ≈1.1 MΩ (`R39`+`R41`) | low: `D3` or `C9` short |
| `B+`-`B-` | `J5.2` (red) to `J5.1` | **≈0.99 MΩ** (`R79`+`R80` 1.1 M ∥ `R57`+`R56` 10.01 M; a meter with a high test voltage may read lower) | ≈10 MΩ: `R79`/`R80` open, so Fix 4 is dead and the board never charges. ≈1.1 MΩ: `R56`/`R57` open. < 100 kΩ: something across the cell |
| `B-`-GND | `U3.2` (red) to `J5.1` | open: the FS8205A is off unpowered (the reverse polarity may show a diode via `U5`/`R16`) | ≈0 Ω: `Q1` shorted or bridged, so the protection is bypassed |

## 3. First power (bench supply, current-limited)
**3.1 USB input, no cell.** 5.00 V through the breakout; limit 100 mA, then 500 mA.
- **Current:** tens of mA (an estimate; the docs give no idle figure). At the limit, or a hot part: stop.
- **`D2` lit:** 2.6-3.2 V across `R59` (103.0, 113.3-115.1), i.e. 1.3-1.6 mA. It means USB is present, not charging (HW §3.1).
- **Expect:** `USB_VBUS` `U2.3` ≈5.0 V; `LDO_IN` `U3.1` ≈5.0 V; `3V3` `U3.5` 3.30 V ±1.5 %; `P+` `U2.6` ≈0 V; `CE` `U11.8` **≈0 V**; `USB_STAT` `C23.1` (74.50, 88.28) steady 3.3 V.
- **`CE` at 3.3 V with no cell:** the Fix 4 gate (`Q2`/`Q9`) is stuck on. Fit no cell until fixed (HW §3.3).
- **Missing rails:** no `LDO_IN` points at `U2` rotation; `LDO_IN` but no 3V3 points at `U3`.

**3.2 USB hot-plug transient (scope; revised 2026-10-01).** Only a source whose VBUS is already live at plug-in rings: USB-A chargers, PC ports, power banks on an A-to-C cable. USB-C chargers on C-to-C cables ramp VBUS after attach and don't overshoot.
- **Set-up:** 10x probe on `USB_VBUS` (`U2` VIN1) at `C25.2` (86.23, 88.70), ground spring on `C25.1`; 20 MHz BW limit; single-shot, rising trigger at 5.6 V, 2 µs/div. Worst case: a low-ESR USB-A brick on a short, thick A-to-C cable, no cell.
- **1.0 pass:** peak ≤ 6.0 V (the TPS2116 absolute maximum). `CR1` clamps only from 7.22 V.
  - Modelled: typical (aluminium-cap) USB-A chargers at 5.0 V on 1 m cables ≤ ≈5.9 V (6.26 V on 20 AWG at 5.25 V); low-ESR bricks on 20-24 AWG cables 6.1-6.9 V; worst stack-up 7.95 V (TP4056 `VCC` 7.97 V vs its 8 V limit). `LDO_IN` stays ≤ ≈5.6 V.
  - **Over 6 V:** record the source and cable. 6-7 V agrees with the models; 7 V or more means don't use that charger class with Rev 1.0 boards. No rework is needed (HW §3.1).
- **[1.01] Pass: every peak ≤ 5.6 V** (`R84` = 1 Ω; modelled worst case 5.60 V). Optional channel 2 on the `R84`/`C2` junction, `R84.1` (81.01, 92.20): that voltage / 1 Ω is the damper current.
- **[1.01] Switchover:** with a ≈3.0-3.4 V cell fitted, trigger falling on VIN1 (`C25.2`) at 4.0 V, channel 2 on `LDO_IN`. `R84` can deepen the existing VIN1 dip (≈3.3-3.8 V, ≈8 µs after plug-in) by up to ≈0.35 V. Chatter longer than ≈100 µs, or `LDO_IN` more than ≈0.2 V below the cell, is a new finding.

**3.3 Battery input** (supply in place of the cell, USB unplugged): 3.80 V, limit 100 mA, + to `J5.2`.
- **Pass:** current = §3.1 minus `D2`; `3V3` = 3.30 V; `J5.1`-GND a few mV.
- **Dead board?** The DW01A can start with its discharge FET open, and after any protection trip only USB restarts the board (HW §13.1). Plug USB in once.
- **Sweep 4.20 to 3.30 V:** `3V3` holds until `LDO_IN` ≈3.3-3.35 V, then tracks it (dropout, HW §16). Log where 3V3 drops below 3.2 V.
- **[FW] Brown-out:** repeat while pulsing Wi-Fi TX and scope `U3.5` for dips below 3.0 V and resets. Expect sag once the cell is below about 3.2-3.3 V (HW §3.5, FR §03).
- **Optional:** with a real cell, sweep USB down from 5 V. The mux moves to the battery at ≈4.00 V (3.63-4.39 V), and `USB_STAT` goes 1.11 to 0.95 V (HW §3.4).

## 4. Battery only: rails and back-feed (USB cable and UART adapter unplugged)
- **`USB_VBUS`** `U2.3`/`U11.4` **≈0 V**, and **`D2` dark** (≈0 mV across `R59`; 0.2 V = 0.1 mA).
  - 2-3 V, or a faint glow, is back-feed into the unpowered TP4056. The likely path is `CE`, which `Q2` drives to 3V3 on battery.
  - It blows the sleep budget. Next rev: feed `Q2`/`R81` from `USB_VBUS` (E §5, AT §F, FR §03).
- **`USB_STAT`** `C23.1` **2.20 V** (≈2.06 V on a 10 MΩ DMM).
  - 0.7-1.2 V: the unpowered TP4056 clamps `CHRG`/`STDBY`, so firmware can't tell battery from USB (E §5).
  - 3.3 V: `ST` is not asserting (`U2.8`/`R17`).
- **`CE`** `U11.8` ≈3.3 V is **expected** on battery (this is `R82`'s 3.3 µA). 0 V with a good cell means Fix 4 (`Q9`, `R79`/`R80`) misses the cell: no charging.
- **`BAT_MONIT`** `C8.1` (68.22, 90.36) = `P+`/2 (HW §3.6).
- **Light off:** `LED_SW` (`TP3`) ≈ `LDO_IN` minus a diode drop, and `LED_MONIT` `C31.1` (55.36, 114.50) ≈ 0.107 × that. Normal (HW §7).
- **[FW, deep sleep] `IO47`/`IO48` back-feed into `VDD_SPI` (HW §6.1):**
  - Across `R5` (73.59 to 75.41, 114.50; the 10 k `RST` pull-up): ≈0 mV. Each 0.1 V = 10 µA into `IO47`.
  - Across `R34` (72.17 to 74.00, 109.00; 33 Ω in `BUSY`): ≈0 mV. Each 1 mV = 30 µA into `IO48`.
  - Sleep current with the `J2` flex in vs out should differ by only a few µA (the panel draws 2-6 µA).
  - A 100-300 µA gap is back-feed: no firmware fix, and the next rev moves `RST`/`BUSY`. A ≈40-70 µA gap means the panel never reached deep sleep.

## 5. Charging (real cell at 3.5-3.9 V; USB through the power meter)
- **Charge current:** DMM A range in series with the cell + lead, or `PROG` at `U11.2` (≈1.0 V in CC, I ≈ V_PROG / 4.7 k × 1100-1200).
  - Expect **0.23-0.25 A**. It varies by lot, so record it. The USB meter shows charge current plus board load.
  - 0 A: check `CE` and `U11.4`. Well above 0.26 A: check `R6` (89.2, 97.1) (AT §F, HW §3.2).
- **`U11` temperature:** up to ≈0.5 W with a 3.0 V cell. The thermocouple also checks the thermal-pad joint.
- **`USB_STAT`:** charging 1.11 V; done 0.55 V (at about C/10, with `PROG` ≈0.1 V); weak USB 0.95/0.51 V. Float at `J5` 4.2 V ±1 % (TP4056 datasheet) (HW §3.7).
- **Pull the cell on USB:** `USB_STAT` alternates **≈0.55 V (`STDBY`) / ≈0.41 V (`CHRG`+`STDBY`)**. If it goes to a steady 3.3 V instead, Fix 4 has switched the charger off, which is also safe: note which one you see for the firmware.
  - These are the ideal values for the ×10 ladder on Rev 1.0; AT §F's 0.59/0.45 V is the pre-2026-09-21 ladder.
  - Scope with a 10x probe at 0.5-1 s/div and **record the period and duty** for the firmware. The datasheet says 1-4 s; unmeasured.
  - A steady 3.3 V when USB is plugged in with no cell is correct (Fix 4).
- **Protection (optional):** supply in place of the cell, USB unplugged, limit 200 mA. **Never with a real cell; never reverse a LiPo** (HW §3.3).
  - **Over-discharge:** ramp to 2.3 V. Below ≈2.40 V the current drops to a few µA and `J5.1`-GND opens. Only USB restarts it.
  - **Over-charge:** ramp to 4.35 V. At ≈4.30 V (after ≤ ~1 s) the charge FET opens and the load runs through its body diode, so GND-`J5.1` reads ≈0.6 V (a clone may cycle). Lower the supply to recover.

## 6. Sleep current [FW]
- **Firmware state:** `ext1` wake on `IO18`; panel in deep sleep; `ADIM` low; SD gated with the bus parked; touch hibernated with `TP_RST` high.
- **Set-up:** meter in series with the cell + lead. USB and UART unplugged, `J6` empty, no touch tail, `U13` fitted. Short the meter during boot (tens to hundreds of mA).
- **Expect:** ≈58 µA typ (3.7 V, 25 °C), ≈91-95 µA max (4.2 V), ≈56 µA without the panel (HW §16). Log at 3.7 and 4.2 V. AT §F's 73 µA is superseded.
- **Outside the budget:**
  - `U3`'s extra ground current at its real load: +0-20 µA.
  - A cell below 3.3-3.35 V: +190-260 µA (LDO dropout).
  - `U3`'s 25 µA is the largest term and assumes a genuine TI part (FR REC-C).
- **High readings:**
  - +100-300 µA: the §4 back-feed.
  - +18 µA: `R36` and `R72` both fitted.
  - Touch controller: +55 µA hibernated, +220 µA if not, ≈1.1 mA with `TP_RST` low.
  - mA: the `CE`/`D2` back-feed, or an unparked SD bus (`SD_VDD` ≈3.2 V).

## 7. Frontlight (`U10`; `J3` pins: 1 C+, 2 C-, 3/4 NC, 5 W+, 6 W-)
- **7.1 Flex map, before the first enable (LED-12).** A DMM diode test can't forward-bias a ≈15 V string: it reads OL both ways and proves nothing.
  - Board unpowered, flex in `J3`. Use a *floating* supply at 1 mA, ramping to ≤ 16 V, on the through-hole pads.
  - + `TP3` (`LED_SW`, 65.3, 135.4), - `TP4` (`C-`, 61.6, 135.4): the cool string glows at ≈13-15 V. - `TP5` (`W-`, 58.0, 135.4): the warm string.
  - Lights only with the leads swapped: the flex uses the reversed FT01C map. **Don't enable it**; the boost would reverse-bias it (HW §7).
- **7.2 First enable [FW].** `ADIM` (`U10.2`) HIGH ≥ 100 µs, then 10-200 kHz PWM.
  - Across `R37` (50.35 to 48.53, 124.12): ≈0.195-0.206 V × duty, and I = V / 15 Ω ≈ 13.3 mA at 100 % (≤ 13.9).
  - `TP3` shows the string's forward voltage (≈15 V). Record both strings at 100 % and ≈10 % for ΔVf.
  - Optional: hot-plug USB with the light on and watch `LED_SW` for a dropout or restart (`L2` Isat is below U10's current limit, FR REC-C).
- **7.3 Colour change [FW] (AT §F, REC-C-01).** CH1 `TP3`, CH2 `COLOR_SEL` (`U12.2`/`Q5.1`), at 100/50/10 % duty.
  - **Pass:** `LED_SW` re-slews by ΔVf in ≈100-150 µs (≤ ~350 µs) and stays below 23 V (the firmware trip; OVP is 24.25-25.5 V). The light must not latch off.
  - A spike at the switch is the both-off gap: change colour only at duty 0 (HW §13.1).
- **7.4 Open load (optional) [FW],** `J3` and `J6` empty.
  - **Expect:** `LED_SW` climbs to 24.25-25.5 V, retries twice, then latches off. `LED_MONIT` ≈2.6-2.7 V; `D3` stays off (breakdown ≥ 28.9 V).
  - **Recovery:** only `ADIM` LOW for more than 2.5 ms clears the latch.
  - **After:** `C9` decays with τ ≈ 5.3 s. **Wait ≥ 10 s before plugging in a light**; keep hands off `TP3`/`J3` at 25 V (HW §13.1).

## 8. E-paper power [FW: during a refresh; the panel runs the pump]
- **Rails** (10x probes; two are negative):
  - `PREVGH` `C14.2` (84.47, 125.55) / `J2.21`: ≈+22 V. `PREVGL` `C16.2` / `J2.23`: ≈-22 V.
  - `VSH1` `C13.2`: ≈+15 V. `VSL` `C15.2`: ≈-15 V.
  - `VSH2` `C17.2`, `VDD` `C18.2`, `VPP` `C19.2`, `VCOM` `C20.2`: the docs give no values.
  - The exact limits are in SSD1677 Table 11-1, which the docs don't copy (HW §6.2).
- **`GDR`** (`Q4.1`) **and `RESE`** (`Q4.2` / `R14.2`, 88.15, 122.51):
  - **Pass:** clean pulses, with `RESE` peaks well under Isat × `R14` (1.1 A × 2.2 Ω ≈ 2.4 V).
  - **Fail:** runaway or ringing means saturation. `R14` 2.2 Ω and `L1` 47 µH are not bench-verified.
- **`3V3` rise** at `U3.5` at plug-in with the panel connected: if it is faster than ~50 µs, `L1`/`C14` can ring toward 0.8-1.0 A (HW §6.2).

## 9. RTC and miscellaneous
- **RTC** `U13` runs VBAT-only: `U13.6` (61.27, 122.55) = 3.3 V and `U13.2` (62.54, 127.50) = 0 V. There is no backup cell, so no backup current. **[FW]** The oscillator starts only after the first I²C write (HW §10).
- **Power button** (uncut board): `IO18` at `R76.1` (76.30, 69.40) is 0 V idle and ≈3.0 V pressed. 1.76 V idle means `R36` and `R72` are both fitted (HW §9.2).
- **QR codes** (front, y ≈ 132-140): phone-scan all four. Six tented 0.3 mm vias sit inside them (≤ ~1.9 modules per code), so they should still decode (L).
- **UART:** `TP1` RX (57.4, 116.0), `TP2` TX (57.4, 113.9).
- **[FW] LDO temperature:** under sustained load, on USB, in the case, thermocouple on `U3`. The ceiling on USB is ≈250 mA continuous (HW §3.5).
- **[FW] SD switch-on:** scope `U3.5` as `SD_VDD` switches on (`Q7` switches in µs). `3V3` must stay above 3.0 V (FR REC-C).

## 10. Cut-down (x3) boards
The documented cut runs at y 61.86, x 84.42-104.24; the x3 build cuts at y 62.00. It removes `J6`, `U8`, `CR2`, `CR3`, `D3`, `D8`, `F2`, `SW10` and `H1` (HW §16).
- **Before cutting:** unplug USB and disconnect the battery. The cut crosses raw `P+` and other live nets, so saw it rather than snap it (FR §2 item 3).
- **3V3 wire (1.0).** The cut leaves `Q2.2` (Q2's source) and `R81.2` without 3V3, so `CE` never goes high and the board never charges (E §4).
  - Either bridge the two cut 3V3 stubs at the cut edge (x 87.53 and 100.60), or run a wire of about 17 mm from a main 3V3 pad (`R40.2` (82.44, 73.50), `U3.5` (77.30, 83.20) or `C6.1` (75.10, 83.76)) to `Q2.2` (93.71, 87.31) or `R81.2` (94.90, 85.31).
  - Check: with a correctly oriented cell, `CE` (`U11.8`) = **3.3 V**.
  - **[1.01]** 3V3 is rerouted along y 64.2-65.1, so no wire is needed. Still check `CE`.
- **GND wire (boards made before Rev 1.01).** After the cut, the power group (`U3.2`, `U2.1`, `Q1.3`, `C3`, `C4`, `C6`, `C25`, `C26`, `R16`, `R51`, `R77`, `H5`) meets main GND only through **one `J7` shell tab**.
  - **Fit a short wire** from `C6.2` (75.10, 85.84, power-side GND) to `C21.2` (74.80, 80.34, main GND): 5.5 mm, both on the back (GND §2 of the audit).
  - `U3.2` (80.00, 84.15) to `U4.1` (52.24, 93.50) reads ≈0 Ω while J7's shell tab is soldered, so a meter cannot prove the copper is continuous; open means that tab joint is bad.
  - **[1.01]** GND stitching vias below the cut join the two grounds, so no wire is needed.
- **Power button (`SW10` is cut off).** Remove `R36` (46.5, 79.0) and `R73` (49.9, 79.0) **first**, then fit `R72` (10 k) and `R74` (0 Ω).
  - 3V3 to GND must not be a short.
  - `R76.1` should read 0 V idle and ≈3.0 V with UP(2) pressed (HW §9.2).
- **Seal the cut edge.** Live nets reach it, including 3V3 at x ≈101.1 (about 2 mm on 1.01, 6.1 mm on 1.0) (E §4).
- **`LED_SW` has no TVS** once `D3`/`D8` are cut off; U10's OVP (≤ 25.5 V) is the only limit.

## Not faults
- `D2` lights on any USB, charging or not.
- `U13.2` is at 0 V.
- `LED_SW` is non-zero with the light off.
- Plugging in USB with no cell gives no blink.
- `B-`-GND reads open unpowered.
- After a protection trip, only USB restarts the board.
- The dangling F.Cu stubs in the bottom button row carry no net (HW "Things that look like mistakes").

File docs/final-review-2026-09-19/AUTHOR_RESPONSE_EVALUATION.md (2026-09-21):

# Evaluation of the author's response (2026-09-20)

Source: the "Author refute" column of [`FINDINGS_TABLE_author_refute.md`](FINDINGS_TABLE_author_refute.md) — 99 answers
(1 BLOCKER, 16 HIGH, 70 MEDIUM, 10 LOW, 2 DOC). Every item tagged REFUTED / PARTLY DISPUTED, and every item where you
asked for a re-evaluation, a source or an explanation, was re-checked against the design files and datasheets — by me,
directly, not by re-reading the auditors. Where you were right I say so plainly.

**Outcome:** 0 BLOCKER. **HIGH (16):** BOM-01 done; eight documentation items done in the README; DOCS-08, LAY-01 and MEC-02 are on your to-do because you said you will do them; MEC-01, MEC-23 and SD-V01 are closed as design intent; **HMI-01 is the one open decision.** **MEDIUM (70):** FAB-23 withdrawn; 14 downgraded to LOW after re-evaluation (BAT-02, BAT-03, FAB-03, FAB-16, HMI-02, HMI-07, HMI-V03, LAY-05, LED-12, MEC-V01, PWR-01, USB-02, USB-04, USB-V02); the rest are closed by your answer, done in this pass, or on your to-do. Nothing left in the list blocks an order.

Status key — **WITHDRAWN** reviewer was wrong · **CLOSED** your answer settles it · **DONE** fixed in this pass ·
**TODO-you** you said you will do it · **DOWNGRADED** re-evaluated, lower severity · **STANDS** still recommended, explanation given.

## 1. Where you were right and the review was wrong

| ID | Your point | Re-check | Result |
|---|---|---|---|
| **LED-01** (BLOCKER) | Paste is present, drawn as polygons | `HRS_FH34SRJ-*.kicad_mod` contains `fp_poly … (layer F.Paste)` 0.25 × 0.65 mm, one per signal pad. `pcbnew` on the board: 24 / 6 / 6 graphic B.Paste shapes on J2 / J3 / J4, **every one centred on a numbered signal pad**. The auditor, the verifier and my own "confirmation" all read *pad* layer sets and counted *flashes*; region-drawn paste is invisible to both. | **WITHDRAWN.** My error, compounded by re-using the method I was supposed to be checking. You are also right that the proposed "fix" would have been harmful. All dependent text struck in `FINAL_REVIEW.md`. |
| Method note | Re-check anything else that relied on pad-layer paste | Graphic paste exists on **only** J2/J3/J4 (scan of every footprint). SD-03 (J7) and FAB-V01 (U4/U11) use pad-based paste, so their method is valid. FAB-V01 re-measured: **U4 0 of 12** thermal vias under paste, **U11 4 of 6**. The "41 SMD pads carry no paste layer" count is meaningless and is withdrawn. | SD-03 stands (harmless). FAB-V01 corrected to U11 only → LOW. |
| **FAB-23** | Same four slots as LAY-01; 0.716 mm was wrong | Agreed — 0.516 mm centre-line; 0.716 added the 0.2 mm stroke. | **WITHDRAWN**, merged into LAY-01. |
| **LAY-05** | "False positive, all ground pours are stitched" | Re-tested every GND fill island for a GND via **or a grounded through-hole pin** (the first test ignored thermal-relieved pins). F.Cu: 14 islands, **all tied**. B.Cu: 50 islands, 44 tied; the 6 that are not total **11.5 mm²** (largest 6 mm²) and connect through their SMD ground pads — DRC shows 0 unconnected. The "120 mm² tongue island with zero vias" (LAY-V01) is tied through J6's ground pins. | **DOWNGRADED to LOW / cosmetic.** LAY-V01 **WITHDRAWN.** You were essentially right. |
| **USB-02**, **USB-V02** | "States will not collide, and if they do they are not physically possible" | Redone from the netlist (R70 100 k pull-up; R17 150 k/ST, R67 56 k/CHRG, R71 22 k/STDBY). Normal states: 1.98 / 1.19 / 0.60 / 3.30 V — cleanly separated. The "collisions" need **ST low at the same time as a charger output**, which only happens with VBUS sagging into the ~3.7–4.0 V band between the TP4056's UVLO and the mux's 4.0 V threshold (a bad source, as you say for USB-03) — and even then 0.96 V still decodes as *charging* and 0.53 V as *charged*: **the charge state comes out right; only "which source" is lost.** CHRG+STDBY both low (0.45 V) is the TP4056 no-battery blink; with your CE gate a cold plug-in with no cell reads 3.3 V (charger off), so the blink is reachable **only by unplugging the cell while on USB** (the detector self-latches once the charger holds `P+` up — BAT-V01). | **Both DOWNGRADED to LOW, firmware-only.** Nothing sticks out at board level. Firmware: widen the windows slightly and require a stable reading before saying "charged" — written into HARDWARE.md's firmware contract and the schematic note. |
| **BAT-03** | Reversed-pack voltage should not reach the DW01A | In effect, yes. The reverse path is blocked (by Q8; Q3's body diode points toward the cell — BAT-V02 — but the pair still isolates), so the DW01A's VCC-below-GND condition is fed only by µA of leakage. | **DOWNGRADED to LOW / informational.** |
| **HMI-13 / LAY-07 / LAY-D1** | 0.30 mm was designed as exposed-copper to exposed-copper | Both numbers, as requested: **0.300 mm** between the 0.6 × 0.6 mm F.Mask window on the tab and the ring's mask opening (mask expansion is 0) — *your recollection is right*; **0.151–0.188 mm** copper-to-copper under the mask (SW2 0.151/0.151, SW3 0.188/0.151, SW8 0.188/0.151, SW9 0.151/0.163). | **CORRECTED.** HARDWARE.md §9.1.1 now states both. |
| **FAB-04 / LAY-16 / USB-10** | Counts disagree (12 / 15 / 16); you get 13 | My `drc.json` was run with `--all-track-errors`: **12 live at J1 + 3 excluded at J3 = 15**. With default flags I get **11 live at J1** (+ the 3 excluded J3 = 14). Your 10 + 3 = 13 is the same population; ±1 depends on DRC flags and how excluded items are counted. 16 was a miscount. All are inside J1's own land pattern or are the already-excluded J3 netclass artefact. | **One item, LOW, accepted** (same reasoning as your FAB-01). |
| **HMI-23** | NextPCB's J6 substitute is a female header | Your export text (排母 … 弯插) is unambiguous. | **WITHDRAWN.** |
| **PWR-14** (found while pruning) | — | Two sections contradicted each other about C12; it sits on the `LDO_IN` net at U10's VIN, so both labels are defensible and the README's "keep C12" is correct. | **WITHDRAWN.** |

## 2. Things you asked me to explain, source or re-evaluate

| ID | You asked | Answer |
|---|---|---|
| **PWR-01** | "I need a source for this. We've been designing for 500 mA." | TI TLV755P datasheet **SBVS320, §5.4 Thermal Information**: DBV (SOT-23-5) RθJA = **231.1 °C/W** on the JEDEC board, **100.8 °C/W on TI's own EVM** (same package, more copper). On USB the LDO drops ≈ 4.85 − 3.3 = 1.55 V, so P = 1.55 × I. With TJ(max) 125 °C and 40 °C ambient: 85 °C ÷ 231 °C/W = 0.37 W → **≈ 240 mA continuous**; at 100 °C/W it would be ≈ 550 mA. **Your 500 mA design target is fine for what the board actually does:** this is a *continuous average* limit; Wi-Fi TX bursts are milliseconds against a thermal time constant of seconds, and the ESP32's average with Wi-Fi up is ~100–150 mA. It only bites with a *sustained* > ~250 mA average while on USB. On battery the drop is 0.2–0.9 V and it is a non-issue. **DOWNGRADED to LOW.** Free improvement if you are in the layout anyway: give U3's IN/OUT/GND pins pours instead of 0.25 mm tracks and a single spoke — copper is the whole difference between TI's two numbers. |
| **LED-14** | "Confirm with datasheet." | Confirmed from the PDF itself (TI TPS923610/1/2, SNVSCN8, Electrical Characteristics p.5): **tADIM_EN — "ADIM first pulse high time to enable device" = 40 µs; tADIM_SD — "ADIM logic low time to shutdown" = 2.5 ms; tADIM_PWM min on-time 20 ns.** §7.3.1: "can be enabled by driving the ADIM pin higher than VADIM_H for a period longer than tADIM_EN." At 25 kHz/50 % the high time is 20 µs, so a bare PWM in the schematic note's 10–25 kHz range may never start the chip. **STANDS as a firmware instruction** (drive HIGH ≥ 100 µs, then start PWM) — now in the firmware contract. No board change. |
| **USB-04** | "If it's a simple switch that makes sense then sure. Re-evaluate." | It is **not** a simple switch, so keep the SMF6.5CA. Anything that stays off at the 5.5 V a legal USB source may deliver has a breakdown ≥ ~6.4 V and clamps at 9–11 V under surge; an SMF5.0A clamps at ~9.2 V instead of ~11.2 V — still far above the 6 V abs-max — and leaks more at 5.25 V. The earlier review's tolerance argument for 6.5 V was sound. Datasheet table in `responses/PARTS_RESEARCH.md`. **DOWNGRADED to LOW / accepted.** |
| **USB-V01** | "Explain this issue." | It is the *reason* USB-04 has no fix. USB allows VBUS up to 5.5 V; the TPS2116 and LDO are rated 6 V abs-max. There is only 0.5 V between "must not conduct" and "must already be clamping", and no TVS is that sharp. So the TVS here protects against nanosecond ESD and cable-inductance spikes (which silicon survives), **not** against a charger that sits at 7 V or 9 V. That is true of almost every 5 V USB gadget without an OVP switch IC. Nothing to do for a prototype. **Informational.** |
| **HMI-01** | "What does this do for the use-case of the header? Would this enable hot plugging?" | No — a PPTC does nothing for hot-plug (it is a slow thermal device; hot-plug inrush needs a load switch). What it does: it is the only thing that turns *"accessory or stray wire shorts BAT+ to GND"* from a hot wire into a click-off. Your DW01A trips at 2–4.6 A (BAT-06), so a 1–1.5 A fault never trips it and just cooks. A 0.5 A-hold PPTC opens in seconds at ~1 A. Cost ≈ $0.05–0.10, one 0805/1206 in series with pin 12, ~0.2–0.5 Ω (≈ 50–100 mV drop at 200 mA). **Worth it if anyone but you will plug things into J6; skip it if J6 is your own dev port.** Candidate part in `responses/PARTS_RESEARCH.md`. **STANDS — your decision.** |
| **HMI-02** | "If you think they'll help avoid strapping conditions while not affecting I2S … explain." | **Bigger resistors will not help, so change nothing.** The risk is only at reset: GPIO45 selects the flash voltage (must read LOW for this module) and GPIO46 takes part in boot-mode selection (must read LOW). An accessory that pulls either HIGH at power-up — e.g. a 10 k pull-up — beats the chip's weak ~45 k pull-down no matter whether your series part is 33 Ω or 1 kΩ, and the board will not boot until it is unplugged. Nothing is damaged. 33 Ω is right for I2S edges. The fix is one sentence of documentation: *"Accessories must not pull or drive GPIO45 or GPIO46 HIGH during power-up/reset; use GPIO3 for anything that idles high."* **DOWNGRADED to LOW / doc line.** |
| **FAB-16** | "Do not know what fiducials are. Explain." | Small bare-copper dots (1 mm copper, ~2–3 mm mask opening, nothing else near) that the pick-and-place camera uses to find the board's exact position and rotation before placing parts. JLC's *Standard* PCBA page lists them as required, but in practice JLC adds its own on the edge rails it attaches, or aligns on pads/holes — which is why your two earlier orders went through. **DOWNGRADED to LOW.** Optional next revision: three 1 mm dots in empty corners cost nothing and slightly improve placement of the 0.5 mm-pitch parts. |
| **FAB-03** | "Explain benefit, if any." | A solder-mask *dam* is the sliver of mask between neighbouring pads; it stops molten solder wicking pad-to-pad. On these connectors the vendor footprint opens the mask as one window per row ("gang relief") — normal practice at 0.5 mm pitch, because a 0.2 mm dam is at the edge of what fabs can hold and they would delete it anyway. Your paste is already reduced to ~47 % of the pad, which is what actually controls bridging. Built fine once. **DOWNGRADED to LOW / no action.** |
| **HMI-V03** | "Don't know the benefit. Weigh." | Benefit of grounding the MJTP1117 covers: an ESD strike to the metal cover goes to ground instead of jumping 0.15 mm to the nearest track (I²C runs past two of them). With plastic button caps in a plastic case nobody touches the cover, so the benefit is small. **Cost is not zero here:** your optional front-button solder-bridge feature *uses those rings as un-netted landing pads* on SW2/SW3/SW8/SW9, so grounding them would break it. **Leave as is. DOWNGRADED to LOW.** |
| **MEC-V01** | "It seems fine? What's wrong?" | Nothing is wrong with the copper or the part. The footprint's *origin* is 0.73 mm away from the centre of its pads, so the pick-and-place coordinate (which is the origin) is 0.73 mm off from where JLC's model of the part expects it. You will see J4 sitting slightly off its pads in JLC's placement preview; their engineers nudge it, as your own notes say they have before. **DOWNGRADED to LOW.** Goes on the same to-do as FAB-21 (check J4, U2, U10, D8, U12 in the preview). |
| **DOCS-09** | "The rails … unsure what that has to do with anything?" | Nothing you need to design. JLC's Standard assembly line needs a board ≥ 70 mm wide to ride its conveyor; yours is 60 mm, so they clip temporary break-off strips ("rails") onto the long edges, charge a few dollars, and you snap them off. The only reason to mention it is so a first-time buyer is not surprised by the line item or the strips. Your reading is right: say Standard is needed because of the ESP32 module, and that hand-soldering the module would allow the cheaper Economic service. README updated that way. **DOWNGRADED to MEDIUM-doc → DONE.** |
| **SD-01** | "If there's a simple solution, let me know." | Firmware only, zero parts: before driving `SD_ACTIVATE` off, de-initialise SDMMC and set CLK/CMD/DAT0-3 to output-LOW (or input with pulls off). Otherwise the five 10 k pull-ups hold the "off" card at ~3.2 V and the gate saves nothing. In the firmware contract. **CLOSED.** |
| **BAT-02** | "100 Ω between Q8 and pin 5 produced voltage drop to P+ … Unsure what this gains." | If it dropped `P+`, the resistor was in the **load path**. In the reference circuit it sits only in the branch feeding DW01A pin 5 (with C7 on the pin side) and carries ~3–6 µA, i.e. 0.6 mV. It buys an RC filter so load/charger transients do not false-trip the protector, and it limits current into the pin in a fault. Your earlier board works without it, so: **DOWNGRADED to LOW / optional** — if you ever add it, put it in the pin-5 branch only. |
| **BOM-07** | "Look into alternatives, I'm open to them." | See `responses/PARTS_RESEARCH.md` §1 (no external crystal, stocked at both DigiKey and JLC). |
| **BOM-V01**, **BOM-06**, **BOM-02** | Open to alternatives / will look | See `responses/PARTS_RESEARCH.md` §2–§4. |
| **DOCS-24** | "Fix if it needs to be." | Checked and fixed in README — see `responses/README_CHANGES.md`. |
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

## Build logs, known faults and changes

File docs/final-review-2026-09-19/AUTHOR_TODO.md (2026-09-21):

# To-do list from the author's response (2026-09-20)

Built from what you wrote in `FINDINGS_TABLE_author_refute.md`. Your words are quoted where they were an instruction.
Nothing is committed. `git diff` shows every change; `git checkout -- <file>` undoes any of them.

## A. Done in this pass

| What | Your instruction | Files touched |
|---|---|---|
| **R14 → LCSC `C22939`** (JLC Basic, 11.7 k in stock, verified live; Yageo RC0603FR-072R2L stays the DigiKey-primary MPN) | BOM-01 "Valid - should be addressed" | `fabrication/part_fields.csv` → `silkscreen_pcb.kicad_sch` via your own `apply_part_fields.py --write` (1 field changed; backup `silkscreen_pcb.kicad_sch.pre-fields.bak`), `production/bom_JLC_upload_v4_optimized.csv`, `production/bom.csv`, `fabrication/BOM.md` (3 lines, incl. the wrong "no Basic 2.2 Ω exists") |
| **Duplicate-LCSC BOM bug fixed at the source** — it was two spellings of the same value. `C24`,`C31`: `100n` → `0.1u`; `C18`,`C19`: `1u` → `1u/50V`. A schematic-side BOM now groups `C14663` ×6 and `C28323` ×3 on one line each. | FAB-22 "Valid. Fix." / BOM-05 "will revise" | `silkscreen_pcb.kicad_sch` (4 Value properties), `fabrication/part_fields.csv` |
| **USB_STAT schematic note**: idle window `> 3.10 V` → `> 2.60 V` with the reason; fault line corrected to the re-evaluated logic | USB-01 "Sure, go with recommendation." | `silkscreen_pcb.kicad_sch` (note text; fits its frame — I rendered it to check) |
| **Front-light schematic note**: added the ≥ 40 µs enable pulse, the 2.5 ms shutdown time, the three-trip OVP latch and "change COLOR_SEL at duty 0 / never enable with J3 unplugged" | LED-14 "Can put in for instruction in firmware", LED-V02 "should be documented" | `silkscreen_pcb.kicad_sch` (text box enlarged to fit) |
| **README rewritten** for a first-time builder, JLCPCB-only, one BOM file, glossary, firmware status, what-else-you-need, battery lead order + one warning callout, cost/lead time, THT as a costed choice, licence in plain words, 5 bare / 2 assembled, KiCad not required, tweezers-BOOT, pin-hole RESET, cutting-down procedure, D2 polarity fixed. 0 broken links. | DOCS-01…07, -09…-18, -24, MCU-01, MEC-09, MEC-V02, LAY-02 | `README.md`, `fabrication/README.md` — change log: `responses/README_CHANGES.md` |
| **HARDWARE.md**: GPIO46 "input-only" corrected (3 places); charge current "≈ 0.23–0.25 A, measure it"; EPD loop area 20–27 mm²; front-button tab gap now gives **both** numbers you asked for; new **§13.1 Firmware contract** (USB_STAT decoding, ADIM enable, OVP latch recovery, colour-select, SD bus parking, wake sources, dead-pack / post-trip behaviour) | MCU-19, HMI-13/LAY-07/LAY-D1, USB-02/V02, SD-01 … | `docs/HARDWARE.md` — change log: `responses/HARDWARE_CHANGES.md` |
| **Board STEP model** for case designers (7.7 MB, DNP parts omitted, every 3D model resolved) | DOCS-07 "The board's STEP file should be available to everyone" | `docs/mechanical/silkscreen_pcb.step` |
| **Review corrected**: LED-01 withdrawn everywhere; FAB-23, LAY-V01, PWR-14 withdrawn; 12 MEDIUMs downgraded after re-evaluation; DRC counts reconciled | the refutation file's header | `FINAL_REVIEW.md`, `AUTHOR_RESPONSE_EVALUATION.md`, `REMAINING_PRUNED.md` |

## B. Yours — needs the KiCad GUI

1. **Open the schematic, then *Update PCB from Schematic* with "Update footprint fields" ticked.** This carries R14's new LCSC code and the four normalised Values onto the footprints. Until you do, the PCB (and anything the Fabrication Toolkit generates from it) still has the old R14 code. Then re-run the Fabrication Toolkit and check `production/bom.csv` now has one line per LCSC code.
2. **Replace the four 0.5 mm perforation slots with one wide slot** — "I will remove these slots in favor of one wide slot" (LAY-01 / DOCS-18 / FAB-23 / MEC-03). Make it ≥ 1.0 mm and draw it with the same 0.05 mm Edge.Cuts line as the rest of the outline (the five cut-outs are currently drawn at 0.20 mm). Afterwards: regenerate `production/`, and shorten the README's slot caution (it is worded for the current files).
3. **Silkscreen disclaimer at the cut line** — "I will add disclaimer. No keepout." (MEC-02). Suggested text: `DISCONNECT BATTERY BEFORE CUTTING`. While you are in that text box: it is mirrored on the front silk and overhangs the edge by 3 mm (LAY-13).
4. **USB input path width** — "Worth a look. Valid." (USB-06). `USB_VBUS` / fused VBUS are 0.25 mm; the battery path is 0.40 mm. Same pass, if you like: the two 0.25 mm links either side of R27 that the earlier widening missed (BAT-07 / PWR-V01), and pours instead of 0.25 mm tracks on U3's IN / OUT / GND pins (that copper is the whole difference between TI's 231 °C/W and 100 °C/W — PWR-01).
5. **Change the GitHub link** — "I should probably change the github link, valid." (DOCS-08). It is on the board silkscreen/QR, in `NOTICE`, and in comment 4 of both title blocks; or simply make `06_2026` the repo's default branch.
6. **At order time, in JLC's placement preview** (FAB-21 "Valid. Fine fix.", MEC-V01): check rotation/position of **U2, U10, D8, U12, J4**, the diodes and D2. If any is off, add `FT Rotation Offset` / `FT Position Offset` fields to that symbol so the correction sticks.

## C. Yours — decisions still open (my recommendation in brackets)

| Item | Decision | |
|---|---|---|
| HMI-01 | PPTC in series with J6 pin 12 (raw battery +)? It does **not** help hot-plug; it turns a shorted accessory from a hot wire into a click-off. | [Fit it if anyone but you will use J6. **Littelfuse 0805L075WR** (LCSC C151146) — same family and 0805 land as F1, 0.09–0.35 Ω. §5.] |
| BOM-07 | Replace the DS3231MZ? | [**Yes, next revision: Micro Crystal RV-8263-C7** — integrated crystal, $1.64 vs $13.85 at DigiKey (≈ 99 k in stock), LCSC C5137460, 0.24 µA vs ~3 µA, ±20 ppm; KiCad 9 already ships the footprint (`Package_SON:MicroCrystal_C7_SON-8_1.5x3.2mm_P0.9mm`). Not a drop-in — ~1 h of layout. RV-3032-C7 (TCXO, ≈ $3.24) on the same outline if you want DS3231-class accuracy. The SOIC-8 "drop-ins" all fail your rules (wide-body, or need a crystal). Verify pin functions across the C7 family before relying on it as a second source. Caveat I checked live: JLC holds only 472 of them today (Extended), so your 'well stocked at both' rule is met at DigiKey but only thinly at JLC. `responses/PARTS_RESEARCH.md` §1.] |
| BOM-V01 | Cheaper ESD arrays in some of the five positions? | [**Keep the TPD4E1U06.** Every credible SRV05-4 costs *more* at DigiKey ($1.23–1.88 vs $0.94), and on this board pads 5 and 6 are tied together on all five arrays, so an SRV05-4 (pin 5 = VCC) is not a drop-in. The real saving is the qty-100 price break. Your instinct was right. §2.] |
| BOM-06 | D8 PESD2IVN-UX is NRND | [**Keep it for now** — NRND but ≈ 16.5 k in stock at DigiKey. The true drop-in, PESD2IVN27-UX (Active, same SOT-323 and pinout), is at zero until mid-2027. Do **not** use a 24 V-rated part: the LED driver's OVP is 24–25.5 V. I checked D8's pinout against Nexperia's table — the board is wired correctly. Add a one-line BOM note. §3.] |
| BOM-02 | 22 µF for C4/C6/C32 is obsolete at DigiKey | [**Murata GRM21BR61E226ME44L** (0805, 25 V, ≈ 1.75 M in stock, $0.36, LCSC C86816; 0.05 mm taller). Only matters for a DigiKey hand-build. Separately: the JLC code in use is a CCTC clone `C20416420` (Extended); the Samsung original is `C45783` and is JLC **Basic** with 1.7 M in stock (verified live), while the clone is down to **396 pcs** — switching saves a loading fee and removes a stock risk, at +$0.25/board. Say the word and I will change it through `part_fields.csv` like R14. §4.] |
| 17 short ones | The only LOW/DOC rows that still want a word from you | [`REMAINING_PRUNED.md`, first table. Most are "skip" / "later".] |

## D. Yours — facts only you have

- **Known-good battery link** — README has the visible placeholder `TODO(author): link to a known-good pack` (DOCS-04 / BAT-V04).
- **Configurator go-live** — README says "not live yet"; soften it when silkscreenreader.com leaves preview (DOCS-02).
- **Firmware + first-power-up section** — "will be provided later after firmware work is done" (DOCS-12).
- **Battery-ejection / SD-card sentence** — "instructions for battery ejection will be documented" (HMI-V02); the docs also never say the battery must move before the card comes out (SD-V03).
- **Confirm the cost box** in the README against your next real quote (it is the review's 2026-09 cost model: ≈ $230–260 for five assembled, 2–3 weeks).
- **HMI-17 / SD-04 one-liner** — you suggested "a one-line note in the BOM" that prime MPN ≠ LCSC maker is deliberate (J7, the switches, F1).

## E. Yours — repo housekeeping (I did not delete anything)

- `production/bom_JLC_upload_v3.csv` — "v3 irrelevant. There should be 1 BOM" (FAB-10).
- `production/other_fabs/` — "other_fabs folder will be deleted, as the other fabs suck" (DOCS-13). Goes with it: the other-fab half of `fabrication/make_fab_files.py`, `fabrication/NEXTPCB_REV0_NOTES.md`, `fabrication/nextpcb_substitutes.csv`, and the matching paragraphs in `fabrication/README.md`. The README no longer mentions any of them.
- `DESIGN_REVIEW.md` — still says "GPIO46 is input-only" (line 288) and analyses Q3/Q8 as AO3419 (lines 164, 229, 237, 247) while line 201 says AO3401A. I left it alone as a historical document; say the word and I will fix those five spots.
- Next revision: *exclude from BOM* on R72, R74, SW6 (HMI-V01 "valid hardening … for the next revision").
- `silkscreen_pcb.kicad_sch.pre-fields.bak` was refreshed by `apply_part_fields.py`; it is untracked noise.

## F. Bring-up checks (when boards arrive) — from your answers

- Battery only, no cable: `USB_VBUS` ≈ 0 V and D2 dark; then deep-sleep current against the ≈ 73 µA budget (PWR-06 / PWR-V02 / PWR-07 "both modules' sleep modes taken advantage of").
- Measure the real charge current (≈ 0.23–0.25 A expected).
- Diode-test J3 against the front-light flex before first enable (LED-12).
- Scope the LED boost through a colour change at a few duties — no OVP trip (REC-C-01).
- Pull the cell while on USB and watch `USB_STAT` alternate ≈ 0.59 / 0.45 V — note the real period for the firmware (the 1–4 s figure is from the TP4056 datasheet, not measured).

## G. Things I can still do if you say so

- Fix the five stale spots in `DESIGN_REVIEW.md`.
- The ~30 no-decision clean-ups in `REMAINING_PRUNED.md` that are text/field edits (HARDWARE.md one-liners, symbol Description/Datasheet fields for Q4, Q7, D4–D6, CR1; the D2 schematic note; the duplicate `PIN_3`/`TP_RST` label).
- Set *exclude from BOM* on R72 / R74 / SW6 now rather than next revision (it would drop their no-part-number lines from BOM exports, which you currently list on purpose — so I left it).
- Delete `other_fabs` and strip the generator script, once you confirm.

---

# Round 3 — 2026-09-21 (KiCad was closed; edits made directly and verified)

Verification after all edits: ERC **0 errors**; DRC **0 unconnected, 0 schematic-parity issues**, only the J1 land-pattern clearance items remain; all four QR codes decode from the *plotted* F.Silkscreen layer.

## Done

| What | Where |
|---|---|
| **GitHub QR code replaced in place** — it pointed at `https://github.com/iandchasse/de-link`; now `https://github.com/iandchasse/silkscreen-pcb`. Same footprint, position, 7.86 mm size and 29 × 29 modules (0.271 mm) as its siblings, EC level L (your website code is also L; level M would need 33 modules = smaller dots). Tool: `evidence/tools/swap_github_qr.py`. | `silkscreen_pcb.kicad_pcb` |
| **U14 (RV-8263-C7) fixed.** Your custom symbol had CLKOE numbered **8** (duplicate of SDA) instead of **3** → ERC error, and pad 3 had no net, so CLKOE floated (CLKOUT may free-run at 32.768 kHz — defeats the 190 nA part). Now: CLKOE = pin 3, NC flag removed, wired to GND; PCB pad 3 = GND with a 0.9 mm B.Cu link to pad 2; symbol saved as its own library `KiCad/9.0/3rdparty/RV-8263-C7/RV-8263-C7.kicad_sym`, registered in `sym-lib-table`, U14 re-pointed at it (it was shadowing the stock `Timer_RTC:RV-3028-C7`, which an "update symbols from library" would have silently restored). MPN / Manufacturer / LCSC `C5137460` added, DNP. Full report: `responses/RTC_U14_CHECK.md`. | `.kicad_sch`, `.kicad_pcb`, `sym-lib-table`, `part_fields.csv` |
| **R15 10 k → 1 M** (Good Display datasheet §8.2 reference circuit shows R1 = 1 M on GDR — I looked at the drawing). Joins the existing 1 M BOM line. | sch + pcb + all BOM files |
| **C2 → 25 V** Samsung CL10A106MA8NRNC, LCSC `C96446`, JLC Basic, 2.8 M in stock. Value shown as `10u/25V`; C3 stays the 10 V part. | sch + pcb + all BOM files |
| **C4/C6/C32 22 µF**: prime MPN → Murata GRM21BR61E226ME44L; LCSC → `C45783` (Samsung, JLC Basic, 1.7 M). Note in `BOM.md`: the old CCTC clone is only cheaper above ~12 boards. | sch + pcb + all BOM files |
| **D2 schematic note**: "2.5mA" → "1.5mA" (its own arithmetic and R59 = 2 k give 1.5 mA). | `.kicad_sch` |
| **47 doc edits**, one line each in `responses/DOC_CLEANUP_CHANGES.md`. | `README.md`, `docs/HARDWARE.md`, `fabrication/README.md` |
| **STEP re-exported** with the new slot. | `docs/mechanical/` |

## Still yours

1. **Re-run the Fabrication Toolkit** — `production/` gerbers/positions predate the new slot, the disclaimer, the QR code and U14. (I edited the BOM CSVs by hand so they are right today, but the zip and `positions.csv` are stale.)
2. **F2 (PPTC)** — copy F1's symbol, value `0805L075WR`, same 0805 footprint, **in series with J6 pin 12 only** (see chat). Tell me the ref when placed and I will add its `part_fields.csv` row. HARDWARE.md already says "PPTC-fused" inside `<!-- confirm once F2 is on the board -->` markers — remove the markers or the sentence.
3. **USB path widening (your item 4)** — optional; my advice is to skip all widening this spin (numbers in chat).
4. **Part counts** — "179 references = 162 fitted + 10 DNP + 7 bare-copper" in `README.md` and `fabrication/README.md` is stale once U14 (DNP) and F2 (fitted) are in. Tell me when F2 is placed and I will recount.
5. **Two leftover "LED current" numbers in KiCad text**: schematic note says "~14mA", front silkscreen says "at least 15mA"; the real set-point is 13.3 mA.
6. **Sleep-current option** (PWR-03 / USB-08) — explained in chat; say "do it" and I will apply it everywhere.
7. `simulations/led_driver` models the old discrete boost — delete it or let me add a one-line "historical" README.
8. `de-link.me` is still linked (correctly, as the predecessor) in README and HARDWARE.md — remove if that domain is going away.

---

# Round 4/5 — 2026-09-21 (after F2, H6, R83, C34 and the C7 move were placed in the GUI)

## Done

| What | Where |
|---|---|
| **Removed a leftover `P+` copper branch** (4 B.Cu segments + the via at 89.374, 74.6) that ran straight into `U5` pad 5 and shorted across the new `R83`. DRC had flagged it as `shorting_items`. | `silkscreen_pcb.kicad_pcb` |
| **`F2`** value/MPN/LCSC → `0805L075WR` / Littelfuse / `C151146` (0.75 A hold, 1.5 A trip, 6 V). | sch, pcb, `part_fields.csv`, all BOMs |
| **`R83`** fields corrected — it carried the 10 k part number (`RC0603FR-0710KL` / `C25804`); now the 100 Ω part `RC0603FR-07100RL` / `C22775`. | sch, pcb, `part_fields.csv`, all BOMs |
| **`USB_STAT` ladder rescaled ×10** for sleep current: `R70` 100k→1M (`C22935`), `R17` 150k→2M (`C22976`), `R67` 56k→510k (`C23192`), `R71` 22k→200k (`C25811`), `C23` 2.2n→0.1u (`C14663`). All JLC Basic, all checked live. 13.2 µA → 1.1 µA on battery. | sch, pcb, BOMs |
| **`R57`** 1M → 10M (`C7250`, Basic): `Q3` gate-bleed drain ≈3.7 → 0.4 µA, permanently off the cell. | sch, pcb, BOMs |
| **`PWR_FLAG` (#FLG05) on `Net-(U5-VCC)`** — with `R83` in the way ERC reported "power pin not driven" on `U5` pin 5. ERC is back to 0 errors. | sch |
| Schematic notes: USB_STAT note rewritten with the new levels/windows and the current draw; "2.2n cap placed near ESP32" → "0.1u" beside the ladder. Rendered and checked — both fit their frames. | sch |
| BOM CSVs: `R83`, `F2`, `C34`, new ladder values, `U14` DNP line; comments aligned with schematic values (`1u/50V`, `47uH`). **Cross-check script: every fitted ref's value + LCSC code matches the schematic in both CSVs, and all 184 PCB footprints match the schematic's Value/MPN/LCSC (0 mismatches).** | `production/*.csv`, `fabrication/BOM.md`, `BOM_handbuild_digikey.csv` |
| HARDWARE.md: §3.3 (R83/C7 filter, C34, R57, standing drain ≈10 → ≈7 µA), §3.7 (new ladder table), §13.1 (new decode windows + "slow, high-impedance node, no internal pulls"), §16 (sleep floor ~75 → ~60 µA; six holes; screw-head rule; H5/H6 coordinates), CR3 now on `/P+_FUSE`, appendix counts. README + fabrication README counts: **184 references = 165 fitted + 11 DNP + 8 bare-copper, 134 nets**. | docs |
| Five schematic screenshots regenerated at the same 400 dpi crop style. | `docs/images/05, 16, 16b, 17, 19` |
| STEP re-exported (H5 move, H6, F2, R83, C34). | `docs/mechanical/` |

Final state: ERC 0 errors (41 warnings, all the known kinds); DRC 0 unconnected, 0 parity, no shorts; the only un-excluded errors are the 9–13 `J1` USB-C pad-to-pad clearances that have always been there.

## Still yours

1. **Re-run the Fabrication Toolkit before ordering.** `production/` gerbers, drill and `positions.csv` predate the slot, the disclaimer, the QR code, `U14`, `F2`, `C34`, `H6`, `R83` and the moved `H5`. The BOM CSVs are right today; the Toolkit will regenerate `bom.csv` anyway. Then check `R83`, `C34`, `F2` and `C7` in JLC's placement preview.
2. Open the schematic once and look at the new `PWR_FLAG` next to `U5` pin 5 — move its label if you dislike where I put it.
3. Firmware: the `USB_STAT` thresholds in HARDWARE.md §13.1 are the contract now (idle > 2.6 V, battery 1.80–2.60, charging 0.80–1.35, done 0.35–0.70 *and stable*); sample ≤ 1 Hz, internal pulls off.
4. Unchanged from round 3: LED-current wording in the schematic note ("~14mA") and front silkscreen ("at least 15mA") vs the real 13.3 mA; `simulations/led_driver`; `de-link.me` links; stale spots in `DESIGN_REVIEW.md`; `bom_JLC_upload_v3.csv` and `production/other_fabs/` do **not** carry this round's changes (delete or tell me to update them).

---

# Round 6 — 2026-09-21 (after the Fabrication Toolkit re-run)

## Done

| What | Where |
|---|---|
| **Regenerated fab outputs verified.** Gerber zip vs a fresh `kicad-cli` export of the saved board: identical coordinate operations on `B.Cu`, `F.Cu`, `B.Mask`, `B.Paste`, `F.Silkscreen`, `Edge.Cuts`; 5.30 × 1.10 mm slot present; six 2.2 mm mounting holes in the PTH drill; 36 drawn paste regions (FPC connectors). `positions.csv` = 165 rows = every fitted part. Toolkit `bom.csv` matches the schematic on every value and LCSC code, and agrees with the upload BOM. | `production/` |
| **`bom_JLC_upload_v4_optimized.csv` → `jlc_bom.csv`**; `bom_JLC_upload_v3.csv` deleted; every live reference updated (README, fabrication/README, BOM.md, NEXTPCB notes, DESIGN_REVIEW). Historical audit folders still use the old names, on purpose. | `production/`, docs |
| **Other-fab files regenerated** with `python fabrication/make_fab_files.py --split` — they were two days stale (no F2/R83/C34, old ladder values, old H5). 165 placed parts. | `production/other_fabs/` |
| README + fabrication/README now say plainly: other factories are supported (files kept current), only JLCPCB has produced working boards, the NextPCB attempt did not end in a successful order, PCBWay is untried, and the choice is the builder's. | docs |
| `simulations/` removed from the README's folder listing. `de-link.me` links left as they are. | README |
| Schematic PDF, full-sheet capture, both board renders and seven more block screenshots (USB input, charger, MCU, e-paper, LED driver, boot buttons, RTC) regenerated from the current files. The old bottom render still showed the four perforation slots. | `docs/` |
| DESIGN_REVIEW.md: "GPIO46 is input-only" corrected (that is an ESP32-classic rule, not S3); AO3419 section marked as written before the AO3401A swap. BOM.md: hand-build parts cost now says "budget ≈ $66", not ≈ $48. | docs |

## Still yours

1. `docs/silkscreen_pcb_layout.pdf` is from 2026-09-18 — it is a GUI plot (File → Plot → PDF, two pages), so re-plot it when convenient.
2. Optional, both "margin, not failure": widen the `USB_VBUS` trunk 0.25 → 0.40 mm (done 2026-09-21: fuse → TPS2116 is now 0.40 mm. Correction: the "0.9 A worst case" I quoted was wrong — `R6` = 4.7 k sets the charge current to ≈0.25 A, so the real worst case is ≈0.55 A and the old 0.25 mm trace was only a few °C warm), and nudge the four TP4056 thermal-pad vias out from under the paste windows (REC-B-02).
3. Cosmetic symbol fields (`Q4`, `Q7`, `D4`–`D6`, `CR1` descriptions/datasheets) and the doubled `PIN_3`/`TP_RST` label.
4. At order time: JLC placement preview for `R83`, `C34`, `F2`, `C7`, `U12`; F2 (`C151146`) is an Extended part with ~1.9 k in stock — check it is still there.

---

# Round 7 — 2026-09-21 (repo cleanliness mini-audit and its fixes)

Report: `repo_hygiene/REPO_HYGIENE_AUDIT.md` (83 findings: 54 confirmed, 28 adjusted, 1 refuted).

## Done

| What | Where |
|---|---|
| 47 doc-level findings fixed (U14 missing from three DNP lists incl. README Step 5; the "production/ is out of date" contradiction; R14's retired `C112307`; five-vs-six mounting holes; 50 V cap count; C2 in the 0805 table; cut-line consequences; NextPCB counts; dead `.gitignore` lines; layout PDF re-plotted as front + back). | README, HARDWARE.md, fabrication/*.md, DESIGN_REVIEW.md, .gitignore |
| **KiCad tidy (text-level, KiCad closed; `evidence/tools/r9_kicad_tidy.py`):** `Sim.*` properties carrying a local Windows path to `irlml6402.spi` removed from Q2/Q3/Q7/Q8 (sch + pcb); Description/Datasheet corrected on Q2 Q3 Q7 Q8 (AO3401A), Q4 (IRLML6346), D4–D6 (1N5819HW), CR1–CR3, U1/U6–U9, J2–J4, J6, J7, Q1 — every URL checked live; silkscreen display part number → `GDEQ0426T82-FT01C` (3 places) and welcome text `SW1-SW8` → `SW1-SW5 and SW7-SW9`; the frontlight label nudged 0.2 mm so the longer name clears U13 pad 4's mask opening; the Q8 note now names the EEVblog thread and its link points at the real URL; TPD4E1U06DBVR symbol's default footprint fixed (library + cached copy); two stale ERC exclusions (L1, L2) removed — the third (Q1) turned out to be live and was kept; last STEP path no longer "delink". | sch, pcb, pro, `KiCad/9.0/3rdparty/TPD4E1U06DBVR` |
| Verified after the edits: nets and value/footprint of all 184 parts **identical** before/after; ERC 0 errors, same 41 warnings; DRC 0 unconnected / 0 parity, only the J1 clearances; silkscreen re-rendered and inspected (Roboto is installed; the stale glyph caches of the three edited texts were dropped so KiCad rebuilds them on the next save). | — |
| Owner's decisions applied: battery link + charge-rate note; real cost quote ($223.95, $305.23 at checkout, two assembled); **Rev 1.0 stays** — one explicit statement in README and HARDWARE.md; DESIGN_REVIEW.md status banner (+ R57 note); BOM.md cost-table note; `evidence/`, raw agent output, `*.json` and `placement/` git-ignored; final-review reports listed in the README; three local paths and two broken links inside the review reports cleaned; local path scrubbed from `docs/audit-2026-09-16/netlist.xml`. | docs, .gitignore |
| `KiCad/de-link just parts.ods` removed: it is the BOM of the old de-link prototype (AP2112K, AP3012, MCP73832, DM3AT…). Its still-relevant alternates (S2B-PH-K-S / A2001WR-2P, SKHLLAA010 / TS365ZJ, A2541HWR-2x6P, SD05C) are all already in `part_fields.csv`, `nextpcb_substitutes.csv` or BOM.md. Restore with `git checkout -- "KiCad/de-link just parts.ods"` if wanted. | — |
| Regenerated from the edited design: schematic PDF, full-sheet capture, battery-protection screenshot, layout PDF, both board renders, STEP (H6 now at 69.200, 117.500). | docs/ |

## Still yours

1. **Open the PCB once, save, and re-run the Fabrication Toolkit** — the silkscreen text changed, so the gerber zip is stale again (and saving rebuilds the text glyph caches). Then tell me and I will re-verify the zip against the board.
2. Delete the stray `placement/` folder yourself (it is git-ignored now, so it cannot be committed by accident).
3. Deliberately left alone (cosmetic, your call): mixed capacitor value formats (`4.7u` vs `4.7u/50V`), `CR` vs `D` designators for TVS parts, the unused vendored `MJTP1117.kicad_sym`, three spellings of "frontlight", dated change-log parentheticals in HARDWARE.md's appendix tables, the bulky intermediates inside `docs/audit-2026-09-16/`.

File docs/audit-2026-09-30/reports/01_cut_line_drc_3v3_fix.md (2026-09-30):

# Trim-at-y62 DRC acceptance test (x3 3V3 island fix)

> Run on 2026-09-30, before commit `3edd0c8` existed: **HEAD / OLD / CONTROL = `6871962`** (design and production files
> identical to `aeb5b39`, the Rev 1.0 order) and **working copy / NEW / FIX = the change later committed as `3edd0c8`** (1.01).
> Evidence paths (`A_trim/`, `C_fab/`, `layout/` ...) are under [`../evidence/`](../evidence/), a local-only pack (git-ignored).

Scratch: evidence/A_trim. CONTROL = trimmed old.kicad_pcb (HEAD), FIX = trimmed new.kicad_pcb (working copy).

## Method
- A_trim/trim.py (KiCad 9 pcbnew), identical for both copies, each loaded next to a copy of silkscreen_pcb.kicad_pro (no .kicad_dru exists in the repo):
  footprints with position y < 62 deleted (9 in each; no kept footprint has a pad above 62); tracks/vias entirely above deleted (190 tracks, 16 vias each);
  12 tracks crossing y 62 CLIPPED at y 62 (same 12 in both copies, incl. the two 3V3 feeds x 87.526 and (101.101,62.501)->(99.4,60.8));
  Edge.Cuts: lines clipped at y 62 (x 84.409 and x 104.237), shapes above deleted, new edge at y 62 closing the outline;
  the filled Edge.Cuts rect slot (x 89.586..94.886, y 61.4..62.5) that straddles the cut becomes a 0.5 mm notch in the new edge;
  zone outlines intersected with y >= 62 (GND zone now y 62.0..148.72), refilled with pcbnew.ZONE_FILLER, saved.
- kicad-cli 9.0.6 `pcb drc --format json --severity-all --units mm` (no parity) on control, fix, and untrimmed full_old / full_new as baselines.
- Raw: A_trim/drc_{control,fix,full_old,full_new}.json, A_trim/drcdiff.txt

## Findings

### F1 (info) CONTROL reproduces the 3V3 island
drc_control.json unconnected_items (2): (a) 3V3 "Missing connection" Track B.Cu 0.7085 mm @(101.101,62.501) [island side, clipped stub of (101.101,62.501)->(99.4,60.8)]
<-> Track B.Cu 1.4765 mm @(87.526,63.476) [main side, clipped x 87.526 feed]; (b) GND zone-to-zone (trim artefact, see F4).
Ratsnest endpoints differ from the owner's earlier run (which reported both at Q2 pad 2) because this trim CLIPS crossing tracks, so the stubs are the nearest island/main items; island membership confirmed by connectivity below.

### F2 (info) FIX: zero unconnected 3V3 items
drc_fix.json unconnected_items (1): only "Pad 2 [GND] of C21 @(74.800,80.338) <-> Zone [GND]" (see F4). No 3V3 item.

### F3 (info/warn) DRC diff FIX-trim vs CONTROL-trim
- copper_edge_clearance 14 vs 14 (all from tracks clipped to the cut line + the pre-existing x=101.101 3V3 vertical ending at y 62.501, 0.376 mm from the cut; same in both).
- J1 (USB-C) PTH pad clearance 0.15 < 0.2 mm: 11 vs 12 reported, pairs shuffle between runs (full_old 12 vs full_new 10 too); pre-existing footprint issue, not from this change.
- NEW in FIX (also in untrimmed full_new, absent in full_old): track_dangling warning "Track [3V3] on B.Cu, length 0.1414 mm @(101.001,64.900)" -- in the new fix path.

### F4 (warn) GND unconnected in BOTH trims = same pre-existing split, not a FIX regression
- Geometric GND clustering (A_trim/gnd3.py: pads/tracks/vias + zone-fill islands, layer-aware) on the REFILLED trims: 2 GND clusters in CONTROL and in FIX, 1 on full_new.
  The minor cluster is the same in both: U3.2 (LDO GND), U2.1, Q1.3, J7.9, H5.1, C3.2, C4.2, C6.2, C25.1, C26.2, R16.1, R51.2, R77.2 + vias (84.32,89.68) (83.40,85.10) (76.20,85.80) (77.80,84.10) (80.10,87.70) (82.10,82.20) [+ (99.30,65.60) in CONTROL only: the via the owner moved].
- DRC shows this one split with different ratsnest endpoints: CONTROL "Zone<->Zone", FIX "C21.2 (main side) <-> Zone (minor side)". So the new C21 item is NOT a new disconnection.
- Caveat: refill pulls the pour 0.475 mm back from the new y62 edge; physically the fab copper keeps the ORIGINAL fill up to the cut. Re-checked with the original fill clipped at y62 (no refill) -> F5: identical result.

### F6 (info) 3V3 copper connectivity (independent of DRC, A_trim/analyze.py geometric union-find on 3V3 pads/tracks/vias; 3V3 has no zone)
- 3V3 source: U3 TLV75533PDBV (3.3 V LDO), pad 5 OUT @(77.300,83.200).
- CONTROL: 3 clusters -- main (U3.5 + 27 other pads), island {Q2.2, R81.2, 15 items}, singleton R48.1 (modelling gap, same in FIX; DRC reports no R48 issue in any run).
- FIX: 2 clusters -- main contains U3.5, Q2.2 AND R81.2 (30 pads); singleton R48.1 (same modelling gap). PASS.

### F7 (info) New 3V3 copper vs the y62 cut (edge of copper = centreline minus 0.125 mm)
- Genuinely new path segments: minimum 2.048 mm (y 64.173 run x 91.527..98.488 and (90.4,65.3)-(91.527,64.173)); vs the 0.5 mm slot-notch floor at y 62.5 (x 89.586..94.886): 1.548 mm. No warn.
- The split-off upper piece of the existing x=101.101 vertical, (101.101,64.6)-(101.101,62.501), is 0.376 mm from the cut -- same geometry as HEAD (flagged copper_edge_clearance in both trims); on a real x3 cut it is a dead 3V3 spur whose stub continues to the cut edge (exposed 3V3 copper at the edge, pre-existing).
- 1 um micro-segment in the new path: (101.000,64.900)-(101.001,64.900), then (101.001,64.9)-(101.101,65.0); DRC flags "Track has unconnected end" (track_dangling warning) on the untrimmed full_new too. Electrically connected (copper overlaps; DRC and geometry agree), cosmetic.

### F5 (warn) Physically faithful re-trim (original fab fill clipped at y62, no refill): same outcome
- trim.py mode `clipfill` -> A_trim/cf_control / cf_fix, DRC: drc_cf_control.json = 2 unconnected (the 3V3 island + GND zone<->zone), drc_cf_fix.json = 1 unconnected (GND C21.2 <-> zone). 133 violations each.
- A_trim/gnd4.txt: on both, GND pads OFF the main GND cluster = U3.2 (TLV75533 LDO GND), U2.1 (TPS2116 power mux), Q1.3 (FS8205A battery-protection FET), C3.2 10u, C4.2 22u, C6.2 22u, C25.1, C26.2, R16.1, R51.2, R77.2, H5.1, and two J7 shell pads "9".
  Main cluster holds U4 (ESP32) 1/40/41, J1 USB-C GND, C21.2, and J7 pads 6 and 9.
- So on an x3 board the power-section GND reaches the rest of GND ONLY through the micro-SD socket J7 metal shell (duplicate pad "9" tabs, not a copper connection KiCad counts).
  The battery return current (and the charge current) would flow through the SD socket shield. Pre-existing on HEAD, not introduced or worsened by this change; not part of the 3V3 pass criteria.
  Suggest a GND tie below the cut before the next rev (the minor F.Cu island spans x 87.8..97.5, y 62..79.5 right next to main-GND copper), or at least document it.

## Verdict
PASS for the 3V3 acceptance test: CONTROL reproduces the island (3V3 unconnected, Q2.2 + R81.2 isolated); FIX has zero unconnected 3V3 items in both trim variants, and geometry puts Q2.2 and R81.2 in the U3 (TLV75533PDBV) pad-5 3V3 cluster.
No FIX-only unconnected items or new error classes. FIX-only: one track_dangling warning (1 um micro-segment at (101.000..101.001, 64.900)), also present on the untrimmed board.
Warn: pre-existing x3 GND split bridged only by the J7 shell (F4/F5).
Note: kicad-cli on the untrimmed boards reports 10 (new) / 12 (HEAD) non-excluded J1 USB-C pad-to-pad clearance errors (0.15 vs 0.2 mm Power netclass); pre-existing, the pairs reshuffle between runs.

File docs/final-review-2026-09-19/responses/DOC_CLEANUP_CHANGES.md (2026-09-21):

# Doc clean-ups — every modification, one line each

Format: `file §section — before → after — why (finding ID)`
Four files touched: `README.md`, `docs/HARDWARE.md`, `fabrication/README.md`, `NOTICE` (no change needed).
Nothing was committed. No KiCad, BOM, production or fabrication CSV/py file was touched.

## docs/HARDWARE.md

1. §1 What Silkscreen is — `GDEQ426T82` (x4) → `GDEQ0426T82`; added the missing `-T01C` row and a sentence saying the base number is `GDEQ0426T82` and the suffix picks the variant — base part number was wrong and the scheme was never stated (DOCS-21)
2. §1 Optional-by-design — "Touch — only for `-FT01C`-class panels" → "only for `-T01C` / `-FT01C` panels" — `-T01C` is also a touch panel (DOCS-21)
3. §1 Optional-by-design — RTC line now names `U14` as the alternate footprint; added an "Expansion header (`J6` + `U8`/`CR2`/`CR3`)" bullet — U14 exists now; J6's protection was not associated with J6 (HMI-22, item 8)
4. §3.1 USB-C input — "`J1` is a 14-pin USB 2.0 Type-C receptacle" → "a USB 2.0 Type-C receptacle … the ordered GCT `USB4085-GF-A` has **16 contacts**, not 14" — wrong contact count (USB-15)
5. §3.1 `D1` blockquote — "~1 nA reverse leakage" → "~1 nA … **at 25 °C** (0.05 µA at 85 °C, 0.15 µA at 105 °C)" — that was the 25 °C figure only (USB-17)
6. §3.1 hot-plug blockquote — "TI's own TP4056 datasheet" → "the TP4056 datasheet … (the TP4056 is not a TI part)" — wrong attribution (USB-16)
7. §3.3 protection table — one row "Over-current / short | 150 mV | both open" → two rows: over-current (V_OIP 120/150/180 mV) opens the **discharge FET only**, and a separate short-circuit row (V_SIP 1.00–1.35 V) — the DW01A does not open both FETs, and the two thresholds were merged (BAT-14)
8. §3.3 residual drain — "`R56`+`R57` divider draws ~4 µA" → "≈**8 µA of resistors** (~10 µA with the DW01A's standby)", naming `R79`/`R80` as the second network outside the FETs — understated by 2x (BAT-15)
9. §3.5 LDO blockquote — "thermal behavior **on battery** at high sustained load is a qualification item" → "**on USB** … ≈1.55 V drop, T_J past 125 °C at ~280 mA, treat ~250 mA as the USB ceiling; on battery it is a non-issue" — the thermocouple was pointed at the benign case (PWR-15)
10. §3.5 headroom blockquote — deleted "the bulk capacitance … should ride out a short Wi-Fi-TX current pulse" → "**do not expect the bulk capacitance to cover a Wi-Fi TX burst** — 40 µF holds 355 mA for ~5.6 µs; the LDO supplies the whole burst" — the capacitors hold for microseconds, not for the pulse (PWR-16)
11. §3.6 battery monitoring — "(~7 mV at 50 mA, ~73 mV at 500 mA)" → "≈0.24–0.27 Ω → **12–14 mV at 50 mA, 120–135 mV at 500 mA** (up to ≈175 mV)", noting the old figure wrongly counted `U2` — offset understated ~2x (PWR-17)
12. §3.7 USB_STAT table — replaced the "No battery fitted (blinks) | CHRG + STDBY | ~0.45–0.53 V" row with "Charge complete, weak USB | ST + STDBY | 0.53 V", renamed the idle row, and added a paragraph naming the four normal levels 1.98 / 1.19 / 0.60 / 3.30 V — the old row merged two unrelated states and there was no row for ST+STDBY (USB-18, USB-19)
13. §3.7 no-battery paragraph — "The 'no battery' state is a real TP4056 behaviour … blinking CHRG" → "**There is no steady 'no battery fitted' level**: no cell at plug-in reads a steady **3.3 V**; the **0.60 / 0.45 V** alternation happens only if the cell is unplugged while USB is present" — now agrees with §13.1's firmware contract (USB-18, USB-19)
14. §6.2 charge pump — "`R15` (10 k) pulls `Q4`'s gate down" → "`R15` (**1 MΩ**) … **changed from 10 kΩ**; 1 MΩ matches Good Display's reference circuit (`GDEQ0426T82` datasheet §8.2, `R1` = 1 M)" — part changed today (item 8)
15. §5 Storage — new paragraph before the socket-footprint block: the battery sits in the cut-out in front of `J7`, so it is lifted or slid aside to change the card, and that is intended — author's intent was undocumented (SD-V03)
16. §7 frontlight — "`R37` = 15 Ω sets a ~13.3 mA ceiling" → "… **at full `ADIM` duty**" — the figure only holds at 100 % duty (LED-07)
17. §9.1 ladder table — `SW8` "CONFIRM" → "OK"; the row-order line now says "BACK · OK · LEFT · RIGHT (the board silkscreen prints `OK`)" — board silk says OK (LAY-D4)
18. §9.1.1 front-mounted buttons — `SW8` "CONFIRM" → "OK" in the intro and in the idle-current table — same (LAY-D4)
19. §9.1.1 tab paragraph — added: the four netless `F.Cu` tabs are intentional, KiCad's dangling-track warnings are expected, and they are a DIY hand-solder feature, not something a fab should populate — author's intent (item 10)
20. §9.2 power button — "`R72`/`R73`/`R74` are 0 Ω configuration jumpers" → "`R73`/`R74` are 0 Ω jumpers; **`R72` is 10 kΩ, not a 0 Ω link**" — wrong value (MCU-20)
21. §10 RTC — lead-in now says the three VBAT-only consequences apply to `U13`; added a paragraph for **`U14` `RV-8263-C7`**: DNP by default, fit either `U13` or `U14` never both, addresses 0x68 vs 0x51 so no bus conflict, marked `<!-- confirm once U14 is final -->` — new footprint added today (item 8)
22. §11 expansion header pin table — Power row: "`P+` raw battery (12)" → "(12, PPTC-fused — see the rules below)" — new `F2` in series with pin 12 (item 7c)
23. §11 ESD paragraph — added "Which of those go away with `J6`": **`U8`, `CR2`, `CR3` come off with `J6`**; `U9` does not (it also covers SD `DAT0`/`DAT1`); `D3`/`D8` do not (they clamp the front-light nets `LED_SW`/`W−`/`C−`) — protection was not tied to J6's optionality (HMI-22)
24. §11 — new subsection "Rules for anything you plug into `J6`": (1) never pull/drive `IO45` or `IO46` HIGH at power-up or reset, the module will not boot until the accessory is unplugged, use `IO3` for anything that idles high; (2) an external LED string with V_f below the battery voltage is unregulated — it conducts through `L2` and `U10`'s body diode with the driver off, ~43 mA into a single 3 V LED on USB, so use ≥3 LEDs / V_f > 6 V; (3) pin 12 is raw battery positive, **fused by a 0.75 A PPTC** (`0805L075WR`), marked `<!-- confirm once F2 is on the board -->` — rules were undocumented (HMI-02, LED-02, item 7c)
25. §16 Enclosure — added a bullet: the module's PCB antenna overhangs a cut-out with no copper beneath it; keep ~10 mm of air, do not lay the battery over it, no screw bosses, metal inserts, magnets or display backplane in that corner — case designers had no warning (MCU-21)
26. §16 Enclosure — added a bullet: the battery sits in front of the microSD slot, design for lifting it aside (SD-V03)
27. §16 — new "Enclosure dimensions" table (21 rows: outline, cavities, panel, bosses, button centres, apertures, battery bay, antenna keep-out, both slots, cut line) pointing at `mechanical/silkscreen_pcb.step` as authoritative — section had no dimensions (MEC-21)
28. §16 dimensions table — tongue-neck slot listed as the **single 5.30 × 1.10 mm** slot at x 89.59–94.89, y 61.40–62.50; the old four 0.5 mm slots are quoted nowhere — board changed after the review evidence (MEC-21)
29. §16 Frontlight load — added "**13.3 mA at full `ADIM` duty is the correct figure everywhere**", noting the schematic's ~14 mA and the silk's 15 mA are older numbers — three figures in three places (LED-07)
30. §16 Button geometry — "BACK · CONFIRM · LEFT · RIGHT" → "BACK · OK · LEFT · RIGHT", with a parenthetical that earlier drafts said CONFIRM (LAY-D4)
31. §16 — new subsection "Things that look like mistakes and are not": the four dangling `F.Cu` stubs, the empty mirrored silk text box at the tongue neck = the cut line, `H2`/`H5` intentionally out of line, `D2` is a USB-power-present indicator not a charge indicator, and `U10`/`J3`/`U14` use modified stock symbols so `lib_symbol_mismatch` ERC warnings are expected — author's intent notes (item 10)
32. Appendix passive-case table — `C4`/`C6`/`C32` row now names the Murata `GRM21BR61E226ME44L` prime (Samsung `CL21A226MAQNNNE` obsolete at DigiKey) and JLC `C45783`; added a `C2` row: **now a 25 V part** (Samsung `CL10A106MA8NRNC`, LCSC `C96446`, JLC Basic), was 10 V — parts changed today (item 8)
33. Appendix IC table — added the `U14` `RV-8263-C7` row, DNP, "fit either `U13` or `U14`, never both", marked `<!-- confirm once U14 is final -->` (item 8)

## README.md

34. What it is → Screen — added "`GDEQ0426T82` is the base part number and the suffix picks the variant — `-T01C` touch, `-FL01C` front light, `-FT01C` both — so always order by the full suffixed number" (DOCS-21)
35. What you need → microSD card — added that the battery sits in the cut-out in front of the card slot and is lifted or slid aside to change the card, and that this is intended (SD-V03)
36. Step 2 item 5 — "the four narrow slots … 0.5 mm wide, narrower than the factory's usual 1.0 mm minimum … a DFM message … is safe to accept" → "the **two** narrow slots … the long one 47.04 × 1.30 mm, the tongue-neck one **5.30 × 1.10 mm**, both at or above JLCPCB's 1.0 mm minimum, so neither should raise a DFM message" (MEC-21)
37. Choosing a configuration → Core row — "power switch `SW10`" → "power button `SW10`" (MCU-22)
38. Choosing a configuration table — Expansion header references "`J6`, `U8`" → "`J6`, `U8`, `CR2`, `CR3`" (HMI-22)
39. Choosing a configuration table — RTC row now reads "`U13`, `C30` (or `U14` instead of `U13`)"; added an "Alternate RTC | `U14` (**DNP in every standard build**)" row marked `<!-- confirm once U14 is final -->` (item 8)
40. Choosing a configuration → Notes — added a bullet: `U8`/`CR2`/`CR3` come off with `J6`; do **not** remove `U9`, `D3` or `D8` and why (HMI-22)
41. The board and your case — added a bullet: the module's PCB antenna overhangs a cut-out with no copper under it; no battery over that corner, no screws, metal inserts or display backplane near it (MCU-21)
42. Specifications → Input — "power (`SW10`)" → "a wake/power **button** (`SW10` — a wake input, not a hardware power switch; the 3.3 V rail is always live)" (MCU-22)
43. Specifications → RTC — added "A second footprint (`U14`, Micro Crystal RV-8263-C7) is DNP — fit either, never both", marked `<!-- confirm once U14 is final -->` (item 8)

## fabrication/README.md

44. Intro — dropped the stale "(2026-09-18, …)" date from "The current source"; added "Re-count after the in-progress revision: it adds the `U14` RTC alternate (DNP) and an `F2` PPTC on `J6` pin 12" — the date did not match the repo (DOCS-22)
45. Release records → Gerbers/drills — "The 2026-09-18 12:22 zip was verified …" → "The committed zip (2026-09-19, commit `c0eccde`) was verified … at that commit. Re-verify after any board change" (DOCS-22)
46. Release records → Matched order — the `.xls` row is now labelled "**local only, not tracked in this repository**", matching what the root README already says (DOCS-22)
47. Assembly checklist — "The four 0.5 mm 'perforation' polygons … below JLC's 1.0 mm minimum … to be replaced by a single wider slot in the next board revision" → "The tongue neck is now a **single 5.30 × 1.10 mm slot** (x 89.59–94.89, y 61.40–62.50) … no slot DFM note is expected now" (MEC-21)

## NOTICE

48. No change. Checked for naming: the title says "Silkscreen", the source location is `https://github.com/iandchasse/silkscreen-pcb`. Both are the right names in the right context.

## Naming sweep (DOCS-19) — what was checked and left alone

- `de-link` / `de-link.me` in `README.md:10` and `:439`, and `docs/HARDWARE.md` §15 "What changed from de-link" — correct context (de-link is the earlier prototype), left as is.
- `silkscreenreader.com` in `README.md` — the site, correct.
- `silkscreen-pcb` in `NOTICE` — the repo, correct.
- `silkscreen_pcb.kicad_*`, `silkscreen_pcb_schematic.pdf`, `silkscreen_pcb_layout.pdf`, `silkscreen_pcb.step`, `Silkscreen_Reader_PCB_1.0.zip` — file names, left as is.
- No occurrence of `minRead` / `minread` in any of the four files.

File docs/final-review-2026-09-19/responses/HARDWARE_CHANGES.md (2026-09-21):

# HARDWARE.md — targeted corrections and firmware contract

Change log for the edits applied to `docs/HARDWARE.md` in response to the 2026-09-19 final review and
the author's refutations (`author_refutes.json`). Line numbers are **post-edit** unless stated.
No `*.kicad_*`, `production/`, `fabrication/` or `DESIGN_REVIEW.md` file was touched.

---

## 1. MCU-19 — "GPIO46 is input-only" is factually wrong for the ESP32-S3

The ESP32-S3 has **no input-only pins**; `GPIO34`–`GPIO39` on the *original* ESP32 were the input-only
set. `IO46` is a normal bidirectional GPIO that happens to be a strapping pin with an internal
pull-down, and must read LOW at reset.

| File | Line | Before | After |
|---|---|---|---|
| `docs/HARDWARE.md` | 489 (§4, "Strapping and JTAG-overlapped pins") | `` `IO46` is input-only. `` | `` `IO46` is a **normal bidirectional pin** — the ESP32-S3 has no input-only pins (those were `GPIO34`–`GPIO39` on the original ESP32) — but it *is* a strapping pin with an internal pull-down, and it must read **LOW at reset**. `` |
| `docs/HARDWARE.md` | 1052 (§11, expansion-header pin categories table) | `` \| Spare GPIO \| `IO46` (2, input-only strap), … \| `` | `` \| Spare GPIO \| `IO46` (2, strap — internal pull-down, must be LOW at reset), … \| `` |
| `docs/HARDWARE.md` | 1121 (§13, complete GPIO map, row 16) | `` \| 16 \| IO46 \| — \| Spare → `J6` pin 2 (input-only strap) \| `` | `` \| 16 \| IO46 \| — \| Spare → `J6` pin 2 (strap; must read LOW at reset) \| `` |

**README.md: no change needed.** `grep -n -i "input-only\|input only\|IO46\|GPIO46"` over `README.md`
returns **zero hits** — the claim is not in that file, so nothing was edited there (which also avoids
colliding with the concurrent README restructure).

**Still wrong, and out of my scope:** `DESIGN_REVIEW.md` line 288 still reads *"GPIO46 is input-only."*
That file is on the do-not-touch list. See "Left for the author" below.

---

## 2. Charge current — "255 mA" was being stated as established

| File | Line | Before | After |
|---|---|---|---|
| `docs/HARDWARE.md` | 231–234 (§3.2) | *"…i.e. roughly **234–255 mA** depending on which datasheet constant you trust; treat this as **~0.25 A intended and measure the actual lot** rather than an exact 255 mA."* | *"…i.e. **about 0.23–0.25 A** (the TP4056 datasheet formula, `I = 1100/R_PROG`, gives **234 mA**) depending on which datasheet constant you trust. This is **lot-dependent — measure it** rather than treating any single figure as established."* |

The lead-in "**Charge current ≈ 0.25 A.**" and the dissipation arithmetic that follows were left alone —
both are still correct at 0.23–0.25 A. `grep -n "255"` over `docs/HARDWARE.md` now returns nothing.

---

## 3. §6.2 EPD boost loop area — the ≈33 mm² figure is not reproducible

| File | Line | Before | After |
|---|---|---|---|
| `docs/HARDWARE.md` | 667–670 (§6.2, the `L1` move) | *"The move made the boost loop slightly **larger, not smaller**: `EINK_SW` copper is now 15.4 mm (was 16.5 mm, no vias), but the `C10`→`L1`→`Q4`→`R14` pad-centre loop area **grew from ≈24 mm² to ≈33 mm² (+36 %)**, because the inductor body is bigger."* | *"The move did **not** shrink the boost loop: `EINK_SW` copper is now 15.4 mm (was 16.5 mm, no vias), but the `C10`→`L1`→`Q4`→`R14` pad-centre loop area is **roughly 20–27 mm²** — the exact figure depends on how the four pad centres are joined, and an earlier **≈33 mm² (+36 %)** quoted here is not reproducible — against ≈24 mm² before, because the inductor body is bigger."* |

The sentence's point is kept: the `L1` move did not buy a smaller loop. What changed is that the
board no longer claims a precise +36 % that a pad-centre polygon does not reproduce, and the
following sentence ("a modest EMI/ripple penalty, not a functional problem") still reads correctly.

---

## 4. §9.1.1 front-button solder-bridge tabs — both numbers, as the author asked

Answers **LAY-D1 / LAY-07 / HMI-13**, where the author's refutation was *"the 0.30 mm was designed as
the distance between exposed copper… please report both numbers."* Both are now in the text.

| File | Line | Before | After |
|---|---|---|---|
| `docs/HARDWARE.md` | 913–919 (§9.1.1) | *"Each tab stops **0.3 mm short** of its ring, with the solder mask opened over the tab tip, so a small blob of solder from an iron closes the gap."* | *"Each tab stops short of its ring by two different measurements, and both matter. **Exposed copper to exposed copper is 0.30 mm** — the 0.6 × 0.6 mm `F.Mask` window on the tab tip to the ring's own mask opening, with mask expansion set to 0 — and that is the gap a solder blob actually has to cross. **Copper edge to copper edge, underneath the solder mask, is 0.151–0.188 mm**, because the mask window sits entirely on the 0.8 mm tab; the board's minimum clearance rule is 0.15 mm, so this is inside the rule but with very little to spare. With the solder mask opened over the tab tip, a small blob of solder from an iron closes the gap."* |

---

## 5. New §13.1 — "Firmware contract — things the board needs firmware to do"

No firmware section existed (`grep -n -i "firmware"` found only scattered cautions inside §3.7, §4 and
§7), so this is a **new subsection**, added at the end of §13 rather than as a new top-level section,
so nothing had to be renumbered.

| File | Line | Change |
|---|---|---|
| `docs/HARDWARE.md` | 72 (table of contents) | Added sub-entry `- 13.1 [Firmware contract — things the board needs firmware to do](../../HARDWARE.md#131-firmware-contract--things-the-board-needs-firmware-to-do)` under item 13 |
| `docs/HARDWARE.md` | 1148–1197 | New `### 13.1 Firmware contract — things the board needs firmware to do` inserted after the "All five analog signals are on ADC1" paragraph and before the `---` / `## 14. Design themes` |

### Bullets and the findings they answer

| Bullet | Answers | Checked against |
|---|---|---|
| `USB_STAT` idle threshold `> 2.6 V`, not `> 3.10 V`; nominal 1.98 / 1.19 / 0.60 / 3.3 V | **USB-01** (and its doc half **USB-14**) | `sections/01_usb_input_power_path.md` L296, L322–337, L730 — ATTEN3 range 0–2900 mV ±50 mV (datasheet Table 5-6); nothing between 2.07 V and 3.27 V |
| Accept `0.85–1.35 V` charging and `0.40–0.70 V` complete for the weak-USB cases 0.96 V / 0.53 V | **USB-02** | `sections/01…` L233–238, L297, L731 — state E (`ST`+`CHRG`) = 0.956 V, state F (`ST`+`STDBY`, VBUS < ~4 V) = 0.531 V |
| Require a stable reading for seconds before reporting "charged"; no-battery blink 0.60 V ↔ 0.45 V; cold plug-in with no cell reads a steady 3.3 V | **USB-V02**, **USB-18** | `sections/01…` L317, L613 — 0.595 V "complete" and the blink's high half are *the same pin state* by construction; CHRG+STDBY = 0.450 V; `CE` gate keeps the charger off at a cold plug-in |
| `ADIM` is the enable: first HIGH pulse ≥ 40 µs (`tADIM_EN`), LOW > 2.5 ms (`tADIM_SD`) shuts down; drive HIGH ≥ 100 µs then start the carrier | **LED-14** | `sections/07_led_frontlight_driver.md` L244–255, L297, L611 — TI SNVSCN8 §6.5; 25 kHz/50 % gives only 20 µs |
| OVP latches after three trips; recover with `PWM_LED` LOW > 2.5 ms (≥ 3 ms) or a power cycle; monitor `LED_MONIT`; never enable the boost with `J3` unplugged | **LED-V02** | `sections/07…` L300, L356–366 — SNVSCN8A §7.3.6 / §7.4.2 |
| Colour select only with PWM duty at 0 | **REC-C-01** | `comparison/C_vs_audit_2026-09-16_and_nextpcb.md` L196–215 — `Q5` direct vs `Q6` through `U12`, no guaranteed non-overlap |
| Park the SD bus before gating `SD_VDD` off | **SD-01** | `sections/05_sdmmc_microsd.md` L315, L641 — 3.3 × 100/(100 + 2.007) = **3.235 V** back-feed |
| Deep-sleep wake is RTC-capable `GPIO0`–`GPIO21` only; `IO18` wakes, `IO41` does not, DS3231 `INT`/`SQW` not routed | **HMI-04** (author: *"Doesn't need to. I'm not making an alarm clock."*) | `evidence/blocks/mcu.md` L245 (`IO18` → `PWR_BUTTON`), L268/L542 (`IO41` → `TP_INT`); §13 GPIO map already flags `IO41` as "**not** RTC-wake" |
| 0 V / protection-latched pack will not charge (gate needs ~1.7 V at `J5`); after a protection trip the board restarts only on USB | **REC-A-02**, **REC-B-03** | `comparison/A_vs_DESIGN_REVIEW.md` L273–290 (`Q9` BSS138 Vth 0.5–1.6 V behind a 0.909 divider ⇒ 0.6–1.8 V across the lot, worst case ≈1.7 V); `comparison/B_vs_audit_2026-09-18.md` L308 (`Q8` gate on system `GND`) |

### Pin/net names — all verified, none were wrong

Checked against `evidence/blocks/usb.md`, `led.md`, `sd.md`, `mcu.md`:

| Net | Module pin | Verified in |
|---|---|---|
| `USB_STAT` | `U4.17` = `IO9` (ADC1_CH8) | `usb.md` L239 |
| `PWM_LED` | `U4.35` = `IO42` | `led.md` L206 |
| `COLOR_SEL` | `U4.33` = `IO40` | `led.md` L155 |
| `LED_MONIT` | `U4.38` = `IO2` (ADC1_CH1) | `led.md` L187 |
| `SD_ACTIVATE` | `U4.18` = `IO10` | `sd.md` L126 |
| power button | `U4.11` = `IO18`, net is **`PWR_BUTTON`** (not `PWR_BTN`) | `mcu.md` L245, L486 |
| `TP_INT` | `U4.34` = `IO41` | `mcu.md` L268, L542 |

**One technical refinement to the brief, worth flagging.** The task text said to drive the SD bus
*"LOW or high-impedance"* before gating `SD_VDD` off. High-impedance alone is **not** sufficient if the
ESP32's *internal* pull-ups are left enabled: `sections/05_sdmmc_microsd.md` L641 computes that case
explicitly (5 ∥ 55 kΩ ⇒ `SD_VDD` still sits at **2.97 V**). The bullet therefore says *"LOW as outputs
with the internal pull-ups disabled, hold ≥ 20 ms"*, which is the section's own recommendation.

`SD_ACTIVATE` "HIGH = gate off" is consistent with the §13 GPIO map's existing "(active low)" note —
the gate is *enabled* when the line is low — so both phrasings are kept and do not contradict.

---

## Left for the author (cannot be done from here)

1. **`DESIGN_REVIEW.md` line 288** still says *"GPIO46 is input-only."* — same MCU-19 error, in a
   do-not-touch file.
2. **`DESIGN_REVIEW.md` still describes `Q3`/`Q8` as AO3419** (item 6 of the brief) — do-not-touch file.
   Occurrences: lines **164, 229, 237, 247** (body-diode analysis, the Q8 proposal, the pin table and
   the R<sub>DS(on)</sub>/stress arithmetic). Note the file is already internally inconsistent about
   this: line **201** says *"Applied with `Q_pass` = AO3401A, not the AO3419 named when this table was
   first drafted — AO3401A was already the board's adopted P-channel swap for Q2/Q3/Q7/Q8."* So the
   correction is to make lines 164/229/237/247 agree with line 201, and to re-check the 140 mΩ / 20 V
   numbers on line 247, which are AO3419 figures applied to a part that is not fitted.
3. **The schematic's USB Status note block** still declares `4) Plugged in & Charger Idle/Disabled:
   ~3.30 V [Window: > 3.10 V]` (**USB-14**). `HARDWARE.md` and the schematic now disagree in the
   *opposite* direction from before: the doc is right, the schematic is not. That is a KiCad text-box
   edit (`*.kicad_sch` is on the do-not-touch list).
4. **The `D3` front-light design-note text box** on the schematic says *"Recommended to run between
   10kHz–25kHz via PWM_LED"* without the enable-pulse caveat (**LED-14**) or the OVP latch
   (**LED-V02**). Same KiCad text-box edit.
5. **Measure the actual charge current** on a real board — the §3.2 text now says to, and no document
   can settle it.

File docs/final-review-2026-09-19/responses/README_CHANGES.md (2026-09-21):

# README changes — response to the 2026-09-19 final review

Scope: `README.md` (rewritten) and `fabrication/README.md` (four consistency edits).
Nothing else was touched. No git operations were run.

The README was restructured around the author's refutations in `author_refutes.json`. The old
document opened with an engineering review pointer and buried the ordering path; the new one leads
with what the device is, a picture, what else you have to buy, and the ordering path, and moves
every engineer-only pointer into a final section.

## New structure

```
Silkscreen  (what it is, one paragraph, board photos, "you do not need KiCad")
What it is                                (plain-language bullets)
What you need besides the board           (panel · battery · microSD · USB-C cable + WARNING callout)
Order an assembled board, step by step    (JLCPCB only, 8 steps, cost/lead-time box first)
Choosing a configuration                  (optional-parts table, preserved)
  Getting into download mode
  Cutting the board down for a smaller display
Firmware
The board and your case
Specifications                            (the old "At a glance" table)
Words used on the factory's website       (glossary)
Licence
For engineers / before you modify this design
  Read the review first · Plots and renders · Repository layout · BOM sources · Regenerating the release files
```

## Finding-by-finding

| ID | What was done |
|---|---|
| **DOCS-06** | Restructured as above. `DESIGN_REVIEW.md`, `docs/audit-2026-09-18/` and `docs/HARDWARE.md` pointers now live under *For engineers / before you modify this design*, with a one-line note that nothing there is needed to order a board. The old "Before assembly: read DESIGN_REVIEW.md" opener is gone. |
| **DOCS-11** | Removed the bare terms **"Fix 4"**, **"the Q4 replacement"** and **"the slotted microSD land"** from user-facing text. Added a glossary section (*Words used on the factory's website*) defining Gerber, BOM, CPL/centroid/pick-and-place, PCBA, DNP, SMD/SMT, THT, LCSC code, Basic/Extended part, DFM. Each term is also defined inline the first time it appears in the ordering steps. |
| **DOCS-03 / FAB-10** | The only BOM named anywhere is `production/bom_JLC_upload_v4_optimized.csv`, uploaded with `production/positions.csv` and `production/Silkscreen_Reader_PCB_1.0.zip`. `bom.csv` and `bom_JLC_upload_v3.csv` are no longer presented as options; the old "Pick one BOM, not all three" file table was deleted. No files were deleted from disk. |
| **DOCS-13** | README is now a JLCPCB-only ordering guide. The whole "Ordering from PCBWay or NextPCB" section, the `other_fabs/` file table, the `make_fab_files.py` invocation and the `assembly_drawing_bottom.pdf` reference were removed from `README.md`. `production/other_fabs/` and `fabrication/NEXTPCB_REV0_NOTES.md` were not touched. |
| **DOCS-01 / DOCS-12** | New *Firmware* section: no released firmware for this board yet; planned work is porting the FreeInk SDK and maintaining crosspoint-reader, crossink reader and the other XTEink X4 firmwares; all future work. First-power-up instructions will follow once firmware exists. A one-line pointer to this section sits at the end of *What it is*, so a reader meets it before the ordering path. |
| **DOCS-02** | The silkscreenreader.com *Build one* configurator is presented as "built but behind a site preview, not live yet — if it is not live when you read this, use the steps below". The manual JLCPCB steps are the complete first-class path. The `$29.55` core-configuration price quoted from the site's model and the "Prices in the site's model exclude…" note were removed. |
| **DOCS-04** | New *What you need besides the board* table: display panel variants (as already described), single-cell LiPo with JST-PH 2.0 mm 2-pin plug, microSD card, data-capable USB-C cable. Lead order is stated explicitly: **`J5` pin 1, marked "-", is battery negative; pin 2 is positive; there is no standard, packs ship both ways, check with a meter.** The visible placeholder `TODO(author): link to a known-good pack` is left in the battery row. One line says screws and case belong to individual case designs. |
| **DOCS-05** | One compact `> [!WARNING]` callout (4 lines) directly under the battery lead-order note: reversed/shorted/crushed cells are a fire risk, measure against the "-" mark, use a protected pack, stop using a puffed cell. No further lecturing. |
| **DOCS-07** | "Case agnostic" is gone. *The board and your case* now says the board is meant to work with many case designs of any style, that no reference enclosure is supplied here, gives the STEP path `docs/mechanical/silkscreen_pcb.step`, and lists 60.05 × 111.30 × 1.6 mm, five M2 holes (`H1`–`H5`) and all-parts-on-the-bottom, pointing at `docs/HARDWARE.md`. |
| **DOCS-08** | No URL was invented or changed. Existing links left as they are. Listed for the author. |
| **DOCS-09** | Step 3 now explains it in plain terms: JLCPCB runs two assembly services; **Standard** is needed because the ESP32-S3 module is only placeable under Standard; a builder happy to hand-solder the module could leave it off and use the cheaper Economic service. One sentence on rails: the board is 60 mm wide against Standard's 70 mm conveyor minimum, so JLCPCB may add snap-off edge rails for a small fee — nothing to design, just snap them off. No fiducial talk anywhere. |
| **DOCS-10** | New *What it costs and how long it takes* box, marked a September 2026 snapshot: about **$230–260** for five boards all assembled including parts and shipping, roughly **$47–53 per board**; about **$75** of that is one-off setup/stencil/part-type fees; **2–3 weeks**; panel, battery, microSD and case not included. Numbers from `sections/12_bom_function_and_cost.md` (the bottom-up 5-board model, ≈$233 → $47/board, cross-checked against `fabrication/BOM.md`'s $48–53 from a real 30-board quote). |
| **DOCS-14** | Step 7 is now a costed choice: (a) let JLCPCB solder the 13 THT parts — about $3.60 per-order hand-soldering fee plus ~$0.016 per joint, roughly **$11 of the ~$230 five-board total**, plus about a day; or (b) take them loose and put in about 92 joints per board yourself — USB-C shell pins, JST, 12-pin header, ten switches — with the USB-C shell called out as the fiddly one. |
| **DOCS-15** | Licence section now opens with three plain statements read from `LICENSE`/`NOTICE`: you may build, use, modify and sell it without asking; if you distribute or sell a board based on this design you must publish your design source under CERN-OHL-S v2 and pass on the copyright and licence notice; there is no warranty. Flagged as a plain-language summary, not legal advice, with the licence text governing. The CERN boilerplate block and SPDX id are kept verbatim. |
| **DOCS-16** | The cost box and step 2 now say the bare-board minimum is **5** but assembly can be ordered for as few as **2** — one working reader, one spare, three bare boards left over. The old bare "Minimum quantity is 5" line is gone. |
| **DOCS-17** | "**you do not need KiCad to order a board**" is in the third paragraph of the README, and repeated at the top of the ordering section. Both `kicad-cli` blocks moved to *For engineers → Regenerating the release files*, where they are also labelled a cross-check rather than a replacement for the Toolkit set. |
| **DOCS-18 / LAY-01** | The perforation-slot caution is kept (the current release files still contain the slots) but cut to two sentences, and now ends "**They are to be replaced by a single wider slot in the next revision of the board.**" Same sentence added to `fabrication/README.md`'s assembly checklist, replacing "check how those boards turned out". |
| **DOCS-24** | **Corrected.** The README said "LED pad 1 is the anode" twice. Ground truth: `evidence/sch/connectivity_by_component.txt` has `D2 pin 1 = K`, and `fabrication/BOM.md:196`/`:296` say "pad 1 = cathode"; `fabrication/part_fields.csv:15` confirms `D2` is the `LTST-C150KRKT` / `YONGYUTAI YLED1206R` red 1206. The surviving occurrence (step 6 placement preview) now reads "**Pad 1 is the cathode** (the marked end)". The second occurrence was in the other-fabs section, which is gone. `fabrication/README.md`'s hedged "D2 LED pad-1/anode convention" was corrected to "D2 LED polarity (**pad 1 is the cathode**)". |
| **MCU-01** | New *Getting into download mode* subsection: normally never needed because the ESP32-S3 has native USB; if it is, bridge the two `SW6` (BOOT) pads with metal tweezers while tapping RESET. `SW6` is DNP to save cost. |
| **MEC-09** | One line in the same subsection: `SW11` (RESET) is set back from the edge on purpose, to be pressed through a pin-hole in the case. |
| **LAY-02 / MEC-02 / MEC-V02 / HMI-V02** | New *Cutting the board down for a smaller display* subsection, placed under *Choosing a configuration*: disconnect the battery first (battery positive crosses the cut line); it will not snap by hand, use a rotary tool along the marked line; the cut removes `J6` **and** the power button `SW10`, after which UP(2) serves as the power button with `R36`/`R73` unpopulated and `R72`/`R74` populated, as printed on the schematic and the board; plan the cut before ordering so the removed parts can be left off the BOM. |

## Facts kept unchanged (verified correct by section 13)

- `179 references = 162 fitted + 10 DNP + 7 bare-copper (H1–H5, TP1, TP2)` — kept verbatim.
- `positions.csv` is 162 rows, all bottom side; "Assembly side: Bottom" is the correct instruction.
- The whole optional-parts / configuration table, including the DNP notes and the touch pin-order
  warning, is preserved word for word except for the removed configurator price.
- Every pre-existing link target still resolves. A link and anchor checker
  (`<scratch>/agents/followup_readme/linkcheck.py`) was run over `README.md` and
  `fabrication/README.md` after the edits: **0 broken file links, 0 broken anchors.**

## Other small corrections made in passing

- Panel part number normalised to `GDEQ0426T82` (the README previously used `GDEQ426T82` in the
  spec table and `GDEQ0426T82` further down; Good Display's own part number has the leading zero).
- The undated stock figure "about 189 pcs at last check" for `TPS923610DRLR` was replaced with
  "check its stock" — it would be wrong by the time anyone read it.
- Board dimensions given as 60.05 × 111.30 × 1.6 mm where mechanical precision matters, and
  "about 60 × 111 mm" where the reader is comparing against JLCPCB's Gerber viewer.
- Repository-layout block updated: `docs/mechanical/` added, `production/other_fabs/` row removed,
  `production/` described as "release upload files".

## `fabrication/README.md` edits (4)

1. "the Fix 4 reverse-battery circuit" → "the USB-present reverse-battery gate" (twice); DOCS-11.
2. Root-README anchor `#ordering-from-jlcpcb-step-by-step` → `#order-an-assembled-board-step-by-step`,
   and the dead `#ordering-from-pcbway-or-nextpcb-alternative-to-jlcpcb` pointer replaced with a
   line saying JLCPCB is the only supported route, keeping the `NEXTPCB_REV0_NOTES.md` link.
3. Release-record table: "Upload BOMs … v4 (standard) and v3 (brand-conservative)" →
   "Upload BOM … `bom_JLC_upload_v4_optimized.csv`, **the single BOM to upload**", noting v3 is
   superseded; DOCS-03 / FAB-10.
4. Assembly checklist: D2 polarity corrected (DOCS-24) and the perforation-slot line given the
   next-revision outcome (DOCS-18).

## Left for the author

- **DOCS-08** — the public URL on the board, in `NOTICE` and in both KiCad title blocks points at a
  repository whose default branch holds the old project. No URL was invented or changed here.
- **DOCS-13** — actually deleting `production/other_fabs/`. The README no longer references it, so
  the folder can go whenever you like. `fabrication/NEXTPCB_REV0_NOTES.md` was left in place and is
  still linked from `fabrication/README.md`.
- ~~**DOCS-07** — exporting `docs/mechanical/silkscreen_pcb.step`.~~ The file appeared during this
  pass (7.6 MB, exported 2026-09-20 21:04), so the README now links to it directly and the link
  check passes. Nothing left to do unless the export needs re-doing after a board change.
- **DOCS-04** — replacing the visible `TODO(author): link to a known-good pack` placeholder in the
  battery row.
- **DOCS-02** — taking the silkscreenreader.com configurator out of site preview, after which the
  "not live yet" wording in the ordering section should be softened.
- **DOCS-01 / DOCS-12** — the firmware itself, and the first-power-up / troubleshooting section that
  depends on it.
- **DOCS-18 / LAY-01** — the actual board change (four 0.5 mm slots → one wider slot) in KiCad, and
  regenerating `production/` afterwards.
- The **$230–260 / 2–3 weeks** figures are a September 2026 snapshot from the review's cost model,
  not a quote you have placed. Worth confirming against your own next order and re-dating the line.

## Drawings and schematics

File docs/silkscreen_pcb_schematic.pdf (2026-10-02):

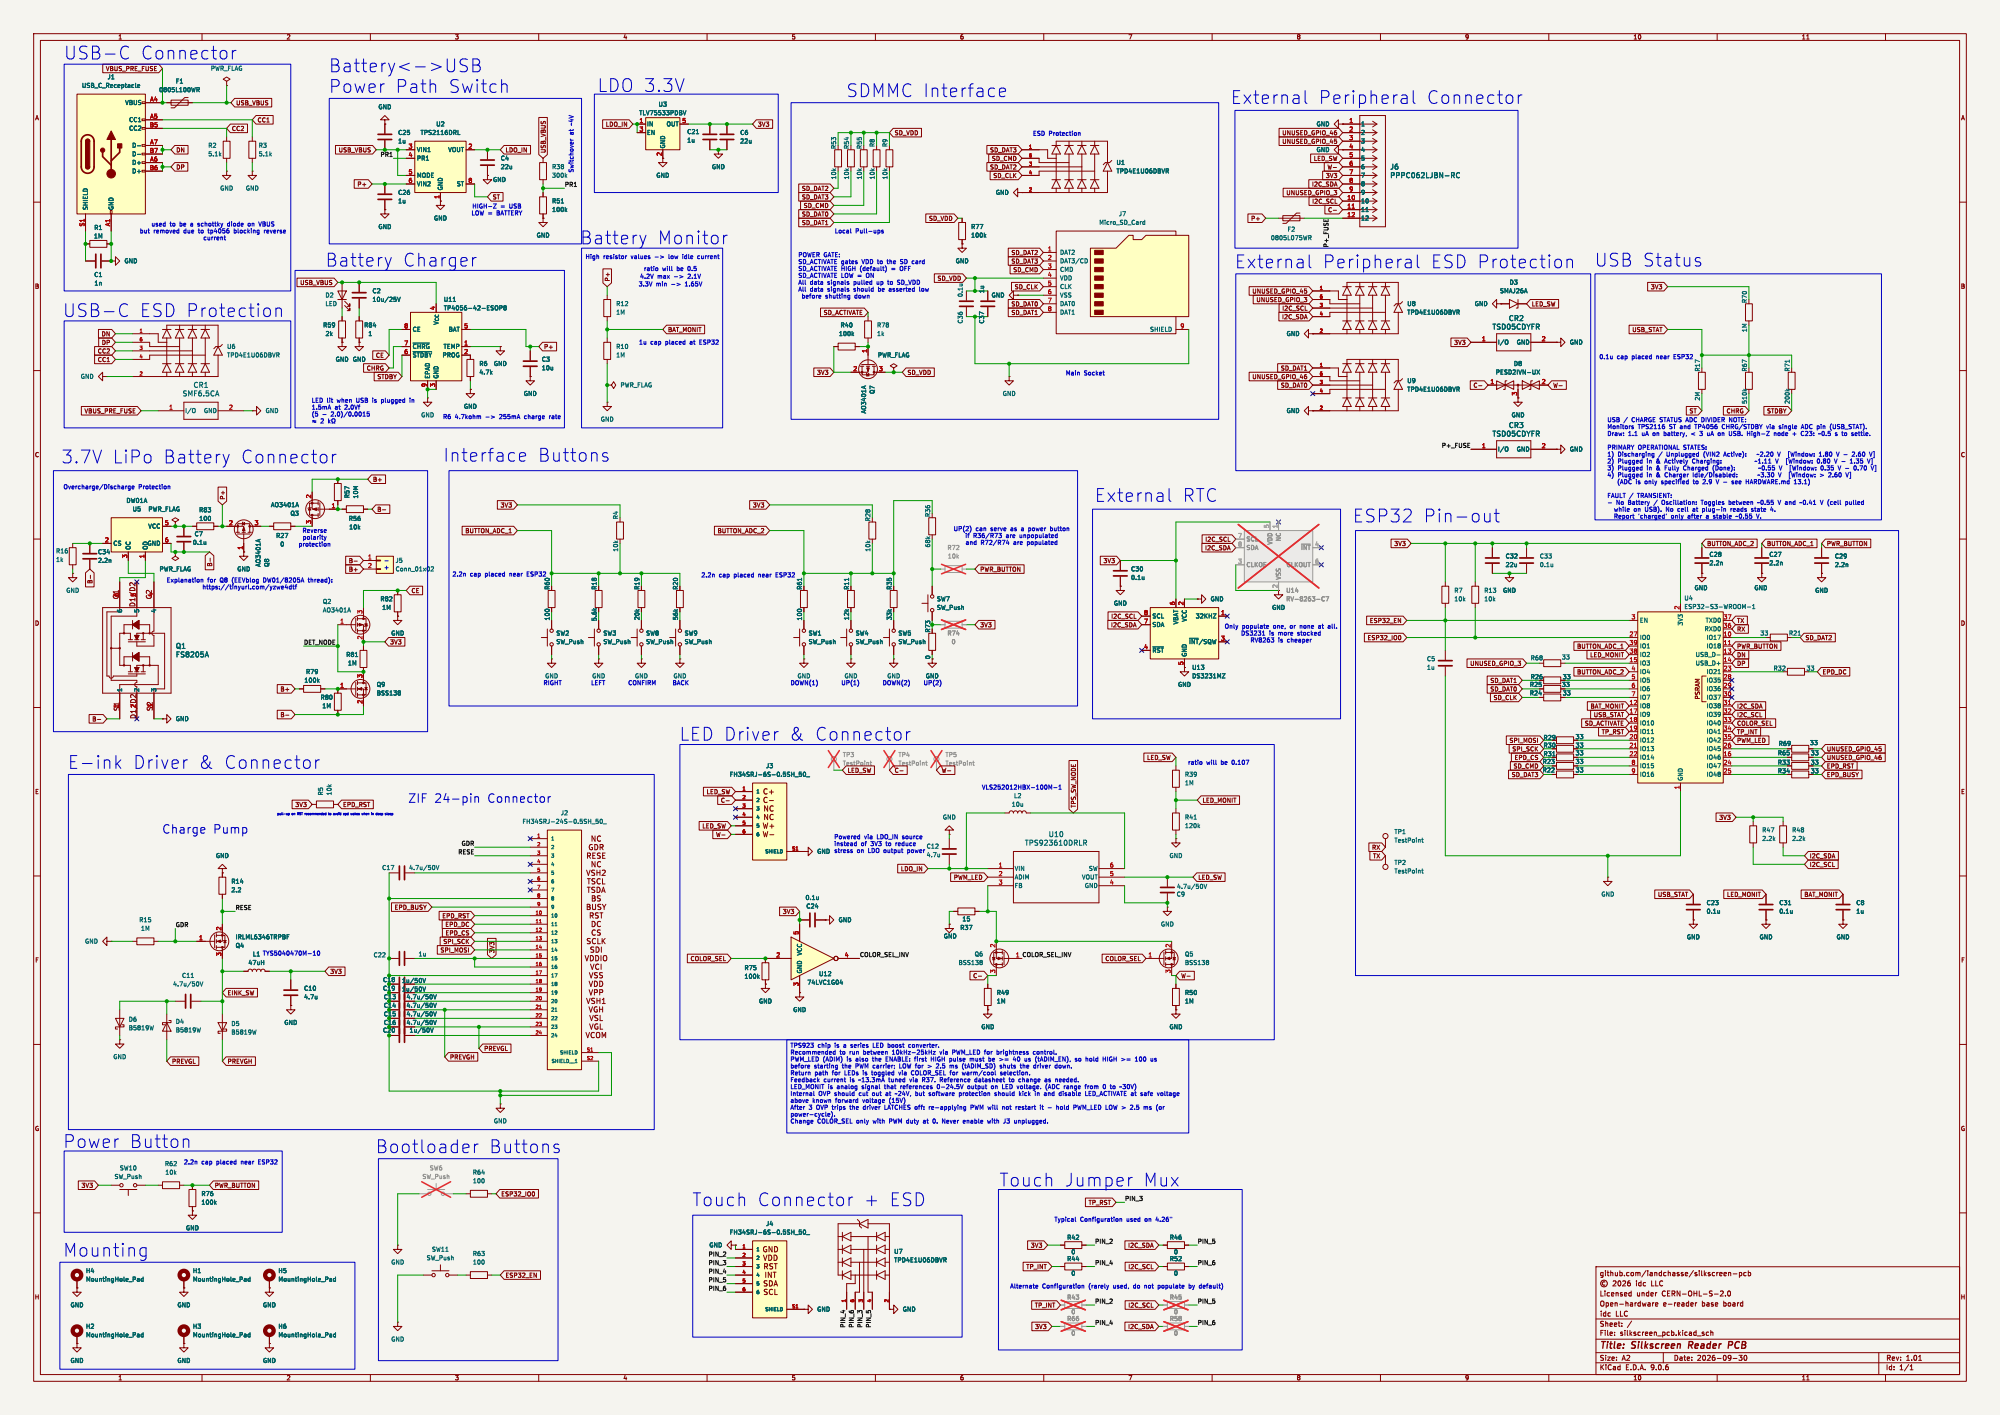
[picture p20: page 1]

1 VOUT 2 ST 8 U2 TPS2116DRL GND GND

1 VOUT 2 ST 8 GND GND

Main Socket Battery Charger

ratio will be 0.5 Mounting
USB-C ESD Protection

All data signals pulled up to SD_VDD
All data signals should be asserted low

3 BAT 5 TEMP 1 PROG 2 GND GND

LED lit when USB is plugged in

UP(2) can serve as a power button

3 2 Q5 BSS138 GND GND GND GND

Change COLOR_SEL only with PWM duty at 0. Never enable with J3 unplugged. TYS5040470M-10 Charge Pump

instead of 3V3 to reduce

2.2n cap placed near ESP32 Power Button

github.com/iandchasse/silkscreen-pcb H3 MountingHole_Pad

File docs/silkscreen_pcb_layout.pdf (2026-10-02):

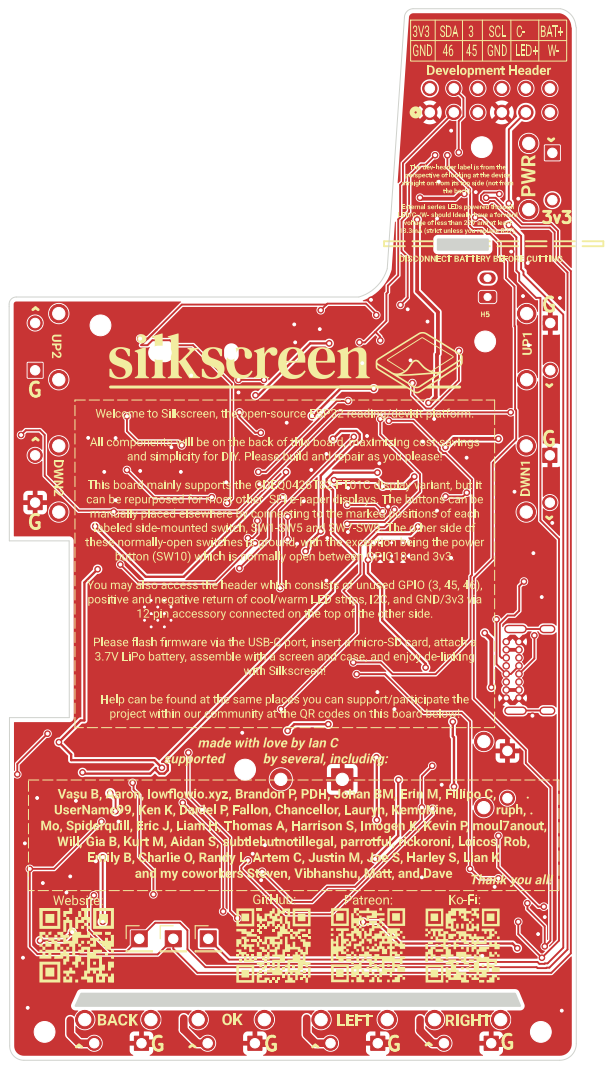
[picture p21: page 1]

J6 | R78
H3 TPD4E1U06DBVR | U8 4.7u/50V

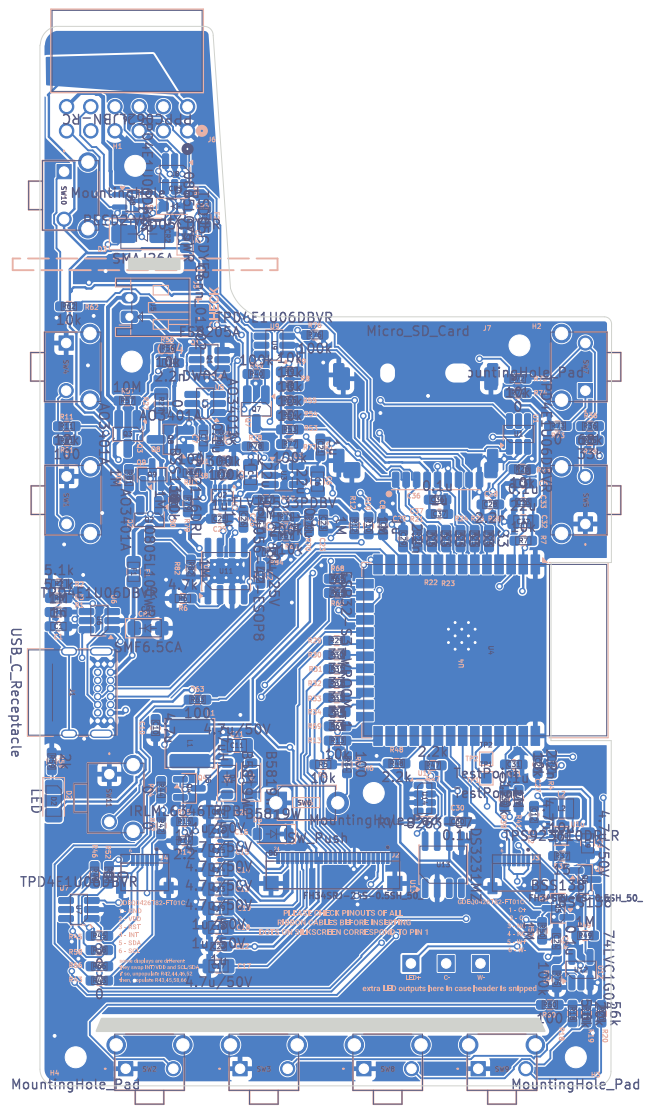
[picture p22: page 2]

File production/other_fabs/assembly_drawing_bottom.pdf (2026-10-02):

1 | 2

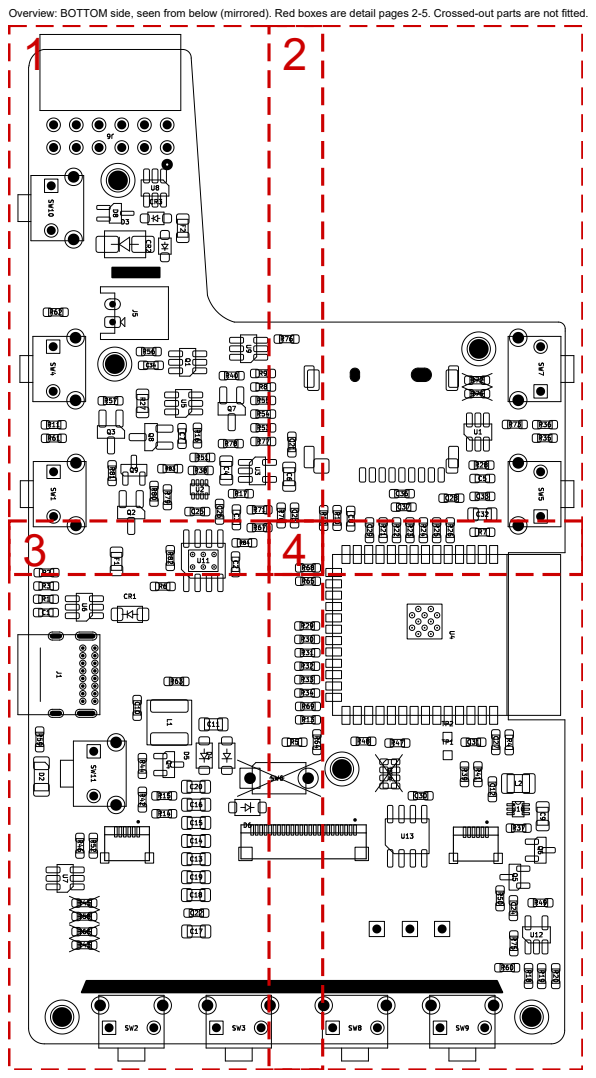
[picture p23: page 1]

Overview: BOTTOM side, seen from below (mirrored). Red boxes are detail pages 2-5. Crossed-out parts are not fitted.

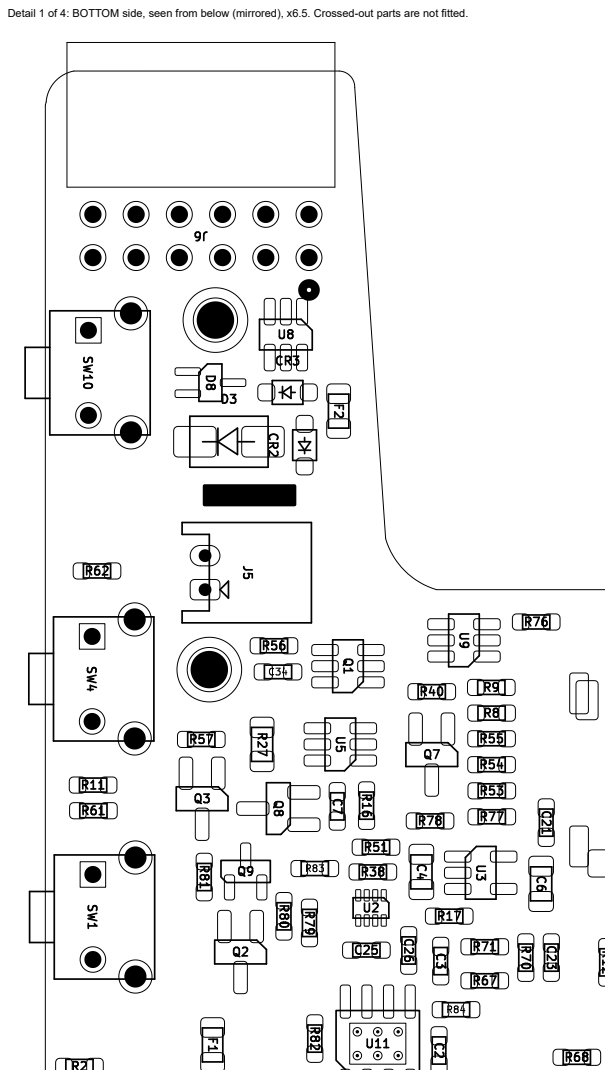
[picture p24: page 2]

Detail 1 of 4: BOTTOM side, seen from below (mirrored), x6.5. Crossed-out parts are not fitted.

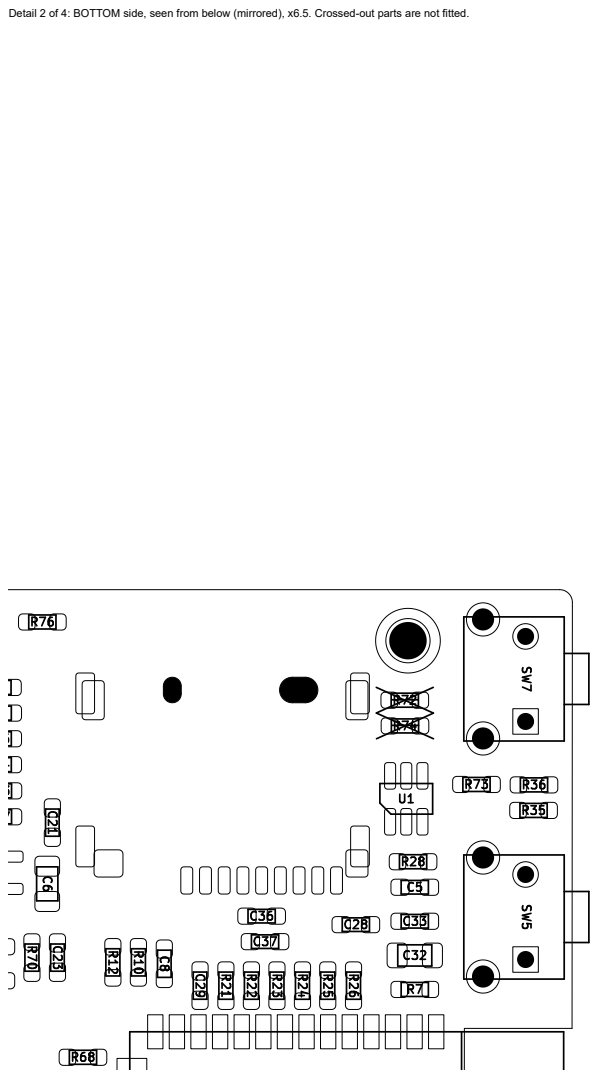
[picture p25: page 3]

Detail 2 of 4: BOTTOM side, seen from below (mirrored), x6.5. Crossed-out parts are not fitted.

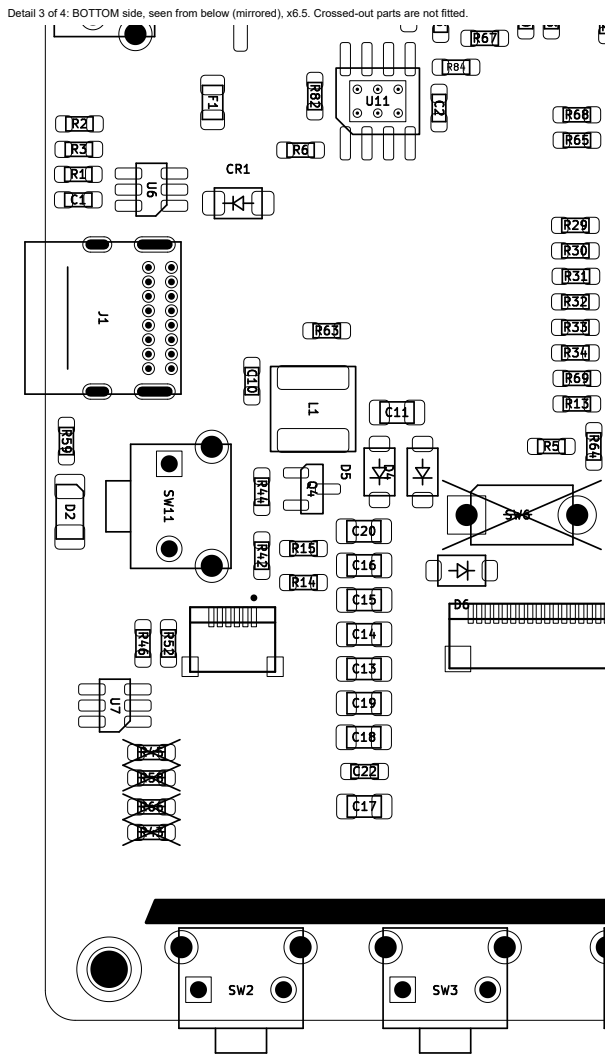
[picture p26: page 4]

Detail 3 of 4: BOTTOM side, seen from below (mirrored), x6.5. Crossed-out parts are not fitted.

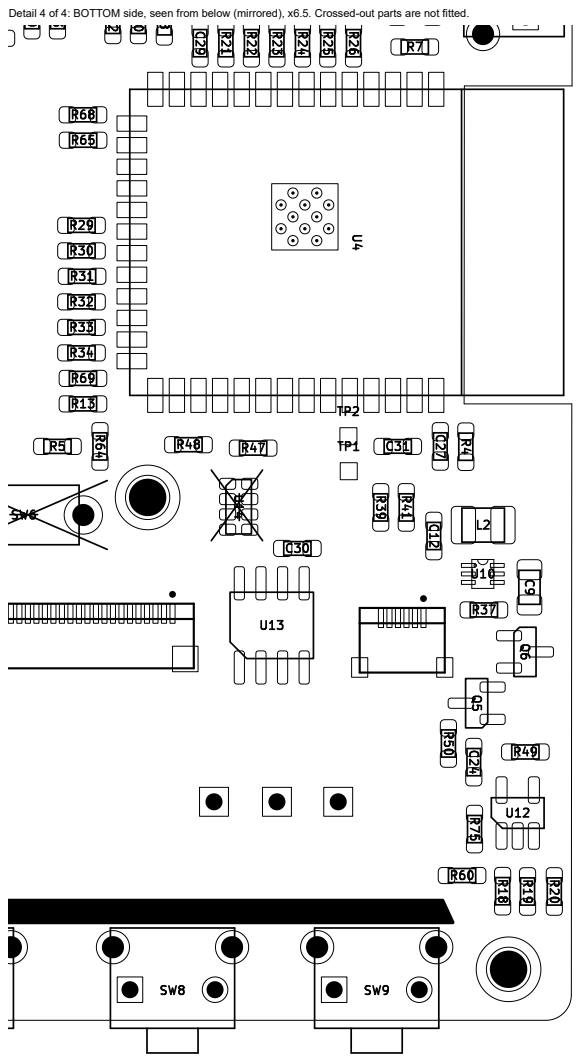
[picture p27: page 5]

Detail 4 of 4: BOTTOM side, seen from below (mirrored), x6.5. Crossed-out parts are not fitted.

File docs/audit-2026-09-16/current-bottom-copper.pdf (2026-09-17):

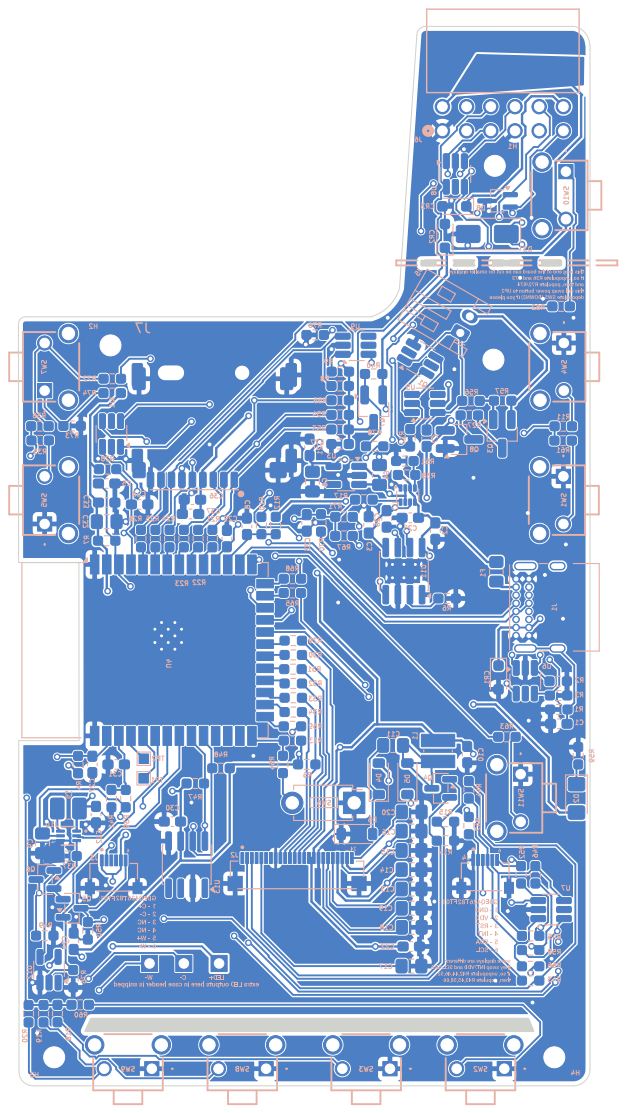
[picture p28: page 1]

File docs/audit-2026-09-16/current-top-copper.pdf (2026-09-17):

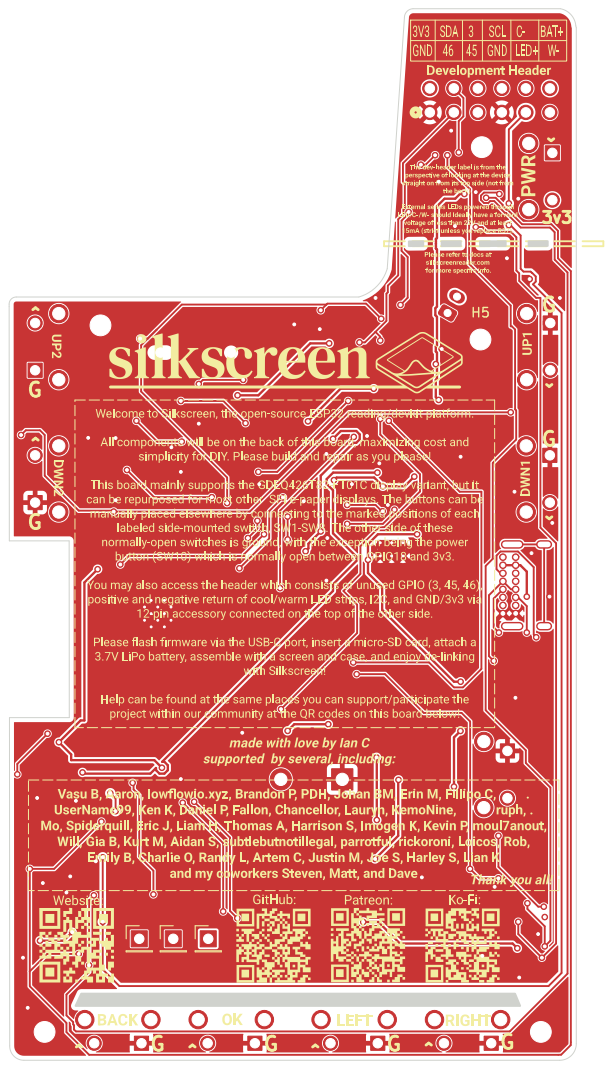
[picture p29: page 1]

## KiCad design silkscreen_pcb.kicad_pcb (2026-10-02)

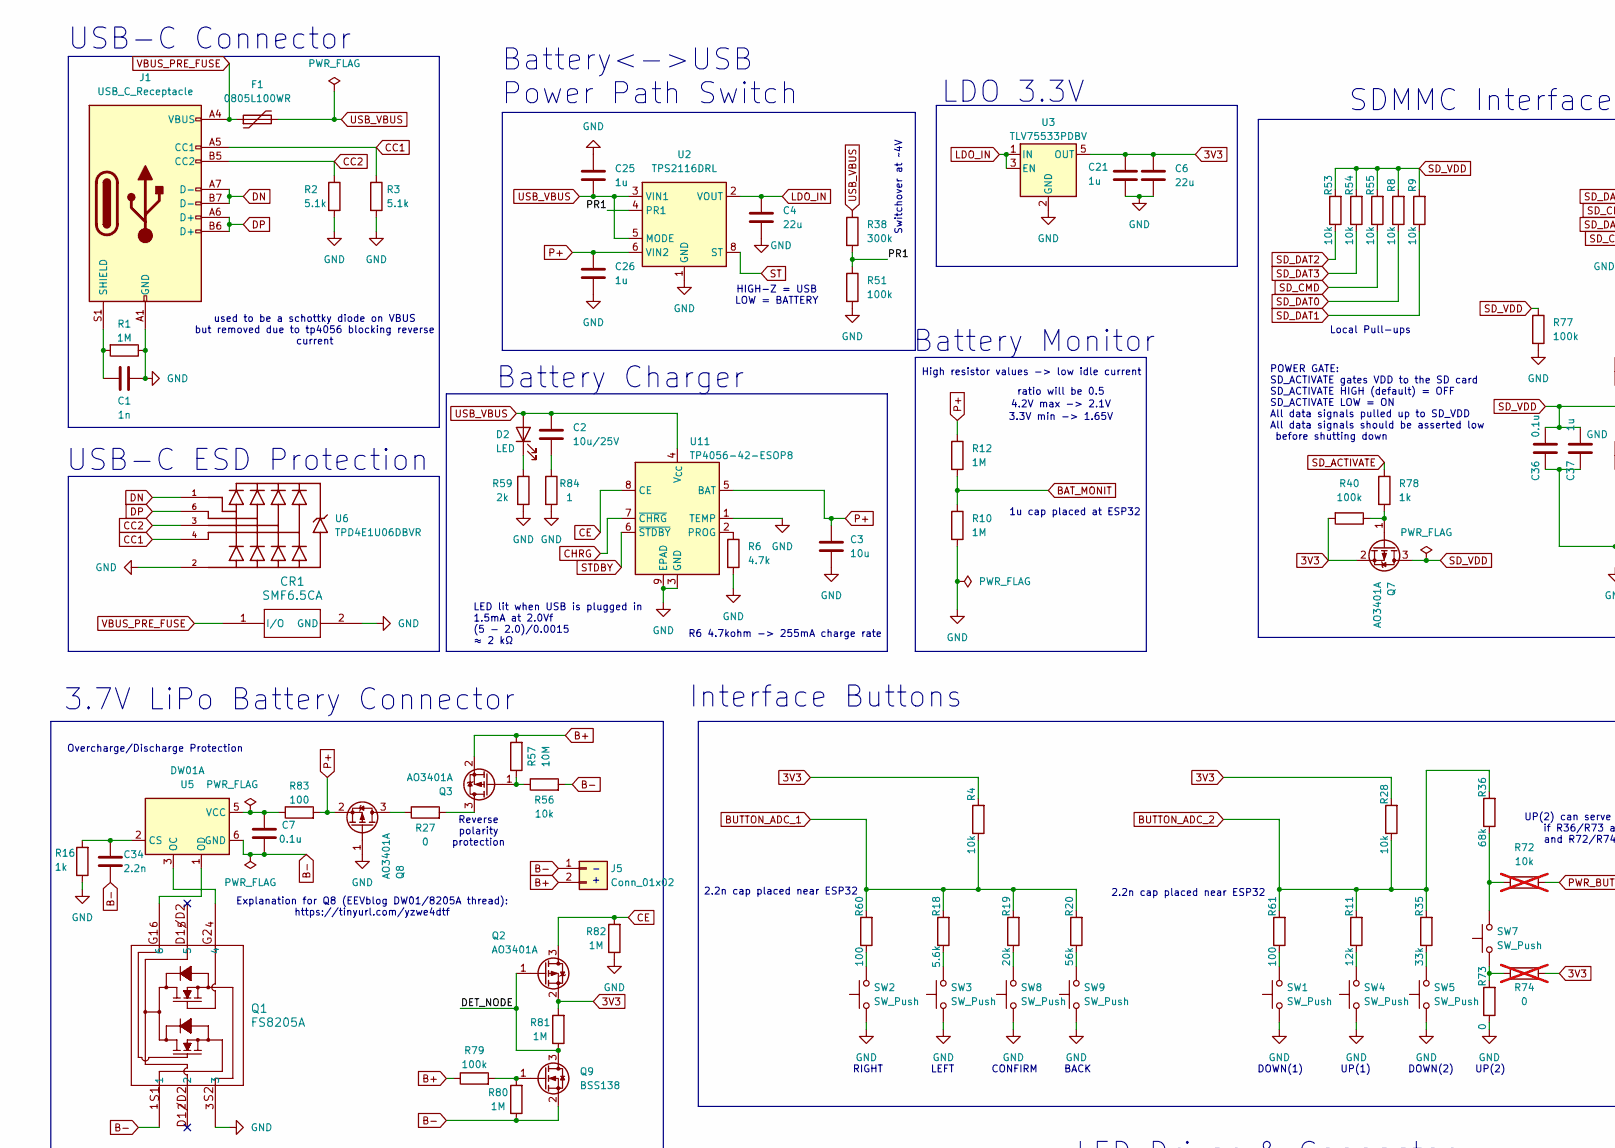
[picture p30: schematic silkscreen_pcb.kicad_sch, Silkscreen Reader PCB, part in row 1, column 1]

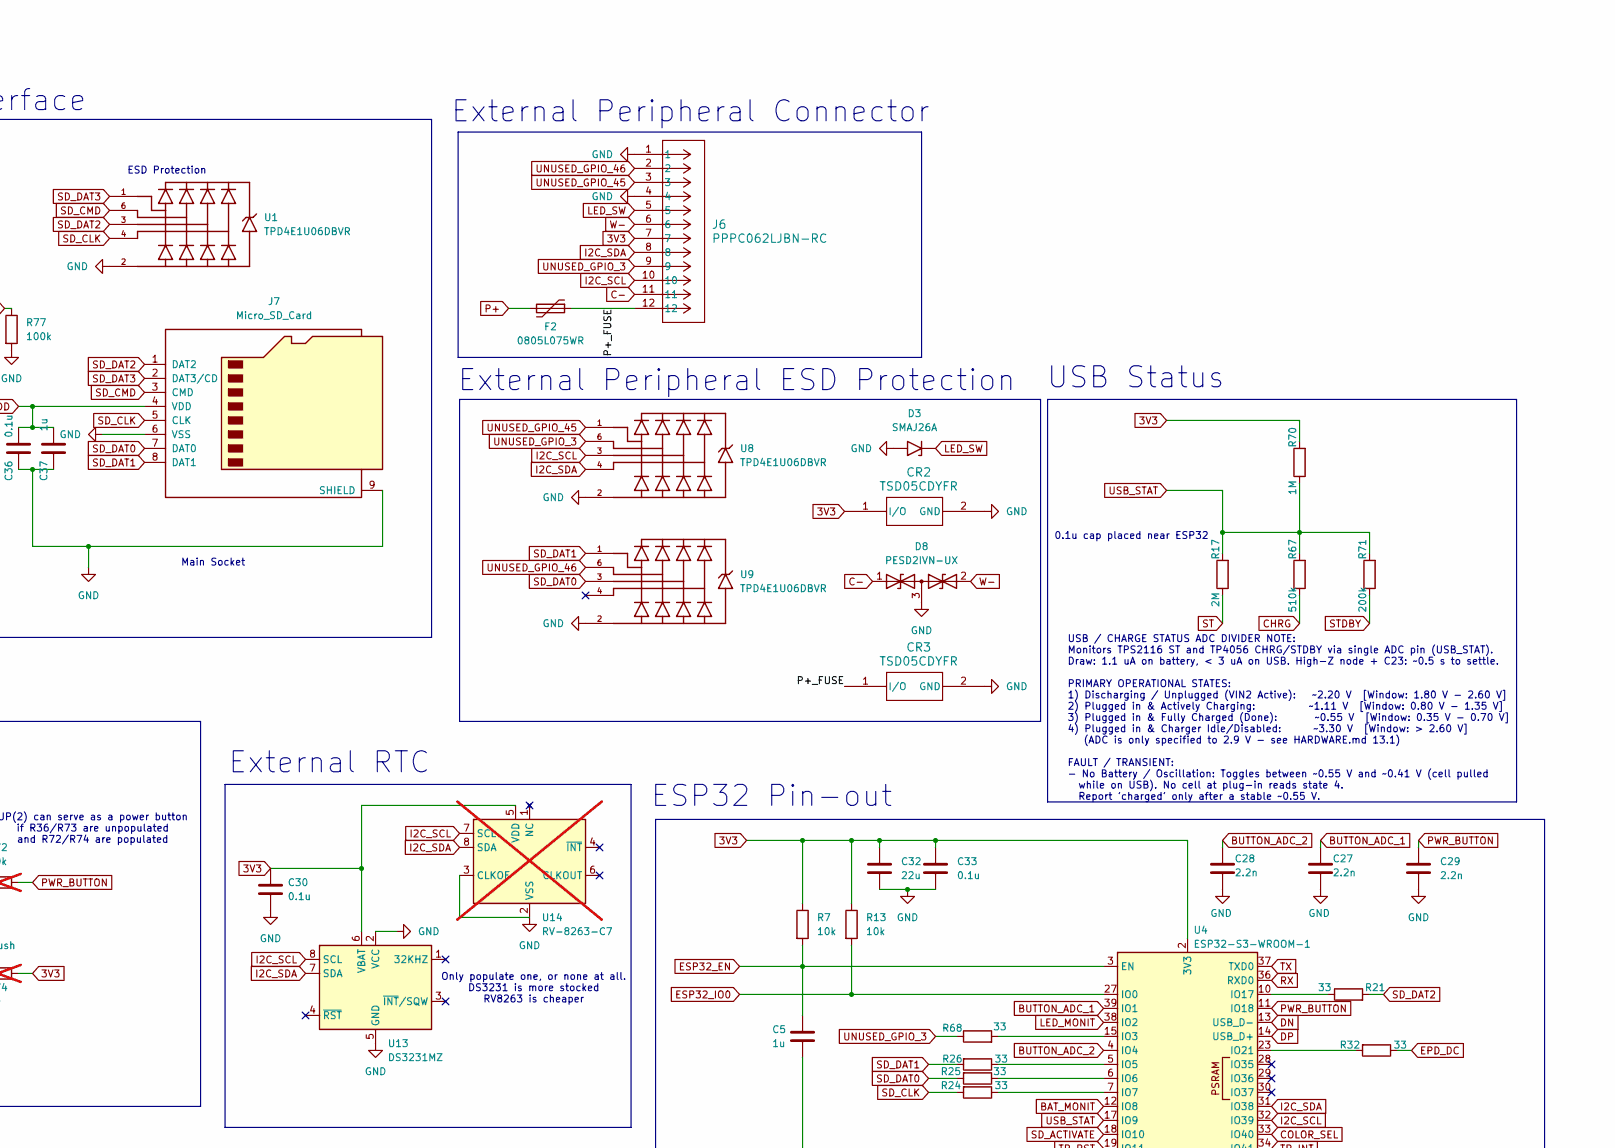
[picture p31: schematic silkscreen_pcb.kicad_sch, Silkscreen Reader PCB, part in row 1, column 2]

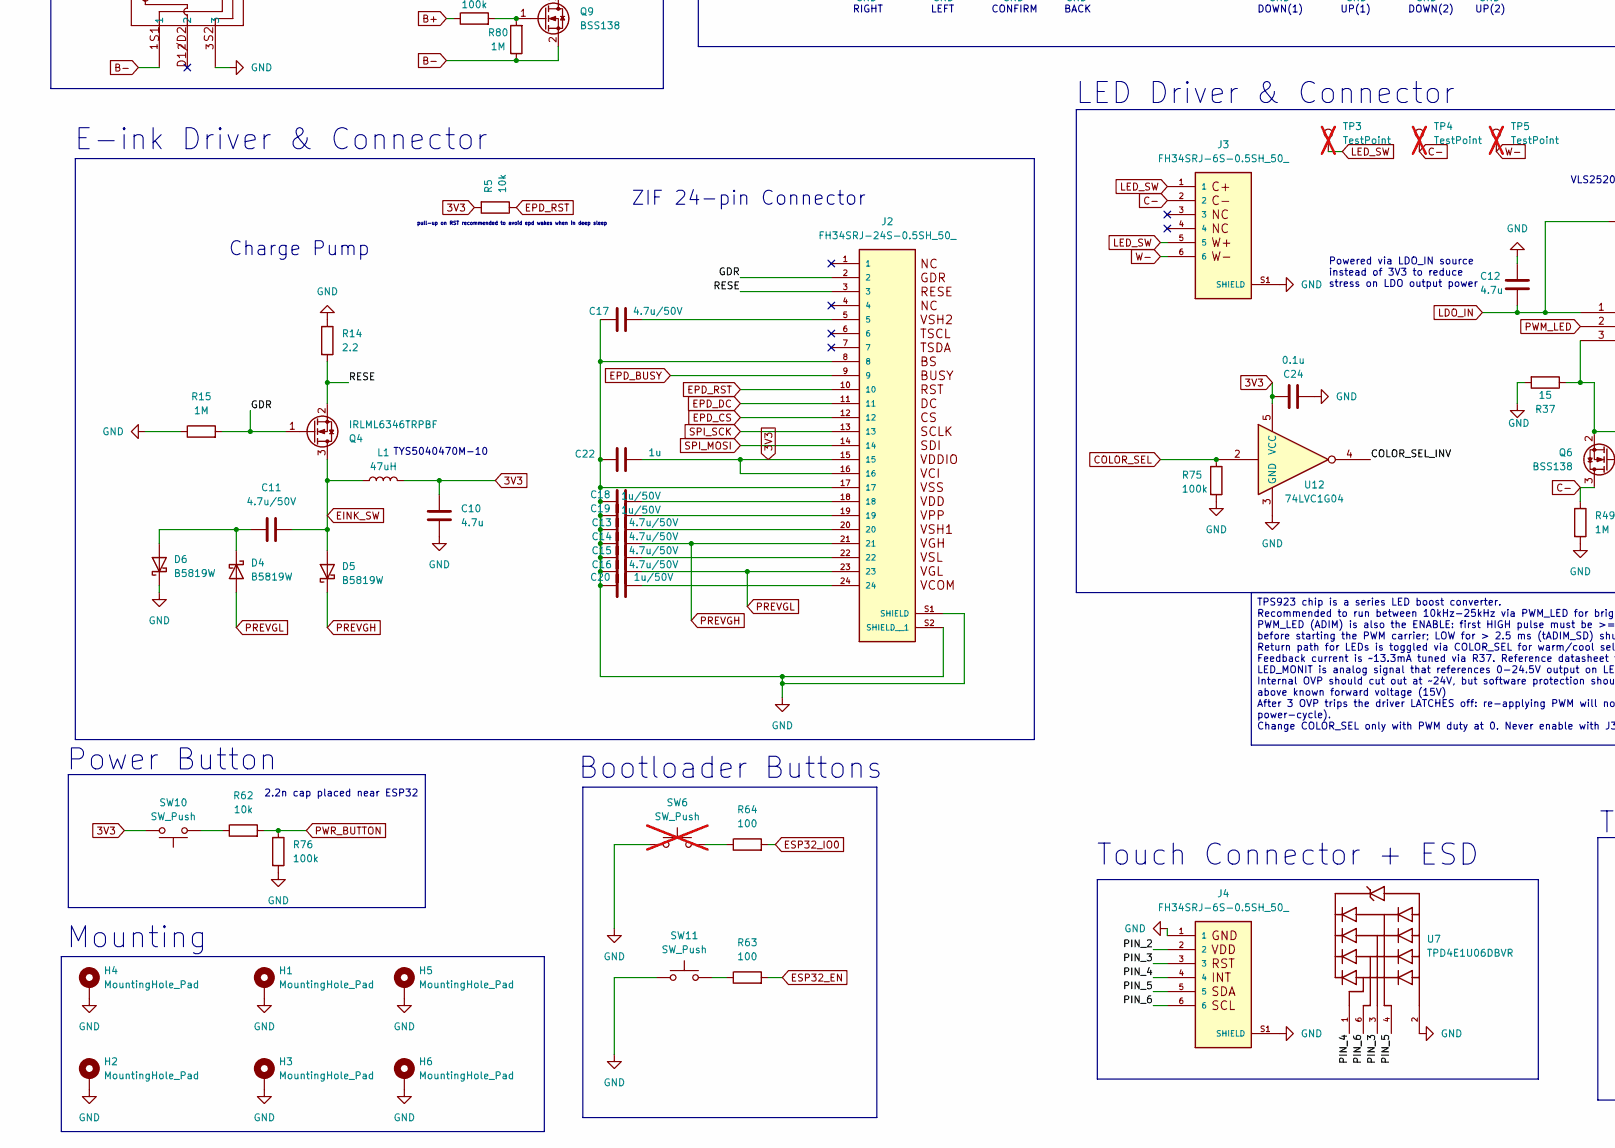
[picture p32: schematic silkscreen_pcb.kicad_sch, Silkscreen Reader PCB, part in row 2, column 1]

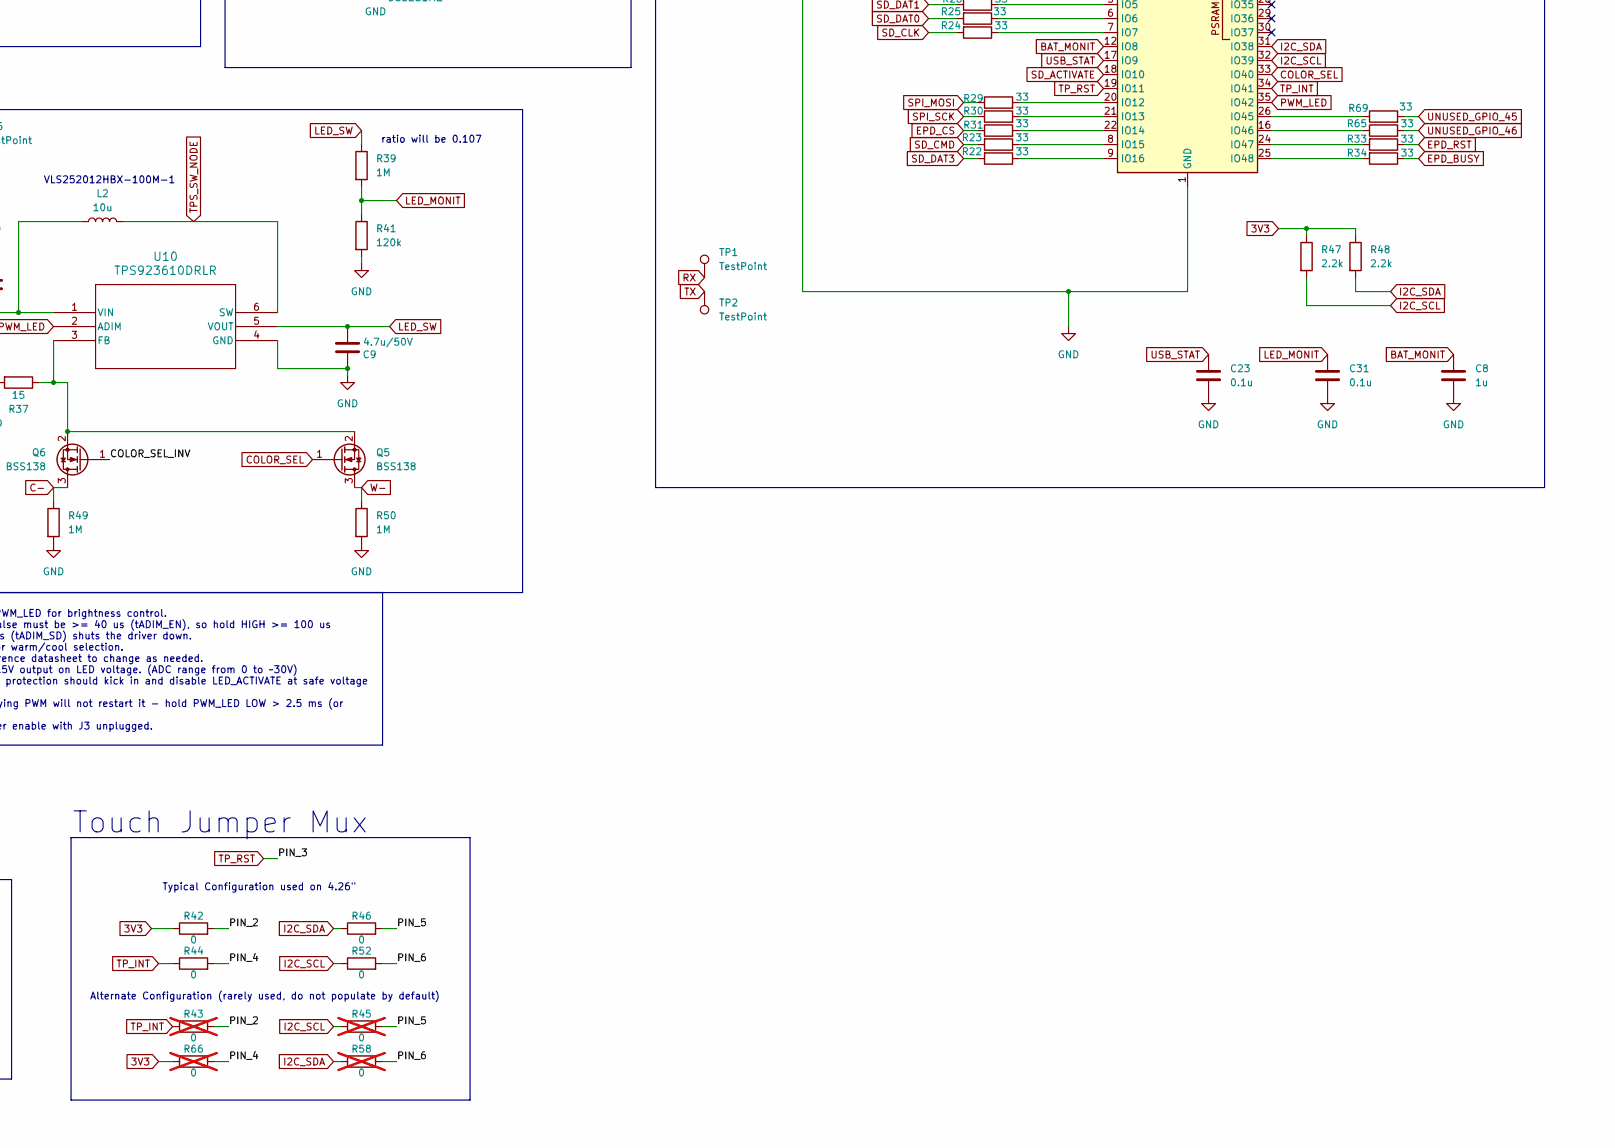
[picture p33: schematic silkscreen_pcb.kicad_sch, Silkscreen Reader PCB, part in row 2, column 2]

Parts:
C1: 1n; C_0603_1608Metric_Pad1.08x0.95mm_HandSolder; MPN CL10B102KB8NNNC; LCSC C1588
C2: 10u/25V; C_0603_1608Metric_Pad1.08x0.95mm_HandSolder; MPN CL10A106MA8NRNC; LCSC C96446
C3: 10u; C_0603_1608Metric_Pad1.08x0.95mm_HandSolder; MPN CL10A106KP8NNNC; LCSC C19702
C4, C6, C32: 22u; C_0805_2012Metric_Pad1.18x1.45mm_HandSolder; MPN GRM21BR61E226ME44L; LCSC C45783
C5, C8, C21, C22, C25, C26, C37: 1u; C_0603_1608Metric_Pad1.08x0.95mm_HandSolder; MPN CL10A105KB8NNNC; LCSC C15849
C7, C23, C24, C30, C31, C33, C36: 0.1u; C_0603_1608Metric_Pad1.08x0.95mm_HandSolder; MPN CC0603KRX7R9BB104; LCSC C14663
C9, C11, C13, C14, C15, C16, C17: 4.7u/50V; C_0805_2012Metric_Pad1.18x1.45mm_HandSolder; MPN CL21A475KBQNNNE; LCSC C513770
C10, C12: 4.7u; C_0603_1608Metric_Pad1.08x0.95mm_HandSolder; MPN CL10A475KO8NNNC; LCSC C19666
C18, C19, C20: 1u/50V; C_0805_2012Metric_Pad1.18x1.45mm_HandSolder; MPN CL21B105KBFNNNE; LCSC C28323
C27, C28, C29, C34: 2.2n; C_0603_1608Metric_Pad1.08x0.95mm_HandSolder; MPN CL10B222KB8NNNC; LCSC C1604
CR1: SMF6.5CA; D_SMF; MPN SMF6.5CA; LCSC C19077501
CR2, CR3: TSD05CDYFR; D_SOD-323_HandSoldering; MPN TSD05CDYFR; LCSC C5299440
D2: LED; LED_1206_3216Metric_Pad1.42x1.75mm_HandSolder; MPN LTST-C150KRKT; LCSC C28310439
D3: SMAJ26A; D_SMA; MPN SMAJ26A; LCSC C19077543
D4, D5, D6: B5819W; D_SOD-123; MPN 1N5819HW-7-F; LCSC C8598
D8: PESD2IVN-UX; SOT-323_SC-70_Handsoldering; MPN PESD2IVN-UX; LCSC C42370512
F1: 0805L100WR; Fuse_0805_2012Metric_Pad1.15x1.40mm_HandSolder; MPN 0805L100WR; LCSC C269106
F2: 0805L075WR; Fuse_0805_2012Metric_Pad1.15x1.40mm_HandSolder; MPN 0805L075WR; LCSC C151146
H1, H2, H3, H4, H5, H6: MountingHole_Pad; MountingHole_2.2mm_M2_DIN965_Pad_TopBottom
J1: USB_C_Receptacle; USB_C_Receptacle_GCT_USB4085; MPN USB4085-GF-A; LCSC C7095263
J2: FH34SRJ-24S-0.5SH_50_; HRS_FH34SRJ-24S-0.5SH_50_; MPN FH34SRJ-24S-0.5SH(50); LCSC C324726
J3, J4: FH34SRJ-6S-0.5SH_50_; HRS_FH34SRJ-6S-0.5SH_50_; MPN FH34SRJ-6S-0.5SH(50); DigiKey_Part_Number H125773CT-ND
J5: Conn_01x02; JST_PH_S2B-PH-K_1x02_P2.00mm_Horizontal; MPN S2B-PH-K-S(LF)(SN); LCSC C48579993
J6: PPPC062LJBN-RC; CONN_PPPC062LJBN-RC_SUL; MPN PPPC062LJBN-RC; LCSC C5333437
J7: Micro_SD_Card; microSD_PushPush_TFPUSH-MEM2075; MPN MEM2075-00-140-01-A; LCSC C393941
L1: 47uH; L_APV_ANR5040; MPN TYS5040470M-10; LCSC C206267
L2: 10u; L_1008_2520Metric_Pad1.43x2.20mm_HandSolder; MPN VLS252012HBX-100M-1; LCSC C88532
Q1: FS8205A; SOT-23-6_Handsoldering; MPN FS8205A; LCSC C2830320
Q2, Q3, Q7, Q8: AO3401A; SOT-23_Handsoldering; MPN AO3401A; LCSC C15127
Q4: IRLML6346TRPBF; SOT-23; MPN IRLML6346TRPBF; LCSC C67276
Q5, Q6, Q9: BSS138; SOT-23; MPN BSS138LT1G; LCSC C7420339
R1, R10, R12, R15, R39, R49, R50, R70, R80, R81, R82: 1M; R_0603_1608Metric_Pad0.98x0.95mm_HandSolder; MPN RC0603FR-071ML; LCSC C22935
R2, R3: 5.1k; R_0603_1608Metric_Pad0.98x0.95mm_HandSolder; MPN RC0603FR-075K1L; LCSC C23186
R4, R5, R7, R8, R9, R13, R28, R53, R54, R55, R56, R62: 10k; R_0603_1608Metric_Pad0.98x0.95mm_HandSolder; MPN RC0603FR-0710KL; LCSC C25804
R6: 4.7k; R_0603_1608Metric_Pad0.98x0.95mm_HandSolder; MPN RC0603FR-074K7L; LCSC C23162
R11: 12k; R_0603_1608Metric_Pad0.98x0.95mm_HandSolder; MPN RC0603FR-0712KL; LCSC C22790
R14: 2.2; R_0603_1608Metric_Pad0.98x0.95mm_HandSolder; MPN RC0603FR-072R2L; LCSC C22939
R16, R78: 1k; R_0603_1608Metric_Pad0.98x0.95mm_HandSolder; MPN RC0603FR-071KL; LCSC C21190
R17: 2M; R_0603_1608Metric_Pad0.98x0.95mm_HandSolder; MPN RC0603FR-072ML; LCSC C22976
R18: 5.6k; R_0603_1608Metric_Pad0.98x0.95mm_HandSolder; MPN RC0603FR-075K6L; LCSC C23189
R19: 20k; R_0603_1608Metric_Pad0.98x0.95mm_HandSolder; MPN RC0603FR-0720KL; LCSC C4184
R20: 56k; R_0603_1608Metric_Pad0.98x0.95mm_HandSolder; MPN RC0603FR-0756KL; LCSC C23206
R21, R22, R23, R24, R25, R26, R29, R30, R31, R32, R33, R34, R65, R68, R69: 33; R_0603_1608Metric_Pad0.98x0.95mm_HandSolder; MPN RC0603FR-0733RL; LCSC C23140
R27: 0; R_0805_2012Metric_Pad1.20x1.40mm_HandSolder; MPN RC0805JR-070RL; LCSC C17477
R35: 33k; R_0603_1608Metric_Pad0.98x0.95mm_HandSolder; MPN RC0603FR-0733KL; LCSC C4216
R36: 68k; R_0603_1608Metric_Pad0.98x0.95mm_HandSolder; MPN RC0603FR-0768KL; LCSC C23231
R37: 15; R_0603_1608Metric_Pad0.98x0.95mm_HandSolder; MPN RC0603FR-0715RL; LCSC C22810
R38: 300k; R_0603_1608Metric_Pad0.98x0.95mm_HandSolder; MPN RC0603FR-07300KL; LCSC C23024
R40, R51, R75, R76, R77, R79: 100k; R_0603_1608Metric_Pad0.98x0.95mm_HandSolder; MPN RC0603FR-07100KL; LCSC C25803
R41: 120k; R_0603_1608Metric_Pad0.98x0.95mm_HandSolder; MPN RC0603FR-07120KL; LCSC C25808
R42, R44, R46, R52, R73: 0; R_0603_1608Metric_Pad0.98x0.95mm_HandSolder; MPN RC0603JR-070RL; LCSC C21189
R43, R45, R58, R66, R74: 0; R_0603_1608Metric_Pad0.98x0.95mm_HandSolder; MPN RC0603JR-070RL; LCSC C21189; not fitted
R47, R48: 2.2k; R_0603_1608Metric_Pad0.98x0.95mm_HandSolder; MPN RC0603FR-072K2L; LCSC C4190
R57: 10M; R_0603_1608Metric_Pad0.98x0.95mm_HandSolder; MPN RC0603FR-0710ML; LCSC C7250
R59: 2k; R_0603_1608Metric_Pad0.98x0.95mm_HandSolder; MPN RC0603FR-072KL; LCSC C22975
R60, R61, R63, R64, R83: 100; R_0603_1608Metric_Pad0.98x0.95mm_HandSolder; MPN RC0603FR-07100RL; LCSC C22775
R67: 510k; R_0603_1608Metric_Pad0.98x0.95mm_HandSolder; MPN RC0603FR-07510KL; LCSC C23192
R71: 200k; R_0603_1608Metric_Pad0.98x0.95mm_HandSolder; MPN RC0603FR-07200KL; LCSC C25811
R72: 10k; R_0603_1608Metric_Pad0.98x0.95mm_HandSolder; MPN RC0603FR-0710KL; LCSC C25804; not fitted
R84: 1; R_0603_1608Metric_Pad0.98x0.95mm_HandSolder; MPN RC0603FR-071RL; LCSC C22936
SW1, SW2, SW3, SW4, SW5, SW7, SW8, SW9, SW10, SW11: SW_Push; MJTP1117; MPN MJTP1117; LCSC C557598
SW6: SW_Push; SW_PUSH_1P1T_6x3.5mm_H4.3_APEM_MJTP1243; MPN MJTP1243; not fitted
TP1, TP2: TestPoint; TestPoint_Pad_1.0x1.0mm
TP3, TP4, TP5: TestPoint; PinHeader_1x01_P2.54mm_Vertical; not fitted
U1, U6, U7, U8, U9: TPD4E1U06DBVR; SOT-23-6_Handsoldering; PARTREV D; DigiKey_Part_Number 296-35965-1-ND
U2: TPS2116DRL; SOT-583-8; MPN TPS2116DRLR; LCSC C3235557
U3: TLV75533PDBV; SOT-23-5_HandSoldering; MPN TLV75533PDBVR; LCSC C404027
U4: ESP32-S3-WROOM-1; MPN ESP32-S3-WROOM-1-N16R8; LCSC C2913202
U5: DW01A; SOT-23-6_Handsoldering; MPN DW01A; LCSC C351410
U10: TPS923610DRLR; U_DRL0006A_6L_TEX-M; MPN TPS923610DRLR; LCSC C52919131
U11: TP4056-42-ESOP8; SOIC-8-1EP_3.9x4.9mm_P1.27mm_EP2.41x3.3mm_ThermalVias; MPN TP4056-42-ESOP8; LCSC C16581
U12: 74LVC1G04; SOT-23-5_HandSoldering; MPN 74LVC1G04GV,125; LCSC C53185133
U13: DS3231MZ; SOIC-8_3.9x4.9mm_P1.27mm; MPN DS3231MZ+TRL; LCSC C107410
U14: RV-8263-C7; MicroCrystal_C7_SON-8_1.5x3.2mm_P0.9mm; MPN RV-8263-C7-32.768KHZ-20PPM-TA-QA; LCSC C5137460; not fitted

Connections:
3V3: C6.1, C10.2, C21.1, C22.2, C24.1, C30.1, C32.1, C33.1, CR2.1 (I/O), J2.15, J2.16, J6.7, L1.2, Q2.2 (S), Q7.2 (S), R4.2, R5.2, R7.1, R13.1, R28.2, R40.2, R42.1, R47.1, R48.1, R66.1, R70.2, R74.1, R81.2, SW10.2, U3.5 (OUT), U4.2 (3V3), U12.5 (VCC), U13.6 (VBAT), U14.5 (VDD)
/COLOR_SEL_INV: Q6.1 (G), U12.4
/DET_NODE: Q2.1 (G), Q9.3 (D), R81.1
/GDR: J2.2, Q4.1 (G), R15.2
/P+_FUSE: CR3.1 (I/O), F2.1, J6.12
/PIN_2: J4.2, R42.2, R43.2
/PIN_4: J4.4, R44.2, R66.2, U7.1
/PIN_5: J4.5, R45.2, R46.2, U7.4
/PIN_6: J4.6, R52.2, R58.2, U7.6
/PR1: R38.2, R51.1, U2.4 (PR1)
/RESE: J2.3, Q4.2 (S), R14.2
B+: J5.2, Q3.2 (S), R57.2, R79.1
B-: C7.2, C34.2, J5.1, Q1.1, Q9.2 (S), R56.2, R80.1, U5.6 (GND)
BAT_MONIT: C8.1, R10.1, R12.2, U4.12 (IO8)
BUTTON_ADC_1: C27.2, R4.1, R18.2, R19.2, R20.2, R60.2, U4.39 (IO1)
BUTTON_ADC_2: C28.2, R11.2, R28.1, R35.2, R36.2, R61.2, U4.4 (IO4)
C-: D8.1 (A1), J3.2, J6.11, Q6.3 (D), R49.1, TP4.1
CC1: J1.A5 (CC1), R3.1, U6.4
CC2: J1.B5 (CC2), R2.1, U6.3
CE: Q2.3 (D), R82.2, U11.8 (CE)
CHRG: R67.1, U11.7 (~CHRG)
COLOR_SEL: Q5.1 (G), R75.1, U4.33 (IO40), U12.2
DN: J1.A7 (D-), J1.B7 (D-), U4.13 (USB_D-), U6.1
DP: J1.A6 (D+), J1.B6 (D+), U4.14 (USB_D+), U6.6
EINK_SW: C11.2, D5.2 (A), L1.1, Q4.3 (D)
EPD_BUSY: J2.9, R34.1
EPD_CS: J2.12, R31.1
EPD_DC: J2.11, R32.1
EPD_RST: J2.10, R5.1, R33.1
ESP32_EN: C5.1, R7.2, R63.2, U4.3 (EN)
ESP32_IO0: R13.2, R64.2, U4.27 (IO0)
GND: C1.1, C3.2, C4.2, C5.2, C6.2, C8.2, C9.1, C10.1, C12.1, C13.1, C14.1, C15.1, C16.1, C17.1, C18.1, C19.1, C20.1, C21.2, C22.1, C23.2, C24.2, C25.1, C26.2, C27.1, C28.1, C29.2, C30.2, C31.2, C32.2, C33.2, C36.1, C37.1, CR1.2 (GND), CR2.2 (GND), CR3.2 (GND), D3.2 (A2), D6.1 (K), D8.3 (common), H1.1, H2.1, H3.1, H4.1, H5.1, H6.1, J1.A1 (GND), J1.A12 (GND), J1.B1 (GND), J1.B12 (GND), J2.8, J2.17, J2.S1 (SHIELD), J2.S2 (SHIELD__1), J3.S1 (SHIELD), J3.S2 (SHIELD), J4.1, J4.S1 (SHIELD), J4.S2 (SHIELD), J6.1, J6.4, J7.6 (VSS), J7.9 (SHIELD), Q1.3, Q8.1 (G), R1.1, R2.2, R3.2, R6.2, R10.2, R14.1, R15.1, R16.1, R37.2, R41.2, R49.2, R50.2, R51.2, R59.2, R73.1, R75.2, R76.2, R77.2, R82.1, R84.2, SW1.1, SW2.1, SW3.1, SW4.1, SW5.1, SW6.1, SW8.1, SW9.1, SW11.1, U1.2, U2.1 (GND), U3.2 (GND), U4.1 (GND), U4.40 (GND), U4.41 (GND), U6.2, U7.2, U8.2, U9.2, U10.4 (GND), U11.1 (TEMP), U11.3 (GND), U11.9 (EPAD), U12.3 (GND), U13.2 (VCC), U13.5 (GND), U14.2 (VSS), U14.3 (CLKOE)
I2C_SCL: J6.10, R45.1, R47.2, R52.1, U4.32 (IO39), U8.3, U13.8 (SCL), U14.7 (SCL)
I2C_SDA: J6.8, R46.1, R48.2, R58.1, U4.31 (IO38), U8.4, U13.7 (SDA), U14.8 (SDA)
LDO_IN: C4.1, C12.2, L2.1, U2.2 (VOUT), U2.7 (VOUT), U3.1 (IN), U3.3 (EN), U10.1 (VIN)
LED_MONIT: C31.1, R39.2, R41.1, U4.38 (IO2)
LED_SW: C9.2, D3.1 (A1), J3.1, J3.5, J6.5, R39.1, TP3.1, U10.5 (VOUT)
unnamed: C2.2, R84.1
unnamed: C13.2, J2.20
unnamed: C15.2, J2.22
unnamed: C17.2, J2.5
unnamed: C18.2, J2.18
unnamed: C19.2, J2.19
unnamed: C20.2, J2.24
unnamed: D2.1 (K), R59.1
unnamed: C11.1, D4.1 (K), D6.2 (A)
unnamed: C1.2, J1.S1 (SHIELD), R1.2
unnamed: Q3.3 (D), R27.2
unnamed: Q3.1 (G), R56.1, R57.1
unnamed: Q5.2 (S), Q6.2 (S), R37.1, U10.3 (FB)
unnamed: Q7.1 (G), R40.1, R78.2
unnamed: Q8.3 (D), R27.1
unnamed: Q9.1 (G), R79.2, R80.2
unnamed: R11.1, SW4.2
unnamed: R18.1, SW3.2
unnamed: R19.1, SW8.2
unnamed: R20.1, SW9.2
unnamed: R35.1, SW5.2
unnamed: R36.1, R72.2, SW7.2
unnamed: R60.1, SW2.2
unnamed: R61.1, SW1.2
unnamed: R62.1, SW10.1
unnamed: R63.1, SW11.2
unnamed: R64.1, SW6.2
unnamed: R73.2, R74.2, SW7.1
unnamed: R68.2, U4.15 (IO3)
unnamed: R26.1, U4.5 (IO5)
unnamed: R25.1, U4.6 (IO6)
unnamed: R24.1, U4.7 (IO7)
unnamed: R29.2, U4.20 (IO12)
unnamed: R30.2, U4.21 (IO13)
unnamed: R31.2, U4.22 (IO14)
unnamed: R23.1, U4.8 (IO15)
unnamed: R22.1, U4.9 (IO16)
unnamed: R21.1, U4.10 (IO17)
unnamed: R32.2, U4.23 (IO21)
unnamed: R69.1, U4.26 (IO45)
unnamed: R65.1, U4.16 (IO46)
unnamed: R33.2, U4.24 (IO47)
unnamed: R34.2, U4.25 (IO48)
unnamed: C34.1, R16.2, U5.2 (CS)
unnamed: Q1.4, U5.3 (OC)
unnamed: Q1.6, U5.1 (OD)
unnamed: C7.1, R83.1, U5.5 (VCC)
unnamed: R6.1, U11.2 (PROG)
P+: C3.1, C26.1, F2.2, Q8.2 (S), R12.1, R83.2, U2.6 (VIN2), U11.5 (BAT)
PREVGH: C14.2, D5.1 (K), J2.21
PREVGL: C16.2, D4.2 (A), J2.23
PWM_LED: U4.35 (IO42), U10.2 (ADIM)
PWR_BUTTON: C29.1, R62.2, R72.1, R76.1, U4.11 (IO18)
RX: TP1.1, U4.36 (RXD0)
SD_ACTIVATE: R78.1, U4.18 (IO10)
SD_CLK: J7.5 (CLK), R24.2, U1.4
SD_CMD: J7.3 (CMD), R23.2, R55.1, U1.6
SD_DAT0: J7.7 (DAT0), R8.1, R25.2, U9.3
SD_DAT1: J7.8 (DAT1), R9.1, R26.2, U9.1
SD_DAT2: J7.1 (DAT2), R21.2, R53.1, U1.3
SD_DAT3: J7.2 (DAT3/CD), R22.2, R54.1, U1.1
SD_VDD: C36.2, C37.2, J7.4 (VDD), Q7.3 (D), R8.2, R9.2, R53.2, R54.2, R55.2, R77.1
SPI_MOSI: J2.14, R29.1
SPI_SCK: J2.13, R30.1
ST: R17.1, U2.8 (ST)
STDBY: R71.1, U11.6 (~STDBY)
TPS_SW_NODE: L2.2, U10.6 (SW)
TP_INT: R43.1, R44.1, U4.34 (IO41)
TP_RST: J4.3, U4.19 (IO11), U7.3
TX: TP2.1, U4.37 (TXD0)
UNUSED_GPIO_3: J6.9, R68.1, U8.6
UNUSED_GPIO_45: J6.3, R69.2, U8.1
UNUSED_GPIO_46: J6.2, R65.2, U9.6
USB_STAT: C23.1, R17.2, R67.2, R70.1, R71.2, U4.17 (IO9)
USB_VBUS: C2.1, C25.2, D2.2 (A), F1.2, R38.1, U2.3 (VIN1), U2.5 (MODE), U11.4 (V_{CC})
VBUS_PRE_FUSE: CR1.1 (I/O), F1.1, J1.A4 (VBUS), J1.A9 (VBUS), J1.B4 (VBUS), J1.B9 (VBUS)
W-: D8.2 (A2), J3.6, J6.6, Q5.3 (D), R50.1, TP5.1

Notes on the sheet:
Overcharge/Discharge Protection
ratio will be 0.5
USB / CHARGE STATUS ADC DIVIDER NOTE: Monitors TPS2116 ST and TP4056 CHRG/STDBY via single ADC pin (USB_STAT). Draw: 1.1 uA on battery, < 3 uA on USB. High-Z node + C23: ~0.5 s to settle. PRIMARY OPERATIONAL STATES: 1) Discharging / Unplugged (VIN2 Active): ~2.20 V [Window: 1.80 V - 2.60 V] 2) Plug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
SDMMC Interface
LED lit when USB is plugged in 1.5mA at 2.0Vf (5 − 2.0)/0.0015 ≈ 2 kΩ
Battery<->USB Power Path Switch
RIGHT LEFT CONFIRM BACK
3.7V LiPo Battery Connector
Charge Pump
LED Driver & Connector
External RTC
0.1u cap placed near ESP32
Touch Connector + ESD
Touch Jumper Mux
Interface Buttons
ratio will be 0.107
3.3V min -> 1.65V
- +
VLS252012HBX-100M-1
2.2n cap placed near ESP32
pull-up on RST recommended to avoid epd wakes when in deep sleep
HIGH-Z = USB LOW = BATTERY
POWER GATE: SD_ACTIVATE gates VDD to the SD card SD_ACTIVATE HIGH (default) = OFF SD_ACTIVATE LOW = ON All data signals pulled up to SD_VDD All data signals should be asserted low before shutting down
External Peripheral Connector
External Peripheral ESD Protection
E-ink Driver & Connector
ESD Protection
Battery Charger
Typical Configuration used on 4.26"
ESP32 Pin-out
1u cap placed at ESP32
Reverse polarity protection
4.2V max -> 2.1V
ZIF 24-pin Connector
Local Pull-ups
DOWN(1) UP(1) DOWN(2) UP(2)
LDO 3.3V
USB Status
Power Button
High resistor values -> low idle current

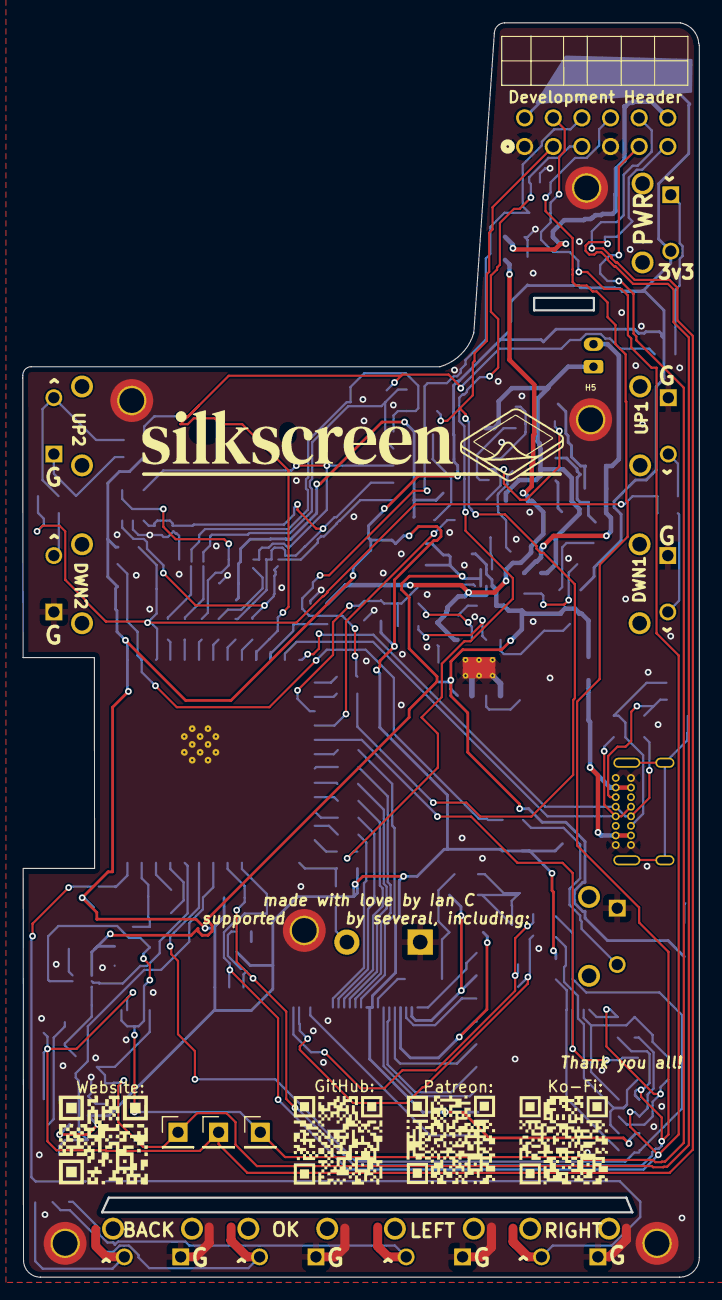
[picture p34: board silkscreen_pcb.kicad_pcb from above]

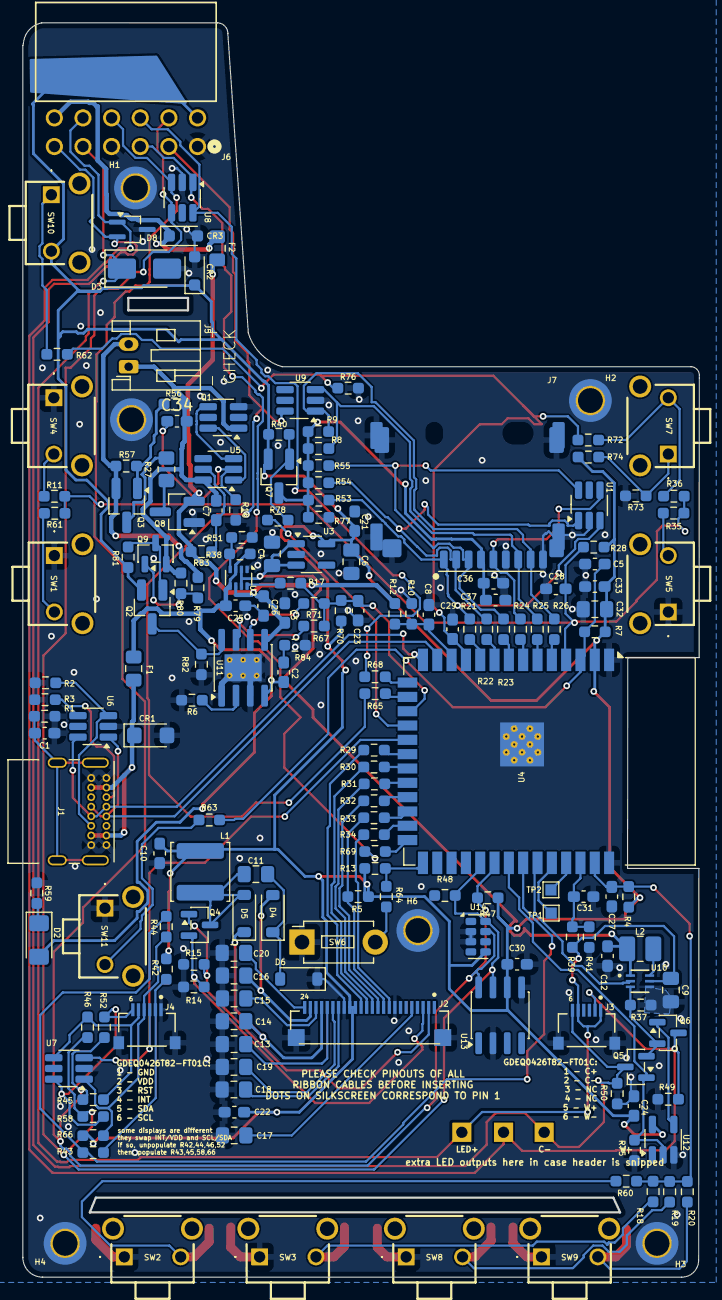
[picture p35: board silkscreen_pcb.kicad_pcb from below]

Board: 2 copper layers, 60.0 x 111.3 mm, 185 parts (181 on the bottom side), 114 nets.

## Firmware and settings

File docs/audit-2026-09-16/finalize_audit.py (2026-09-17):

"""Check source preservation and audit consistency; no design writes."""
import pathlib,hashlib,json,csv,datetime,io,re
import openpyxl
out=pathlib.Path(__file__).parent;root=out.parents[1]
initial=json.loads((out/'source-manifest.json').read_text());result=[]
for item in initial:
 path=root/item['path']
 if not path.exists() and path.name.startswith('_autosave-'):
  result.append({'path':item['path'],'initial_sha256':item['sha256'],'final_sha256':None,'unchanged':None,'status':'absent_ephemeral_autosave'})
  continue
 current=hashlib.sha256(path.read_bytes()).hexdigest()
 result.append({'path':item['path'],'initial_sha256':item['sha256'],'final_sha256':current,'unchanged':current==item['sha256'],'status':'present'})
(out/'source-preservation.json').write_text(json.dumps({'checked_local':datetime.datetime.now().astimezone().isoformat(),'files':result},indent=2),encoding='utf-8')
assert all(r['unchanged'] or r['status']=='absent_ephemeral_autosave' for r in result),'Source changed: report must be reassessed'
components=list(csv.DictReader((out/'component-review.csv').open(encoding='utf-8-sig')))
assert len(components)==173 and len({r['Ref'] for r in components})==173
bom=json.loads((out/'bom-verification.json').read_text())
assert not bom['passive_value_errors'] and not bom['unexplained_exclusions']
gerbers=json.loads((out/'gerber-geometry-comparison.json').read_text())
assert len(gerbers)==13
assert all(r.get('geometry_equal',r.get('exact_except_timestamp',False)) for r in gerbers)
assert not json.loads((out/'production-verification.json').read_text())['cpl_differences']
orderfile=root/'production/bom_JLC_upload-JLCPCB Assembly Order.xls'
current_order=[list(r) for r in openpyxl.load_workbook(io.BytesIO(orderfile.read_bytes()),data_only=True).active.values]
assert current_order==json.loads((out/'order-bom.json').read_text()),'Saved order has changed since extraction'
print('PASS:',sum(r['unchanged'] is True for r in result),'original hashed inputs unchanged;',sum(r['status']=='absent_ephemeral_autosave' for r in result),'ephemeral autosave absent; all 173 refs covered; 157 CPL entries match; 13 fabrication files match geometrically or except timestamps.')
coverage=list(csv.DictReader((out/'block-coverage.csv').open(encoding='utf-8-sig')))
assert len(coverage)==173 and len({r['Ref'] for r in coverage})==173
assert len({r['Block'] for r in coverage})==18
review=root/'DESIGN_REVIEW.md'
assert not (out/'REPORT.md').exists() and not (out/'Q4_AND_FRONTLIGHT_FOLLOWUP.md').exists()
checked_links=0
for doc in [review,root/'README.md',root/'docs/HARDWARE.md',root/'fabrication/README.md']:
 for link in re.findall(r'!?\[[^\]]*\]\(([^\s)]+)\)',doc.read_text(encoding='utf-8')):
  if '://' in link or link.startswith('#'):continue
  target=(doc.parent/link.split('#')[0]).resolve()
  assert target.exists(),f'{doc}: missing {link}'
  checked_links+=1
print('PASS: 18 nonoverlapping blocks; one canonical review;',checked_links,'local documentation links resolve.')
print('Report words:',len(review.read_text(encoding='utf-8').split()))

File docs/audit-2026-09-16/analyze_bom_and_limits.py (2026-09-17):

"""Cross-reference every ordered component with the freshly exported netlist."""
import pathlib,json,xml.etree.ElementTree as E,csv,re,collections,itertools,math
out=pathlib.Path(__file__).parent;root=out.parents[1]
components={c.attrib['ref']:c for c in E.parse(out/'netlist.xml').findall('./components/comp')}
board=json.loads((out/'board.json').read_text());footprints={f['ref']:f for f in board['footprints']}
upload=list(csv.DictReader((root/'production/bom_JLC_upload.csv').open(encoding='utf-8-sig')))
saved={ref:r for r in upload for ref in r['Designator'].split(',')}
rows=json.loads((out/'order-bom.json').read_text())[5:]
ordered={ref:r for r in rows if r[0] for ref in r[0].split(',')}
findings={
 'Q4':'HOLD on existing BSS138. Preferred replacement: genuine Infineon IRLML6346TRPBF C67276, SOT-23 G1/S2/D3; 80mohm max at 2.5V and 2.9nC typical gate charge. Split from Q5/Q6; verify panel-driven VGS/VDS/current waveforms. See root DESIGN_REVIEW.md section 7.',
 'Q5':'Reasonable for 15mA color selection; do not apply Q4 boost-switch judgement to this low-current role.',
 'Q6':'Reasonable for 15mA color selection. Inversion does not guarantee transient exclusivity; measure branch current during color changes. ADIM PWM low phases do not guarantee zero current.',
 'D2':'HOLD if unchanged: saved order is reverse mount. User requested C28310439; factory approval/current BOM not available locally.',
 'L2':'Order is C88528 HBX-4R7M-1; upload is C413592 HBU-4R7M. Both 4.7uH, but release record must specify the actual part.',
 'R37':'Existing 13.3 ohm 1%: 14.52..15.65mA at full scale. Recommend common 15 ohm 1% 0603 (C22810): 13.33mA nominal, 13.87mA upper from VFB/R tolerances; not yet substituted. 15 ohm 5% also stays below 15mA before drift/transients.',
 'R14':'3 ohm / 0.1W sense resistor; verify pulse/RMS heating. Full-rated continuous RMS is 183mA; not peak-current limit.',
 'CR1':'SD05C rated 5.0V stand-off on USB VBUS; use 5.5V-rated alternative or confirm leakage over allowed source maximum.',
 'CR2':'5V TVS on 3.3V rail: no normal-DC stress; surge clamp is not a precision 3.3V overvoltage limit.',
 'CR3':'5V TVS on <=4.2V battery rail: no normal-DC stress; surge clamp not a battery overcharge controller.',
 'U3':'500mA SOT-23-5 LDO; require load/thermal measurement at 5V USB with WiFi+SD+display.',
 'U2':'TPS2116: VIN1=MODE=USB_VBUS, VIN2=P+, PR1=300k/100k divider; 4V nominal threshold, 3.625..4.385V including reference/resistor tolerance. Measure hot-plug and source transitions.',
 'Q7':'PMOS SD gate: source 3V3, drain SD_VDD, external gate pull-up. LOW on; high or high-Z without internal pulls off. Stop bus and avoid signal back-power before switching off.',
 'U5':'USB-present reverse-battery concern: supply can be forced negative through Q8-on/Q3-body-diode path. VCC=P+, GND=B-. No reference series VCC filter; sensing includes PMOS drops. See DESIGN_REVIEW.md section 4.',
 'Q3':'Source=B+, gate referenced to B-. When USB enhances Q8, Q3 body diode can conduct into reversed cell even with Q3 channel off; reverse-insertion safety is not established.',
 'Q8':'Source=P+, gate=GND. Charger can enhance it independently of battery polarity, defeating the assumed reverse blocking with Q3. Redesign/validate or restrict prototype battery handling.',
 'Q1':'TECH PUBLIC 6-pin FS8205A pinout checked against manufacturer drawing; common-drain pins 2/5 internal.',
 'U4':'N16R8 order: leave GPIO35/36/37 unused (source does). Boot strap GPIO3/45/46 exposed on header.',
 'U11':'R6=4.7k: ordered sheet formula gives 234mA; its low-current example table differs. About 0.25A intended; measure actual. TEMP grounded.',
 'U12':'Exact MDD drawing verified: NC1 A2 GND3 Y4 VCC5, compatible at 3.3V. Static complementary logic does not guarantee nonoverlap during Q5/Q6 switching.',
 'U10':'TPS923610 ADIM first high >40us, then recommended 10..200kHz dimming; low >2.5ms shutdown/latch reset. Shutdown retains input/output diode path. Qualify color-change stored-energy pulses; 25V typical OVP.',
 'C22':'1uF connected to 3V3, but 51.84mm from U4 supply pad near panel; not MCU-local or RTC decoupling. RTC bypass is C30.',
 'J1':'GCT THT USB-C; verify connector soldering included in JLC scope. Tight pad gaps are footprint geometry, not unrouted shorts.',
 'J2':'24-pin electrical mapping checked; confirm actual FPC thickness/contact orientation and panel variant.',
 'J3':'User confirms physical FT01C sample matches schematic: C+,C-,NC,NC,W+,W-. Supplier drawing conflicts; no wiring change recommended for this sample. A unit following drawing would reverse-bias selected LED string; boost can reach OVP and damage LEDs. Retain lot/FPC check.',
 'J4':'Default links give GND,3V3,RST,INT,SDA,SCL. Mutually exclusive alternative links must stay DNP.',
 'J5':'CJT 2mm right-angle connector in JST-PH footprint; pin1 B-, pin2 B+. Verify cable polarity and factory THT scope.',
 'J6':'CJT right-angle 2x6 female header; high voltage LED rail and boot straps exposed; do not treat as generic GPIO header.',
 'J7':'TF PUSH: matching data pin order, but peg-hole Y offset 0.22mm at nominal pad alignment. Assembly fit confirmation required.',
 'D3':'Actual unidirectional SMAJ26A, pad1 cathode on LED output. 42.1V surge clamp does not guarantee IC protection.',
 'D8':'Exact TECH PUBLIC 24V bidirectional drawing verified: signal1/2 common3, compatible. Not a precision 3.3V clamp or system ESD certification.',
 'L1':'22uH TDK in Bourns-named footprint; ratings reasonable; panel waveform/reference 47uH differs and needs qualification.',
 'F1':'1A hold at 20C derates to about 0.65A at 60C/0.55A at 70C. Qualify full USB workload/temperature/drop; no USB current negotiation.',
 'R27':'Zero-ohm battery path: check jumper current rating and voltage drop in first-article load test.',
}
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

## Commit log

2026-09-13 microSD: dual-source push-push footprint (TF PUSH / MEM2075) + doc/BOM sync
    - Add project-local microSD_dualsource footprint accepting SHOU HAN TF PUSH
    (LCSC C393941, JLC builds) or GCT MEM2075-00-140-01-A (DigiKey). Built from
    the exact SHOU HAN DXF + GCT .kicad_mod, with FastEDA WRL 3D model. Pinout
    identical to Hirose DM3AT (1-8 signals, 9=shield/GND); replaces the push-pull
    DM3AT on J7. fp-lib-table registers the new library.
    - BOM/docs sync to settled parts: J7 push-push (MEM2075 DigiKey / TF PUSH JLC);
    L2 -> VLS252010HBU-4R7M (C413592); U4 -> N16R8; SW1-11 tactiles note TS365ZJ
    (C557598); CR1-3 note SD05C alt; SW6 -> DNP.
    - DESIGN_REVIEW: add microSD connector-swap note; fi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
    [BOM.csv, bom_jlcpcb.csv, silkscreen_pcb.kicad_pcb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]
2026-09-13 Prototype-run release: button re-center, schematic cleanup, doc refresh, as-ordered BOM
    Board / schematic:
    - Re-center bottom button row (SW2/SW3/SW8/SW9) on the board (was 2.5 mm right
    of center; now 11.5 mm margin each side, 12/13/12 spacing kept).
    - Fix stale AP3031-era net name and the LED_MONIT/ADC annotation.
    Docs:
    - Regenerate full schematic capture (full-capture.png) and per-block images;
    add PCB layout plot (silkscreen_pcb_layout.pdf).
    - Remove superseded assets (board-3d-top.png, 00-full-sheet.png,
    18-color-select.png, silkscreen_pcb.pdf) and repoint all README/HARDWARE/
    DESIGN_REVIEW links to the current plots.
    - Document SW6 (BOOT/IO0) as DNP + USB-Serial-JTAG download p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
    [bom_JLC_upload.csv, silkscreen_pcb.kicad_pcb, silkscreen_pcb.kicad_sch]
2026-09-17 Post-review revision: reverse-battery CE gate, 10 uH L2, layout fixes, optimized BOM
    - Reverse-battery fix ("Fix 4"): TP4056 CE is no longer tied to USB_VBUS. It is
    driven from 3V3 through Q2 (P-FET), enabled by a cell-polarity detector
    referenced to raw B- (Q9 BSS138, R79 100k, R80/R81/R82 1M). A reversed cell
    keeps the charger disabled; idle cost on battery is ~3.4 uA.
    - Q4 (EPD charge-pump switch) -> IRLML6346TRPBF. R37 -> 15 ohm (~13.3 mA LED
    ceiling, under the panel's 15 mA limit).
    - L2 -> 10 uH (TI characterizes the TPS923610 only with 10 uH; modelled ~6-7 mA
    less battery draw at every brightness). Q2/Q3/Q7/Q8 -> AO3401A.
    CR1 (VBUS TVS) value -> SMF6.5CA.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
    [BOM_handbuild_digikey.csv, block-coverage.csv, bom_JLC_upload_v3.csv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]
2026-09-18 Battery-path widening, 0805 jumper, C9/L1/R14 updates, JLC ordering guide
    - B+/B-/P+ traces widened to 0.4 mm; R27 zero-ohm jumper 0603 -> 0805
    (LCSC C17477, prime Yageo RC0805JR-070RL); part_fields and BOMs updated
    - L1 47 uH (Laird TYS5040470M-10 / Sunltech C206267), R14 2.2 ohm,
    C9 4.7 uF, Q1 manufacturer corrected
    - Regenerated JLC production set (gerbers, CPL, BOM) and plots
    - README: step-by-step JLCPCB upload flow and optional/base part groups
    - Second full review (docs/audit-2026-09-18), refreshed images and docs
    - Trimmed sym/fp library tables; pruned stale exports
    [BOM.csv, BOM_handbuild_digikey.csv, bom.csv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]
2026-09-19 Other-fab ordering files, optional front-mounted bottom buttons, W-/C- reroute
    - fabrication/make_fab_files.py and production/other_fabs/: PCBWay and NextPCB
    BOMs (MPN-keyed), raw KiCad bottom-side placement file, NextPCB centroid zip and a
    legible bottom-side assembly drawing; README section "Ordering from PCBWay or
    NextPCB" and JLC step 4/6 corrections
    - Optional front-mounted bottom buttons: open solder-bridge tabs beside the mounting
    holes of SW2/SW3/SW8/SW9 (GND and ladder node), with solder-mask windows on the
    tab tips, so a hand-fitted APEM MJTP1243 can replace the right-angle switch.
    Documented in docs/HARDWARE.md 9.1.1; never bridged with an MJTP1117/TS365ZJ fitted
    - W-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
    [nextpcb_bom.csv, pcbway_bom.csv, placement_bottom_kicad.csv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]
2026-09-19 Other-fab ordering files, optional front-mounted bottom buttons, W-/C- reroute
    BOMs (MPN-keyed), raw KiCad bottom-side placement file, NextPCB centroid CSV (NextPCB sample layout) and a
    Documented in docs/HARDWARE.md 9.1.1; never bridged with an MJTP1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
    [bom_JLC_upload_v4_optimized.csv, nextpcb_bom.csv, nextpcb_centroid.csv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]
2026-09-20 NextPCB Rev0 findings: BOM without DNP lines, part substitutes, SMD/THT split files
    - nextpcb_bom.csv: DNP parts left out (NextPCB merged same-MPN DNP lines into fitted ones,
    which would have fitted R74 next to R73 and shorted 3V3 to GND); NextPCB-only substitutes
    for J6, the ten SW buttons and L1 from the new fabrication/nextpcb_substitutes.csv
    - make_fab_files.py: --split writes matched SMD-only and through-hole-only NextPCB BOM +
    centroid pairs to production/other_fabs/split/
    - fabrication/NEXTPCB_REV0_NOTES.md: what the Rev0 flow wants, what went wrong and how it was
    handled, the placement-preview analysis (through-hole bodies for J5/J6/SW1/SW7 misplaced,
    rotation edits had no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
    [nextpcb_bom.csv, nextpcb_bom_smd.csv, nextpcb_bom_tht.csv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]
2026-09-21 Final-review revision: DW01A filters, J6 fuse, alternate RTC, sleep-current ladder, doc and fab refresh
    Design (Rev 1.0, content current to 2026-09-21):
    - DW01A: R83 100R supply filter with C7 on the pin side, C34 2.2n on CS
    - F2 0805L075WR PPTC in series with J6 pin 12; CR3 now on the fused net
    - U14 RV-8263-C7 alternate RTC footprint (DNP) with a project symbol library
    - USB_STAT ladder rescaled x10 (R70 1M, R17 2M, R67 510k, R71 200k, C23 0.1u)
    and R57 10M: about 15 uA less sleep current
    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
    [BOM_handbuild_digikey.csv, bom.csv, bom_JLC_upload_v4_optimized.csv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]
2026-09-21 Docs: configuration groups from the netlist; configurator note
    README "Choosing a configuration" now lists every part a group owns, derived
    from the schematic netlist (a part belongs to a group when that group is the
    only thing it serves), matching the silkscreenreader.com builder:
    - Frontlight also owns its input capacitor C12 (beside U10; the LDO and power
    mux have C4), the LED monitor filter C31 and the output clamps D3/D8.
    - J3 is split out as "Frontlight connector": only a bonded-light panel needs
    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
2026-09-21 README: point to the builder's per-configuration order files
    The silkscreenreader.com builder now hands out the Gerber zip plus a BOM
    and CPL trimmed to the chosen build (identical to production/ for the
    standard build), so the 'configurator is coming' note becomes a pointer.
2026-09-21 README in first person; HARDWARE.md is the single hardware reference
    - Rewrite the README in the maker's voice: no third-person "the author",
    no em or en dashes, plainer wording throughout; every fact, figure and
    ordering step kept
    - Point readers to docs/HARDWARE.md alone for understanding the hardware
    and writing firmware (GPIO map in section 13, firmware contract in
    13.1, enclosure dimensions in 16); drop the links to the design review
    and audit folders from the README
    - Same first-person fix in HARDWARE.md, fabrication/README.md and
    THIRD_PARTY.md
2026-09-21 README: ordering guide no longer assumes two assembled boards; cost scales with quantity, see silkscreenreader.com/cost
2026-09-21 Take over the de-link repository: sponsor links carried over, README notes the de-link-old branch
2026-09-22 README: point to the project website for the full picture; board renders now show the silkscreen layers
2026-09-24 README: pre-order steps and a two-part swap for when TPS923610 is out of stock
    JLCPCB says restocking is unpredictable, but any account can pre-order
    C52919131. Fallback: TPS923611 for U10 together with SMAJ33A for D3,
    since the TPS923611's ~30 V OVP is above the SMAJ26A's 28.9 V breakdown.
    TPS923612 is WSON-only and doesn't fit the footprint.
2026-09-24 Docs: battery check, firmware wording, never locked, GDEY0426T82
    - README: the name Silkscreen covers both this board and a reader built around it; this
    repository covers the mainboard.
    - Battery lead order: wire colours are a good guide (black -, red +), but check them
    against the - + / CHECK marks beside J5 with USB unplugged, reverse the plug if needed
    (DigiKey guide), and measure if you can.
    - Firmware: built to run the open firmware made for Xteink's readers, starting with
    CrossPoint; no release for this board yet (closed-beta work); the board will never be
    locked; wait for Rev 1.0 to check out if you just want a reader.
    - JLCPCB is the only factory ordered from so far.
    - The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
2026-09-30 Docs: correct ladder wake thresholds (ESP32-S3 VIH is 0.75·VDD)
    HARDWARE.md §9.1 and DESIGN_REVIEW.md said the higher ladder steps
    (1.8–2.9 V) read as logic high. The ESP32-S3 datasheet (v2.2, Table 5-4)
    gives VIL ≤ 0.25·VDD and VIH ≥ 0.75·VDD, and the ladders run from the same
    3V3 as the pad supply, so UP(1) at 1.80 V and OK at 2.20 V are in the
    undefined band alongside LEFT; only DOWN(2), BACK and UP(2) read high.
    The conclusion is unchanged: only SW1, SW2 and the power button give a
    reliable GPIO-level wake. Wake on LEFT/UP(1)/OK is "not guaranteed"
    rather than "cannot fire".
    The wrong clause came from an unsourced review note on 2026-09-18
    (checkpoint 2, commit 7708db2); the 2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
2026-09-30 Docs: power-button jumper hazard, touch ESD gap, open-load front light, itemized sleep budget
    - §9.2: never fit R72 while R36 is still fitted. SW7's pin-2 node joins
    R36 (ladder 2) and R72 (PWR_BUTTON), so IO18 idles at ≈1.76 V, inside the
    undefined input band. For UP(2)-as-power, remove R36/R73 first, then fit
    R72/R74. IO18 is armed as ext1 so the RTC peripherals can power down.
    - §8: U7 clamps J4 pins 3–6 only; in the alternate jumper mapping TP_INT
    lands on the unclamped pin 2.
    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
2026-09-30 Cut-down board keeps 3V3 on the charge-enable switch; silkscreen wording
    - Cutting the board at y 62 for the 3.68" (x3) build removed both 3V3 feeds
    to the charge-enable switch (Q2/R81), so the TP4056 CE pin stayed low and
    a cut board never charged. A new 3V3 trace on B.Cu, below the cut, joins
    the two feeds. PWR_BUTTON and LED_SW are rerouted around it, one GND via
    moved, and the pour is refilled. DRC of a copy trimmed at y 62 shows no
    unconnected 3V3.
    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
    [silkscreen_pcb.kicad_pcb]
2026-09-30 Add the 2026-09-30 audit of Rev 1.0 (as ordered) and 1.01
    - AUDIT.md: Rev 1.0 (aeb5b39) checks out. The ordered zip is the Toolkit run
    from just before the order and re-plots identically; BOM and CPL match all
    165 placed parts; ERC 0 errors; DRC 0 unconnected, 0 parity. 1.01 (3edd0c8)
    keeps the schematic and every footprint and adds no DRC error.
    - New finding: on a board cut down at the cut line, the power-section GND
    (U3, U2, Q1, so the battery return) reaches the main GND only through one
    J7 shell tab. Same on 1.0; full-size boards are not affected. Fix for 1.01:
    GND stitching vias below the cut. Bodge for built boards: C6 pad 2 to C21
    pad 2.
    - What is left before 1.01 is or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
2026-09-30 Rev 1.01: GND stitching vias below the cut line, revision label, docs and plots
    - Five GND stitching vias below the cut line join the power-section ground
    (U3, U2, Q1, so the battery return) to the main ground. A board cut down for
    a smaller display no longer depends on one microSD shell tab for ground. A
    copy trimmed at y 62 shows no unconnected items.
    - Title blocks (PCB and schematic) set to Rev 1.01, 2026-09-30. The Gerber zip
    is now Silkscreen_Reader_PCB_1.01.zip; the Rev 1.0 zip that was ordered stays
    in history at aeb5b39.
    - Track tidy-up: collinear segments merged, redundant stubs removed, the 1 um
    3V3 stub from 3edd0c8 gone, and the B+ track beside J5 moved from x 97.7 t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
    [silkscreen_pcb.kicad_pcb, silkscreen_pcb.kicad_sch]
2026-10-02 Rev 1.01: R84 USB hot-plug damper, JLC placement corrections, docs
    - R84, 1 ohm 0603 (Yageo RC0603FR-071RL; JLC C22936, Basic) in series with
    C2's ground leg. It damps the ringing an already-live USB-A source causes
    at plug-in: the modelled worst case on U2 VIN1 falls from 7.95 V to 5.60 V.
    No DC current flows in it. One GND stitching via below the cut line moved
    to make room (a board trimmed at y 62 still shows 0 unconnected); the CHRG
    track is nudged 0.2 mm.
    - FT Rotation Offset (U2, U5, D2, D8) and FT Position Offset (J7, J4, U4)
    fields on the symbols and footprints, so every Toolkit run writes
    positions.csv rows that match JLC's library footprints.
    - Bottom silkscreen notes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
    [BOM_handbuild_digikey.csv, bom.csv, designators.csv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]
2026-10-11 Rev 1.01: J6 pinout label, back-silkscreen tidy, closed-beta status
    - The two lines of the J6 pinout table on the front silkscreen are swapped.
    J6 is a right-angle socket on the back with its openings in the top edge;
    seen with the display side toward you, looking down at the top edge, the
    outer row is GND 46 45 GND LED+ W- and the row next to the board is
    3V3 SDA 3 SCL C- BAT+, pin 1 on the left. Rev 1.0 boards print the two
    lines the other way round.
    - Reference designators of R16, R38, R56, R83 and C34 moved on the back
    silkscreen (C34's now 0.5 mm bold like the rest); four silkscreen DRC
    warnings are gone.
    - Gerber zip regenerated (SHA-256 5215bd0c...); only the two silkscr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
2026-10-12 Docs: timeless wording, closed-beta status, link fix
    - README, HARDWARE.md, LED_ALT.md, fabrication README/BOM/THIRD_PARTY: drop
    dated history, stock snapshots and per-build hashes so the docs describe
    the board as it is; "standard build" is now "full build" (the literal
    "DNP (standard build)" tag in jlc_bom.csv is unchanged); US spelling.
    - README status: the boards work so far and the closed beta is underway;
    building is still at your own risk. Boards made from older files (no
    R84) get the charger, J6 meter-check and cut-line wire notes; the current
    production/ files have not been built yet.
    - Fix a dead relative link to FINAL_REVIEW.md in the 2026-09-30 audit's
    docs-and-webs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
2026-10-15 Clarify development offer and board build guidance
    Align the beta audience, compatible battery guidance, frontlight connector population and smaller-board manufacturing route. Preserve the hardware files and license terms.
2026-10-15 Add the 2026-10-15 post-production Rev 1.01 audit and EMC/cert reference docs
    - docs/audit-2026-10-15/AUDIT.md: consolidated electrical, schematic,
    layout, cut-line, DFM/DFA, and doc-sync findings with author dispositions
    and an itemized action queue (ACT-DOC-1..6, ACT-FAB-1, ACT-SCH-1..2,
    ACT-PCB-1) for follow-up. Includes the Q2/R81 3V3->USB_VBUS hardware
    AND-gate verification and the coupled RLC microSD turn-on / write-burst
    droop analysis.
    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
2026-10-23 Rev 1.02: SMD USB-C socket with hand-solder pads, charge-enable gate from USB_VBUS, docs and cost data
    Rev 1.01 was never built, so these changes are labelled 1.02 and replace it.
    Board and fabrication files
    - J1 is now the 12-pad SMD GCT USB4105 land (JLC C2765186, Shou Han; prime part
    USB4105-GF-A) instead of the through-hole USB4085. Its nets, the shield ring and the four
    long edge traces are re-routed. The four J1 hole-clearance DRC findings (pegs against the
    stacked GND pads) are excluded in the project file.
    - J1's CPL row carries FT Position Offset 0,1.305, because JLC's footprint origin sits 1.305 mm
    from KiCad's (read from JLC's own footprint); no rotation offset.
    - Each J1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
2026-10-23 Re-render docs/images for Rev 1.02
    - board-top.png and board-bottom.png are re-rendered from the Rev 1.02 board (kicad-cli 3D
    render, transparent background): the SMD USB-C socket with its hand-solder pad tabs, R84,
    the swapped J6 label and the current silkscreen text.
    - full-capture.png and the 21 schematic block images are cut from one 400 dpi raster of the
    Rev 1.02 schematic PDF, so they show R84, the charge-enable gate on USB_VBUS with the new
    R79-R82 values, and the other edits since Rev 1.0. All crops now share one background colour.
    - The charger block's frame moved left, so the USB input, USB ESD and charger crops are re-cut
    around it.
2026-10-24 Add board-failures documentation (case 1) and correct L2's rated current
    docs/BOARD_FAILURES.md is a new page for field-reported failures. Case 1 is a Rev 1.0 frontlight
    boost fault that smoked on a USB power-up with no battery: the owner's account (anonymised), the
    annotated photos in docs/board-failures/case-01, the measurements taken afterwards, what the
    evidence shows, the hypotheses judged unlikely, the design scrutiny of Rev 1.0 and what is still
    open on Rev 1.02, the open items, and what to send with a failure report. README.md and
    docs/HARDWARE.md link to it.
    L2 (TDK VLS252012HBX-100M-1): HARDWARE.md section 7 quoted 1.0 A as its rating. That is the
    saturation current; the rated cur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
2026-10-29 Board failures: battery log, 6-7 ohm assumptions, inline PTC study, case 2
    Case 1: read the owner's battery log (drain, pack state, no latent short,
    open chronology questions), write down what the 6-7 ohm reading assumes
    and the current path, add the cold-start in-rush row, and record the
    inline PTC study (trip windows, start-up headroom, parts, layout, tests
    that need no spare board). Correct the wording that 0.75 A is below any
    USB source's limit (a USB 2.0 port is specified for 0.5 A) and note that
    a resettable F1 reading normal later does not show it never tripped.
    Case 2 (open): a Rev 1.0 board that went hot near the USB-C port while
    flashing, 4.2 V at over 0.8 A, 3V3 to ground 3.5 koh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
2026-11-02 Board failures: case 1 bench analysis, protection studies, next-revision list
    Case 1's failed part is identified on the bench: U10's low-side switch shorted SW to GND at about 7 ohm; the board runs again after replacing U10. Why it smoked is a design gap shared by Rev 1.02 (nothing limits current on the boost branch below F1's 1 A hold), and a board-wide audit found the same gap on the battery, 3V3, touch, J6 and e-paper rails.
    docs/audit-2026-10-29 holds the studies (latching e-fuse and 4-part limiter, superseded; electro-thermal PTC model; durability audit; protection follow-up covering branch PTCs, battery sense resistor, microSD, charge current and front-side test pads) with their scrip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
2026-11-03 Rev 1.03 work in progress: NEXT_REVISION N1-N6 and N9 in the design files
    Schematic, board and part fields carry the frontlight, touch, J6 pin 7 and
    e-paper PTCs (F3-F6, F4 replacing R42), the /LED_VIN, J6_3V3 and EINK_3V3
    net splits and R6 = 10k. N7 and N8 (DW01A sense resistor, C34) are parked
    because no legal spot exists near Q1 pin 3, N10 is left unchanged and N11
    was dropped.
    Checked against master 4530931: DRC with schematic parity unchanged except
    one cosmetic silkscreen warning (cut-line marker over F5), 0 unconnected
    items, 0 parity issues; ERC gains four PTC footprint-filter warnings like
    F1/F2. Not reviewed in KiCad yet. Production files, docs and the Rev 1.02
    label are untouched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
2026-11-04 Rev 1.03: N7/N8, U10 on TI's land, trace audit and certification fixes
    - N7/N8 on the board: R85/R86, two 0.1 ohm 1206 in parallel (50 mOhm DW01A
    sense, JLC Basic), and C34 = 0.1 uF.
    - U10 on TI's DRL0006A example land (new footprint) with its corner re-laid
    out after board-failures case 1; custom DRC rules in silkscreen_pcb.kicad_dru.
    - Board-wide trace audit (docs/audit-2026-11-03/TRACE_AUDIT.md) and its fixes:
    pour pull-backs, stitching and return vias, F3 pour keep-out, mounting-hole
    and edge clearances, trace tidy, uniform reference designators, teardrops.
    - Bench-test theory with a copper-level thermal model (BENCH_THEORY.md).
    - Certification-readiness review audit (CERT_REVIEW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
2026-11-04 Rev 1.03: independent review and triage, cut-line pour, silk and U10 via
    - Independent block-by-block board review from the design files and
    datasheets only (docs/independent-review-2026-11-03/BOARD_REVIEW.md, with
    its scripts and figures): no Critical findings, 2 High, 6 Medium.
    - TRIAGE.md re-rates all 33 findings with the project's context and gives
    each a fix, a difficulty and a worth-it verdict.
    - Applied: pour-free rule areas keep GND about 1 mm from P+ and 3V3 where
    they cross the cut line, both layers (H-2); the back-silk touch-option
    note names F4 instead of R42 (M-6); the schematic R6 note gives the 10k
    charge current (L-1); a second GND via at U10 pin 4 (L-14).
    - Filed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
2026-11-04 Rev 1.03: BQ21040 charger with NTC, review status, changelog since 1.0
    - U11: TI BQ21040 (SOT-23-6) replaces the TP4056, with a 10k NTC (TH1,
    0603) on TS: charging only between about 0 and 41 C at TH1, 30 min
    pre-charge and 10 h fast-charge timers, 6.6 V input OVP. Closes
    independent review H-1 and certification item C1.
    - Q2 is now a BSS138 that holds TS low until Q9 sees a correctly oriented
    cell, in place of the CE drive. R6 4.7k (105-125 mA), R82 200k (an open
    NTC reads cold), R71 and the STDBY input to USB_STAT removed.
    - Layout: new copper on B.Cu only, three GND vias, references in the
    board's 0.5 mm style; teardrops re-added (860) and zones refilled.
    - Schematic notes: th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
2026-11-05 Rev 1.03: switch frames to GND, TS capacitor C38, TH1 moved, D3 duplicate via removed
    - Tact-switch frame leg (pad 3, the hole beside the GND pad) tied to GND on SW1-SW5, SW8, SW9 and SW11 through the new
    footprint MJTP1117_FG. Pad 4 stays netless for the front-mounted bottom-button option (HARDWARE.md 9.1.1); SW7 and SW10
    are unchanged because their pad 1 is not GND.
    - C38, 0.22 uF (Yageo CC0603KRX7R9BB224, C107083), from TS to GND: the BQ21040 datasheet's optional TS capacitor. TH1 moves
    beside R82, so TS is about 14 mm instead of 23 mm and no longer runs between F1's pads.
    - The duplicate GND via inside D3's pad is removed; D3 keeps its own via beside the pad.
    - DRC, ERC and the net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
2026-11-08 Rev 1.03: side buttons level, straight left edge
    - Side switches: SW10 (power) moves 0.2175 mm inboard and SW1 0.045 mm
    outward, so all five sit 2.75 mm behind their edge and every plunger
    stands 0.97 mm past it (Rev 1.0 had SW10 0.22 mm further out and SW1
    0.05 mm short). The B.Cu copper beside SW10 (J6_3V3, W-, C-, R62, 3V3)
    and SW1 (R61) is re-routed locally; four teardrops moved by hand.
    - Left edge: it leaned 0.045 deg (the bottom end sat 0.06 mm further in than
    the top). The edge, the antenna notch walls and the bottom-left corner are
    now exactly vertical: the main body is 60.000 mm wide top to bottom. The
    right edge was already straight.
    - SW10's courtyard rear margin 1.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
2026-11-12 Rev 1.03: BOM audit swaps (C38, F2, U12), U14 fields, review fixes
    - BOM-only swaps from the 2026-11-12 BOM audit (new
    docs/audit-2026-11-12/BOM_AUDIT.md), same footprints and rotations:
    C38 -> Samsung CL10B224KA8NNNC C21120 (Basic, one Extended type
    fewer), F2 -> Brightking SMD0805B075TF C269105 (same listed ratings,
    65k in stock), U12 -> TI SN74LVC1G04DBVR C7827 (the genuine part in
    place of the MDD clone). About $0.56 / $0.35 / $0.20 / $0.12 a board
    less at 5 / 10 / 30 / 100 boards.
    - Fields written with apply_part_fields.py and mirrored onto the PCB
    footprints. jlc_bom.csv and the Toolkit bom.csv edited for the three
    codes (no Toolkit on this machine); other_fabs regenera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

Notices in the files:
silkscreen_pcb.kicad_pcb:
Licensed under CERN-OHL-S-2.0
